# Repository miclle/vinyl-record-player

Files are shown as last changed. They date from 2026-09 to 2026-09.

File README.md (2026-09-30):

# 黑胶唱片机概念 CAD

一低音两全频的一体式黑胶唱片机概念 CAD，外形参考 [HYM LUMI Walnut 官方资料](https://www.hym-originals-en.com/products/lumi-turntable-walnut)。当前结构为 **v0.11 HYM 比例格栅与 10 mm 内部结构板布局**，保留 v0.9 可调定位合页；当前弯臂机芯与结构统一保存在一个主 CAD 文件中，机芯采用 **v0.6 部分实测居中参数**。扬声器、变压器和功放板已采用用户提供的外廓尺寸；机芯安装接口仍待确认。

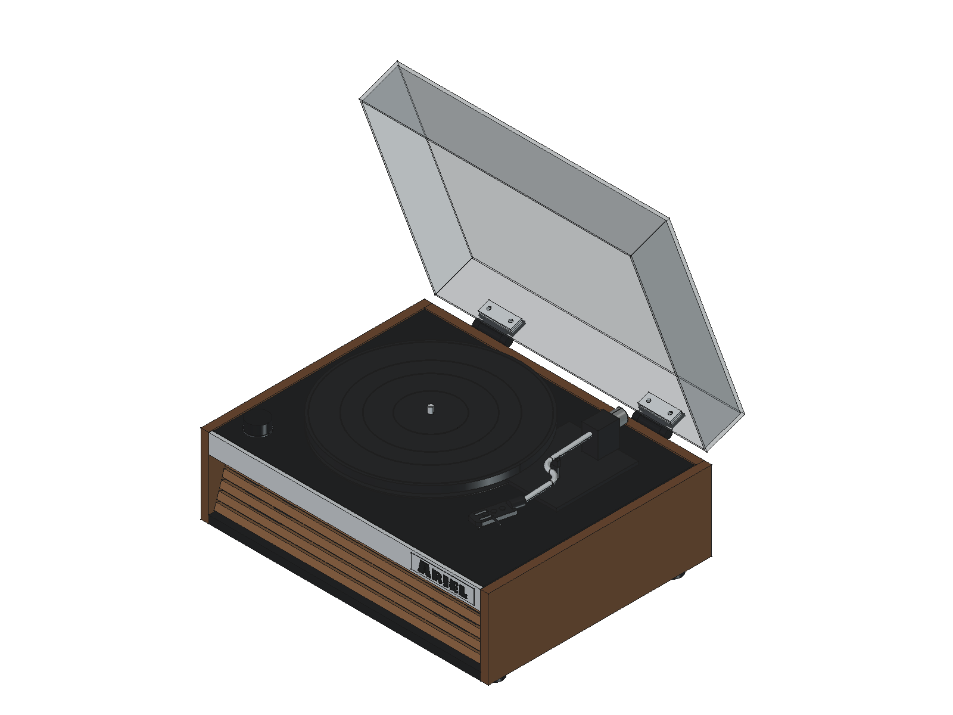
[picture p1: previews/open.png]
开盖 CAD 预览


## 模型选择

| 文件 | 用途 |
|---|---|
| [整机主模型](cad/record-player.FCStd) | 唯一 CAD 入口，默认开盖 70°；零件直接位于根层，便于逐件点击查看 |

主模型直接由两份参数 JSON 一次生成，不再依赖另一个 FCStd。对象树不创建零件分组；每个零件以只读 `AssemblySection` 属性保留原有分类，选中零件后可在属性编辑器的 `Organization` 分类中查看。旧基线 CAD／STEP 已移除，可从 Git 历史找回。原通用机芯的 16 个对象标记为 `Mechanism` 历史参考，`FitAnalysis` 标记诊断体也默认隐藏；两者均不进入当前装配、STEP 或零件清单。

日常查看无需重建：

1. 在 FreeCAD 中打开主模型，默认显示开盖 70° 的状态。
2. 保持主模型为当前活动文档，在“宏 → 宏…”中将用户宏位置设为本仓库的 `tools/`，选择 [toggle-cover.FCMacro](tools/toggle-cover.FCMacro) 并执行。
3. 每次执行在闭盖和开盖之间切换，盖壳、活动叶、补偿垫片和压板同步移动。

宏不自动保存，但切换姿态会使文档显示为已修改。仅查看时可关闭并放弃姿态更改，下次打开仍是原保存状态；如有其他手动编辑，先另存副本。`AssemblyState.CoverAngle` 是只读的角度记录，改变默认开角需修改 `cad/parameters.json` 的 `cover_angle_open` 并重建。

交付的 STEP、尺寸图与验证均使用闭盖基准；手动从当前开盖视图导出不属于此流程。70° 不代表实物已有限位或悬停能力。

## 分类平面图纸

先看[图册 01 中的两页 A2 整机结构导览](output/pdf/01-assembly-and-enclosure.pdf)：[开盖全景](previews/assembly-guide-1.png)和[内部展开](previews/assembly-guide-2.png)用编号标出部件、材料状态、数量及对应详图号，覆盖当前装配的全部 65 个物理对象；两页都在图中编号下直接显示部件名称，并共用相同的页边界、主视图、左右标注列和右侧目录宽度，减少视线往返与翻页跳动。两页导览以原 A2 尺寸插在 A-STOCK 木板清单之后，不再另行交付重复的 00 PDF。详见[导览说明](docs/assembly-guide.md)。

当前模型已整理为 **3 份横向矢量 PDF，共 44 页**；主体图纸为 A3，第一册另嵌入两张原尺寸 A2 导览：

- [整机与外壳（19 页）](output/pdf/01-assembly-and-enclosure.pdf)：木板整数备料汇总后紧接两页原尺寸 A2 整机导览，再继续闭盖六面图、障板局部剖视、外壳零件、合页与安装板，以及底板／后板／防尘盖后壁开孔定位。
- [音腔与内部结构（11 页）](output/pdf/02-acoustic-and-structure.pdf)：隔板、音腔顶板、倒相管、浮动台面与支承，附障板／顶板／浮动底板开孔定位。
- [机芯与电子部件（14 页）](output/pdf/03-mechanism-and-electronics.pdf)：扬声器、电源、功放、当前弯臂机芯及通用机芯对照。

图纸标明长 X、宽 Y、高 Z、厚度或厚度状态，并补充已有开孔、定位和同形件数量。六种板件的 33 个孔及后板沉台已分别标注孔径、局部孔位、必要的深度和加工面；障板孔位使用沿前表面量取的 S 尺寸。未确认的尺寸明确标为假设或待定；当前仍是概念与空间核对图。详见[读图说明与重新生成方法](docs/drawing-pack.md)。

## 机芯装配核对

已按“28高端弯臂机芯全套餐装好直接用 自动回臂”建立 [FreeCAD](cad/record-player.FCStd) / [STEP](cad/record-player.step) 示意装配，见 [选型说明与重建方法](docs/mechanism.md)。用户已确认到货款除弯臂外与原图一致，并确认唱头指托不会越过机芯基座右侧。采用 Ø280×11 唱盘、85 mm 总高及 R110、约1／4／8点的三个弹簧支点；整套机芯右移 12 mm 至唱盘中心 X=188 mm，355 mm 基座在浮动台面上的左右余量约为 34／33 mm。指托暂按 16 mm 外观长度建模并保持在基座范围内。弹簧自由高15.5、估计压缩0–5 mm，对应电机下探24.5–29.5 mm。底部局部轮廓仍为估算，与现有结构有重叠，安装未放行。

[弯臂预览](previews/mechanism-open.png) · [空间核对图](previews/mechanism-clearance.png) · [核对报告](cad/mechanism-fit-report.json)

## 整机交付内容

| 文件 | 用途 |
|---|---|
| [FreeCAD 装配](cad/record-player.FCStd) | 65 个当前装配对象，另含隐藏历史参考和诊断对象；零件位于根层，可直接点击、隐藏、移动和进一步建模 |
| [STEP 装配](cad/record-player.step) | 闭盖姿态，82 个实体；排除历史参考与诊断体 |
| [三视尺寸图 SVG](previews/dimensions.svg) / [PNG](previews/dimensions.png) | CAD 实体投影，含外廓和唱盘尺寸；不是加工图 |
| [闭盖](previews/closed.png) / [开盖](previews/open.png) / [内部布局](previews/internal.png) | 实际 FreeCAD 视口渲染 |
| [底部低音安装](previews/bottom.png) | 低音朝下，底板预留圆孔 |
| [俯视](previews/top.png) / [正视](previews/front.png) / [右视](previews/right.png) | 外形与布局核对 |
| [主要参数](cad/parameters.json) | 修改后通过脚本重建 |
| [机芯参数](cad/mechanism.json) | 当前弯臂机芯占位、唱盘尺寸和下探假设，与结构参数一起重建 |
| [零件清单](cad/parts.csv) | 材料说明、包络尺寸和估算标记 |
| [木板备料清单](cad/wood-cut-list.csv) | 20 块 / 条板件，整数矩形备料长宽、名义板厚、数量及后续修切说明；A-STOCK 与导览 W01–W11 共用编号、名称、数量和尺寸，W05 为退役空缺 |
| [设计依据](docs/design-basis.md) | 官方资料、估算边界与后续选型要求 |
| [验证报告](cad/validation.json) | 实体、关键尺寸、干涉及 STEP 回读结果 |

外观包含胡桃木色侧板、后倾横格栅、银色前沿、黑色台面、左前旋钮、唱盘与唱臂包络、烟灰透明翻盖和脚垫。内部使用 Shockwave SC-2103 拆机件：**左右全频朝前，低音移到后排朝下**。两道全深隔板分出贯通前后的中央低音腔，左右前部各为一个独立密闭试验腔，电路移至左右后部。低音倒相管从后板引出，内径 32 mm、初始长度 160 mm，可换长度试调。v0.5 将箱体平面外廓调整为 450 × 350 mm，木壳自身高度保持 124 mm。

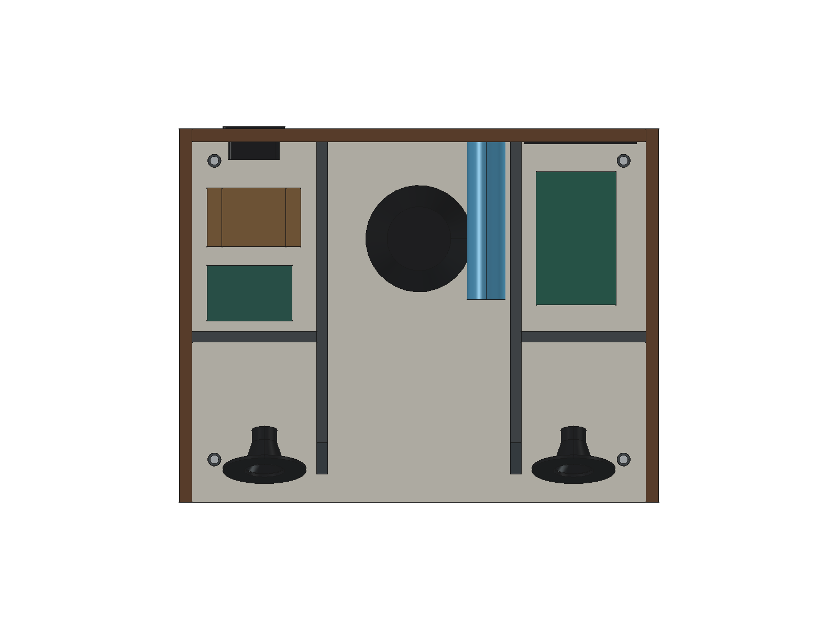
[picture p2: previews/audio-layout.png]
三音腔俯视布局（上方为后侧；已隐藏顶板）


低音腔几何毛容积约 **4.58 L**，扣除所有已建模占用（含实心安装包络和倒相管）后保守净容积约 **4.04 L**；左右全频腔各约 **1.11 L**。这些是 10 mm 内部结构板下的 CAD 空间估计，尚未扣吸音材料、支柱、密封件及线缆，不是实测声学容积。原箱和倒相管已遗失，没有 T/S 参数；管径、管长与左右密闭方案均为待测初值。详细坐标、拆装方式和验证边界见 [SC-2103 音腔设计](docs/audio-layout.md)。

[后置倒相口预览](previews/rear.png)

左右全频腔当前没有倒相管；可封堵、可换管接口仅为后续讨论方案，尚未建模，见[全频腔的后续方案](docs/audio-layout.md#左右全频腔的后续方案)。接手当前成果时先读[工作交接](docs/current-work-handoff.md)。

## AC 电源插座预留

已依据用户提供的 8-F5 图纸，在左后板横装预留 **48 × 28 mm、R3** 通孔，附上下 **2 × Ø4.5 mm、孔距 40 mm** 固定孔。中心 X=70、Z=88.5 mm，距后板自身左边 58、下边 54 mm。插座下移 16 mm，为对称合页留出 5.5 mm 间隙；变压器同步前移 10 mm 至 Y=267。端子后另留 20 mm 接线空间（暂估），与变压器及承托梁的几何间距分别为 6.72／22 mm。

[合并参考图](references/ac-inlet/8-f5-combined.png) · [原图、选型条件与孔位说明](references/ac-inlet/README.md) · [插座与电源线购买链接及 SKU](references/ac-inlet/README.md#购买链接) · [隐藏插座后的后板孔预览](previews/rear-cutouts.png)

该两芯 C8 仅为机械候选件，不提供保护接地；整机绝缘、变压器一次侧规格、保险丝、端子护套及实际板厚适配尚待确认，未放行市电接入和生产加工。合图中的细字可能重绘，尺寸以保存的两张原图及参数记录为准。

电源线目前仅登记购买链接，具体规格与适配性尚未核对，未加入 CAD。修改插座开孔参数后，备料表的文字说明仍可能保留默认尺寸，详见[已知问题与待修项](docs/current-work-handoff.md#已知问题与待修项)。

## 已购脚垫与固定座

已登记 VE 型 **Ø30 × 20 mm 橡胶脚垫、M8 × 23 mm 螺杆**，以及 **M8、Ø37 mm 底盘、总高 17 mm 固定座**的[购买链接、SKU 和原始尺寸图](references/feet/README.md)。尺寸来自用户提供的商家图，尚未实测。

已建模四套脚垫与固定座，采用用户确认的“底盘贴底板下表面、圆柱向上穿板”方式。未压缩离地高 **22.5 mm**；木壳仍高 124 mm，闭盖总高 **210.7 mm**。前脚中心改为 Y=40，后脚为 Y=320，左右 X=33 / 417 mm。底板 Ø12.4 mm 通孔、Ø3 mm 深 8 mm 盲预孔及固定孔分布圆 Ø28 mm 均为安装假设。22.5 mm 按理想贴合计算，不包含螺钉头凸出、垫片或锁紧件；实际避让、啮合、密封及承载待实测。

[脚座安装剖视](previews/feet-installation.png) · [底部预览](previews/bottom.png) · [尺寸及安装边界](references/feet/README.md#当前-cad-安装方式)

## 前沿 T 型铝饰条

采用用户选定的 **30 × 30 × 5 mm 铝合金 T 型材**，宽面朝前、筋板向后；安装长 425 mm，两端各暂留 0.5 mm。10 mm 顶板前缘退至 Y=5.2，并加工 25 mm 宽、5.7 mm 深的顶面台阶，余厚 4.3 mm；其中 0.2 mm 为胶层／试装余量假设。饰条上沿仍齐平木箱，闭盖间隙 1 mm。固定孔、胶种、根部圆角与实物公差待确认。

[原图、商品链接与安装尺寸](references/fascia/README.md)。音腔顶板孔位按新成形前缘起算；机芯右移后，轴承孔局部坐标为 X=176、Y=166.8 mm，整机坐标为 X=188、Y=172 mm。

### Ariel LOGO：打印雕刻支架

当前手工方案为一体打印的 [Ariel 镂空雕刻定位支架](output/3d-print/README.md)，采用 Sigmar One 字体，无需文字贴膜。[STL](output/3d-print/Ariel-stencil.stl) 外廓 **109.5 × 32 × 6.5 mm**，已摆好大平面贴热床、挡边朝上的姿态，无需支撑；按裸饰条上沿和右端定位。A、R 内孔通过 1.2 mm 连接桥保留，取下支架后可补磨桥位。

使用时在饰条安装前加工，或先拆下饰条；刀头可达性、模板耐磨与最终对比度需在边角料试刻。该工具单独交付，不计入整机装配、零件表或三册图纸。

主 CAD 仍保留另一方案的 **98 × 22 × 0.6 mm Ariel 激光标记铭牌**；[矢量稿与概念尺寸](references/nameplate/README.md)可供商家核对，材质、厚度、贴附及激光效果待确认。因此现有 STEP 和图纸仍含铭牌占位，并未改成直接在饰条上磨字后的装配。

## 可调定位合页

采用两只 **HFA5751-3434 黑色可调定位合页**。已保存两张用户原图、淘宝链接、SKU 及用户补充的最大 **3 N·m** 信息；单只／整对口径、扭矩范围与寿命保持能力尚未验证。

合页中心 X=100／350 mm，关于箱体中线对称、距各自箱体外侧均 100 mm，共用轴线 Y=356.95、Z=147 mm；上盖外侧加 2 mm 补偿垫片，内侧加 2 mm 压板。后板为 4 个 Ø3、深 8 mm 盲预孔，透明盖后壁为 4 个 Ø5.5 通孔，均属安装假设。两张原图的总厚分别为 13.2／12.8 mm，模型暂按较大的 13.2 mm 预留，合页后端位于 Y=363.2 mm；加上前侧 0.6 mm 铭牌后闭盖总深为 363.8 mm。

[原图、采购记录与安装边界](references/hinges/README.md) · [对称安装后视图](previews/rear.png) · [合页安装局部视图](previews/hinge-installation.png)。合页叶片沿用 A-P06，垫片／压板见 A-P08，后板孔见 A-H02，盖后壁孔见 A-H03。模型检查到 70°，尚未设计机械限位。

## 木板加工尺寸

箱体平面采用 450 × 350 mm；侧板 350 × 124 × 12、底板 426 × 350 × 12、后板 426 × 112 × 12、浮动台面 422 × 330 × 10 mm。台面前侧到银色 T 型铝饰条后表面的名义间隙由 `deck_front_fascia_clearance` 控制，当前为 1 mm；左右由 `deck_side_clearance` 控制，当前各 2 mm；后侧由 `deck_rear_clearance` 控制，当前为 2 mm。三处均为概念安装余量，实际浮动行程待验证。三个 Ø16 × 8 弹性支承分别嵌入音腔顶板顶面与台面底面 3 mm，保持台面上表面高度不变；沉台和支承参数仍是安装假设。底板前沿一体保留，已取消与底板完全重叠的独立下横梁。格栅为 7 条 426 × 10 × 6 mm 矩形条，整体后倾 18°，竖向节距 13 mm；透声布占位后移至障板前表面。

斜障板采用真实法向厚 10 mm，矩形备料 426 × 98 × 10 mm，之后修上下斜口至安装竖高 90 mm；两道低音隔板各备料 312 × 90 × 10 mm，按精确斜前缘修切。音腔顶板、左右全频腔后板、后部承托梁和浮动台面也统一使用 10 mm 备料。图册同时保留成形包络与整数备料，不能逐项四舍五入斜切坐标。脚座安装孔及配合间隙按上述假设预留；其余未定义的榫槽、紧固孔和通用间隙未建模。名义板厚、贴皮、拼接与装配余量仍须在材料和工艺确定后实测确认。

## v0.11 结构参数与精度

闭盖机壳外廓为 **450 × 350 × 210.7 mm**，含前侧铭牌和后凸合页的总深 **363.8 mm**（不含未建模紧固件、外接插头和线缆）。当前机芯的唱盘占位为 **Ø280 mm**，由 `cad/mechanism.json` 控制；弯臂轴距、有效臂长和循迹参数尚未确认。

`cad/parameters.json` 中保留的 Ø300 mm 唱盘、200 mm 轴距与 218 mm 有效臂长属于隐藏的历史通用机芯，仅用于图册附录，不能作为当前弯臂的安装尺寸。两类尺寸来源见[设计依据](docs/design-basis.md#公开参数)和[机芯尺寸依据](docs/mechanism.md#尺寸依据)。

原始 **214.2 mm** 曾暂解释为闭盖总高，官网图示未明确测量基准；v0.7 因已购脚垫名义离地高度降低 3.5 mm，当前总高为 **210.7 mm**。木壳高度分配、板厚、格栅间距、防尘盖与内部件尺寸均为估算；扬声器口端外径与总高采用用户于 2026-09-21 提供的尺寸，见下表；开孔和 3 mm 边沿厚度仍为估算。口端外径暂对应模型法兰外径，不代表振膜直径或名义英寸规格。

| 占位 | 数量 | 口端外径 | 总高（含边沿） | 暂定开孔直径 | 向箱内预留深度 |
|---|---:|---:|---:|---:|---:|
| 低音，底部朝下 | 1 | 132 mm | 65 mm | 100 mm | 62 mm |
| 全频，前部左右 | 2 | 78 mm | 40 mm | 40 mm | 37 mm |

总高按喇叭口朝下测量时的轴向高度理解；安装方向维持低音朝下、全频朝前。法兰向箱外伸出暂估的 3 mm，已计入总高。低音的最低点离桌面 19.5 mm，低于此前 20 mm 试验目标；几何验证仅核对间隙与当前装配一致，声学效果、橡胶压缩及防护网厚度仍待验证。安装孔只开概念圆孔，未确定螺孔位置。`parameters.json` 中的 `woofer`、`fullrange` 和 `acoustic_divider_x` 可分别调整单元尺寸、位置和隔板位置；`total_height` 是总高，箱内深度由总高减 `flange_thickness` 得到。

三个扬声器共用一个电源变压器，本体按用户提供的 **60 × 55 × 50 mm**，底部固定耳总长 **88 mm** 建模。放在左后部电源区，底面贴合底板上表面 Z=34.5 mm。本体与固定耳共用底面，总包络为 **88 × 55 × 50 mm**；固定耳暂按沿长边对称伸出、每侧 14 mm，宽 55 mm、厚 2 mm 作保守占位，尚未开固定孔。孔距、耳宽厚及高度基准需实物核对，散热、走线和磁场对唱头/唱放的影响未验证。尺寸与位置由 `power_transformer` 参数控制。

功放板采用用户提供的**含散热片整体尺寸 125 × 75 × 45 mm**，放在后部右侧，水平旋转 90°，沿 X/Y/Z 的包络为 75 / 125 / 45 mm。沿用离底板 10 mm 的暂估支承空间，包络底面 Z=44.5 mm、顶面 Z=89.5 mm；没有在 45 mm 之外再叠加散热片。`amplifier` 参数控制尺寸、位置及底部间隙；孔位、支柱、散热片细节和端子插拔空间待确认。

FCStd 保留独立的 `Part::Feature` 实体；主参数由 JSON 驱动脚本重建，**没有完整的草图约束和自动联动特征历史**。可以在 FreeCAD 中继续直接编辑零件，或修改 JSON 后重新生成。部分细部偏移量在建模脚本中。重建不会保留手动修改，应先另存自己的版本。

## 整机重建

使用 FreeCAD **1.1.1**。以下终端命令从仓库根目录执行；整机生成输出写回 `cad/` 和 `previews/`，PDF 另行生成到 `output/pdf/`。

1. 按需修改结构参数 `cad/parameters.json` 或机芯参数 `cad/mechanism.json`。脚垫高度须满足 `foot_height = feet.rubber_height + feet.flange_thickness`；改变离地高度时还需同步关联的绝对 Z 参数，见[脚垫参数与重建](references/feet/README.md#参数与重建)。
2. 将手动改动另存后，关闭主模型。生成器同时检查 `RecordPlayerAssembly` 文档名与解析符号链接后的输出路径，阻止覆盖已打开的目标。
3. 执行 `tools/build.FCMacro`，一次生成整机 FCStd、闭盖 STEP、清单、机芯核对报告、预览和尺寸图；最后以开盖 70° 保存主模型。脚座及合页局部视图只裁切临时文档。
4. 执行下方验证命令。验证读取临时副本并恢复闭盖基准，不改变已打开的用户文档或源文件。
5. 交付图纸时，按[图册说明](docs/drawing-pack.md#重新生成)提取主 CAD 的最新数据并排版三份主体图册，再按[导览说明](docs/assembly-guide.md#重新生成)生成两页临时 A2 导览并嵌入第一册 A-STOCK 之后；不另行保留重复的 00 PDF。整机宏不会自动更新这些 PDF。

宏每次读取本地模块的新源码，包括机芯和姿态模块。结构参数快照保存在 `GeometryDatums.BuildParametersJSON`，机芯参数快照保存在 `StudyBasis.ConfigurationJSON`。验证拒绝缺失或过期快照，并以失败报告覆盖旧成功报告。机芯报告的 `model_sha256` 绑定最终保存的主 CAD。修改 JSON 不会自动改变保存的静态实体。

本机也可以用终端启动宏：

```sh
open -a FreeCAD --args "$PWD/tools/build.FCMacro"
```

命令适用于 FreeCAD 尚未运行时；已经运行时直接在宏窗口执行。脚本使用宏本身所在位置寻找仓库，不依赖终端工作目录。

无图形界面时可生成主 FCStd、闭盖 STEP、机芯报告、零件清单与木板备料清单：

macOS 终端命令使用环境变量 `FREECAD_RESOURCES`，请将其设为本机 FreeCAD 1.1.1 应用包内的 `Contents/Resources` 目录，并在同一终端会话中执行命令。该目录应包含 `bin/python` 和 `lib`；它是外部运行环境，不是项目目录。下方命令及各专题文档均使用此变量，未设置时会提示并停止。

```sh
PYTHONPATH="${FREECAD_RESOURCES:?请先设置 FreeCAD 运行环境}/lib" \
  "$FREECAD_RESOURCES/bin/python" tools/build_model.py
```

该方式不生成 GUI 颜色与零件可见性设置、预览或尺寸图，也不刷新主验证报告；需要与交付文件一致的展示效果时执行 GUI 宏，再继续验证及图纸流程。

## 验证范围

2026-09-24 已将部分实测机芯与结构合并为单一主 CAD，并默认保存开盖展示姿态；随后将机芯整体右移 12 mm、缩短指托，并同步主轴孔、预览和图纸。本轮验证证据见[工作交接](docs/current-work-handoff.md#验证证据)。

当前保存模型通过主验证 **56 项**和机芯报告 **13 项**几何／导出检查。FreeCAD 全量回归共 55 项，其中 46 项通过，9 项 PDF 用例按运行时条件跳过；独立 PDF 环境的 9 项全部通过。三册最终页数为 19／11／14；第一册包含 17 张 A3 图纸和插在 A-STOCK 后的两张原尺寸 A2 导览，两张独立导览 PNG 和孔位图也已同步。导览合成会拒绝 CAD 哈希或 17 页图号序列不一致的第一册，并在 PDF、索引和预览全部生成成功后才发布。历史批次及其适用范围见[验证证据](docs/current-work-handoff.md#验证证据)。

CAD 回归覆盖参数快照、根层零件树与 `AssemblySection` 合法取值、保存实体尺寸、宏重载、关键部件干涉、音腔泄漏和净容积、倒相管试验长度、脚垫穿板安装及机芯核对版的覆盖保护。T 型铝条的 5 项用例检查真实截面、顶板承托层、邻件间隙和密封边界；错误填实截面、填回台阶、切穿承托层及抬高撞盖均会被检出。合页另有 5 项用例，覆盖保存孔位、盲孔余厚、活动安装件干涉及图纸孔坐标；非默认合页参数回归同时核对保存实体、孔表、材料说明与图纸文字。

图册与导览回归覆盖孔位基准、盲孔深度、真实剖面、对象与图号映射、A-STOCK 与 W01–W11 导览目录一致性、非默认 AC 开孔备料说明、格栅数量变化及标注遮挡；完整 PDF CLI 用例执行保存 CAD 提取和三册排版，核对页数、位置表及保留图号。测试不会改写原交付文件，但图册与导览用例需要读取当前主 CAD，因此应先完成重建：

```sh
PYTHONPATH="${FREECAD_RESOURCES:?请先设置 FreeCAD 运行环境}/lib" \
  "$FREECAD_RESOURCES/bin/python" -m unittest discover -s tests -v

# 普通 Python 环境需 reportlab、svglib、pypdf、pdfplumber，补跑：
FREECAD_RESOURCES="${FREECAD_RESOURCES:?请先设置 FreeCAD 运行环境}" \
  python3 -m unittest discover -s tests -p '*_pdf.py' -v
```

主装配的几何验证（自动恢复闭盖基准）：

```sh
PYTHONPATH="${FREECAD_RESOURCES:?请先设置 FreeCAD 运行环境}/lib" \
  "$FREECAD_RESOURCES/bin/python" tools/validate_model.py
```

主验证覆盖结构和机芯参数快照、当前装配实体有效性、STEP 回读、安装空间、音腔封闭与倒相管气路、脚座、AC 插座、T 型铝条及合页。历史参考和诊断体不参与物理装配检查；假设机芯下探的重叠单独记录在 `mechanism-fit-report.json`，不计入声腔实物占用。

盖壳每 5°、盖壳与活动安装件总成每 1° 检查至 70°，均为离散抽样，不是连续运动或实物悬停验证。模型合并和开盖展示没有解决机芯实际轮廓、孔位与运动范围未知的问题；声学、电气、隔振和安装仍未放行。

具体未完成安装工作见[后续适配](docs/mechanism.md#后续适配与重建)，加工前资料清单见[设计依据](docs/design-basis.md#进入加工前必须补齐)。SC-2103 具体版本、原功放分频和单元参数仍需核实。现有图纸已标出暂定声孔，进入加工前仍需实测确认声孔直径，补齐扬声器固定螺孔、扬声器与当前弯臂机芯的真实安装图，并确定材料、连接方式和公差。**本版不能直接作为原厂精确复刻或生产加工图。**

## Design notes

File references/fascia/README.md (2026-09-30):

# 前沿 T 型铝饰条

2026-09-22 用户确认采用 **30 × 30 × 5 mm 铝合金 T 型材**。宽面朝前作为 30 mm 高银色饰面，中间筋板向后安装在音腔顶板前缘。此为已选方案，不代表已采购或已实测。

- [商品链接](https://item.taobao.com/item.htm?id=775150952939&skuId=6005431361130)
- 商品 ID：`775150952939`；SKU ID：`6005431361130`。
- [用户提供的商家尺寸图](vendor-dimensions.png)。原图版权归原权利人，仅用于本项目选型研究。

商品页面未成功读取；尺寸依据为用户提供的图片和文字。图中竖向 30 mm 是否含底板厚度仍需实测。本版按总外廓 30 × 30 mm、面板与筋板均厚 5 mm、筋板居中的理想锐角 T 截面建模；筋板从前饰面背后伸出 25 mm。合金牌号、表面处理、直线度、公差、根部圆角和端面加工均未确认。

## 当前 CAD 安装

参数位于 [cad/parameters.json](../../cad/parameters.json) 的 `fascia`；[tools/fascia.py](../../tools/fascia.py) 计算型材和顶板切除体。模型中的 `Fascia`、`AcousticRoof` 都是静态实体，修改参数后按 [README 重建流程](../../README.md#整机重建)重建并验证整机、图册和导览。

`face_height` 为正面高度，`overall_depth` 为从前饰面到筋板后端的总进深，`thickness` 为两部分的共同厚度。`end_gap_assumption` 是每端间隙；`fit_clearance_assumption` 同时用于前饰面背部、筋板后端与筋板下方的名义间隙。台阶深度由顶板高度和居中筋板位置计算，不是独立参数。

| 项目 | 默认值 / 整机坐标 |
|---|---|
| 铝条安装长度 | 425 mm，X=12.5..437.5；木箱净宽 426，两端各留 0.5 mm（假设） |
| 前饰面 | Y=0..5，Z=116.5..146.5；上沿与木壳齐平 |
| 向后筋板 | Y=5..30，Z=129..134；与面板同为 5 mm 厚 |
| 顶板成形前缘 | Y=5.2，为前饰面让出厚度与 0.2 mm 试装间隙 |
| 顶面台阶 | 沿 X 贯通顶板全宽 426 mm；Y=5.2..30.2、前后宽 25 mm；底面 Z=128.8，深 5.7 mm |
| 台阶剩余木厚 | 4.3 mm；0.2 mm 胶层/试装余量为假设，胶本体未建模 |
| 顶板轴承孔基准 | 整机 X/Y=(188,172) 不变；新成形左前角起算的局部 X/Y=(176,166.8) |
| 顶板整数备料 | 426 × 333 × 10 mm；成形最大进深 332.8 mm，不含加工余量 |
| 防尘盖 | 关闭时名义间隙 1 mm，另检查每 5° 的开盖样本 |
| 唱机承载板 | 筋板上方竖向名义间距 2.5 mm；承载板前缘 Y=6，距前饰面后表面 Y=5 为 1 mm，此处也是整个铝条到承载板的最短间距 |

台阶后缘距斜障板顶端前缘约 15.043 mm，处于音腔密封接合面之前。生成器拒绝侵入该接合面或切穿顶板的参数；验证器另从保存实体检查三音腔独立封闭性。铝条不作为音腔密封边界，胶层空隙也不用于补偿木板泄漏。

台阶深度 = 10 mm 顶板上表面 134.5 − 筋板下表面 129 + 下方余量 0.2 = **5.7 mm**；剩余木厚 = 10 − 5.7 = **4.3 mm**。前缘退让与台阶按整块顶板宽度加工，0.5 mm 端隙只改变铝条长度。

图纸入口见[图册索引](../../docs/drawing-pack.md#障板装配与板件开孔定位)：铝条 A-P02、顶板 B-P01、装配剖面 A-03、顶板孔位及台阶 B-H02。导览编号 F01／W07 分别对应铝条／顶板。

主 CAD 的饰条右侧仍有独立 [Ariel 激光标记铭牌](../nameplate/README.md)，贴在正面，不切削 T 型材；铭牌的外廓、位置和标记效果均为概念假设。当前手工方案另交付 [镂空雕刻定位支架](../../output/3d-print/README.md)，按裸型材上沿和右端定位，需安装前加工或先拆下型材。2 mm 右挡边不能放入装机后的 0.5 mm 端隙；该工具未加入装配，也未把现有 CAD 改成磨字后的型材。

## 加工与安装待确认

- 端隙 0.5 mm、试装/胶层间隙 0.2 mm 是设计假设，不能代替成品木箱净宽、型材实测与工艺公差。
- 当前锐角模型未包含挤压型材根部圆角；0.2 mm 间隙不保证圆角避让，试装后决定木板倒角或局部让位。
- 槽下仅余 4.3 mm 木厚，未设计直接向这里锁入的木螺钉。胶种、机械限位、端部固定块或支架需另定；不虚构安装孔。
- 保持铝条宽面到浮动唱机承载板前缘的 1 mm 名义间隙，不让铝条或固定件顶住承载板；紧固件头高、松动异响和振动传递需实物检查。
- 下沿比旧 20 mm 饰条降低 10 mm；灯槽位置保留。几何不碰撞不等于出光效果相同，样机需检查灯带可见角度。
- 安装前先核对截面和净宽，再试装、去毛刺并处理边角；之后检查盖子全行程、固定件间隙和播放时异响。

`InstallationReleased=false`。几何和 STEP 验证不等于加工、粘接强度或实际装配放行。

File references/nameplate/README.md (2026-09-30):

# Ariel 定制铭牌与激光标记稿

当前手工加工方案已交付 [一体打印的镂空雕刻定位支架](../../output/3d-print/README.md)，在裸饰条上辅助磨字。本文记录保留在主 CAD 中的激光铭牌方案；它的 0.6 mm 板厚和 0.02 mm 可视化浅凹不用于打印支架或手工雕刻深度。

右侧 LOGO 的文字为 **Ariel**，字体为 [Google Fonts 的 Sigmar One](https://fonts.google.com/specimen/Sigmar+One)。项目保存了 [字体文件](../fonts/sigmar-one/SigmarOne-Regular.ttf)与 [OFL 许可证](../fonts/sigmar-one/OFL.txt)，因此重新生成 CAD 和矢量稿时不依赖本机字体安装。字体视觉上接近全大写，但源文字保留 `Ariel`。

[Ariel-laser.svg](Ariel-laser.svg) 是已转成矢量轮廓的黑色标记稿，画布为 **98 × 22 mm**，可交给铭牌商家核对激光标记范围。SVG 不依赖商家的字体文件；其中没有板材切边或安装孔。下单前应由商家确认打开比例为 1:1、文字朝向和工艺效果。

| 概念项目 | 当前 CAD 值 |
|---|---|
| 铭牌外廓 | 98 × 22 × 0.6 mm，独立于铝 T 型材 |
| 正面位置 | X=330..428，Y=-0.6..0，Z=120.5..142.5 mm |
| 与 T 饰条端部 | 铭牌右边距饰条右端 9.5 mm；上下各留 4 mm |
| 文字 | Sigmar One，名义字高 16 mm，置中 |
| 表面效果 | CAD 用 0.02 mm 浅凹和深色面表示激光标记，仅用于可视化，不是加工深度要求 |

饰条正面原样保留，铭牌背面与其 Y=0 正面贴合。板材、颜色、实际厚度、倒角、胶层或机械固定、表面处理以及激光显色均未定；0.6 mm 铭牌厚度只是外观占位。若商家采用其他厚度或加工公差，应先更新 `cad/parameters.json` 的 `fascia.nameplate` 并重建，不直接沿用当前整机外廓。固定不得伸入浮动台面 1 mm 名义前缝。铭牌不是型材的一体刻字，也不代表已经放行采购或粘接。

生成器要求铭牌外廓完全落在饰条正面内；铭牌高度不得超过饰条的 30 mm 正面高度。超高参数会在生成前拒绝，防止把上下悬空的铭牌视为已贴合安装。

模型入口为 [tools/nameplate.py](../../tools/nameplate.py)；主模型中的 `Nameplate` 是独立 `Part::Feature`，在闭盖 STEP、零件清单和 F01 导览中计为一件。A-P02 仍是饰条本体图号，并注明铭牌位置；铭牌的商家标记稿单独使用上述 SVG，现有 A-Pxx 图号保持不变。

手工加工的另一方案见 [Ariel 镂空雕刻定位支架](../../output/3d-print/README.md)：一件 3D 打印，直接在裸饰条上辅助磨字，沿用这里的字体和排字位置。该工具独立交付，现有激光铭牌 CAD 和矢量稿保留。

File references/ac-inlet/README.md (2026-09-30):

# 8-F5 八字 AC 插座参考

用户于 2026-09-22 提供两张商家图片及以下购买链接；厂家与认证证书尚未核实。

- `8-f5-combined.png`：两图并排合并的阅读图，由图像工具合成；细字可能被重绘，**不作为尺寸主数据**。
- `vendor-product.png`、`vendor-dimensions.png`：用户原始 PNG，未改动；建模尺寸逐项依据原图读取。

图片版权归原权利人，项目许可证不覆盖这些图片。

## 购买链接

| 配件 | 购买页面 | 商品 ID | SKU ID |
|---|---|---|---|
| 8 字孔 AC 电源插座（8-F5） | [天猫购买链接](https://detail.tmall.com/item.htm?id=628671056678&skuId=4564193625870) | 628671056678 | 4564193625870 |
| 电源线 | [淘宝购买链接](https://item.taobao.com/item.htm?id=587227633218&skuId=6291395010174) | 587227633218 | 6291395010174 |

链接及 SKU 由用户提供，按原样记录；尚未核对商品页面中的具体规格和电源线适配性。

当前 CAD 只包含插座安装孔和采购件包络，未建模电源线及外部插头。电源线长度、额定值、插头外形和弯曲空间尚无已核实记录；仅计插座法兰时后端 Y=351.88 mm，合页后端 Y=363.2 mm；连同前侧铭牌的整机总深为 363.8 mm，仍不包含这些空间。

## 选型结论

可作为当前机械布局候选件，尚未确认可安全接入市电。商家标称 2.5 A / 250 VAC，包含两芯八字入口、开关、保险座。图片中的 CCC/CE 字样不能替代可核验的型号证书；“接触电阻 ≤50Ω”等数据也需要向厂家确认，不能当作可靠电气规格。

C8 是两芯入口，不提供保护接地；同类正规产品用于 II 类设备，见 [SCHURTER C8 资料](https://www.schurter.com/en/datasheet/typ_2576.pdf)。该资料仅支持接口类别说明，**不是本商家型号的认证或尺寸证据**。木箱、隔离变压器或两芯插头本身均不能证明整机具备双重／加强绝缘。如果整机需保护接地，应改用带 PE 的三芯入口。

最终选型需核对变压器一次侧电压、额定输入电流及启动浪涌、保险丝类型和电流、开关极数及端子接法、实际认证、绝缘护套与整机绝缘设计。当前不指定保险丝电流，也不按图片猜测端子接线。

## 尺寸读取

| 项目 | 原图值（mm） | 模型处理 |
|---|---:|---|
| 竖装面板开孔 | 28 × 48，R3 | 横转 90° 后为 X48 × Z28，R3 |
| 固定孔 | 2 × Ø4.5，间距 40 | 横装后上下排列 |
| 法兰外廓 | 49 × 58 | 横装后 X58 × Z49；具体轮廓简化 |
| 法兰厚度 | 1.88 | 置于木后板外侧 |
| 嵌入体横截面 | 27.2 × 47.6 | 横装后 X47.6 × Z27.2；圆角 R3 暂估 |
| 含端子总深 | 30.62 / 30.66 | 两个视图有差异，保守取 30.66，自前表面计 |
| 接线余量 | 未提供 | 在端子包络后另留 20，属于布局假设 |

图中微小公差文字不够可靠，未转录为加工公差。供应商图的尺寸仅支持名义预留，实际开孔需用实物试装确认。适用面板厚度未给出；12 mm 木板采用贯穿螺钉和垫片／螺母的方案预留，紧固件、压紧面和工具空间尚未放行。包络不含电源线外部插头及弯曲空间。

## 项目安装位置

v0.9 为让两只合页关于箱体中线对称，插座在 v0.7 位置基础上下移 16 mm；变压器同步向前移动 10 mm。按整机坐标，X 从左到右、Y 从前到后、Z 从桌面向上：中心 **X=70，Z=88.5**，后板外表面 **Y=350**。从后方看，插座位于画面右侧，即机器自身左后侧。

- 后板尺寸 426 × 112 × 12；其左下基准为 X=12、Z=34.5。
- 开孔中心距后板自身左边 58、下边 54；槽范围 X=46–94、Z=74.5–102.5。
- 螺孔中心 X=70，Z=68.5 / 108.5；相对后板左下角为 (58,34) / (58,74)。孔轴沿 Y，贯穿 12 mm 后板。
- 法兰范围 X=41–99、Z=64–113；Y=350–351.88。机壳深度仍为 350，含该法兰几何总深 351.88。
- 含端子包络到 Y=321.22；接线预留延伸到 Y=301.22，Z=74.5–102.5；变压器中心 Y=267，后缘 Y=294.5，与接线预留相距 6.72 mm。预留对承托梁间隙为 22 mm。

插座法兰上沿 Z=113，合页固定叶下沿 Z=118.5，两者垂直间隙为 5.5 mm。只下移插座而不前移变压器会侵入当前接线预留，不能省略联动调整。

`cad/parameters.json` 驱动开孔及占位重建。`cad/validation.json` 记录保存实体的孔形、包络干涉和接线预留几何检查；通过不代表电气安全距离、温升、绝缘或生产加工验证。

以上孔位和尺寸对应当前默认参数。修改开孔参数后的备料文字同步问题尚未修复，状态与处理要求统一记录于[当前工作交接](../../docs/current-work-handoff.md#已知问题与待修项)。

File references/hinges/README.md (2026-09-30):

# HFA5751-3434 可调定位合页

2026-09-23 用户选定黑色 HFA5751-3434，用于防尘盖，共 2 只。用户补充“最大可到 3 N·m”；这条信息来自用户，不是项目实测的保持扭矩。暂按单只最大值理解，单只／整对口径、可调下限、容差和寿命后保持能力仍待实物或供应商确认。

## 购买链接与原图

- [淘宝：可调阻尼任意停定位合页](https://item.taobao.com/item.htm?id=750399927294&skuId=5175201965803)
- 商品 ID：`750399927294`；SKU ID：`5175201965803`。
- [商品及尺寸原图](vendor-product-dimensions.png)：HFA5751-3434 黑色，含 5 kg／99 g 宣传标注。
- [第二张尺寸原图](vendor-drawing.png)：相同型号，含 Ø12.5 标注。

两张用户附件按原文件复制保存，未裁切或改写。商品页面未能读取；登记 URL 和 SKU 不表示验证商品参数。原图版权属于原权利人，不包含在本仓库许可内。

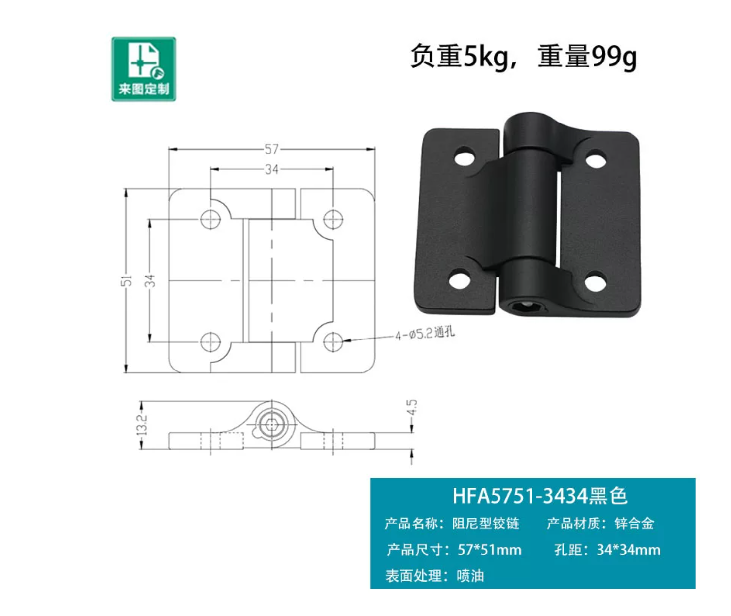
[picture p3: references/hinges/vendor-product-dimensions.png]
商品及尺寸图


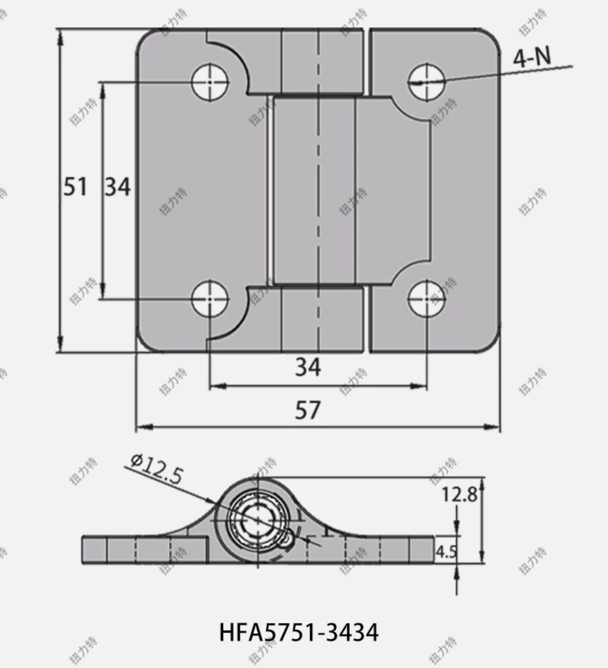
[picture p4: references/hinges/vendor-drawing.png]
第二张尺寸图


## 尺寸来源和冲突

| 参数 | 图示／用户信息 | 当前建模口径 |
|---|---|---|
| 展开外廓 | 57 × 51 mm，两图一致 | 旋转轴沿整机 X，沿轴长 51、跨上下叶高 57 |
| 孔距 | 34 × 34 mm，两图一致 | 上下各两孔，左右／上下孔距均 34 |
| 孔径 | 图一 4 × Ø5.2 通孔；图二写 4-N | 采购叶片 Ø5.2 |
| 叶厚 | 4.5 mm，两图一致 | 平叶厚 4.5 |
| 总厚 | 图一 13.2、图二 12.8 mm | 保守按背面起 13.2 mm 预留 |
| 筒径 | 图二 Ø12.5 | 暂作外筒直径；需确认其标注对象 |
| 轴心 | 未单独定位 | 由 13.2 与 Ø12.5 推算距安装面 6.95 mm，为假设 |
| 材质／重量 | 图一锌合金／99 g | 材料记录；不按简化实心 CAD 反推采购件质量 |
| 最大扭矩 | 用户补充 3 N·m | 记录信息来源；没有扭矩曲线／寿命证据 |
| 负重 | 图一 5 kg | 未给测试力臂与数量，不能据此验证悬停 |

轴筒分为两端固定、中间活动的简化结构，筒节轴向隙 0.2 mm。叶片根部曲面、外角圆角及调节螺钉、内摩擦机构、安装螺钉和螺母未建模；无圆角包络不代表真实外形完全重合。随意停功能不等同于缓降。

## v0.9 安装布局

`cad/parameters.json` 的 `hinges` 参数由 `tools/hinges.py` 生成几何。保留 `HingeBase0/1` 为固定叶，`HingePin0/1` 改为活动叶及中间轴筒；每一组两叶合计 **1 只采购合页**。另有 `HingeSpacer0/1` 和 `HingeBacking0/1` 各 2 件。

- 两只中心 X=100／350 mm，关于箱体中线 X=225 对称，距各自箱体外侧均 100 mm；整套固定叶、活动叶、补偿垫片、压板及孔位一同定位。AC 插座下移 16 mm 至 Z=88.5，其法兰上沿与固定叶下沿间隙 5.5 mm；变压器前移 10 mm 至 Y=267，为原有 20 mm 接线预留保留 6.72 mm 间隙。位置是本项目安装选择，并非厂家规定。
- 共用轴线 Y=356.95、Z=147 mm，位于木箱顶面 Z=146.5 与盖底 Z=147.5 的中间高度；轴平行 X。
- 木后板外表面 Y=350；透明盖后表面 Y=348。上叶与盖之间加 **2 mm 铝补偿垫片**；罩内侧加 **2 mm 铝压板**，垫片及压板均为 **51 × 18 mm**。
- 上盖、垫片及压板各为两组 2 × Ø5.5 通孔，拟配 M5 螺栓（安装假设）。压板范围 Y=343–345，垫片 Y=348–350，范围 Z=155–173 mm。
- 木后板侧为 **4 × Ø3、深 8 mm 后侧盲预孔**，保留 4 mm 内侧木厚。实际木螺钉、木材拔出强度和头部压紧方式尚未确认；不得把 Ø3 预孔当成 Ø5.2 采购叶孔。
- 闭盖木箱深仍为 350 mm；合页后凸 13.2 mm，合页后端 Y=363.2 mm；含前侧铭牌的闭盖总外廓 **450 × 363.8 × 210.7 mm**。外接插头／线缆和未建模紧固件不包含在该外廓中；开盖扫掠空间另计。

从后方看，1 号合页（对象后缀 `0`，中心 X=100）位于画面右侧，2 号（后缀 `1`，X=350）位于画面左侧；整机坐标不随视角翻转。下表的板件局部 X 均以整机 X=12 为零，木后板局部 Z 以整机 Z=34.5 为零，盖后壁局部 Z 以整机 Z=147.5 为零。

| 安装孔 | 整机 X | 整机 Z | 从板件左下角量取 |
|---|---|---|---|
| 木后板 4 个盲预孔 | 83／117／333／367 | 130 | X=71／105／321／355，Z=95.5 |
| 透明盖后壁 4 个通孔 | 83／117／333／367 | 164 | X=71／105／321／355，Z=16.5 |
| 每块垫片／压板的 2 孔 | 随对应上盖孔 | 164 | X=8.5／42.5，Z=9 |

木板孔见 A-H02；盖后壁孔见新增 A-H03；合页叶片沿用 A-P06，垫片／压板见新增 A-P08。保留脚垫 A-P07 及其他旧图号。孔边距、倒角去毛刺、亚克力装配间隙、隔离垫与紧固力均须试装确认。压板已建模，隔离垫和紧固件尚未建模。

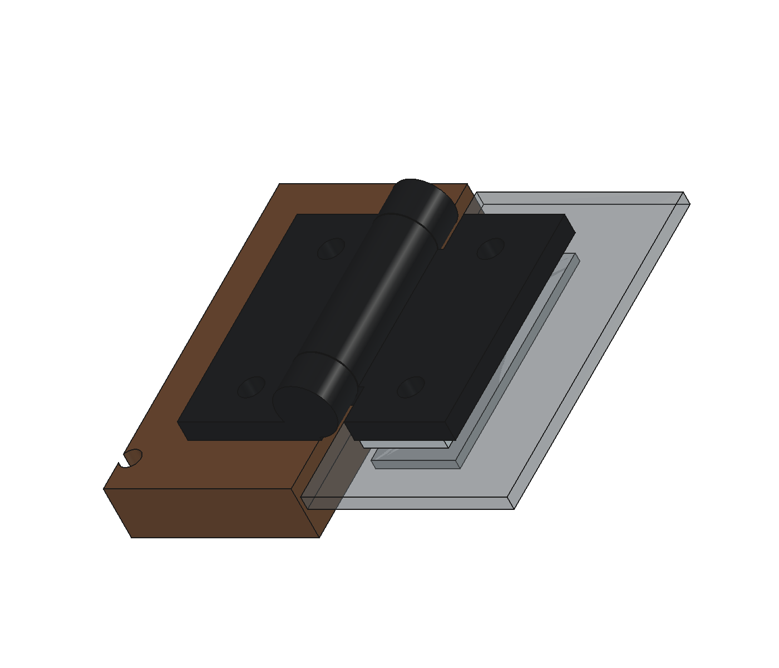
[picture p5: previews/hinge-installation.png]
安装局部视图


## 扭矩估算与验证边界

回读钻孔后的五面盖壳，按密度 1.18 g/cm³ 假设，裸盖约 0.848 kg。新轴线下，闭盖附近重力矩约 **1.514 N·m**，理想均分约 **0.757 N·m／只**。此估算不含活动叶、垫片、压板和螺栓质量；不能作为完成装配的负载实测。

两只各 1.0–1.2 N·m 可作为初始调试目标，随后按完整盖总成称重、重心和多角度悬停效果调整。不要仅按最大值拧紧：这会增加开盖力和亚克力安装受力。未把“3 N·m”转换为模型的承载通过结论。

主验证回读保存实体并还原闭盖基准，机芯报告检查生成中的实体并回读闭盖 STEP；两者均检查固定叶邻件，以及 **盖壳＋活动叶＋补偿垫片＋内压板**在 0–70° 每 1°共 71 个姿态的干涉。孔道、孔边材料和盲孔余厚另有检查；抽样无干涉不是连续扫掠求解，也不是实物扭矩、磨损、亚克力强度或安全限位验证。安装状态保持 `installation_released=false`。

下一步实物核对：确认 13.2／12.8 尺寸和轴线；先做木板／亚克力试装件；装齐紧固件后从小角度至70°检查悬停、手感与碰撞，并复测多次开闭后的保持能力。70°目前是检查角度，尚无机械限位件。

## 参数与重建

修改 [cad/parameters.json](../../cad/parameters.json) 中的 `hinges` 后，按 [README 重建流程](../../README.md#整机重建) 重建整机并运行验证，再生成图册及导览。模型是保存的静态实体，修改 JSON 不会直接更新 FCStd。

当前对称布局使用以下三个独立参数；修改其中一个不会自动移动另外两个部件。调整后应保留并重新检查接线预留，不能仅移动 GUI 中的活动叶。

| 参数 | 当前值（mm） | 控制范围 |
|---|---|---|
| `hinges.center_x` | `[100, 350]` | 两套合页、补偿垫片、压板及对应板孔 |
| `ac_inlet.center_z` | `88.5` | 插座、后板开孔和接线预留的高度 |
| `power_transformer.center_y` | `267` | 变压器前后位置；Y 减小为向前 |

插座详细孔位和内部空间见 [AC 安装记录](../ac-inlet/README.md#项目安装位置)。当前两合页中心之和等于箱宽 450 mm；这是参数选择，生成器不会自动强制对称。

`center_x` 决定合页横向位置；`hole_pitch`、`hole_diameter` 和 `leaf_thickness` 描述采购叶片。盖孔、木预孔、压板和筒节间隙均使用带 `_assumption` 的字段。轴线由 `depth`、`cabinet_top`、`cover_bottom`、假设总厚和筒径计算；当前盖后壁内缩 2 mm 及对应补偿厚度在建模逻辑中固定，改变这一安装方式须同步修改几何，不能只调整压板厚度。

安装孔、盲孔余木及垫片／压板外廓、厚度和局部孔心的图纸说明由参数生成；对应的非默认参数回归见 [tests/test_drawing_pack.py](../../tests/test_drawing_pack.py)。

`max_torque_user_reported_nm`、`torque_scope` 和 `initial_torque_target_per_hinge_nm` 是来源／调试记录，不控制摩擦仿真；CAD 不模拟静摩擦、缓降或实际悬停。专用回归为 [tests/test_hinges.py](../../tests/test_hinges.py)，覆盖保存孔位、填堵／打穿盲孔、活动压板碰撞及孔表坐标。待办统一保留在[当前工作交接](../../docs/current-work-handoff.md#已知问题与待修项)。

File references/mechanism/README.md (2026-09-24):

# 弯臂机芯资料

2026-09-21 用户提供：[淘宝商品 712086565319 / SKU 5162746531784](https://item.taobao.com/item.htm?id=712086565319&skuId=5162746531784)。选项原文为 **28高端弯臂机芯全套餐装好直接用 自动回臂**。

- `curved-arm-kit.png`：弯臂款外观，图片文字列出机芯、功放板、机芯线、RCA 后板、电源线。CAD 依照照片表现前移的大弧度双弯管、黑色连接套、斜置双槽唱头壳、三枚顶面圆垫和侧向指托；用户确认指托不会越过机芯基座右侧，暂按 16 mm 外观长度表示。图片没有这些局部结构的完整安装尺寸。
- `straight-arm-dimensions.png`：机芯背面照片和直臂款尺寸图，标有 355 mm、280 mm、10 mm。10 mm 的标注指向唱盘边缘，不等于机芯总高或台面以下深度。2026-09-24 用户确认到货弯臂款除唱臂形状外与该图一致；盘厚以实测 11 mm 替代图中的 10 mm。

淘宝链接本次未能读取详细商品规格，选型依据是用户指定选项及附件。图中“高端”“装好直接用”“自动回臂”是商品描述，不代表本项目已验证质量、音质或动作可靠性。图片版权归原权利人，仓库 LICENSE 不授予这些图片的版权许可。

## 2026-09-24 到货实测

[侧面标注照片](measured-side.png)由用户提供。机芯总高85、平台前后128／底部宽108／厚5、平台上下各40、唱盘Ø280×11、唱臂总长250 mm，有限位器和支架。下部40从机芯弹簧安装座量到电机最低点，不从弹簧接触木板的下端量起。

三个弹簧自由高15.5 mm，承重压缩观察为不到约5 mm；支点在唱盘圆心R110圆上，俯视约1／4／8点。钟点不是精确测角结果，弹簧直径与紧固接口未测。上述数据来源为本次用户描述；不得把照片比例估算写成实测尺寸。

建模将弹簧座与平台下表面暂视为共面，总高解释为40+5+40。平台的绝对平面位置、唱盘高度、马达直径及位置、传动区和回臂轮廓均保留显式估算，见[适配说明](../../docs/mechanism.md)。弹簧外廓套筒不代表实际线材或刚度，250 mm总长不代表有效臂长。弯管半径与位置、管径、连接套、唱头壳、槽孔、圆垫及指托尺寸都来自图片外观近似，不得作为实物尺寸或加工依据。

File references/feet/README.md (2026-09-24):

# 已购脚垫与固定座

用户于 2026-09-22 确认购买以下脚垫及固定座，并提供两张商家尺寸图。购买选择已确认；下表尺寸来自图片标注，尚未实测。商品页面本次无法读取，链接及 SKU 按用户提供的原样记录。

## 购买链接

| 配件 | 购买页面 | 商品 ID | SKU ID |
|---|---|---|---|
| VE 型橡胶脚垫，Ø30 × 20 mm，M8 × 23 mm 螺杆 | [天猫购买链接](https://detail.tmall.com/item.htm?id=935514441456&skuId=5993247083741) | 935514441456 | 5993247083741 |
| M8 × 37 固定座，镀黑锌、大号冷镦加厚款 | [天猫购买链接](https://detail.tmall.com/item.htm?id=754292834429&skuId=5202344405597) | 754292834429 | 5202344405597 |

固定座图片写有“数量：5 只”，这是图片中的包装标注；实际到货数量待核对。当前 CAD 有四个脚垫位置。

## 原始图片与尺寸

- [脚垫原图](vendor-foot-dimensions.png)：用户原始 PNG，未改动。
- [固定座原图](vendor-mount-dimensions.png)：用户原始 PNG，未改动；商家注明为单批次测量数据，以实物为准。

图片版权归原权利人，项目许可证不覆盖这些图片。

| 配件 | 项目 | 原图标注 |
|---|---|---|
| 脚垫 | 类型 | VE 型 |
| 脚垫 | 橡胶直径 × 高度 | Ø30 × 20 mm |
| 脚垫 | 螺杆规格 × 外露长度 | M8 × 23 mm，自橡胶顶部起计 |
| 固定座 | 内螺纹 | M8，螺距未标注 |
| 固定座 | 底盘直径 / 厚度 | Ø37 / 2.5 mm |
| 固定座 | 圆柱外径 / 高度 | Ø12 / 14.5 mm，圆柱高度不含底盘 |
| 固定座 | 总高度 | 17 mm，与 14.5 + 2.5 一致 |
| 固定座 | 固定孔孔径 | Ø5.5 mm；图片可见三个孔，未标孔距或分布圆直径 |

“M8 × 37”中的 37 指底盘直径，不是螺纹长度。两件名义螺纹均为 M8；实际螺距、有效啮合长度及是否能顺畅旋合仍需实物核对。

## 当前 CAD 安装方式

用户已确认采用**底盘贴底板下表面、圆柱向上穿板、橡胶顶面贴底盘下表面**的方案。`v0.7-purchased-feet` 已替换四个占位脚垫，并加入四个独立固定座和底板安装孔；脚垫总成保留 `Foot0`–`Foot3`，固定座为 `FootMount0`–`FootMount3`。M8 螺纹以 Ø8 名义圆柱／通孔表示，未画螺旋牙形；橡胶顶部金属片厚度未给出，不另加高度。

| 部位 | 当前模型坐标／尺寸（mm） |
|---|---|
| 四个中心 | X=33 / 417；前排 Y=40，后排 Y=320 |
| 橡胶 | Z=0–20，Ø30 |
| 螺杆 | Z=20–43，名义 Ø8 |
| 固定座底盘 | Z=20–22.5，Ø37 |
| 固定座圆柱 | Z=22.5–37，外径 Ø12 |
| 木底板 | Z=22.5–34.5，厚 12 |
| 圆柱高出底板 | 2.5 |
| 螺杆高出固定座 | 6；包络轴向重叠 17，非实测有效螺纹长度 |

前排中心从旧占位 Y=30 后移至 40，避免圆柱和螺杆与倾斜前障板重叠。名义未压缩离地高度是 **20 + 2.5 = 22.5 mm**；木壳仍高 124 mm，箱体及内部件整体下移 3.5 mm，闭盖总高由 214.2 mm 变为 **210.7 mm**。低音最低点离桌面 **19.5 mm**，低于此前 20 mm 试验目标；报告单列该目标未满足，声学出声空间仍待样机验证。

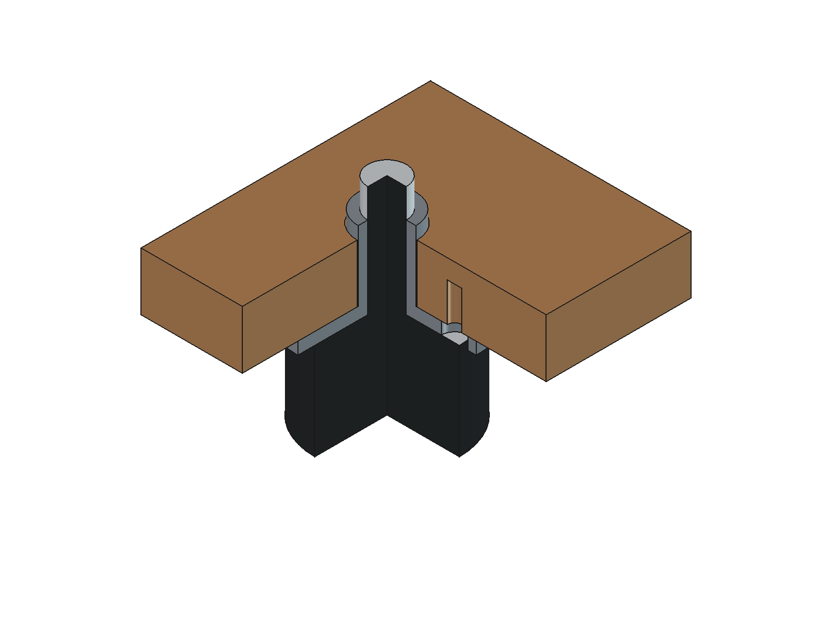
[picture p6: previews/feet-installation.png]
脚垫和固定座的局部四分之一剖视


剖视临时裁切底板、脚垫和固定座，仅为说明安装关系，不改变保存模型。未画螺钉；尺寸详图见第一册 A-P07，底板见 A-P01。

## 安装假设与待实测项

- 固定座三个 Ø5.5 孔按 **Ø28 分布圆**、从 +X 起 0°／120°／240°建模；孔距是暂估，不从透视图反推加工尺寸。
- 底板中心孔暂取 **Ø12.4 通孔**。固定座圆柱外径 Ø12 mm，名义径向间隙 0.2 mm；实际木板与金属件须试孔。
- 每座底板下表面暂开 **3 × Ø3 mm、深 8 mm 的盲预孔**，余木 4 mm；与固定座三孔同心。预孔为木螺钉方案假设，紧固件规格未选定。
- **22.5 mm 是理想贴合高度，不含未选螺钉头凸出、垫片或锁紧件。** Ø30 mm 橡胶会接近固定孔区域；需核对螺钉头与橡胶的避让，不能凭本模型认定已可直接装配。若需垫高或改紧固方式，应更新离地高度并重新验证。
- 保存几何检查四套实体与底板、障板及电子件的干涉，并检查通孔和盲预孔形状。音腔闭合依赖底盘、底板及橡胶的理想接触；实际螺纹及接缝不保证气密，密封措施待确认。

有效螺纹深度、实物螺杆端部余量、橡胶压缩量、承载和隔振仍待测；脚垫与固定座对象均标记 `InstallationReleased=false`。采购记录和名义几何不构成加工或安装放行。

## 参数与重建

修改 `cad/parameters.json` 的 `feet` 对象后，按[整机重建](../../README.md#整机重建)生成并验证整机，再生成图册和导览。保存实体不会自动响应 JSON 修改。

- `rubber_*`、`stud_*`、`flange_*`、`barrel_*` 和 `mount_hole_diameter` 记录名义零件尺寸；带 `_assumption` 后缀的孔距、板孔和预孔参数为安装假设。
- `side_inset`、`front_y`、`rear_inset` 控制脚位；右侧 X 与后排 Y 分别由箱宽、箱深减去边距得到。固定孔的三个角度当前由代码固定为 0°／120°／240°。
- 当前仅实现圆柱向上、橡胶贴底盘的安装方式，要求 `foot_height = feet.rubber_height + feet.flange_thickness`。改变橡胶高度或底盘厚度时，必须同时更新 `foot_height`，否则生成器拒绝构建。
- 若要保持箱体自身尺寸和内部相对位置，离地高度的差值还须同步到 `cabinet_top`、`closed_height`、`cover_bottom`、`fullrange.center_z`、`acoustic.roof_bottom_z`、`bass_port.center_z`、`phono_board.z` 和 `ac_inlet.center_z`；生成器不会自动调整这些绝对坐标。
- 当前代码还要求螺杆长度大于固定座总高，盲预孔深度小于底板厚度。加入垫片、锁紧件或改变固定座朝向需要修改安装几何，不能仅改 `foot_height`。

`tools/build.FCMacro` 同步输出 `previews/feet-installation.png`，该图由 `render_foot_detail()` 在临时文档中生成。基线验证的 `feet_*` 检查涵盖零件形状、底板孔、干涉与支承；`metrics.feet` 记录脚位、螺杆突出及盲孔余木。低音旧试验目标单独记录为 `metrics.woofer_previous_20mm_trial_target_met=false`，几何检查通过不表示该目标已满足。

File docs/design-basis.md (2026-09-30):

# 设计依据与复刻边界

来源检索日期：2026-09-21。

## 原始资料

- [官方产品页面](https://www.hym-originals-en.com/products/lumi-turntable-walnut)
- [官方主视照片](https://www.hym-originals-en.com/cdn/shop/files/shop_LUMI_Internal_Main_Images_01.jpg?v=1783084143&width=1600)
- [官方尺寸图](https://cdn.shopify.com/s/files/1/0621/9572/8638/files/3_24_329fb263-a3b5-4d16-9e60-e873b0c0db51.jpg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)

本地原始参考图位于 `references/hym-lumi/`，保留品牌版权，只作为本次研究依据。

## 公开参数

| 项目 | 公开值 | 当前使用方式 |
|---|---:|---|
| 宽 | 448.6 mm | 原始外形参考；v0.5 经用户授权调整为 450 mm |
| 深 | 345.5 mm | 原始外形参考；v0.5 调整为 350 mm，接口向后伸出另计 |
| 高 | 214.2 mm | 原始闭盖高度参考，测量基准未明确；v0.7 按已购脚垫调整为 210.7 mm |
| 唱盘直径 | 300 mm | 历史通用机芯的转盘直径；当前机芯暂用 Ø280 mm |
| 唱臂轴距 | 200 mm | 历史通用机芯的主轴到唱臂支点距离 |
| 有效臂长 | 218 mm | 历史通用机芯的支点到针尖距离 |
| 超距 | 18 mm | 历史通用机芯的有效臂长减轴距 |
| 唱头偏置角 | 24.7° | 历史通用机芯的头壳视觉方向，未用于当前弯臂 |
| 前部倾角 | 72° | 暂解释为格栅平面相对水平面 72°，即后倾 18° |
| 原机扬声器 | 2 × 2 英寸全频 + 1 × 4 英寸低音 | 本方案改用用户提供的 SC-2103 拆机件，尺寸与 HYM 不同 |
| 灯光 | 3000 K | 建立灯带与扩散片实体，CAD 色彩只作示意 |

上述原机唱盘与唱臂参数保留在 `cad/parameters.json`，驱动主 CAD 中 `AssemblySection=Mechanism` 的隐藏历史参考件及图册附录。当前 `AssemblySection=SelectedKit` 的对象使用 `cad/mechanism.json`：Ø280 mm 唱盘借用直臂配图作占位，弯臂按照片近似停放外观，没有已确认的轴距、有效臂长、超距或偏置角。详见[机芯尺寸依据](mechanism.md#尺寸依据)。

## 外观分析

从原始照片辨识：矩形胡桃木侧板围合、顶部黑色台面、前沿银色饰条、后倾横向木格栅与深色透声背衬、左前单旋钮、偏左唱盘、右后唱臂、烟灰透明翻盖及低矮脚垫。模型不附加 HYM 商标。木纹、织物和照明效果不改变实体尺寸。

## 自行设计与估算

当前前沿采用用户选定的 30 × 30 × 5 mm T 型铝材。30 mm 是本项目的选材尺寸，不是从 HYM 图片确认的原厂尺寸；原先 20 mm 仅为概念估算。宽面朝前、居中筋板向后，安装台阶与余量见[型材原图及安装说明](../references/fascia/README.md)。

前沿右侧的 **Ariel** 字样采用用户指定的 Sigmar One 字体。主 CAD 保留独立定制铭牌方案，[矢量稿、字体授权与占位尺寸](../references/nameplate/README.md)已保存；实际板材、厚度、贴附与激光显色仍待商家确认。加入 0.6 mm 铭牌后闭盖总深为 363.8 mm，T 型材和木箱本体尺寸不变。

2026-09-30 用户选择先尝试一体打印镂空支架，配合微型雕刻机直接在铝条上磨字。[打印件与使用说明](../output/3d-print/README.md)已交付；上沿／右端挡边定位、1.2 mm 薄面板及 A／R 连接桥属于试用设计，需在裸型材上操作并补磨桥位。几何连通与导出检查已完成，实际打印收缩、刀头可达性、塑料耐磨和铝面显色尚未验证。工具未替换整机中的 `Nameplate`，现有整机尺寸与图纸仍对应铭牌占位方案。

2026-09-22 已确认脚垫及固定座采购选择：[链接、SKU 与商家原图](../references/feet/README.md)。脚垫橡胶 Ø30 × 20 mm、螺杆 M8 × 23 mm；固定座底盘 Ø37 × 2.5 mm、总高 17 mm。已按用户确认的圆柱向上穿板方式建模，名义离地高 22.5 mm；实物尺寸、孔距、紧固和压缩量待核对。

木壳厚 12 mm，离地高 22.5 mm，木壳顶面高 146.5 mm，盖厚 3 mm，闭盖下缘 147.5 mm。v0.5 将八条木格栅规范为面宽 7 mm、真实法向厚 3 mm 的矩形条，竖向节距 11 mm，后倾 18°。用户提供低音总高 65 mm、口端外径 132 mm，小单元总高 40 mm、口端外径 78 mm，并确认来自 Shockwave SC-2103，原箱和倒相管均已遗失。

v0.11 按 HYM LUMI 官方图的七条格栅比例及用户选定规格，改为 7 条 426 × 10 × 6 mm 矩形条，竖向节距 13 mm，保持后倾 18°。透声布的 0.5 mm 显示占位后移并贴合障板前表面，避免与加厚格栅重叠；实物布厚、张紧、固定和透声影响仍待样机确认。

[SC-2103 古典版实机报道](https://sound.zol.com.cn/2005/0204/149832.shtml)记载 5.25 英寸低音及 3 英寸全频单元，低音箱和卫星箱均有倒相孔。具体版本仍未确认；本方案把两个小单元按全频处理，不再按纯高音压缩背腔。用户实测外廓优先于报道中的名义英寸规格。

底板为完整的 426 × 350 × 12 mm 板，前沿包含原下横梁所在区域；已取消完全重叠的独立下横梁，不加厚、不增设台阶。格栅条与底板仍有名义间隙，格栅固定方式另待设计。

当前低音中心为 X=225、Y=247 mm，安装面 Z=22.5 mm；全频中心 X=80 / 370 mm、Z=84.5 mm，安装于倾斜前障板。法兰厚度暂估 3 mm，计入总高；向箱内深度 62 / 37 mm，低音最低点 Z=19.5 mm。开孔暂估 Ø100 / Ø40 mm；磁体、盆架、锥盆与螺孔尚无准确安装图。

中央贯通低音腔、左右独立密闭试验腔、左右后侧电路区、后置可换倒相管和三点隔振属于本项目重新设计。[音腔专题](audio-layout.md)记录坐标、体积口径、管长及测试边界。缺少 T/S 参数，不能把几何容积或试验管长作为声学匹配已经完成的证据。电路板、马达和唱头仍为接口占位；盖子开角暂取 70°。

共用变压器本体为用户提供的 60 × 55 × 50 mm、固定耳总长 88 mm。固定耳沿长边每侧伸出 14 mm，耳宽 55 mm、耳厚 2 mm 为保守假设；本体与固定耳共用底面，不另加到 50 mm 高度。中心 X=70、Y=267 mm，底面 Z=34.5 mm，置于左后电源区；验证整个 88 × 55 × 50 mm 预留体。实际耳形、孔距、电气、散热及磁场影响未确认。

功放含散热片整体尺寸 125 × 75 × 45 mm，由用户提供。为避让低音腔，水平转 90°，范围 X=335–410、Y=185–310、Z=44.5–89.5 mm，离底板 10 mm 为暂估；孔位、支柱、端子和散热仍待确认。左侧备用电子占位 X=26–106、Y=170–222、Z=44.5–61.5 mm；后接口占位移到右侧，避开低音倒相口。

隔振结构必须保证唱臂与主轴在同一个浮动底板上；此版保留共同承载板及三个弹性支承的空间，弹簧刚度、运动间隙、接线软连接及共振频率均需后续选型。历史通用机芯的轴距和针尖距离检查不能用于确认当前弯臂；当前主验证核对唱盘占位直径，未验证真实循迹、调速、噪声或播放性能。

浮动台面现为 422 × 330 × 10 mm，X=14–436、前缘 Y=6、后缘 Y=336。银色 T 型铝饰条宽面后表面在 Y=5，台面前侧名义间隙为 1 mm；距左右侧板内表面各 2 mm，距后板内表面 Y=338 为 2 mm。三处分别由 `deck_front_fascia_clearance`、`deck_side_clearance` 和 `deck_rear_clearance` 控制；主轴孔整机坐标、支点中心和台面上表面高度不变。三个 Ø16 × 8 mm 弹性支承上下各嵌入 10 mm 音腔顶板和浮动台面 3 mm，两板在沉台处均保留 7 mm；这些沉台、支承尺寸、刚度、压缩与固定均为安装假设。1／2／2 mm 是外观与概念安装余量，尚未按实际浮动行程验证。最终间隙需结合支承水平位移、倾摆、装配偏差及板材尺寸变化核对；静态无实体重叠不能证明浮动时不擦碰，不应将台面与饰条、侧板或后板刚性连接。

## 进入加工前必须补齐

1. 机芯已补充总高85、唱盘Ø280×11及三弹簧近似位置；继续复核底部局部轮廓、安装接口、弹簧承重高度和运动范围。用户确认除弯臂外与原图一致，见[实测适配说明](mechanism.md)。
2. 核实 SC-2103 具体版本和三个单元标识，保留已提供的外径与总高，补齐开孔、螺孔、边沿厚度和实际背部轮廓；低音需 T/S 参数，并核实原功放分频、确定调谐与底部防护网。
3. 确认木板材料、加工方式、连接工艺、表面处理和板厚公差。
4. 实测或获取原机更多正交尺寸，以校准盖高、木壳高、格栅及旋钮；选定合页的轴位、厚度冲突及扭矩另须实物确认。
5. 确认功放、唱放、变压器电气规格和接口；补齐变压器固定耳、功放板孔位及端子图，再设计支承、散热、布线及安装孔。
6. 制作样机测试声反馈、隔振、唱臂循迹、盖子开闭稳定性与声学表现。

本版为外形和空间评审模型，不是原厂 CAD，也不是已经放行的加工文件。

## 版本沿革

v0.2 按当时的“一个低音、两个高音”称呼建立占位并采用用户尺寸。v0.4 根据用户补充的 SC-2103 来源与重新设计授权，改为前置左右全频、后排下向低音、后置倒相管，扩大中央音腔并迁移电子空间。对象 ID `TweeterLeft` / `TweeterRight` 为兼容已有引用保留，显示名称、`DriverRole` 和参数键已改为全频。历史计划不是当前调谐或安装验收依据。

v0.5 根据用户的木工加工优化要求，将平面外廓调整为 450 × 350 mm，保留木壳自身高 124 mm 和原闭盖总高 214.2 mm。板件另列整数矩形备料；斜障板改为真实法向厚 8 mm，斜前缘及接缝仍按几何精确修切。当前没有实测板厚，未定义的装配间隙、榫槽、贴皮和刀具补偿不作整数化推定。

v0.6 依据用户于 2026-09-22 提供的 8-F5 商家图，在左后板增加横装 AC 插座孔 48 × 28 mm、R3，固定孔 2 × Ø4.5 / 上下孔距 40，中心 X=70、Z=108。原木工尺寸与部件位置不变；法兰向后突出 1.88，含法兰总深 351.88 mm。插座和接线采用保守预留，整机电气及实物装配未放行；详见[原图及安装说明](../references/ac-inlet/README.md)。

v0.7 按已购脚垫与固定座更新四套实体。用户确认底盘贴底板下表面、圆柱向上穿板；名义离地高从 26 降至 22.5 mm，箱体及内部件整体下移 3.5 mm，闭盖高 210.7 mm，当时 AC 中心 Z=104.5 mm，v0.9 对称合页布局再下移至 Z=88.5 mm。前脚 Y 从30改为40避开障板；脚座固定孔分布圆 Ø28、底板 Ø12.4 通孔和 Ø3 深8盲预孔为安装假设。原始商品尺寸与这些假设见[脚垫专题](../references/feet/README.md)。

v0.8 采用用户选定的 30 × 30 × 5 mm 铝合金 T 型材，30 mm 宽面朝前、筋板向后；替代此前估算的 20 mm 高饰条。安装长 425 mm，两端各留 0.5 mm；顶板前缘退至 Y=5.2，顶面台阶宽 25、深 3.7、余厚 4.3 mm。0.2 mm 试装／胶层余量、总外廓解释、等厚居中截面与根部圆角均需实测确认，未设计固定孔。详见[原图、SKU 与安装说明](../references/fascia/README.md)。

v0.9 采用两只 HFA5751-3434 可调定位合页，用户提供最大 3 N·m。两张原图、URL、SKU 及尺寸冲突保存在[铰链安装说明](../references/hinges/README.md)。展开57×51、孔距34×34、4×Ø5.2、叶厚4.5；总厚按13.2保守预留，轴筒和轴位为假设。中心X=100/350，距各自箱体外侧均100 mm；AC插座下移16 mm至Z=88.5，变压器前移10 mm至Y=267，保留20 mm接线空间及6.72 mm变压器间隙。轴线Y=356.95、Z=147；上盖用2 mm垫片补偿后壁台阶，内侧2 mm压板分散夹紧力。后板4×Ø3深8盲预孔及罩后壁4×Ø5.5通孔均为安装假设。木箱仍深350，含合页总深363.2 mm；开盖检查至70°，尚无机械限位。保持扭矩、木螺钉抗拔及亚克力强度未放行。

v0.10 将扬声器障板、音腔顶板、两道全深隔板、左右全频腔后板、后部承托梁和浮动承载板统一改为 10 mm 备料。左右隔板起点为 X=129/311，使两侧后板继续保持 117 mm 对称净宽；中央低音腔相应缩窄。为保持台面上表面、外高与已选 T 型材位置不变，三个 Ø16 × 8 mm 弹性支承上下各嵌入顶板／台面 3 mm。顶板加厚后 T 型材前缘台阶深度由 3.7 增至 5.7 mm，槽下余厚仍为 4.3 mm。沉台、支承、板材实厚和连接工艺尚未实物确认。

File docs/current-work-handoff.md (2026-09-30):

# 当前工作交接

- **状态：** 截至 2026-09-30，唯一主装配为 `cad/record-player.FCStd`，FreeCAD 文档名为 `RecordPlayerAssembly`；当前保存版本已包含 Ariel 铭牌，提交为 `ab2cd96`。结构参数版本 `v0.11-10x6-grille-slats`，机芯参数版本 `v0.6-centered-mechanism`。三册最终为19／11／14页，共44页；第一册含17张A3图纸和2张原尺寸A2导览。安装与电气仍未放行。
- **LOGO 当前方向：** 用户选择先尝试一体打印的 [Ariel 镂空雕刻定位支架](../output/3d-print/README.md)，配合微型雕刻机在裸铝饰条上磨字；打印文件与几何验证已交付，实物打印和试刻尚未进行。该工具不计入装配。主 CAD 仍保留独立激光标记铭牌及 [Sigmar One 矢量稿与字体授权](../references/nameplate/README.md)，尚未改成直接磨字后的饰条。
- **规范入口：** 主模型与闭盖交换文件为 `cad/record-player.FCStd`／`cad/record-player.step`，机芯参数为 `cad/mechanism.json`，专题说明为 `docs/mechanism.md`，机芯预览统一使用 `previews/mechanism-*.png`。旧入口不再保留在工作树中。
- **最近模型调整：** 横向木格栅改为 7 条 426 × 10 × 6 mm 矩形条，整体后倾 18°，竖向节距 13 mm；薄实体透声布外观占位后移至贴障板前表面，不与加深后的格栅相交。主文件默认保存 70° 开盖展示；机芯唱盘Ø280×11、总高85、平台108×128×5、三支点R110约1／4／8点。整套机芯右移12 mm至唱盘中心X=188，355 mm基座在浮动甲板上近似居中；指托缩短为16 mm且不越过基座右侧。唱臂其余局部尺寸仍为外观估算。弹簧自由高15.5、估计压缩0–5；电机下探24.5–29.5。
- **当前板厚与台面：** 扬声器障板、音腔顶板、两道全深隔板、左右全频腔后板、后部承托梁和 422 × 330 浮动台面均改为 10 mm 备料；台面到银色 T 型铝饰条后表面 1 mm、左右各 2 mm、后侧 2 mm。主轴孔保持整机 X=188、Y=172 mm，支承中心及台面上表面高度不变。三个 Ø16 × 8 mm 支承上下各嵌入顶板／台面 3 mm，沉台和实际浮动行程尚未验证。
- **合页布局：** 两只合页中心对称设置为 X=100／350，1 号整套合页及对应安装孔向外移动 30 mm；AC 插座下移 16 mm，变压器前移 10 mm。保留两组 2 mm 补偿垫片与 2 mm 内压板、后板 4 个盲预孔与盖后壁 4 个通孔；共用轴线驱动盖与活动安装件。原图、采购链接、SKU、3 N·m 用户信息及厚度冲突见[铰链记录](../references/hinges/README.md)。
- **查看入口：** 主文件默认开盖 70°；STEP、清单、尺寸图及验证以闭盖为基准。历史通用机芯与诊断体分别隐藏，不参加当前装配。开合宏不自动保存，操作及另存说明见 [README](../README.md#模型选择)。
- **脚垫依据：** [已购脚垫与固定座的原图、SKU 及安装说明](../references/feet/README.md)。四套安装，圆柱向上穿板；名义离地高 22.5 mm，螺杆突出固定座 6 mm；孔距和板预孔为安装假设。
- **AC 插座依据：** [两张原图、合图及插座安装说明](../references/ac-inlet/README.md)。左后板中心 X=70、Z=88.5；48 × 28 R3，2 × Ø4.5，上下孔距 40。端子后 20 mm 接线空间暂估；对变压器与承托梁分别有 6.72／22 mm 几何间隙；变压器前移至 Y=267。
- **采购记录：** [插座与电源线链接及 SKU](../references/ac-inlet/README.md#购买链接)已登记。商品规格和电源线适配性尚未核对；电源线未建模，不计入当前外廓。

## 当前模型与尺寸

| 项目 | 当前结果 |
|---|---|
| 闭盖整机外廓 | 机壳 450 × 350 × 210.7 mm，含前侧铭牌与合页总深 363.8；木壳自身高度 124，底面 Z=22.5，顶面 Z=146.5；不是开盖状态的包络 |
| 可调合页 | HFA5751-3434 × 2；中心 X=100／350，轴线 Y=356.95、Z=147；补偿垫片与内压板各 2 mm，安装尺寸为假设 |
| 脚垫及固定座 | 橡胶 Ø30 × 20、螺杆 M8 × 23；固定座底盘 Ø37 × 2.5、圆柱 Ø12 × 14.5；中心 X=33 / 417、Y=40 / 320 mm |
| 矩形板件 | 侧板 350 × 124 × 12；底板 426 × 350 × 12；后板 426 × 112 × 12；浮动台面 422 × 330 × 10 mm |
| 浮动台面间隙 | 到银色 T 型铝饰条后表面 1 mm、左右各 2 mm、后侧 2 mm；X=14–436、前缘 Y=6、后缘 Y=336；浮动行程待验证 |
| 斜障板 | 真实法向厚 10；矩形备料 426 × 98 × 10；上下边修 18° 斜口至安装竖高 90 mm |
| T 型铝饰条 | 30 × 30 × 5；安装长 425，两端各留 0.5 mm；宽面朝前、筋板向后 |
| Ariel 铭牌 | 饰条右侧独立贴附；98 × 22 × 0.6 mm，Sigmar One 矢量字稿；尺寸、材质及固定为概念假设 |
| Ariel 雕刻支架 | 独立工具，打印外廓 109.5 × 32 × 6.5 mm；镂空面板和 A／R 连接桥均为 1.2 mm，上沿／右端挡边厚 2 mm；裸型材定位，未计入整机 |
| 顶板前缘台阶 | 深 5.7、宽 25、余厚 4.3；成形前缘 Y=5.2，轴承孔局部 X/Y=(176, 166.8) mm；另有 3×Ø16 深3 顶面支承沉台 |
| 木格栅 | 7 条 426 × 10 × 6 mm 矩形条，整体后倾 18°，竖向节距 13 mm；透声布外观占位贴障板前表面 |
| 左右对称布局 | 低音中心 X=225；全频中心 X=80 / 370；隔板 X=129 / 311，厚 10；左右全频腔净宽各 117 mm |
| 音腔 | 中央低音几何毛容积 4.584 L、保守净容积 4.041 L；左右全频各毛容积 1.146 L、保守净容积 1.112 L |
| 倒相管 | 低音内径 32、管壁 2、物理长 160 mm；外口 Y=350、内口 Y=190；120／160／200 mm 试验长度均有回归检查 |
| 机芯核对版 | v0.6部分实测；整体右移 12 mm，355 mm 基座在浮动台面上左右余量为 34／33 mm；电机下探24.5–29.5，局部下探估算覆盖不完整，安装未放行 |
| 唱盘与唱臂 | 唱盘 Ø280×11 mm 为实测，中心 X/Y=(188, 172) mm；弯臂总长 250 mm 不是有效臂长。双弯管、连接套、双槽唱头壳、圆垫及 16 mm 指托按参考图片近似；指托最右端 X=402.656，不超过基座右边界 X=403。Ø300 mm／200 mm／218 mm 仅属于隐藏的历史通用机芯 |

`cad/wood-cut-list.csv` 给出 20 块／条板件的整数矩形备料。图册 A-STOCK 与整机导览共用 W01-W11 的标准名称、编号、数量和备料尺寸；W05 是已取消的独立下横梁，编号保留不重排。成形轮廓并非全部整数：斜障板沿 Y 厚约 8.412 mm，隔板前缘必须按准确几何修切，不能逐项四舍五入。名义板厚、锯缝、贴皮、打磨、连接和装配间隙仍需材料与工艺确认。

## 交付入口

- [整机结构导览](assembly-guide.md)：第一册 A-STOCK 后的两页原尺寸 A2 导览与两张高清 PNG，35 个编号覆盖当前装配的 65 个物理对象，并关联三份尺寸图册；不再交付重复的独立 00 PDF。格栅标注随当前目录数量选择，支持少于 4 根格栅的配置。

- [整机主 FCStd](../cad/record-player.FCStd) / [闭盖 STEP](../cad/record-player.step)：唯一装配入口，不再依赖基线文件。旧基线 CAD／STEP 已移除，历史版本可从 Git 找回。
- [图册说明](drawing-pack.md)：3 份横向矢量 PDF，共 44 页；第一册在木板备料汇总后嵌入两张原尺寸 A2 导览，并包含障板局部剖视 A-03。A-H01 至 A-H03 和 B-H01 至 B-H03 给出六种板件的逐孔定位、孔径、盲孔深度及沉台加工面。零件页同时标注成形 XYZ 包络与备料 L × W × T。
- [木板备料表](../cad/wood-cut-list.csv) / [全部零件表](../cad/parts.csv)：前者用于材料准备，后者记录装配包络。
- [主验证报告](../cad/validation.json) / [机芯核对报告](../cad/mechanism-fit-report.json)：不同验证范围，不能互相代替。
- [Ariel 雕刻支架 STL](../output/3d-print/Ariel-stencil.stl) / [打印、使用与独立重建说明](../output/3d-print/README.md)：STL 已摆好无需支撑的打印姿态；A／R 桥位需取下支架后补磨。激光铭牌备选稿见 [Ariel-laser.svg](../references/nameplate/Ariel-laser.svg)。

## 验证证据

主 CAD 已整合部分实测机芯，按弯臂参考图片更新停放外观，机芯整体右移 12 mm、指托缩短为 16 mm；2026-09-30 增加独立激光铭牌后刷新整机交付。可随仓库读取的证据为 `cad/validation.json`、`cad/mechanism-fit-report.json`、`cad/assembly-guide-index.json` 及回归用例；验证和图纸提取会先恢复闭盖工程基准。主文件默认保存 70° 开盖展示，历史参考与诊断对象不进入 STEP 或零件清单。下方分别列当前交付证据与历史批次记录。

两端压缩状态（0／5 mm）下，盖内顶名义净空为 0.7／5.7 mm；盖总成按 0–70° 每 1°抽样检查。局部估算体会与现有结构重叠，未知底部轮廓和真实运动未覆盖，不作为安装放行。

2026-09-23 的浮动台面后缝调整曾验证默认 2 mm 和非默认 7 mm；2026-09-25 进一步将前侧到银色 T 型铝饰条、左右、后侧名义间隙调整为 1／2／2 mm，台面扩大为 422 × 330 mm，随后将备料厚度从 6 mm 增至 10 mm。主轴孔整机坐标、支承中心和台面上表面不变；新增上下各 3 mm 的支承沉台以吸收叠层厚度变化。下表保留当前尺寸核对结果；历史批次单独列在下方。

| 检查 | 当前结果 |
|---|---|
| 浮动台面 | 主 CAD 到饰条／左右／后侧间隙为 1／2／2 mm，备料 422 × 330 × 10 mm；主轴孔局部 X/Y=(174, 166) mm，3×Ø16 底面沉台深3，整机坐标与支承中心不动 |
| 合页安装 | X=100/350，轴线Y=356.95/Z=147；51×57展开，13.2后凸为保守假设 |
| 孔道／板材 | 后板4×Ø3深8后侧盲预孔，余木4；盖后壁4×Ø5.5，垫片与压板同轴 |
| 外廓 | 木箱450×350×210.7；含铭牌与合页450×363.8×210.7 mm，未计紧固件和外线 |
| 声腔 | 三腔封闭与倒相管气路检查通过；盲预孔未贯穿后板内壁 |
| 扭矩 | 裸盖估重0.848 kg，闭盖力矩约1.514 N·m；未计新增五金质量，不作为实测承载 |
| 图号／导览 | A-P06保留；追加A-P08、A-H03；35个导览编号覆盖65个物理对象 |

低音 19.5 mm 离地仍低于旧 20 mm 试验目标，报告单列该状态，不计入几何通过结论。

### 当前铭牌与打印工具交付核对（2026-09-30）

- 主 CAD 重开确认默认角度为 70°，根层有 86 个 `Part::Feature`；当前物理对象 65 个，闭盖 STEP 实体 82 个。独立雕刻支架未加入这些数量。
- 主 CAD 的 SHA-256 为 `08db7b527fcfc7747c2f7a8d27714b8630ba7e80b7e7a8a5b4e3a5e7ee5ed833`。读取核对机芯报告 `model_sha256`、导览索引 `sources` 与第一册 A-00 的 CAD 哈希均与保存文件一致。临时图册提取数据 `tmp/pdfs/drawing-data.json` 也绑定此哈希，但不作为随仓库交付的文件。
- 保存的主验证报告为 `passed: true`，58 项布尔检查均通过，包含铭牌位置／标记和饰条接触两项；这不是实物加工放行。本次文档刷新读取已有报告，没有重新运行整机验证或全量回归。
- 三册 PDF 回读页数为 19／11／14，共 44 页；第一册顺序为 A-00、A-STOCK、G-01、G-02，再继续原详图，现有图号保持不变。
- 雕刻支架专项 6 项测试通过，STL／STEP／FCStd 导出文件回读通过，正视与立体投影已目视检查。原无界面导出缺少 GUI 显示数据，已用独立 GUI 宏重新保存；重开确认默认可见，实际三维视口已核对。新增检查覆盖保存的 GUI 可见状态／相机和无界面导出拒绝；细项见 [工具验证状态](../output/3d-print/README.md#验证状态)。实物打印贴合、刀头可达性、模板耐磨及最终显色仍未验证。

### 单文件与开盖交付核对（2026-09-25，历史）

以下记录对应增加铭牌前的批次；旧 CAD 哈希与测试数量不代表当前交付版本。

- 唯一主 CAD 默认保存开盖 70°，当时 64 个物理对象导出为闭盖 STEP 的 81 个实体；16 个历史参考对象不进入装配导出。旧基线 FCStd／STEP 已移出 `cad/`，历史版本可从 Git 找回。
- 主 CAD 不再创建零件分组，85 个 `Part::Feature` 全部直接位于对象树根层，逐件点击无需展开文件夹；原分类保存在每个零件的只读 `AssemblySection` 属性中。16 个历史参考件与 5 个诊断体仍分别默认隐藏。
- 单文件整合保留了结构、音腔、电子件与合页几何；机芯参数现为 `v0.6-centered-mechanism`，10 个 `Kit*` 对象继续保留部分实测尺寸、三弹簧支点和两端压缩状态检查。机芯整体右移12 mm，弯臂与唱头壳的局部造型按参考图片更新，仍属于外观估算。
- 当时主验证 56 项通过，机芯报告 13 项几何／导出检查通过。该批次主 CAD 的 SHA-256 为 `0babcb831caca3fa34089d4067b9ffa54a0f77b043d93c50d023c4b8668d66e5`；旧报告与图册数据当时绑定此版本，现已由上方当前交付版本替代。
- FreeCAD 实际重开确认默认角度 70°；执行开合宏后为 0°，再次执行恢复 70°。往返测试核对活动总成与固定件几何，尺寸提取使用闭盖基准且不改写源文件。
- FreeCAD 全量回归发现 55 项用例，46 项通过，9 项 PDF 用例按运行时条件跳过；独立 PDF 环境的 9 项全部通过，包含临时 CAD 重建、数据提取、三册排版，以及非默认弹簧位置在保存实体、C-00 与 C-P05 文字中的一致性。新增断言核对 10 mm 目标板件的保存法向厚度、上下沉台与支承叠层，并验证扩大任一沉台时保存实体检查会失败；同时覆盖浮动台面前／侧／后参数化间隙、前饰面基准、非正值及排除主轴孔／弹性支承的越界值拒绝、备料尺寸与保存实体一致、A-STOCK 与导览的编号／名称／数量／尺寸完全相同、非默认 AC 开孔参数同步进入后板备料说明，并验证两页 A2 导览在第一册 A-STOCK 后幂等插入、基础图册 CAD 哈希与 17 页图号序列，以及预览失败时不发布部分产物。
- 本轮格栅专项断言覆盖 1／3／7／8 根配置的导览标注目标、默认 7 根的目录数量、426 × 10 × 6 mm 备料与保存几何，以及 13 mm 竖向节距。中间格栅与透声布占位的保存几何间隙为 1.133 mm，与障板为 1.608 mm，两处共同体体积均为 0。
- 三册最终页数为 19／11／14；第一册由 17 张 A3 图纸和 A-STOCK 后两张原尺寸 A2 导览组成，不再保留重复的独立导览 PDF。G-01 与 G-02（含后部接口小图）在编号下直接显示目录名称，材料、数量与详图号仍保留在右侧目录；两页共用相同的内容边界、主视图、左右标注列和右侧目录宽度。PDF 文字回读确认 G-01 的 15 个与 G-02 的 20 个目录标题均同时出现在图中标注和右侧目录，两页尺寸均为 594 × 420 mm。合成前核对第一册与导览来自同一保存 CAD；合并 PDF、索引和 PNG 全部生成成功后才替换正式文件。本轮已目视检查 A-STOCK、G-01、A-03 与 A-P04，核对格栅数量、备料尺寸、剖视关系和详图标注；主模型、报告、图册和导览均来自同一保存 CAD。

### 历史验证记录

此前合页对称调整的双向布尔差确认，两套均仅改变 Back、DustCover、ACInlet、PowerTransformer 及 1 号合页四件；整套合页横移 −30 mm、插座下移 16 mm、变压器前移 10 mm。证据在忽略的 `tmp/hinge-symmetry-study/saved-check.json`；`tmp/hinge-symmetry-before/gui/` 保存当时另存的 GUI 文档。

随后合页图纸说明改为读取盲孔深度、压板厚度等参数，并补充非默认参数回归；该修复未改变当时默认安装尺寸或保存几何。历史批次为 36 项 CAD、5 项 PDF 用例通过，日志在 `tmp/hinge-fix/cad-tests.log`、`pdf-tests.log`，图册专项在 `drawing-tests.log`。当前全量回归包含这些用例。

`tmp/hinge-qa/`、`tmp/t-fascia-review/`、`tmp/t-fascia-rebuild/`、`tmp/foot-preview-fix/` 及上述合页目录均为旧批次证据，不作为当前模型哈希或本次单文件合并的验收结果；历史结论不替代本节列出的最新验证范围。

## 已知问题与待修项

- [ ] **机芯接口与空间待适配。** 用实物模板复核R110约1／4／8点支承、马达平面位置及轮廓，测定承重高度和安装座基准。声腔避让需保留密封，上盖余量需覆盖实物公差、抬臂与隔振运动；当前板件未据估算切削。

- [ ] **浮动台面实际运动间隙待确认。** 到银色 T 型铝饰条后表面 1 mm、左右各 2 mm、后侧 2 mm 是名义安装余量。需结合实际支承的水平位移、倾摆、装配偏差及板材尺寸变化核对最小剩余间隙；静态无实体重叠不能证明浮动时不擦碰，台面不得与饰条、侧板或后板刚性连接。

- [ ] **合页实物与紧固待确认。** 13.2／12.8 mm厚度冲突、轴线、最大3 N·m口径与寿命、亚克力孔隙／压紧力、木螺钉抗拔及70°机械限位未验证。2 mm垫片与压板、Ø5.5盖孔、Ø3深8木预孔为安装假设，见[铰链说明](../references/hinges/README.md)。

- [ ] **T 型铝饰条固定与实物截面待确认。** 总外廓解释、等厚居中筋板、端隙 0.5 mm、槽隙 0.2 mm 为建模条件或假设。根部圆角未建模，胶层及机械固定待设计，槽下 4.3 mm 木厚不能直接按普通木螺钉安装。详见[型材安装说明](../references/fascia/README.md)。

- [ ] **Ariel 镂空支架待实物打印与试刻。** 按 [打印与使用说明](../output/3d-print/README.md)先核对薄面板、内孔连接桥和裸型材挡边贴合，在同材质边角料确认刀尖／刀杆可达性、模板耐磨、桥位补磨与铝面显色。加工前拆下饰条，2 mm 挡边不能放入装机后的 0.5 mm 端隙。主 CAD 仍为独立铭牌占位，直接磨字方案尚未同步到装配；若回到激光铭牌方案，再确认板材、厚度、贴附与商家效果，不能把 0.02 mm 可视化浅凹作为加工深度。

- [ ] **脚垫实物紧固与密封待确认。** 四套脚垫与固定座已建模；Ø28 mm 孔分布圆、Ø12.4 mm 板孔、Ø3 mm 深 8 mm 盲预孔为假设。名义离地 22.5 mm 不包含螺钉头凸出；需核对螺钉头与 Ø30 mm 橡胶避让、有效啮合、密封及承载，见[采购与安装说明](../references/feet/README.md)。

## 重建与 GUI 保护

使用 FreeCAD 1.1.1。整机一次生成和预览 → 主模型验证 → 图册提取与排版，完整入口见 [README](../README.md#整机重建) 和[图册说明](drawing-pack.md#重新生成)。导览在图册同步后按[导览说明](assembly-guide.md#重新生成)单独渲染和排版。

雕刻支架是独立工具，关闭旧工具文档并另存手动编辑后，在 FreeCAD GUI 执行 `tools/build-logo-stencil.FCMacro`；详细入口见 [工具重建命令](../output/3d-print/README.md#重新生成)。不要直接用无界面 Python 导出 FCStd。仅修改工具脚本中的面板、挡边或桥宽时，刷新独立文件、SVG／PNG 和专项测试即可；若改动主装配参数 JSON，仍遵循整机重建与图纸同步约定。

重建前先另存需要保留的手动编辑，并关闭目标文档。脚座安装剖视和合页局部视图由 `tools/build.FCMacro` 临时裁切副本生成；T 型铝条与顶板的剖面位于图册 A-03，由图册提取／排版流程生成。用户窗口若显示旧版或未保存编辑，应先另存再重新打开磁盘模型。

`tools/build_model.py` 同时检查主文档名和解析符号链接后的输出路径，保护已打开目标。导览索引和图册数据的 `sources` 只记录主 CAD 的 SHA-256，不包含脚本或 PDF 哈希。CAD 更新后必须重新提取、渲染与排版。机芯报告改用 `model_sha256` 绑定最终保存的主文件。

当前三份交付 PDF 使用显式指定的 STHeiti Light 字体生成。脚本旧默认字体路径在此次环境中不可用；重建时通过 `--font` 传入可嵌入的中文字体，见[图册命令](drawing-pack.md#重新生成)和[导览命令](assembly-guide.md#重新生成)。

## 剩余边界

- AC 入口为两芯 C8 机械候选，不能提供保护接地；实际认证、绝缘、保险、端子护套、接线与 12 mm 后板螺钉适配均待核实，不能凭几何通过通电。
- 板件名义尺寸优化不等于加工放行：材质、真实板厚、接缝、紧固孔、公差和表面处理尚待确认。
- 机芯已有部分实测及近似支点，但底部平面轮廓、紧固接口、承重高度和运动范围仍需复核。承托面与 10 mm 顶板上表面相差12 mm，电机估计下探24.5–29.5，条件性净深缺口12.5–17.5 mm；上盖未压缩状态名义竖向间隙仅0.7 mm。局部估算包络不能证明实物能否安装。
- 单元外径与总高来自用户，开孔 Ø100／Ø40、法兰厚 3 mm、背部轮廓等仍是假设。
- 几何容积与试验倒相管不代表声学调谐完成；电气、散热、声反馈、隔振和播放功能尚未实物验证。
- 左右全频仍是密闭试验腔；可封堵倒相接口只是既有讨论，未在本轮新增。

后续工作分别以[音腔专题](audio-layout.md)、[机芯安装专题](mechanism.md)、[加工前资料清单](design-basis.md#进入加工前必须补齐)和 [LOGO 工具说明](../output/3d-print/README.md)为准。待办真源为本文“已知问题与待修项”，保留机芯接口、浮动台面运动间隙、合页实物安装、T 型铝条固定、LOGO 打印试刻及脚垫实物确认；专题文档记录各自尺寸依据与验收条件。

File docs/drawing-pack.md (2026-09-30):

# 机体分类平面图册

阅读尺寸图前，可先查看[整机全景与组件导览](assembly-guide.md)：两页原尺寸 A2 导览插在第一册 A-STOCK 之后，并另有两张高清 PNG；35 个编号关联当前装配的部件、材料状态和下列图册中的详图号。不再交付内容重复的独立 00 PDF。

基于当前已保存的单一主 CAD（`v0.11-10x6-grille-slats` 结构与 `v0.6-centered-mechanism` 机芯参数），输出 **3 份横向矢量 PDF，共 44 页**。主体图纸为 A3；第一册另嵌入两张原尺寸 A2 导览页。轮廓直接由 FreeCAD TechDraw 投影，包络尺寸由实体的 `optimalBoundingBox(False)` 读取；孔径、孔位和深度来自对应建模参数及板件局部基准，并通过回归检查核对保存实体。出图脚本仅读取已重建的 CAD，不修改源文件。

机芯总览 C-00 与基座详图 C-P05 的支点半径、钟点位置由 `cad/mechanism.json` 生成。非默认位置回归同时核对保存的弹簧实体、提取说明及两页 PDF 文字。

| 图册 | 页数 | 内容 |
|---|---:|---|
| [01 整机与外壳](../output/pdf/01-assembly-and-enclosure.pdf) | 19 | 读图约定、木板备料汇总、紧随其后的两页原尺寸 A2 整机导览、闭盖六面图、侧板、底板、后板、格栅与饰条、灯带、防尘盖、铰链、脚垫与固定座及同形件位置表；障板局部剖视、底板／后板／防尘盖后壁开孔定位，含合页垫片与压板 |
| [02 音腔与内部结构](../output/pdf/02-acoustic-and-structure.pdf) | 11 | 内部布置、斜面障板、音腔顶板、左右后板、隔板、轴承避让杯、倒相管、浮动台面、承托梁及弹性支承；障板、音腔顶板和浮动底板开孔定位 |
| [03 机芯与电子部件](../output/pdf/03-mechanism-and-electronics.pdf) | 14 | AC 插座、扬声器、功放、电子预留、变压器、接口板、旋钮、当前弯臂机芯各零件；附基线通用机芯三视总图与尺寸记录 |

## 障板装配与板件开孔定位

底板前沿一体保留，取消原独立下横梁。A-P03 左侧改为底板引用说明，透声布仍在右侧；其余旧零件图号保留。v0.9 新增 A-P08 和 A-H03 后，第一册从 15 页增为 17 页。

前沿饰条现为 425 mm 长、30 × 30 × 5 mm T 型铝材，A-P02 保留原图号。顶板 B-H02 的 O 点随新成形前缘移至整机 Y=5.2；v0.6 机芯右移后，轴承孔整机坐标为 X/Y=(188, 172) mm。台阶剖面见 A-03。槽隙及端隙为假设，详见[饰条安装说明](../references/fascia/README.md)。

A-P02 同时注明右侧独立 Ariel 铭牌的位置；铭牌轮廓供商家使用[1:1 SVG 矢量稿](../references/nameplate/Ariel-laser.svg)，不占用退役的 A-P03 左侧图位，也不改变现有零件图号。

浮动台面 B-P04 与孔表 B-H03 已同步为 422 × 330 × 10 mm；台面到银色 T 型铝饰条后表面为 1 mm、左右各 2 mm、后侧 2 mm。B-H02／B-H03 分别增加 3×Ø16、深3 mm 的顶面／底面弹性支承沉台。v0.6 机芯中心保持不变，B-H03 主轴孔心局部坐标为 (174, 166) mm，导览编号 W11 保留。沉台、名义间隙和实际隔振行程均为待验证安装条件，详见[设计依据](design-basis.md)。

当前六种板件共标注 39 个通孔／盲预孔／支承沉台及 1 处后板同心沉台：底板 17、后板 8、盖后壁 4、障板 2、音腔顶板 4、浮动底板 4。合页叶片及垫片／压板的孔另在零件页说明，不计入上述 39 项。保留原 `A-Pxx`、`B-Pxx` 零件图号，新增下列详图；导览中的原图号仍有效。PDF 阅读器页码会因插页变化，请优先按图号查找。

| 图册与页码 | 图号 | 内容 |
|---|---|---|
| 01，第 7 页 | A-03 | 箱体中线 X=225 的前部局部剖视；显示 T 型铝条与顶板台阶、格栅、透声布、障板及底板；标注台阶深 5.7／余厚 4.3、障板后倾 18°／法向厚 10／安装竖高 90 mm |
| 01，第 16 页 | A-H01 | 底板底面视图：低音通孔、4 个脚座通孔及 12 个底面盲预孔，逐孔编号、孔径、局部坐标和孔深 |
| 01，第 17 页 | A-H02 | 后板倒相通孔及后侧同心沉台、AC 圆角矩形孔、上下固定孔及4个铰链盲预孔；标注圆角、孔距、沉台深度和加工面 |
| 01，第 18 页 | A-H03 | 防尘盖后壁4×Ø5.5通孔，局部X=71/105/321/355，Z=16.5；安装假设 |
| 02，第 8 页 | B-H01 | 障板前表面法向视图：2 × Ø40 声孔，局部 X=68/358、斜面 S=52.573 mm，孔轴垂直板面 |
| 02，第 9 页 | B-H02 | 音腔顶板 Ø28 轴承孔，局部 X/Y=(176, 166.8) mm；前缘台阶宽 25、深 5.7、余厚 4.3 mm；3×Ø16 顶面沉台深3 mm |
| 02，第 10 页 | B-H03 | 浮动底板 Ø20.4 暂定主轴孔，局部 X/Y=(174, 166) mm；3×Ø16 底面沉台深3 mm |

当前 A-H02 的 AC 开孔中心为局部 (58, 54) mm，上下固定孔为 (58, 34)／(58, 74) mm；合页盲预孔局部 X=71／105／321／355、Z=95.5 mm。A-H03 使用相同局部 X、Z=16.5 mm。两种板件上的合页孔整机 X 均为 83／117／333／367 mm，基准换算见[合页安装布局](../references/hinges/README.md#v09-安装布局)。

合页盲预孔直径、深度、余木及垫片／压板尺寸说明随 `hinges` 参数生成。回归使用非默认盲孔 Ø3.2、深 7 mm、压板厚 3 mm、高 20 mm 及盖孔 Ø5.8，核对保存实体、零件说明与孔表的一致性；这些测试值不改变当前默认安装尺寸。

孔表均以图中 **O 点所在的成形边**为定位基准，不以矩形备料毛边定位。底板从下方向上看，+Y 在图中向下；后板从箱内向后看，后侧沉台用虚线叠画，不翻转孔位。障板的 **S 沿前表面量取**：孔心投影竖高 50 mm 对应斜面距离 52.573 mm，不能用 50 mm 沿斜面划线。图中标出的通孔、沉台和盲孔来自当前模型及参数；未确认的声孔、脚座及合页安装尺寸仍保留假设说明。

无已建模开孔的木板另注明连接孔待工艺确认。扬声器固定螺孔、功放／变压器固定孔、板件连接孔、接口板孔位，以及当前机芯固定孔和轮廓开口尚未定义，不虚构孔径或位置。本版图纸随可调合页、后板与盖后壁安装孔更新，加工仍未放行。

## 尺寸与覆盖范围

- 长 X：左右方向；宽 Y：前后方向；高 Z：上下方向。表中数值是装配姿态下的外包络，不按最大边自动排序。原点为机体左前方桌面基准，坐标表记录实体包络最小角。
- 各主要零件给出俯、正、右三个独立命名视图；不同视图可使用不同的标注比例。不是统一第一角或第三角投影排列。第一册 G-01／G-02 使用 A2 原尺寸，其余图纸使用 **A3、100% 实际大小**；混合打印时按 PDF 页面原尺寸输出，尺寸以标注数值为准。
- 厚度与长宽高分别列出。平板给板厚，防尘盖给壁厚；采购总成的未知壁厚或 PCB 厚度，以及实心件不适用的壁厚，明确写在说明中。
- 斜障板现在为真实法向厚 10 mm，矩形备料 426 × 98 × 10 mm，修上下 18° 斜口至安装竖高 90 mm。音腔顶板、两道全深隔板、左右全频腔后板、后部承托梁和浮动台面也使用 10 mm 备料；格栅为 7 条 426 × 10 × 6 mm 矩形条，整体后倾 18°、竖向节距 13 mm，透声布显示占位贴障板前表面。
- 木板零件页另列整数备料 L × W × T；第一册 A-STOCK 按导览编号 W01-W11 汇总 20 块 / 条，W05 作为已取消的独立下横梁保留编号空缺，并同步输出[木板备料 CSV](../cad/wood-cut-list.csv)。A-STOCK 与整机导览共用标准名称、编号、数量和备料尺寸；备料尺寸不含锯缝、表面处理及装配余量，精确斜切边界和接口孔仍允许小数。
- 同形件采用代表件视图、数量与各安装位置；`AcousticRear` 和 `RearSupport` 各包含两个独立实体，按两块分别出图。
- 覆盖主模型 **65 个当前装配对象**，另有 **16 个历史参考对象**全部有附录尺寸记录。基线通用机芯在附录中按总成三视图及逐对象尺寸表表示；不与当前弯臂机芯同时安装。
- 诊断矩形包络及红色干涉体不是实物零件，不作为零件下料图；假设下探深度及剩余净空在机芯总图中记录。

第一册 A-P06 分别绘制固定叶和活动叶，各 2 件，两叶合计 1 只采购合页，共 2 只；没有独立采购铰链轴。新增 A-P08 为补偿垫片／内压板，第 18 页 A-H03 为透明盖后壁孔表。A-H02 增加 4 个后侧铰链盲预孔。安装孔均是假设，见[铰链说明](../references/hinges/README.md)。

第一册 A-P07 并列脚垫及固定座；底板标注四处 Ø12.4 通孔和底面盲预孔。固定座孔分布圆 Ø28、板上间隙及预孔为安装假设，未放行加工。

后板已标注横装 AC 开孔 48 × 28 mm、R3 和上下两孔 Ø4.5 / 孔距 40；插座法兰向后突出 1.88 mm；当前整机图中合页后端 Y=363.2 mm，连同前侧 0.6 mm 铭牌的总深为 363.8 mm。插座外形与端子为保守包络，适用板厚、紧固与电气安全待实物确认。

后板零件页、A-H02 孔标注、木板备料 CSV 和第一册 A-STOCK 的 AC 开孔加工说明均读取 `ac_inlet` 参数；非默认开孔宽高与螺孔直径由回归用例核对。`ACInlet.DimensionBasis` 继续记录供应商资料与建模假设，不能用备料说明替代原图依据。电源线目前仅有[购买记录](../references/ac-inlet/README.md#购买链接)，未作为 CAD 零件或图册对象出图。

图册包含当前已有的开孔直径、定位坐标、后板沉台、倒相管壁厚及法兰信息。小数显示到 0.001 mm 是数值记录精度，**不是公差承诺**。防尘盖为成形外廓，未设计热弯展开、拼接工艺；未建模的螺孔、连接、公差和机芯安装接口仍未定义，不能直接作为生产加工图。

## 重新生成

先确认主 CAD 与两份 JSON 参数一致。本工具读取主文件的临时副本，校验结构及机芯参数快照，再恢复闭盖基准提取投影；不会重建或改写源 CAD。零件直接位于文档根层，提取器按只读 `AssemblySection` 属性选择分类，不依赖 FreeCAD 树分组。源 SHA-256 写入第一册首页，当前装配与历史参考分开统计，所有既有零件图号保持不变。

`drawing_data.py` 调用 `drawing_details.py` 提取六种板件（含透明盖后壁）的孔表、障板前表面法向投影及箱体中线临时剖面；`drawing_pack.py` 调用 `drawing_detail_pages.py` 排版。剖面只表示实际截面轮廓，不把包围盒边当作实体边。

下面的命令在仓库根目录执行；先按 [README](../README.md#整机重建) 设置 `FREECAD_RESOURCES`。默认输入输出相对脚本所在仓库解析。字体示例 `tmp/fonts/chinese-font.ttf` 是项目相对路径占位，需自行准备可嵌入的中文字体或替换为已有字体的相对路径：

```sh
# 在仓库根目录：提取 CAD 实体、精确尺寸与矢量投影。
PYTHONPATH="${FREECAD_RESOURCES:?请先设置 FreeCAD 运行环境}/lib" \
  "$FREECAD_RESOURCES/bin/python" tools/drawing_data.py

# 普通 Python 环境需要 reportlab、svglib、pypdf 和 Poppler；使用可嵌入的中文字体。
python3 tools/drawing_pack.py --font tmp/fonts/chinese-font.ttf

# 在 FreeCAD 中执行 tools/assembly-guide.FCMacro 刷新导览视图后，
# 将两张 A2 导览插入第一册，并同步导览 PNG 与索引。
python3 tools/assembly_guide_pdf.py --font tmp/fonts/chinese-font.ttf
```

提取逻辑或数据结构变化后，须先重跑 `drawing_data.py`，不要直接用旧 JSON 排版。中间数据保存在忽略的 `tmp/pdfs/drawing-data.json`；最终目录为 `output/pdf/`。`--data`、`--output` 可覆盖默认路径。`drawing_pack.py` 先生成 17／11／14 页基础图册；`assembly_guide_pdf.py` 再把第一册合成为 19 页最终交付物。图册排版入口只读取指定 JSON，不重新校验其源 CAD 哈希；CAD 更新后必须重新提取，并按上述顺序重跑导览宏和合成脚本。

请显式传入存在且可嵌入的中文字体。脚本保留的旧默认字体路径不保证可用，也不会自动搜索替代字体。当前 v0.11 交付使用 STHeiti Light；TrueType 集合 `.ttc` 需确认默认子字体可由 ReportLab 读取并覆盖所需字符。图中文字嵌入 PDF，阅读者不需要安装同一字体。

生成最终 PDF 需要 `reportlab`、`svglib`、`pypdf` 和可嵌入的中文字体；PDF 回归测试另需 `pdfplumber`，页面渲染需要 Poppler 的 `pdftoppm`。这些依赖运行于普通 Python，不要求装入 FreeCAD 自带环境。

验证：

```sh
PYTHONPATH="${FREECAD_RESOURCES:?请先设置 FreeCAD 运行环境}/lib" \
  "$FREECAD_RESOURCES/bin/python" -m unittest discover -s tests -v

# 在具有上述 PDF 依赖的普通 Python 中执行图册与导览回归。
FREECAD_RESOURCES="${FREECAD_RESOURCES:?请先设置 FreeCAD 运行环境}" \
  python3 -m unittest discover -s tests -p '*_pdf.py' -v

# 每次生成后渲染检查，避免轮廓、尺寸线和文字错位。
mkdir -p tmp/pdfs
pdftoppm -scale-to 1500 -png output/pdf/01-assembly-and-enclosure.pdf tmp/pdfs/01
pdftoppm -scale-to 1500 -png output/pdf/02-acoustic-and-structure.pdf tmp/pdfs/02
```

FreeCAD 环境没有 `reportlab` 或 `svglib` 时会明确跳过 PDF 图册用例，须在依赖齐备的普通 Python 环境补跑；同时检查导览时使用 `-p '*_pdf.py'`。出图检查覆盖板孔坐标与实体空腔、底面盲孔深度、障板法向投影及斜面孔位、非默认参数、实体对象遗漏、复合对象拆分、斜板厚度、投影方向、源文件不变，以及 SVG 像素单位转换造成的 PDF 缩放偏差。完整基础图册回归需要将 `FREECAD_RESOURCES` 传入测试进程：它从当前保存 CAD 提取数据，在临时目录调用三册 PDF 命令行入口，核对未嵌入导览时的 17／11／14 页、A/B/C-POS 安装位置表与保留零件图号，并确认源 CAD 未改写。导览专项用合成 PDF 核对 A-STOCK 后插入顺序、A2 原尺寸、书签、基础图册 CAD 哈希／17 页图号序列、重复生成不叠加，以及预览失败时不发布部分产物；最终 19／11／14 页成品仍须实际生成后回读页数并目视检查。该回归使用 ReportLab 自带字体验证执行流程；中文字体与实际页面布局仍需对交付 PDF 单独目视检查。未传入运行环境时该项会明确跳过。

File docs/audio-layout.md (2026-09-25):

# SC-2103 三音腔布局

文档更新：2026-09-25；模型版本：v0.11-10x6-grille-slats。用户确认扬声器来自 Shockwave SC-2103，原低音箱、卫星箱和倒相管均已遗失，授权按唱机外廓重新设计。该版交付空间方案及可换管试验结构，尚未完成声学调谐或加工放行。

## 布置与尺寸

外廓调整为 450 × 350 × 210.7 mm。坐标原点为左前方桌面，X 向右、Y 向后、Z 向上，单位均为 mm。

三音腔俯视：上方是后侧，隐藏顶板与前障板以显示内部

| 项目 | 当前布置 |
|---|---|
| 左右全频单元 | 口端 Ø78、总高 40；中心 X=80 / 370、Z=84.5，朝前安装于后倾 18° 的障板 |
| 后排低音 | 口端 Ø132、总高 65；中心 X=225、Y=247，安装面 Z=22.5，朝下；最低点距桌面 19.5 |
| 中央低音腔 | 净宽 172，X=139–311；从斜面障板内侧延伸至后板内面 Y=338；底面 Z=34.5、顶面 Z=124.5 |
| 左右全频腔 | 各净宽 117；斜面障板至 Y=150，Z=34.5–124.5；相互及与低音腔不通气，先采用密闭试装 |
| 分隔结构 | 两道 10 mm 全深隔板位于 X=129–139 / 311–321；左右后隔板 Y=150–160；10 mm 声腔顶板 Z=124.5–134.5 |
| 左后变压器 | 固定耳保守包络 X=26–114、Y=239.5–294.5、Z=34.5–84.5 |
| 左侧备用电子区 | X=26–106、Y=170–222、Z=44.5–61.5；在机芯核对版中不代表另需唱放 |
| 右后功放 | 含散热片 125 × 75 × 45，平放旋转 90°；X=335–410、Y=185–310、Z=44.5–89.5 |
| 后接口占位 | 移至右侧 X=324–429，与中央低音倒相管分开；实际接口开孔和插拔空间未设计 |

斜障板法向厚度为 10 mm，沿 Y 的厚度约 10.515 mm；对应隔板下前角 Y≈26.515、上前角 Y≈55.758。前缘按该精确轮廓闭合，不能把接缝坐标取整。整数备料与修切说明见[图册](drawing-pack.md)。

前沿 T 型铝条的安装台阶位于斜障板前方，不进入三音腔密封边界；上表中的 10 mm 顶板厚度适用于音腔封闭部分。前伸部分 Y=5.2..30.2 加工 5.7 mm 深台阶后余厚 4.3 mm，三腔几何容积不受前缘台阶影响，详见[饰条安装说明](../references/fascia/README.md)。顶板另有三个 Ø16 × 3 mm 顶面沉台，与浮动台面底面的同尺寸沉台共同定位 Ø16 × 8 mm 弹性支承；沉台不贯穿音腔，尺寸与隔振效果仍为安装假设。

后部承托梁分成左右两段，中央利用音腔顶板承托原有后支点。低音腔顶板为通用机芯轴承增加封闭避让杯，外半径 14、内半径 12、底面 Z=106.5、内底面 Z=108.5。它只适用于基线的通用轴承占位，不能作为当前弯臂机芯的适配证据。

## 体积与计算口径

以下由 [保存模型验证报告](../cad/validation.json)计算，并非根据外廓长宽高直接估计。

| 音腔 | 几何毛容积（已扣封闭避让杯） | 扣除安装包络和倒相管后的保守净容积 |
|---|---:|---:|
| 中央低音 | 4.584 L | 4.041 L |
| 左全频 | 1.146 L | 1.112 L |
| 右全频 | 1.146 L | 1.112 L |

验证时只临时封住设计的单元开孔和倒相口，从保存的板件中求出三个互不连通的封闭空间。净容积扣除所有已建模部件在腔内的占用；扬声器使用实心圆柱安装包络，变压器使用包含固定耳上方空间的完整包络，倒相管扣除整个外廓（包括管内空气）。重叠占用通过布尔差集只扣一次，避免漏扣移入音腔的电子件，也避免把空心盆架当作几乎不占容积的部件。未计尚未建模的吸音材料、支柱、密封件和线缆；实物轮廓及这些附加占用仍会改变有效容积。脚座穿板孔由保存的脚垫／固定座实体理想贴合封闭；回归检查移除固定座后能检出泄漏。封闭几何不代表实物拼缝或螺纹已经气密。

此前中央低音腔几何毛容积约 1.53 L；10 mm 结构板版本当前约 4.58 L。这个增长说明空间利用改善，不代表低频性能提高了相同比例。

## 后置可换倒相管

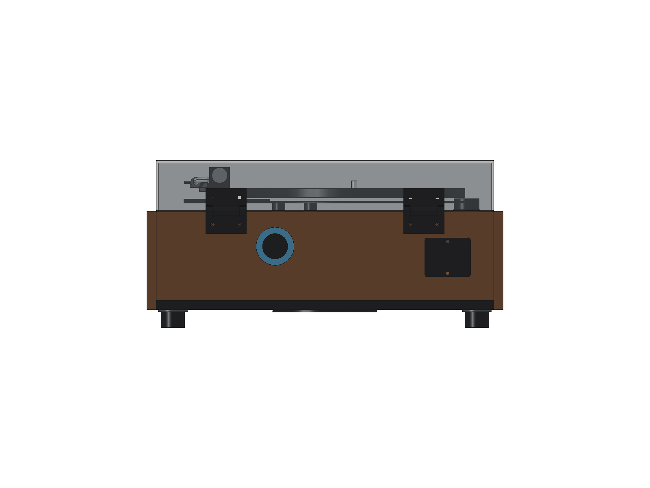
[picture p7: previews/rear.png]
后视：倒相管法兰与后板齐平


- 初始内径 32、壁厚 2、外径 36；总物理长度 160，包含后板内的部分，不另加板厚。
- 轴线 X=288、Z=102.5，沿 Y 方向。外口在后板外面 Y=350，内口 Y=190；从后板内面向腔内伸入 148。
- 法兰外径 48、厚 3，沉入后板保持外廓。整体从后方抽出、更换不同长度的管件；不用胶将管永久粘死。图中配合是名义贴合，密封圈、紧固件、加工间隙与两端圆角尚未细化。
- 已检查 120、160、200 三种物理长度；三者在当前基线均可容纳，管内及内端前方一个管内径长度的圆柱区域不被安装包络和结构阻挡。改变长度后须重建和复验，净容积随管道占用变化。
- 左右全频腔先密闭试装，后隔板保留为独立件，便于样机阶段调整。不能直接向后方电子区打孔充当卫星箱倒相口，否则会改变腔体边界和有效容积。

32 × 160 是受空间约束的试验初值，未取得 SC-2103 单元的 Fs、Qts、Vas、振幅限制或原功放分频曲线，没有据此承诺调谐频率、低频截止、声压或允许功率。小管径在较大音量时可能产生气流声，需要在样机上测量后决定是否改管径或改用密闭方案。

参考 [Eminence 箱体设计说明](https://eminence.com/blogs/blog/cabinet-recommendations)：后置倒相口可行，但摆放与背后墙面会影响表现，管口必须保持畅通；增大容积、降低调谐也会改变单元机械负担。本项目没有把其他品牌单元的推荐容积或调谐数值套用到 SC-2103。

## 左右全频腔的后续方案

当前 CAD 中左右各为约 1.11 L 的密闭试验腔，没有卫星箱倒相管或可封堵接口。这是缺少单元参数时的试装起点，不代表已经证明密闭更合适，也不代表有独立低音单元就可以省略全频腔调谐。原机古典版报道记载卫星箱也有倒相孔，见[设计依据](design-basis.md#自行设计与估算)。

会话中提出的后续建议是左右各预留一个可封堵、可换管接口，用于比较密闭与倒相两种方案；目前只保留建议，尚未确定管径、管长、出口或紧固结构。若后续实施，先检查前格栅后方或侧面出管的空间，每根管只连通所属音腔和箱外，不连通低音腔或电子区，也不套用低音管的尺寸。

实施时需同步 `cad/parameters.json`、`tools/build_model.py`、`tools/validate_model.py` 和回归测试：当前封闭性检查只临时封住三个扬声器开孔及低音倒相口，新增卫星倒相口后须明确其气路、归属、封堵方式和管道排量，再重建主模型与相关预览。声学取舍仍需样机测量；几何检查不能代替这一步。

已购脚垫按未压缩高度计算，低音离地 19.5 mm，低于此前 20 mm 试验目标；验证报告单列该目标未满足，几何检查不宣称出声空间已足够。

## 验证与后续试装

基线检查涵盖三个独立音腔、管道尺寸与气路、扬声器实心安装空间、电子包络和 STEP 回读。回归测试故意在隔板开孔及堵住倒相管，确认检查确实能发现问题，并覆盖三种试验管长。音腔探测点随当前前后边界、隔板和高度变化；回归测试覆盖后隔板前移至 Y=100 mm，以及功放、变压器分别移入低音腔后的净容积扣除。GUI 渲染后的唱盘直径使用精确几何边界读取，避免显示三角网格造成尺寸误报。

装机先确认单元悬边与音圈状态、真实开孔及原功放输出接线，再用低音量进行频响、漏气和异响检查。用可拆管和可封堵口对比不同方案；保持相同音量与摆位，依据测量选择，不以“低音更响”代替整体响应判断。唱针落盘播放时还要独立检查声反馈及隔振。

当前弯臂机芯已采用部分实测尺寸，电机相对弹簧承托面下探约24.5–29.5 mm；底部局部位置与轮廓仍为估算，与现有声腔结构有重叠；[核对报告](../cad/mechanism-fit-report.json)继续标记 `installation_released=false`。取得实物底部轮廓后再决定局部避让、顶板高度和管道走向，不能按当前报告直接加工整机。

## 重建入口

修改 `cad/parameters.json` 的 `fullrange`、`woofer`、`acoustic`、`acoustic_divider_x`、`bass_port` 及电子部件参数，按 [README](../README.md#整机重建)重建并验证整机。`TweeterLeft` / `TweeterRight` 仅保留为稳定对象 ID，其角色与显示名称已改为全频。更换管长不会自动更新保存的静态实体。

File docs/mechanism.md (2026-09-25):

# 弯臂机芯与装配核对

选型为淘宝商品 `712086565319`、SKU `5162746531784` 的 **“28高端弯臂机芯全套餐装好直接用 自动回臂”**。套装图片包含机芯、功放板、机芯线、RCA 后板和电源线。商品详情未能读取，以下以用户提供的图片为依据；电气参数尚未确认。

## 尺寸依据

2026-09-24 用户收到实物，确认除弯形唱臂外，其余结构与原直臂配图一致，并确认唱头指托不会越过机芯基座右侧。原图的 355 mm 总宽据此沿用；唱盘厚度改用实测 11 mm。机芯整体向右移动 12 mm；浮动台面扩展后，355 mm 基座在台面上的左右余量约为 34／33 mm，唱盘中心仍为 X=188 mm。机芯参数现为 `v0.6-centered-mechanism`，资料见[原图与实测记录](../references/mechanism/README.md)。

| 项目 | 当前依据与处理 |
|---|---|
| 唱盘 | 用户实测 Ø280 × 11 mm |
| 机芯总高 | 用户实测 85 mm；暂按下部 40 + 平台厚 5 + 上部 40 解释 |
| 唱臂平台 | 用户提供前后 128、底部宽 108、厚 5 mm；平面位置及矩形轮廓近似 |
| 唱臂支架高度 | 平台上方 40 mm；支座截面暂估 |
| 电机最低点 | 低于机芯上的弹簧安装座底部 40 mm；安装座暂与平台下表面共面 |
| 三个弹簧 | 自由高 15.5 mm，承重缩短估计不到 5 mm；用 0–5 mm 区间检查，非测定行程 |
| 三个支点 | 唱盘圆心 R110 mm，俯视约 1／4／8 点；12 点朝后、3 点朝右，位置近似，不作为钻孔数据 |
| 唱臂 | 总长 250 mm，有限位器和支架；暂作含配重及唱头的停放纵向外廓，非有效臂长 |
| 仍未知 | 马达直径及平面位置、完整底部轮廓、唱盘相对平台的高度、固定孔、真实限位角及运动范围 |

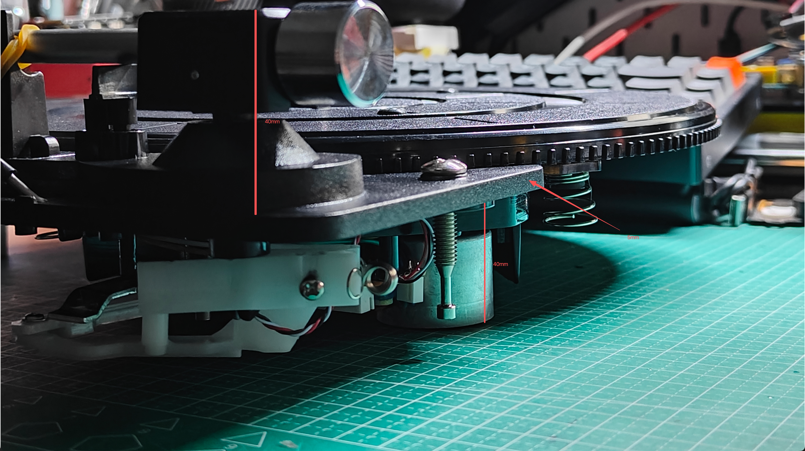
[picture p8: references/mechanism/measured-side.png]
用户标注的侧面尺寸


以当前台面上表面 Z=146.5 mm 为弹簧承托面，默认显示压缩 5 mm 的边界状态：弹簧高 10.5、安装座 Z=157、平台顶 Z=162、电机最低点 Z=117、机芯最高点 Z=202 mm。未压缩状态整体上移 5 mm。此处还没有设计独立承托座、凹槽或垫片。

`KitBase` 包含近似基座和三个中空套筒式弹簧外廓；套筒不是实际弹簧线材。机芯的三个弹簧与基线台面的三个 `Isolator` 是两组不同支承；本轮保留台面原结构，两级隔振的刚度及运动尚未验证。马达、传动与回臂机构的局部估算体标记为 `AssemblySection=FitAnalysis`，不作为实物零件导出 STEP。估算参数集中在 `appearance_assumptions`：电机 Ø45、相对主轴偏移 (+105,+25)，传动区 Ø160／深20，回臂区 80×90／深30、偏移 (+120,+60) mm；均非用户实测，不能据此加工。

唱臂外观按 `curved-arm-kit.png` 重画：银色管先沿前方伸出，再通过两段相切圆弧向机身右侧偏移 30 mm；前端使用黑色连接套，唱头壳向左偏转 14°，带双槽、三枚圆形顶面垫和侧向指托。指托暂按 16 mm 外观长度建模，右端不超过机芯基座。模型保持解析直线／圆弧扫掠，便于稳定导出 STEP。管径、15 mm 弯曲半径、弯折位置、连接套和唱头壳局部尺寸都只是照片比例估算，不代表实测尺寸、有效臂长或加工数据。

原 v0.2 的 300 mm 唱盘、200 mm 唱臂轴距和 218 mm 有效长度不适用于这款机芯。

## CAD 与核对结果

[整机主模型](../cad/record-player.FCStd) 与[闭盖 STEP](../cad/record-player.step)由结构参数和机芯参数一次生成。主文件默认开盖 70°，所有零件直接位于对象树根层，并用只读 `AssemblySection` 属性区分结构、当前机芯、历史参考及安装诊断；后两类默认隐藏。历史通用机芯不进入当前装配或 STEP。无需保留另一份基线 CAD。

| 继承部件 | 用户提供的外廓 | 仍待确认 |
|---|---|---|
| 低音 × 1 | 口端 Ø132 mm，总高 65 mm | 开孔、边沿厚度、孔位及背部轮廓；朝下安装 |
| 全频 × 2 | 口端 Ø78 mm，总高 40 mm | 开孔、边沿厚度、孔位及背部轮廓；朝前安装 |
| 共用变压器 × 1 | 本体 60 × 55 × 50 mm，固定耳总长 88 mm | 固定耳宽厚、孔距及高度基准 |
| 功放板 × 1 | 125 × 75 × 45 mm，已含散热片 | 安装孔、支柱、端子及散热条件 |

扬声器总高包含暂估的 3 mm 边沿，开孔仍暂估。RCA 后板继承 v0.5 的右后侧空间占位，备用电路板区域不代表需要另购唱放。布局及估算依据见[设计依据](design-basis.md)。

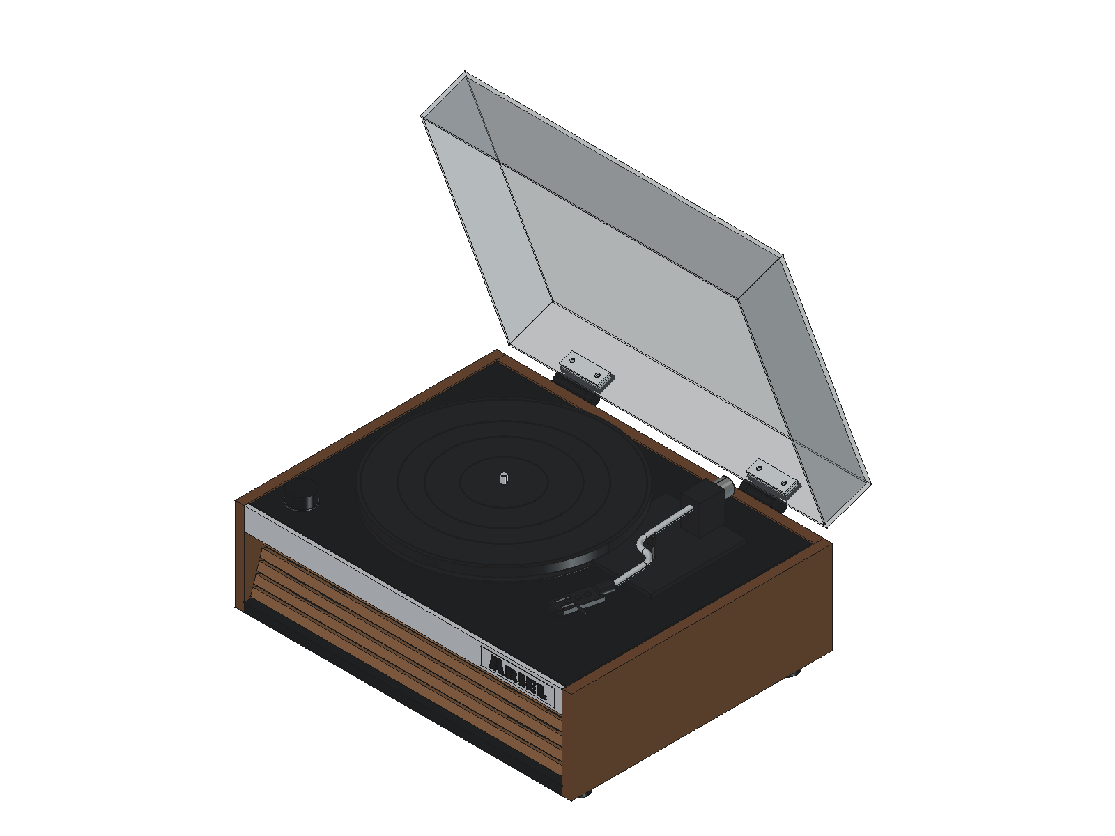
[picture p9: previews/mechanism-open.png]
弯臂机芯开盖示意


现有弹簧承托面与 10 mm 声腔顶板上表面相差 **12 mm**。弹簧压缩 0／5 mm 时，电机相对承托面的下探为 **24.5／29.5 mm**，在其下方存在顶板的条件下分别缺 **12.5／17.5 mm**，尚未包含动态与装配余量。局部估算体在两个状态均与承载板及声腔顶板重叠；压缩5 mm时还与倒相管重叠。共用板件保留原形，未据此切削或降低整块顶板。

该局部估算体替代旧的 355×280×45 mm 矩形占位，但**不覆盖全部真实底部结构**。有重叠不能证明实物必然碰撞，没有重叠也不能证明可安装。三个弹簧仅给出位置及轴向高度区间，未设计紧固孔和最终开口。

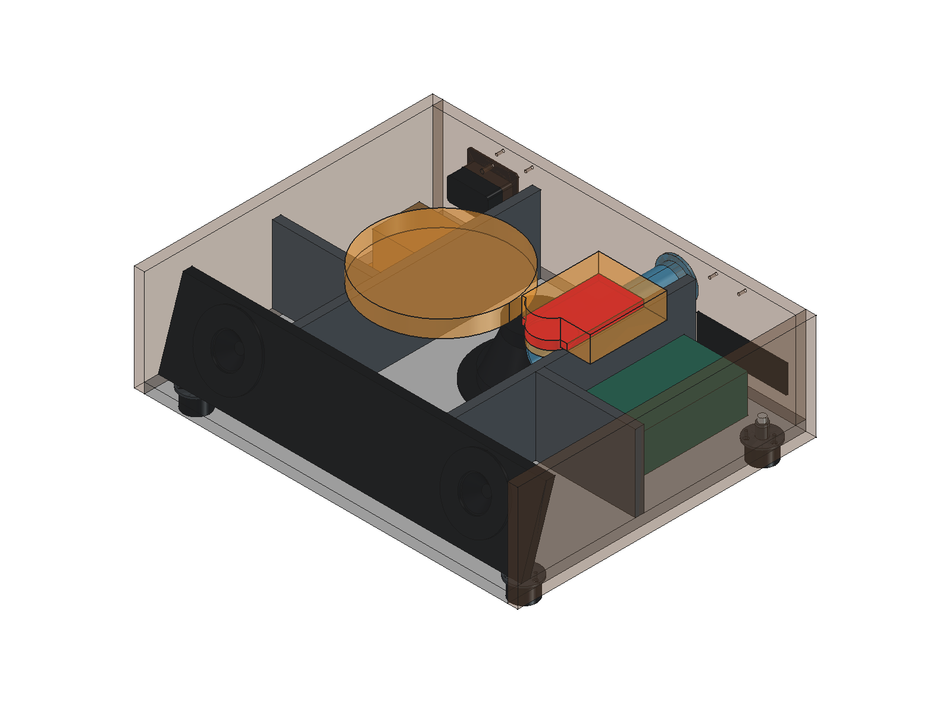
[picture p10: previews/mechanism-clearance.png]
局部下探空间与声腔顶板


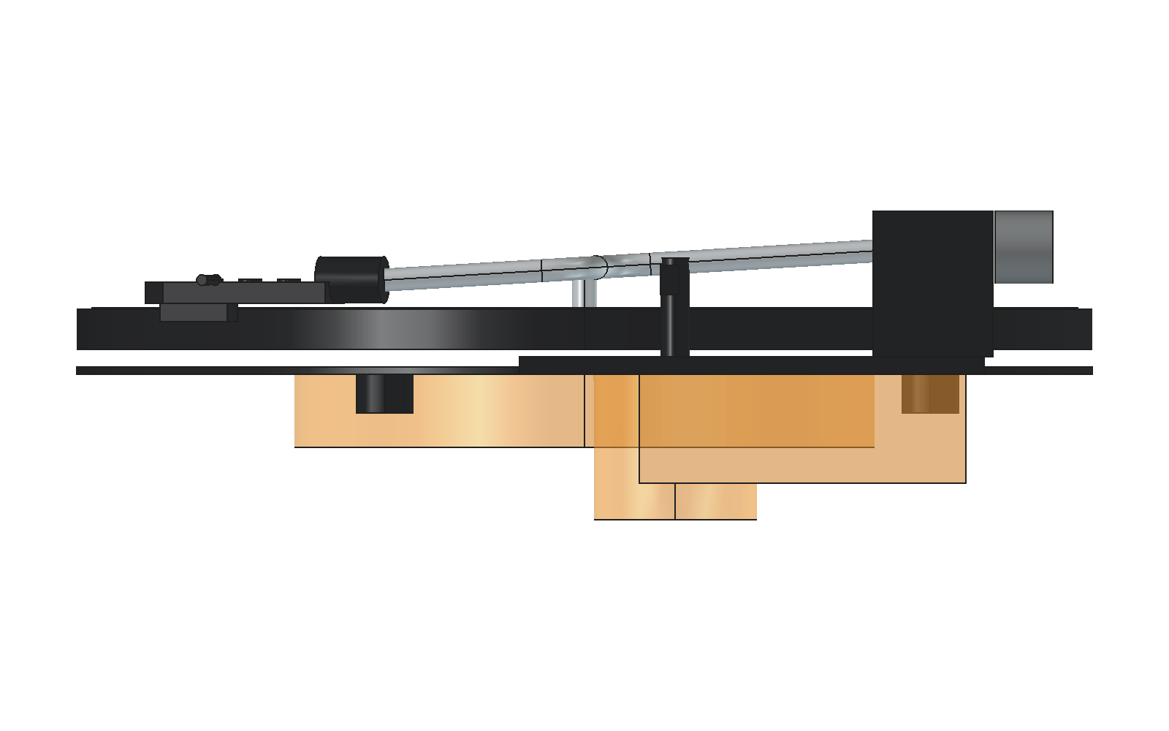
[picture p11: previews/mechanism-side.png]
机芯右视与局部下探估算


压缩 0／5 mm 时，最高点到上盖内顶面的名义竖向差为 **0.7／5.7 mm**；未压缩状态余量很小。核对报告的13项几何／导出检查通过；两个状态闭盖实体最小距离分别为0.7／5.7 mm，均无重叠，0–70°每1°共71个姿态的盖总成抽样也未检出示意机芯干涉。示意实体无干涉不代表真实唱臂抬升、回臂、弹簧倾摆和盖壳公差已验证。报告保持 `installation_released=false`、`dimensions_confirmed=false` 和 `underbody_coverage_complete=false`。

报告的 `display_closed_cover_clear`／`display_cover_clearance_mm` 仅描述当前显示状态；`illustrative_closed_cover_clear`／`illustrative_cover_clearance_mm` 汇总显示状态与两个弹簧端点，净空取最小值（当前为0.7 mm）。`spring_endpoints_closed_cover_clear` 与 `spring_endpoints_cover_sweep_clear` 纳入 `geometry_checks`；任一端点闭盖或开盖抽样发生碰撞，命令行／宏检查即失败，并保留报告供定位。两端抽样仍不等于连续弹簧行程或真实运动验证。

## 后续适配与重建

下一步用实物纸模板复核三个弹簧位置、接触直径及马达位置／外廓，测定承重高度并确认安装座与平台的高度关系。随后确定台面开口、局部密封避让和隔振支承；当前支点角度及底部轮廓不能直接用于钻孔。功放板还需补齐安装孔位、端子位置并核对供电、输出通道、负载和分频接法；套装不意味着能直接驱动当前三个扬声器。

当前核对版继承合页中心 X=100／350 mm、AC 插座中心 Z=88.5 mm 和变压器中心 Y=267 mm；这些位置由结构参数控制，不在机芯参数中重复定义。详见[合页参数与联动重建](../references/hinges/README.md#参数与重建)。

浮动台面现为 422 × 330 × 10 mm；到银色 T 型铝饰条后表面为 1 mm、左右各 2 mm、后侧 2 mm，分别由 `deck_front_fascia_clearance`、`deck_side_clearance` 和 `deck_rear_clearance` 控制。v0.6 机芯中心仍为整机 X/Y=(188, 172) mm，主轴孔局部坐标随台面外廓改为 X/Y=(174, 166) mm；支承中心和台面上表面高度未变。三个 Ø16 × 8 mm 支承上下各嵌入顶板／台面 3 mm，沉台及隔振性能仍为安装假设。名义间隙尚未按实物隔振运动验证，见[设计依据](design-basis.md)。

参数入口按部件区分：[结构参数](../cad/parameters.json) 控制外壳、扬声器、变压器、功放及合页安装；[机芯参数](../cad/mechanism.json) 控制弯臂机芯占位及下探假设。

1. 先把手动改动另存并关闭主模型。修改结构或机芯参数后均执行 `tools/build.FCMacro`，一次重建全部实体、STEP、报告与预览；无需先生成另一份 CAD。
2. 运行 `tools/validate_model.py`，再按图册与导览文档重新出图。几何检查通过不表示安装放行，当前 `installation_released=false`，仍有假设下探包络重叠。
3. 报告中的 `model_sha256` 绑定最终保存的主文件。手动另存或覆盖后如需使用报告，应重新生成并核对哈希。

无 GUI 时按 [README](../README.md#整机重建) 设置 `FREECAD_RESOURCES` 后执行：

```sh
PYTHONPATH="${FREECAD_RESOURCES:?请先设置 FreeCAD 运行环境}/lib" \
  "$FREECAD_RESOURCES/bin/python" tools/build_model.py
```

终端入口不刷新 GUI 颜色和预览。查看开合使用 `tools/toggle-cover.FCMacro`；它只切换当前文档，不自动保存。出图、导览与验证在临时副本中恢复闭盖基准，不受保存的展示角度影响。

音响布局详见 [SC-2103 三音腔设计](audio-layout.md)。低音腔向后延伸后，顶板与倒相管仍需按弯臂机芯真实底部重新核对。`BearingPocket` 是基线通用轴承的密封避让杯，在核对版中作为现有结构保留，不代表适配了当前机芯。

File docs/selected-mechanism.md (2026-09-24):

# 已选弯臂机芯与装配核对

选型为淘宝商品 `712086565319`、SKU `5162746531784` 的 **“28高端弯臂机芯全套餐装好直接用 自动回臂”**。套装图片包含机芯、功放板、机芯线、RCA 后板和电源线。商品详情未能读取，以下以用户提供的图片为依据；电气参数尚未确认。

## 尺寸依据

2026-09-24 用户收到实物，确认除弯形唱臂外，其余结构与原直臂配图一致，并确认唱头指托不会越过机芯基座右侧。原图的 355 mm 总宽据此沿用；唱盘厚度改用实测 11 mm。机芯整体向右移动 12 mm，使 355 mm 基座在浮动甲板上的左右余量约为 32／31 mm；唱盘中心 X=188 mm。机芯参数现为 `v0.6-centered-mechanism`，资料见[原图与实测记录](../references/selected-mechanism/README.md)。

| 项目 | 当前依据与处理 |
|---|---|
| 唱盘 | 用户实测 Ø280 × 11 mm |
| 机芯总高 | 用户实测 85 mm；暂按下部 40 + 平台厚 5 + 上部 40 解释 |
| 唱臂平台 | 用户提供前后 128、底部宽 108、厚 5 mm；平面位置及矩形轮廓近似 |
| 唱臂支架高度 | 平台上方 40 mm；支座截面暂估 |
| 电机最低点 | 低于机芯上的弹簧安装座底部 40 mm；安装座暂与平台下表面共面 |
| 三个弹簧 | 自由高 15.5 mm，承重缩短估计不到 5 mm；用 0–5 mm 区间检查，非测定行程 |
| 三个支点 | 唱盘圆心 R110 mm，俯视约 1／4／8 点；12 点朝后、3 点朝右，位置近似，不作为钻孔数据 |
| 唱臂 | 总长 250 mm，有限位器和支架；暂作含配重及唱头的停放纵向外廓，非有效臂长 |
| 仍未知 | 马达直径及平面位置、完整底部轮廓、唱盘相对平台的高度、固定孔、真实限位角及运动范围 |

用户标注的侧面尺寸

以当前台面上表面 Z=146.5 mm 为弹簧承托面，默认显示压缩 5 mm 的边界状态：弹簧高 10.5、安装座 Z=157、平台顶 Z=162、电机最低点 Z=117、机芯最高点 Z=202 mm。未压缩状态整体上移 5 mm。此处还没有设计独立承托座、凹槽或垫片。

`KitBase` 包含近似基座和三个中空套筒式弹簧外廓；套筒不是实际弹簧线材。机芯的三个弹簧与基线台面的三个 `Isolator` 是两组不同支承；本轮保留台面原结构，两级隔振的刚度及运动尚未验证。马达、传动与回臂机构的局部估算体只留在 `FitAnalysis`，不作为实物零件导出 STEP。估算参数集中在 `appearance_assumptions`：电机 Ø45、相对主轴偏移 (+105,+25)，传动区 Ø160／深20，回臂区 80×90／深30、偏移 (+120,+60) mm；均非用户实测，不能据此加工。

唱臂外观按 `selected-curved-arm-kit.png` 重画：银色管先沿前方伸出，再通过两段相切圆弧向机身右侧偏移 30 mm；前端使用黑色连接套，唱头壳向左偏转 14°，带双槽、三枚圆形顶面垫和侧向指托。指托暂按 16 mm 外观长度建模，右端不超过机芯基座。模型保持解析直线／圆弧扫掠，便于稳定导出 STEP。管径、15 mm 弯曲半径、弯折位置、连接套和唱头壳局部尺寸都只是照片比例估算，不代表实测尺寸、有效臂长或加工数据。

原 v0.2 的 300 mm 唱盘、200 mm 唱臂轴距和 218 mm 有效长度不适用于这款机芯。

## CAD 与核对结果

[整机主模型](../cad/lumi-selected-mechanism-fit.FCStd) 与[闭盖 STEP](../cad/lumi-selected-mechanism-fit.step)由结构参数和机芯参数一次生成。主文件默认开盖 70°，结构、所选机芯、历史参考及安装诊断分别分组；后两组默认隐藏。历史通用机芯不进入当前装配或 STEP。无需保留另一份基线 CAD。

| 继承部件 | 用户提供的外廓 | 仍待确认 |
|---|---|---|
| 低音 × 1 | 口端 Ø132 mm，总高 65 mm | 开孔、边沿厚度、孔位及背部轮廓；朝下安装 |
| 全频 × 2 | 口端 Ø78 mm，总高 40 mm | 开孔、边沿厚度、孔位及背部轮廓；朝前安装 |
| 共用变压器 × 1 | 本体 60 × 55 × 50 mm，固定耳总长 88 mm | 固定耳宽厚、孔距及高度基准 |
| 功放板 × 1 | 125 × 75 × 45 mm，已含散热片 | 安装孔、支柱、端子及散热条件 |

扬声器总高包含暂估的 3 mm 边沿，开孔仍暂估。RCA 后板继承 v0.5 的右后侧空间占位，备用电路板区域不代表需要另购唱放。布局及估算依据见[设计依据](design-basis.md)。

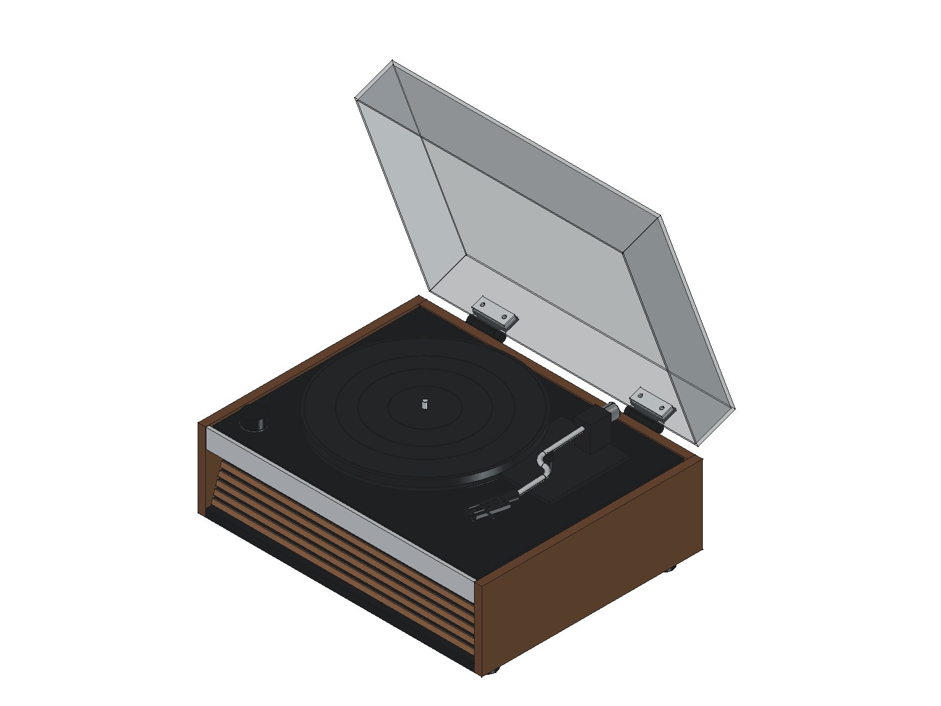
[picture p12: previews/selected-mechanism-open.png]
弯臂机芯开盖示意


现有弹簧承托面与声腔顶板上表面相差 **14 mm**。弹簧压缩 0／5 mm 时，电机相对承托面的下探为 **24.5／29.5 mm**，在其下方存在顶板的条件下分别缺 **10.5／15.5 mm**，尚未包含动态与装配余量。局部估算体在两个状态均与承载板及声腔顶板重叠；压缩5 mm时还与倒相管重叠。共用板件保留原形，未据此切削或降低整块顶板。

该局部估算体替代旧的 355×280×45 mm 矩形占位，但**不覆盖全部真实底部结构**。有重叠不能证明实物必然碰撞，没有重叠也不能证明可安装。三个弹簧仅给出位置及轴向高度区间，未设计紧固孔和最终开口。

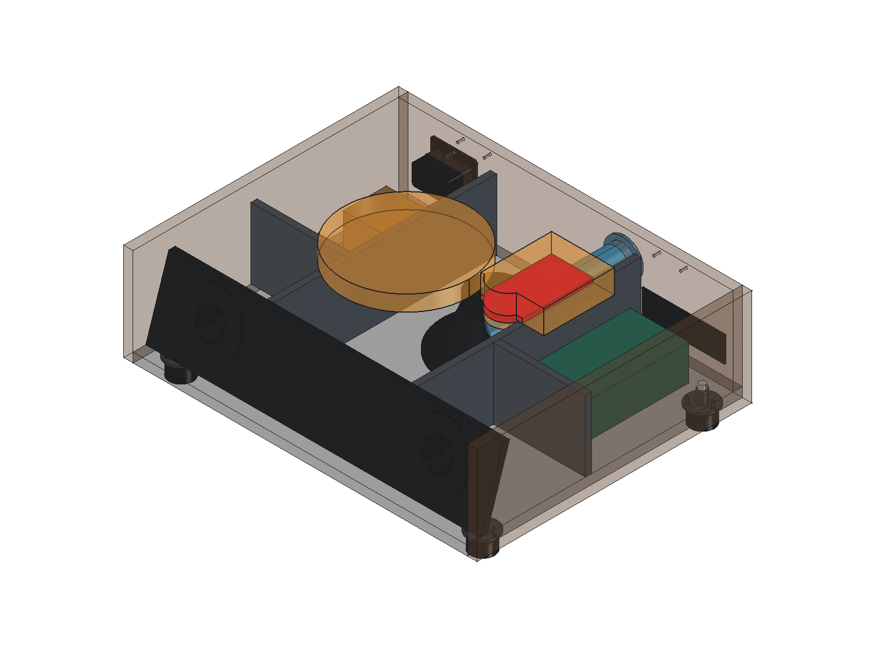
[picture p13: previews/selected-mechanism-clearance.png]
局部下探空间与声腔顶板


机芯右视与局部下探估算

压缩 0／5 mm 时，最高点到上盖内顶面的名义竖向差为 **0.7／5.7 mm**；未压缩状态余量很小。核对报告的13项几何／导出检查通过；两个状态闭盖实体最小距离分别为0.7／5.7 mm，均无重叠，0–70°每1°共71个姿态的盖总成抽样也未检出示意机芯干涉。示意实体无干涉不代表真实唱臂抬升、回臂、弹簧倾摆和盖壳公差已验证。报告保持 `installation_released=false`、`dimensions_confirmed=false` 和 `underbody_coverage_complete=false`。

报告的 `display_closed_cover_clear`／`display_cover_clearance_mm` 仅描述当前显示状态；`illustrative_closed_cover_clear`／`illustrative_cover_clearance_mm` 汇总显示状态与两个弹簧端点，净空取最小值（当前为0.7 mm）。`spring_endpoints_closed_cover_clear` 与 `spring_endpoints_cover_sweep_clear` 纳入 `geometry_checks`；任一端点闭盖或开盖抽样发生碰撞，命令行／宏检查即失败，并保留报告供定位。两端抽样仍不等于连续弹簧行程或真实运动验证。

## 后续适配与重建

下一步用实物纸模板复核三个弹簧位置、接触直径及马达位置／外廓，测定承重高度并确认安装座与平台的高度关系。随后确定台面开口、局部密封避让和隔振支承；当前支点角度及底部轮廓不能直接用于钻孔。功放板还需补齐安装孔位、端子位置并核对供电、输出通道、负载和分频接法；套装不意味着能直接驱动当前三个扬声器。

当前核对版继承合页中心 X=100／350 mm、AC 插座中心 Z=88.5 mm 和变压器中心 Y=267 mm；这些位置由结构参数控制，不在机芯参数中重复定义。详见[合页参数与联动重建](../references/hinges/README.md#参数与重建)。

浮动台面也继承基线的 418 × 328 × 6 mm 尺寸和 2 mm 名义后缝，由 `deck_rear_clearance` 控制。主轴孔、支承位置及台面高度未变；后缝尚未按实物隔振运动验证，见[设计依据](design-basis.md)。

参数入口按部件区分：[结构参数](../cad/parameters.json) 控制外壳、扬声器、变压器、功放及合页安装；[机芯参数](../cad/selected-mechanism.json) 控制弯臂机芯占位及下探假设。

1. 先把手动改动另存并关闭主模型。修改结构或机芯参数后均执行 `tools/build.FCMacro`，一次重建全部实体、STEP、报告与预览；无需先生成另一份 CAD。
2. 运行 `tools/validate_model.py`，再按图册与导览文档重新出图。几何检查通过不表示安装放行，当前 `installation_released=false`，仍有假设下探包络重叠。
3. 报告中的 `model_sha256` 绑定最终保存的主文件。手动另存或覆盖后如需使用报告，应重新生成并核对哈希。

无 GUI 时按 [README](../README.md#整机重建) 设置 `FREECAD_RESOURCES` 后执行：

```sh
PYTHONPATH="${FREECAD_RESOURCES:?请先设置 FreeCAD 运行环境}/lib" \
  "$FREECAD_RESOURCES/bin/python" tools/build_model.py
```

终端入口不刷新 GUI 颜色和预览。查看开合使用 `tools/toggle-cover.FCMacro`；它只切换当前文档，不自动保存。出图、导览与验证在临时副本中恢复闭盖基准，不受保存的展示角度影响。

音响布局详见 [SC-2103 三音腔设计](audio-layout.md)。低音腔向后延伸后，顶板与倒相管仍需按弯臂机芯真实底部重新核对。`BearingPocket` 是基线通用轴承的密封避让杯，在核对版中作为现有结构保留，不代表适配了选定机芯。

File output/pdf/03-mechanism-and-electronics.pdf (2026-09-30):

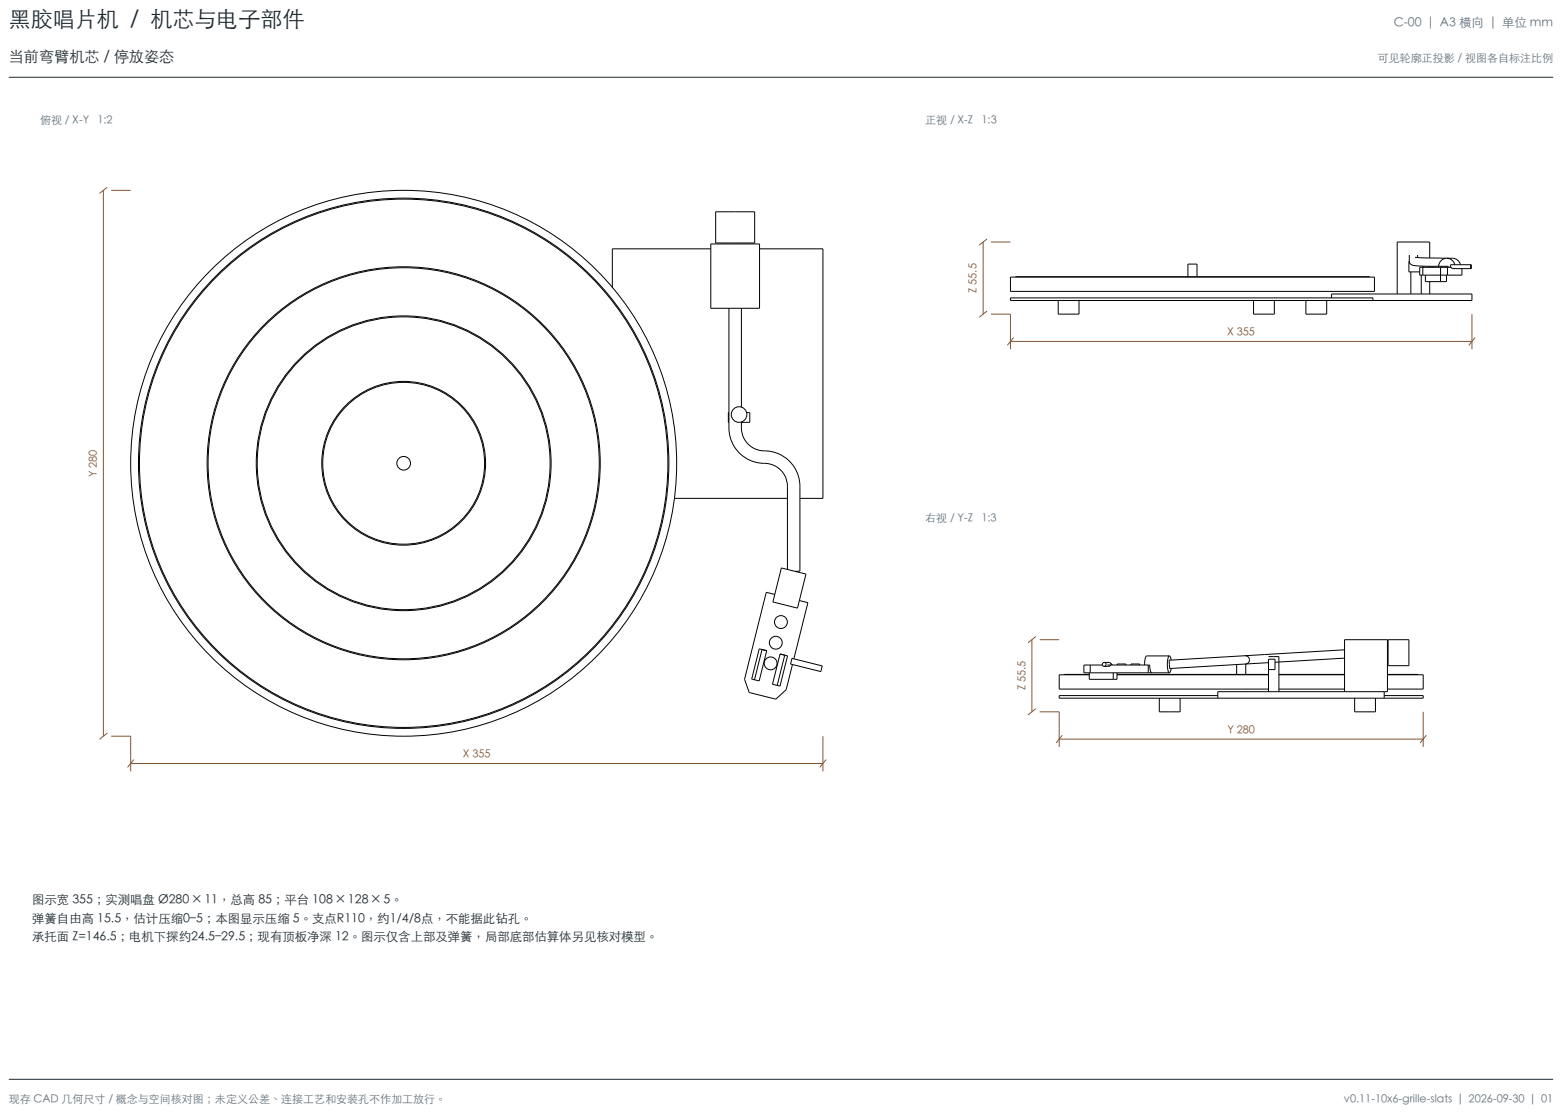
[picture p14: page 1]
黑胶唱片机 / 机芯与电子部件; 当前弯臂机芯 / 停放姿态; 可见轮廓正投影 / 视图各自标注比例; 现存 CAD 几何尺寸 / 概念与空间核对图；未定义公差、连接工艺和安装孔不作加工放行。; v0.11-10x6-grille-slats | 2026-09-30 | 01

图示宽 355；实测唱盘 Ø280 × 11，总高 85；平台 108 × 128 × 5。
弹簧自由高 15.5，估计压缩0–5；本图显示压缩 5。支点R110，约1/4/8点，不能据此钻孔。
承托面 Z=146.5；电机下探约24.5–29.5；现有顶板净深 12。图示仅含上部及弹簧，局部底部估算体另见核对模型。

## 8 字 AC 插座

## 后排低音

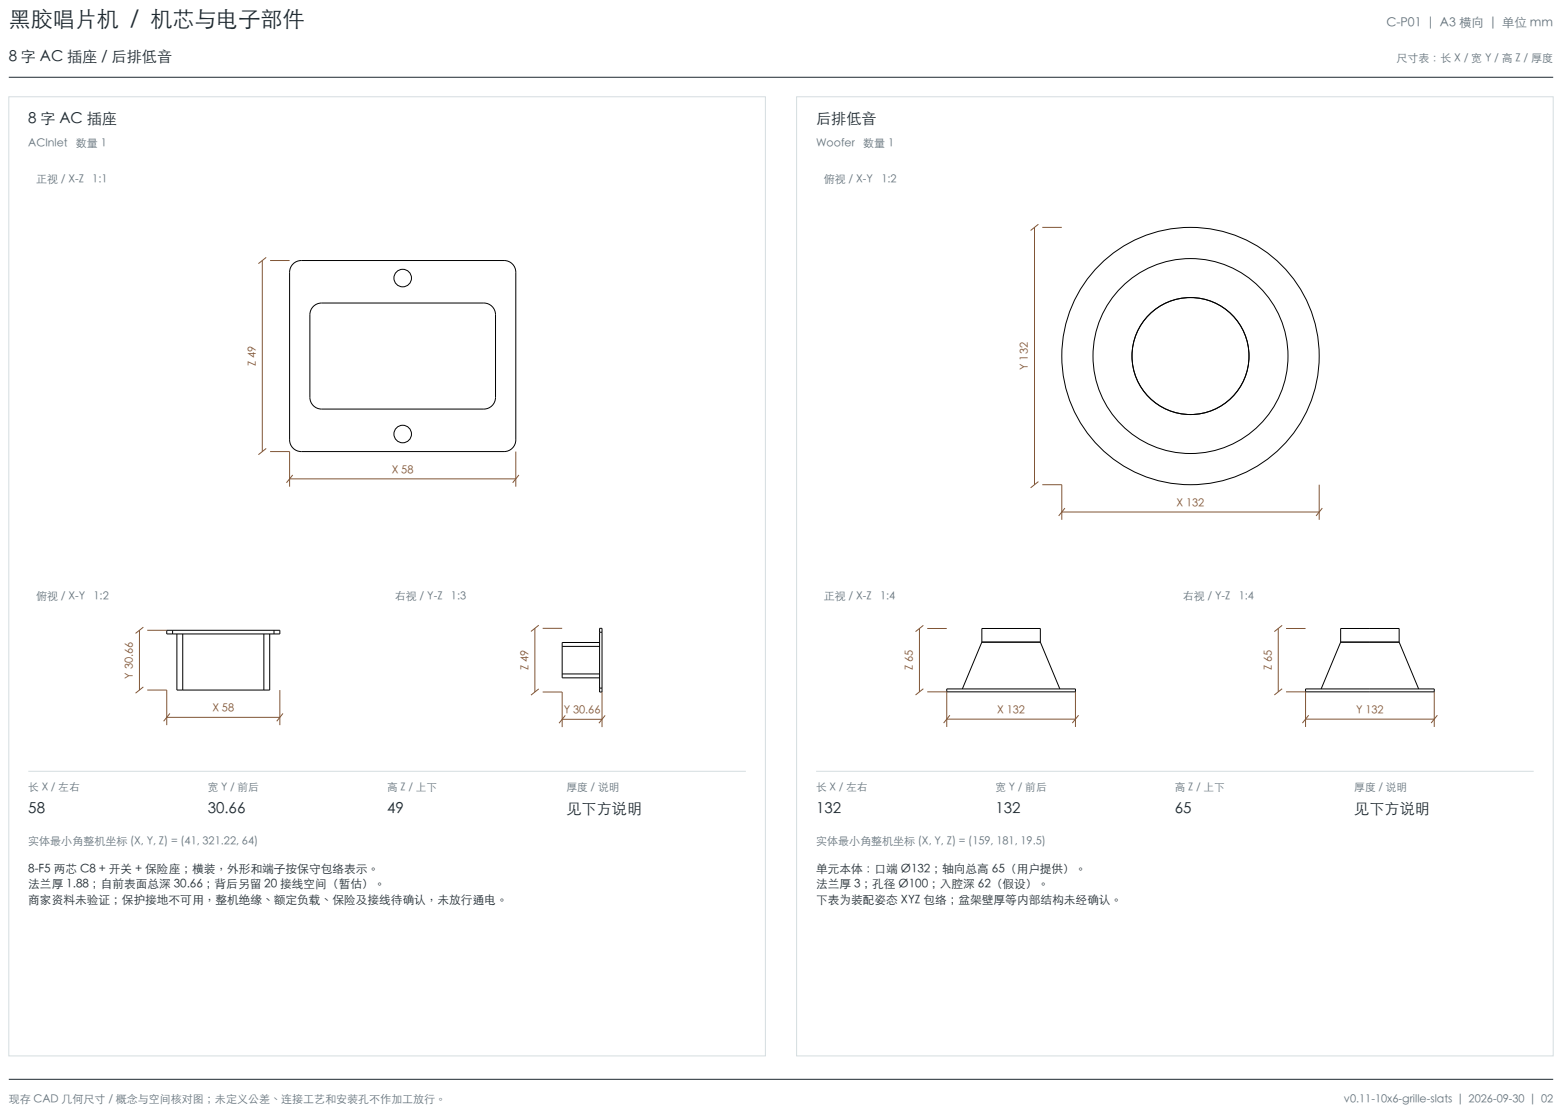
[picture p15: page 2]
黑胶唱片机 / 机芯与电子部件; 8 字 AC 插座 / 后排低音; 尺寸表：长 X / 宽 Y / 高 Z / 厚度; 现存 CAD 几何尺寸 / 概念与空间核对图；未定义公差、连接工艺和安装孔不作加工放行。; v0.11-10x6-grille-slats | 2026-09-30 | 02; ACInlet 数量 1; 厚度 / 说明 见下方说明; 实体最小角整机坐标 (X, Y, Z) = (41, 321.22, 64); Woofer 数量 1; 实体最小角整机坐标 (X, Y, Z) = (159, 181, 19.5)

8-F5 两芯 C8 + 开关 + 保险座；横装，外形和端子按保守包络表示。
法兰厚 1.88；自前表面总深 30.66；背后另留 20 接线空间（暂估）。
商家资料未验证；保护接地不可用，整机绝缘、额定负载、保险及接线待确认，未放行通电。

单元本体：口端 Ø132；轴向总高 65（用户提供）。
法兰厚 3；孔径 Ø100；入腔深 62（假设）。
下表为装配姿态 XYZ 包络；盆架壁厚等内部结构未经确认。

黑胶唱片机 / 机芯与电子部件 | C-P02 | A3 横向 | 单位 mm
左全频 / 功放板 | 尺寸表：长 X / 宽 Y / 高 Z / 厚度

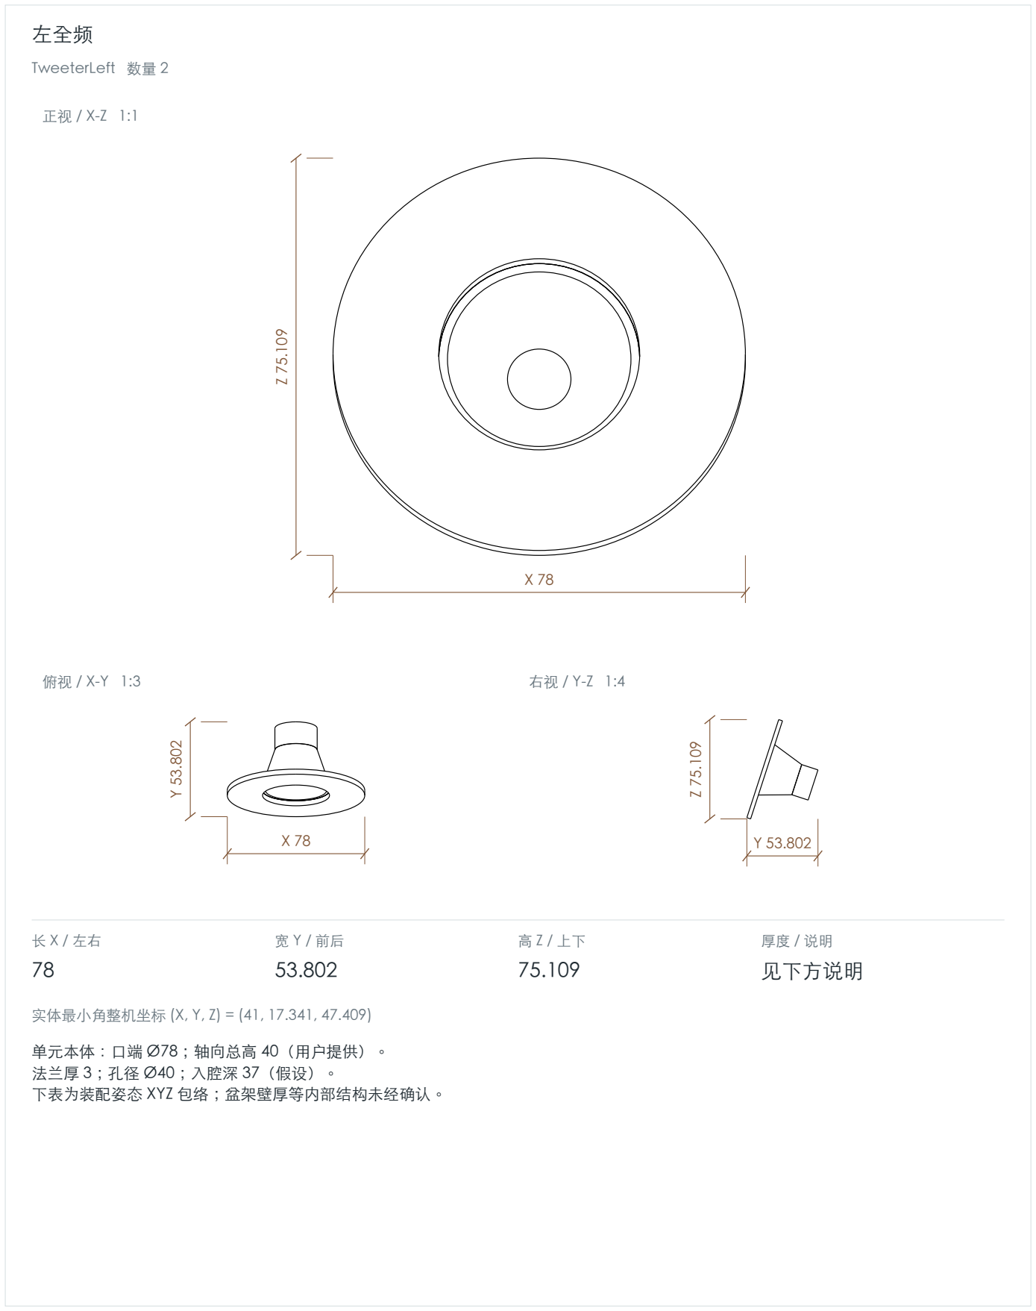
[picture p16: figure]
左全频; TweeterLeft 数量 2; 厚度 / 说明 见下方说明; 单元本体：口端 Ø78；轴向总高 40（用户提供）。 法兰厚 3；孔径 Ø40；入腔深 37（假设）。 下表为装配姿态 XYZ 包络；盆架壁厚等内部结构未经确认。
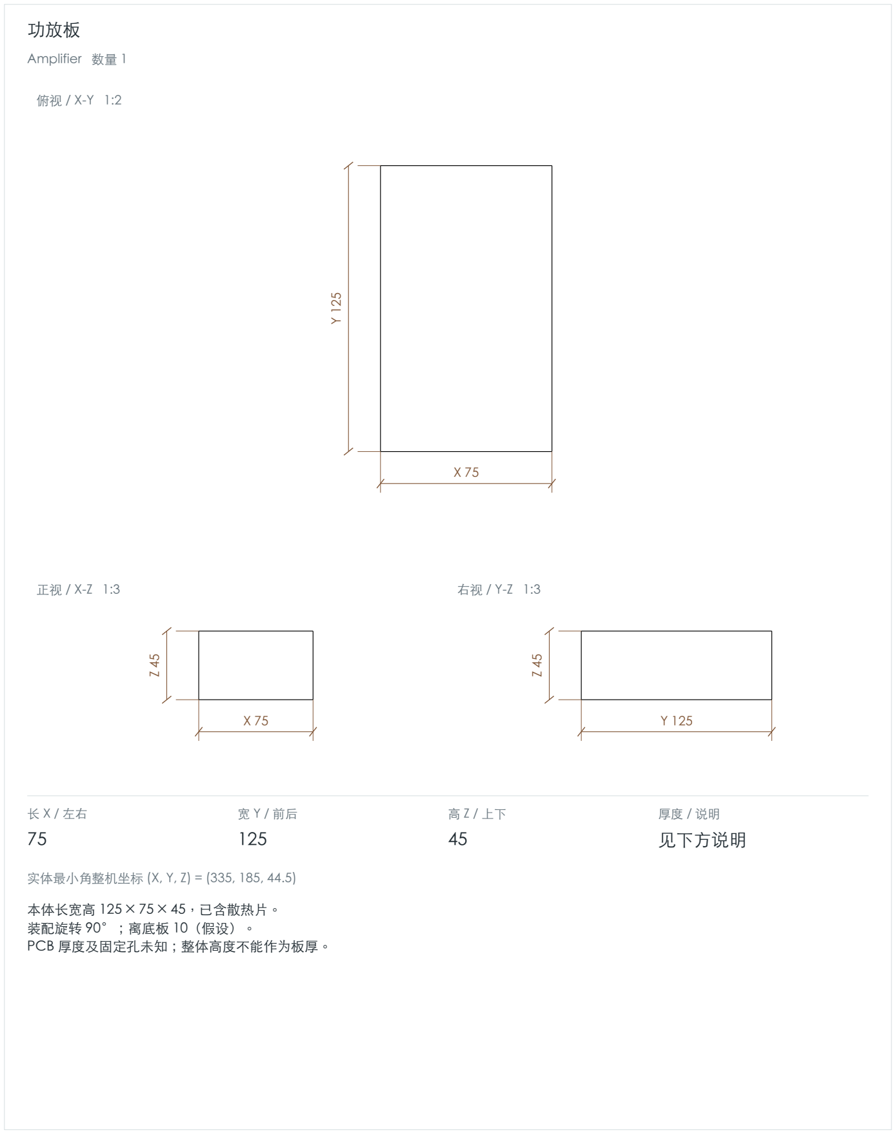
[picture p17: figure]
功放板; Amplifier 数量 1; 厚度 / 说明 见下方说明; 实体最小角整机坐标 (X, Y, Z) = (335, 185, 44.5); 本体长宽高 125 × 75 × 45，已含散热片。 装配旋转 90°；离底板 10（假设）。 PCB 厚度及固定孔未知；整体高度不能作为板厚。

现存 CAD 几何尺寸 / 概念与空间核对图；未定义公差、连接工艺和安装孔不作加工放行。 | v0.11-10x6-grille-slats | 2026-09-30 | 03

实体最小角整机坐标 (X, Y, Z) = (41, 17.341, 47.409)

黑胶唱片机 / 机芯与电子部件 | C-P03 | A3 横向 | 单位 mm
备用电子预留区（不代表另需唱放） / 扬声器电源变压器 | 尺寸表：长 X / 宽 Y / 高 Z / 厚度

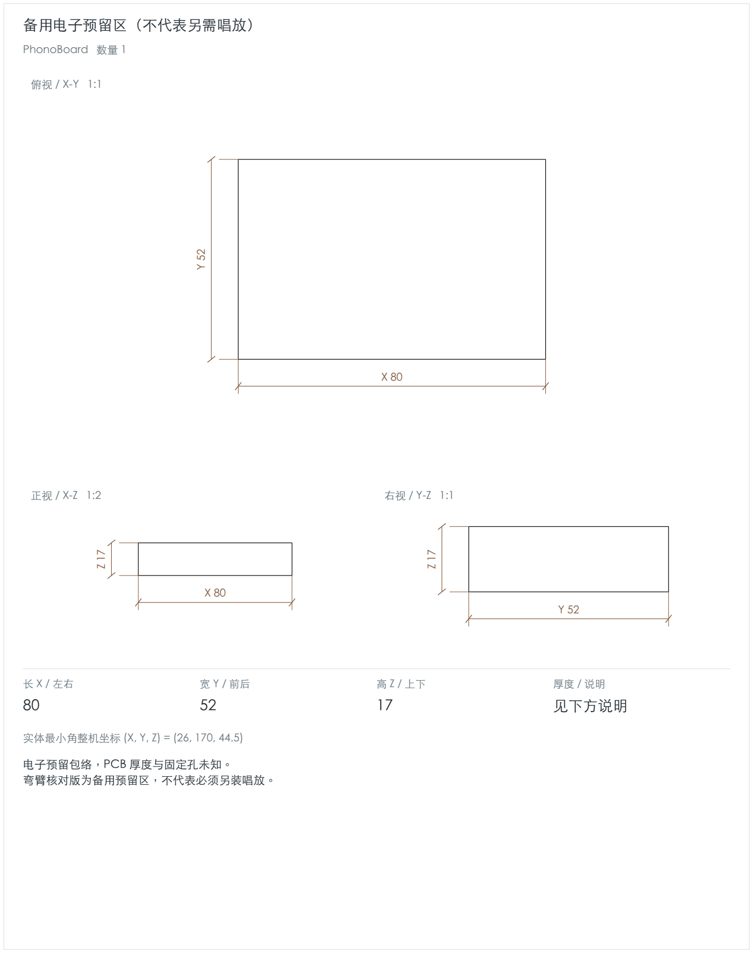
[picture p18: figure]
备用电子预留区（不代表另需唱放）; PhonoBoard 数量 1; 厚度 / 说明 见下方说明; 实体最小角整机坐标 (X, Y, Z) = (26, 170, 44.5); 电子预留包络，PCB 厚度与固定孔未知。 弯臂核对版为备用预留区，不代表必须另装唱放。
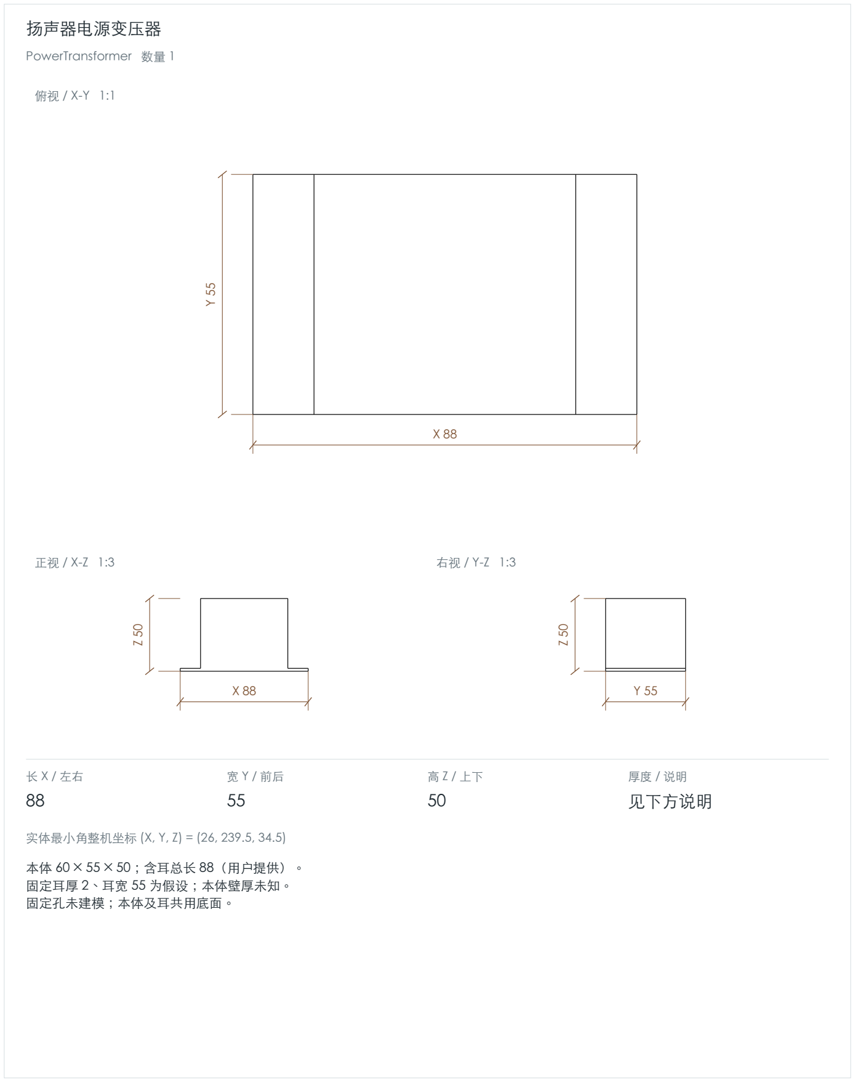
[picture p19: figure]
扬声器电源变压器; PowerTransformer 数量 1; 厚度 / 说明 见下方说明; 实体最小角整机坐标 (X, Y, Z) = (26, 239.5, 34.5); 本体 60 × 55 × 50；含耳总长 88（用户提供）。 固定耳厚 2、耳宽 55 为假设；本体壁厚未知。 固定孔未建模；本体及耳共用底面。

现存 CAD 几何尺寸 / 概念与空间核对图；未定义公差、连接工艺和安装孔不作加工放行。 | v0.11-10x6-grille-slats | 2026-09-30 | 04

黑胶唱片机 / 机芯与电子部件 | C-P04 | A3 横向 | 单位 mm
套装 RCA 后板预留区（孔位待确认） / 左前旋钮底座 | 尺寸表：长 X / 宽 Y / 高 Z / 厚度

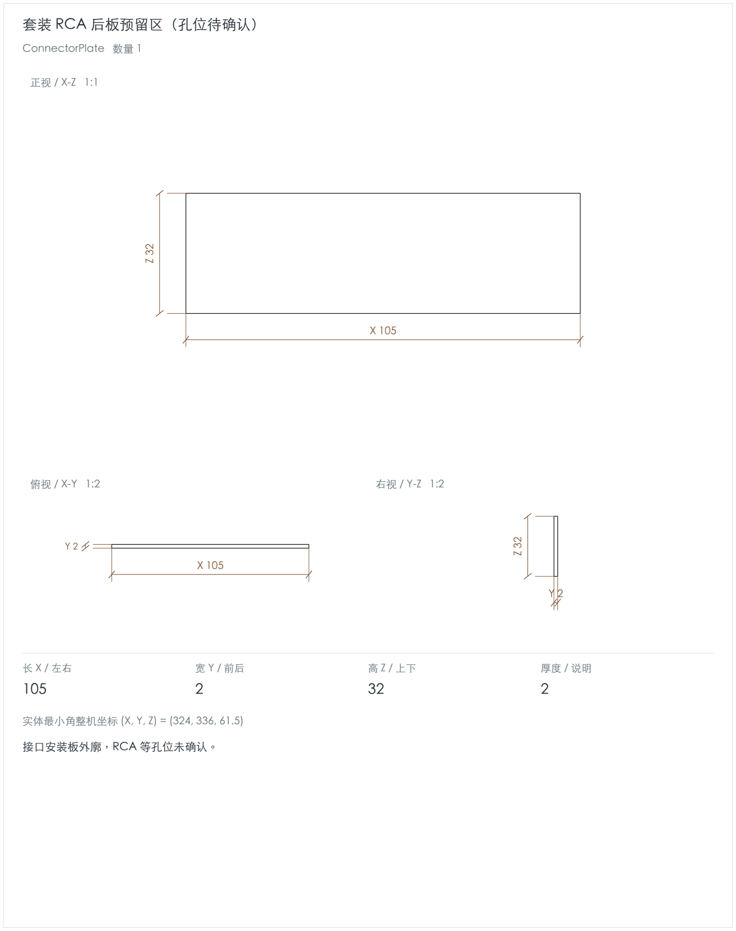
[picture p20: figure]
套装 RCA 后板预留区（孔位待确认）; ConnectorPlate 数量 1; 实体最小角整机坐标 (X, Y, Z) = (324, 336, 61.5); 接口安装板外廓，RCA 等孔位未确认。
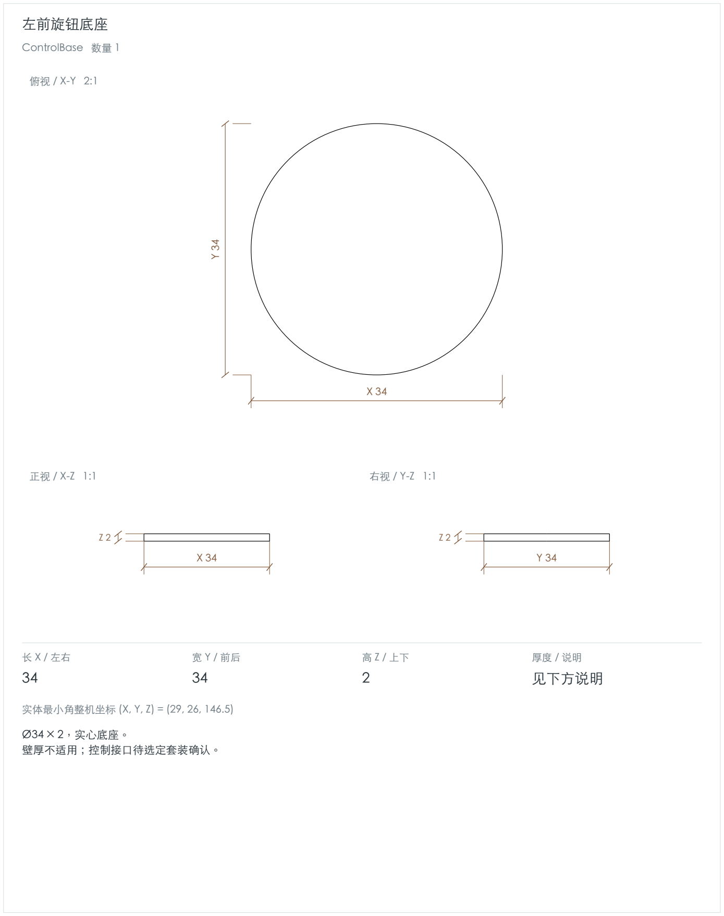
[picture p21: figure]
左前旋钮底座; ControlBase 数量 1; 厚度 / 说明 见下方说明; 实体最小角整机坐标 (X, Y, Z) = (29, 26, 146.5); Ø34 × 2，实心底座。 壁厚不适用；控制接口待选定套装确认。

现存 CAD 几何尺寸 / 概念与空间核对图；未定义公差、连接工艺和安装孔不作加工放行。 | v0.11-10x6-grille-slats | 2026-09-30 | 05

黑胶唱片机 / 机芯与电子部件 | C-P05 | A3 横向 | 单位 mm
多功能旋钮 / 机芯基座与三弹簧 | 尺寸表：长 X / 宽 Y / 高 Z / 厚度

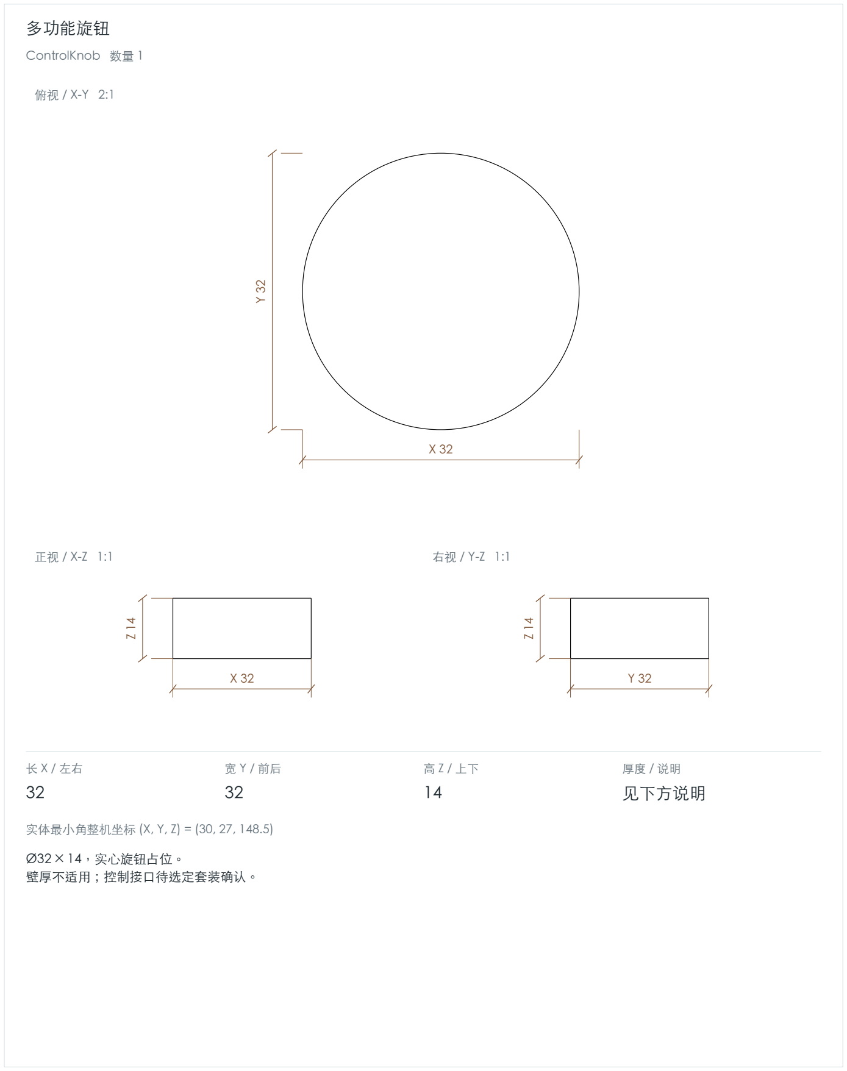
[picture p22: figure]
多功能旋钮; ControlKnob 数量 1; 厚度 / 说明 见下方说明; 实体最小角整机坐标 (X, Y, Z) = (30, 27, 148.5); Ø32 × 14，实心旋钮占位。 壁厚不适用；控制接口待选定套装确认。
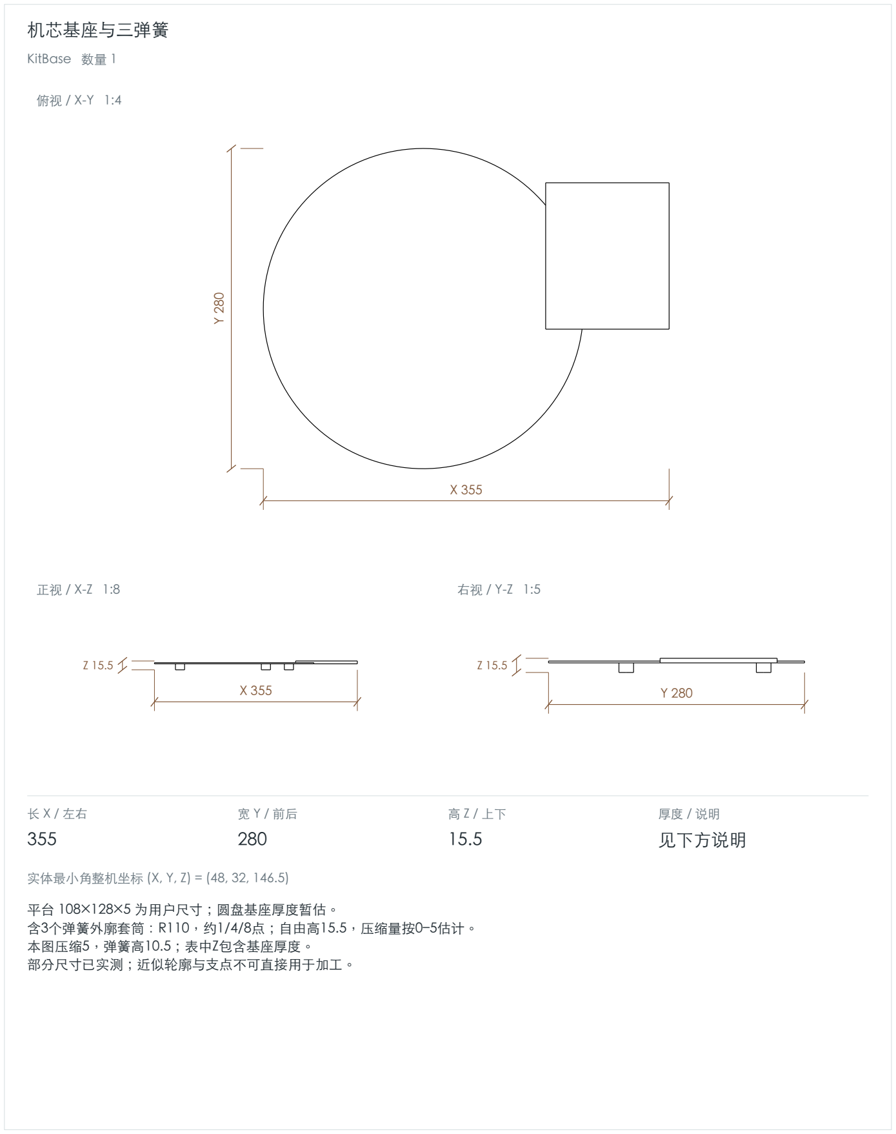
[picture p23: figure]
机芯基座与三弹簧; KitBase 数量 1; 厚度 / 说明 见下方说明; 实体最小角整机坐标 (X, Y, Z) = (48, 32, 146.5); 平台 108×128×5 为用户尺寸；圆盘基座厚度暂估。; 本图压缩5，弹簧高10.5；表中Z包含基座厚度。 部分尺寸已实测；近似轮廓与支点不可直接用于加工。

现存 CAD 几何尺寸 / 概念与空间核对图；未定义公差、连接工艺和安装孔不作加工放行。 | v0.11-10x6-grille-slats | 2026-09-30 | 06

含3个弹簧外廓套筒：R110，约1/4/8点；自由高15.5，压缩量按0–5估计。

黑胶唱片机 / 机芯与电子部件 | C-P06 | A3 横向 | 单位 mm
实测唱盘 Ø280 × 11 mm / 唱盘表面环纹示意 | 尺寸表：长 X / 宽 Y / 高 Z / 厚度

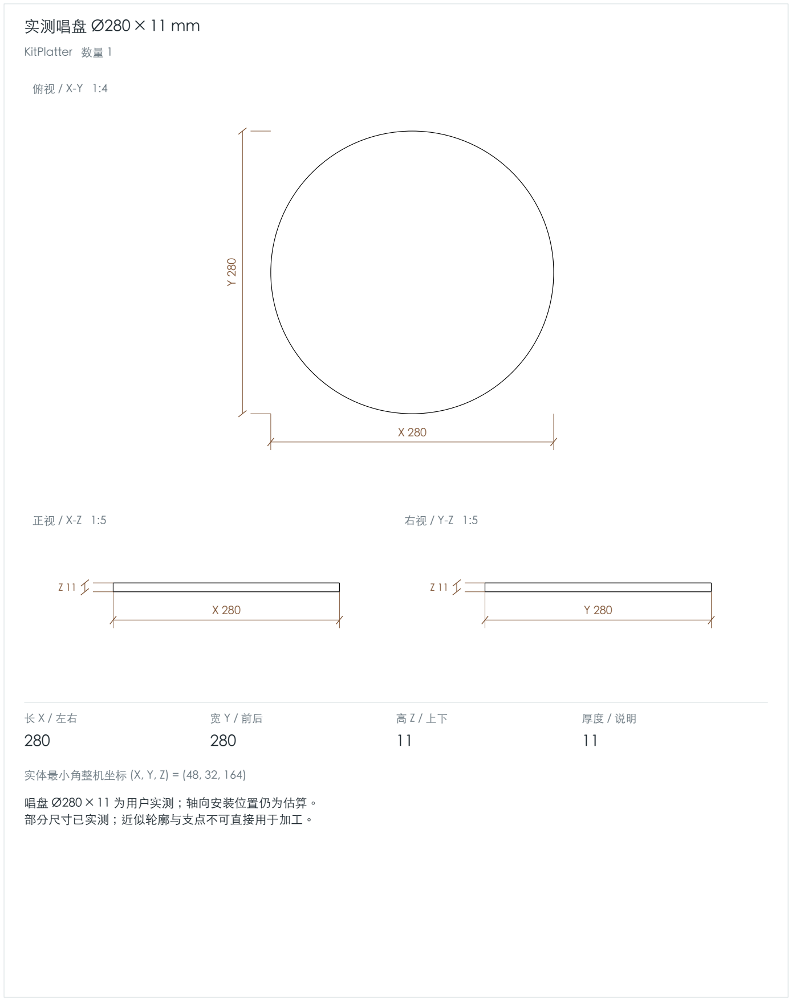
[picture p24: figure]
实测唱盘 Ø280 × 11 mm; KitPlatter 数量 1; 实体最小角整机坐标 (X, Y, Z) = (48, 32, 164); 唱盘 Ø280 × 11 为用户实测；轴向安装位置仍为估算。 部分尺寸已实测；近似轮廓与支点不可直接用于加工。
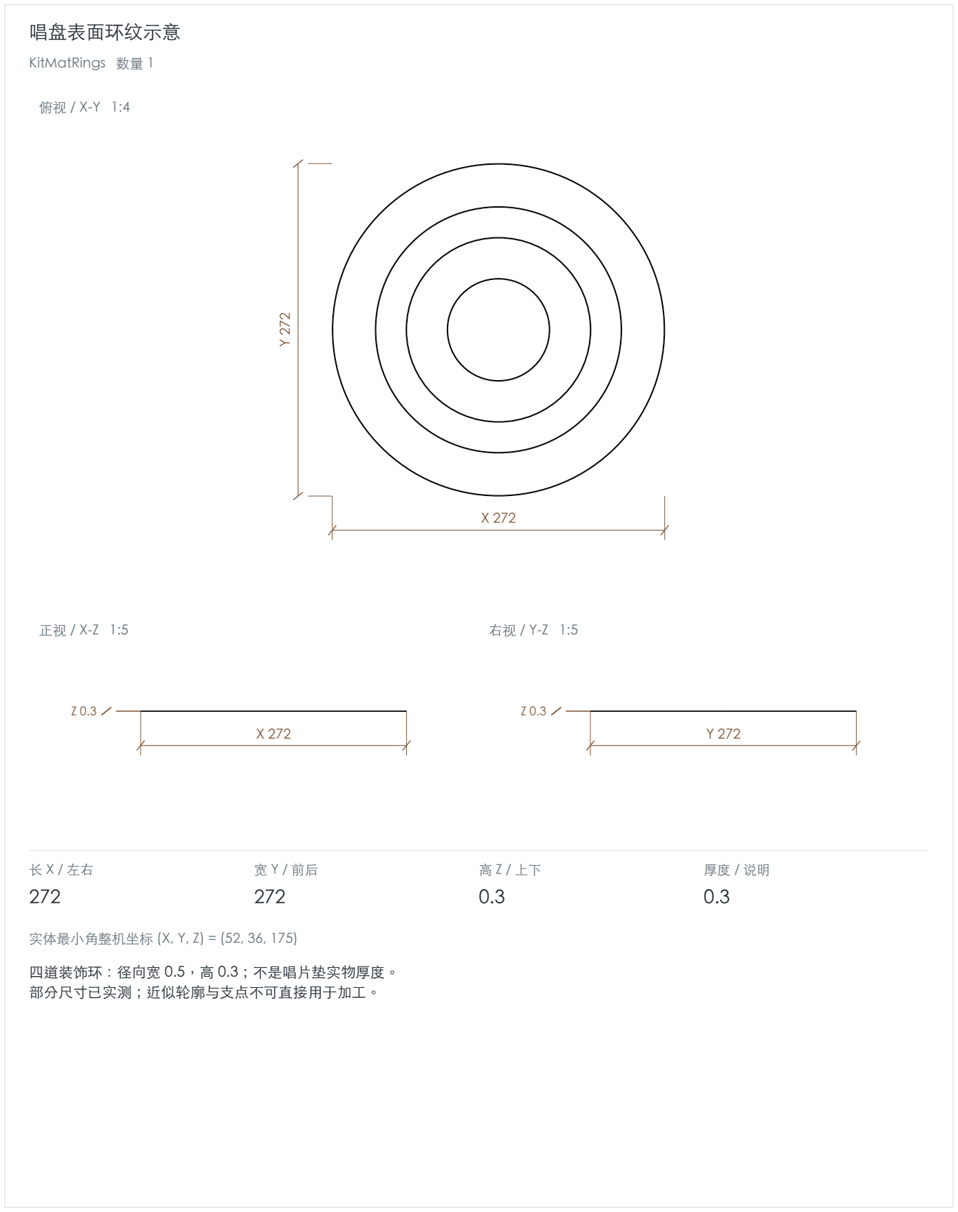
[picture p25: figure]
唱盘表面环纹示意; KitMatRings 数量 1; 实体最小角整机坐标 (X, Y, Z) = (52, 36, 175); 四道装饰环：径向宽 0.5，高 0.3；不是唱片垫实物厚度。 部分尺寸已实测；近似轮廓与支点不可直接用于加工。

现存 CAD 几何尺寸 / 概念与空间核对图；未定义公差、连接工艺和安装孔不作加工放行。 | v0.11-10x6-grille-slats | 2026-09-30 | 07

黑胶唱片机 / 机芯与电子部件 | C-P07 | A3 横向 | 单位 mm
机芯主轴示意 / 唱臂支座 | 尺寸表：长 X / 宽 Y / 高 Z / 厚度

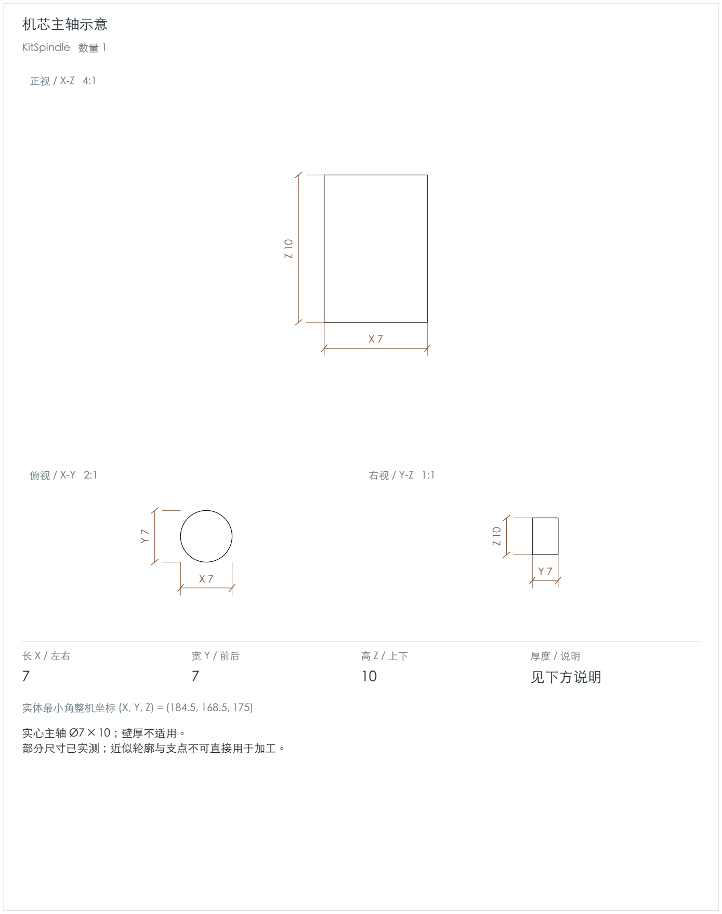
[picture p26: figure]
机芯主轴示意; KitSpindle 数量 1; 厚度 / 说明 见下方说明; 实心主轴 Ø7 × 10；壁厚不适用。 部分尺寸已实测；近似轮廓与支点不可直接用于加工。
唱臂支座; KitArmSupport 数量 1; 厚度 / 说明 见下方说明; 支座高 40 为用户尺寸；外形、壁厚和连接未知。 部分尺寸已实测；近似轮廓与支点不可直接用于加工。

现存 CAD 几何尺寸 / 概念与空间核对图；未定义公差、连接工艺和安装孔不作加工放行。 | v0.11-10x6-grille-slats | 2026-09-30 | 08

实体最小角整机坐标 (X, Y, Z) = (184.5, 168.5, 175)

实体最小角整机坐标 (X, Y, Z) = (345.5, 251.5, 162)

弯臂停放示意 / 后部配重外观示意 | 尺寸表：长 X / 宽 Y / 高 Z / 厚度

## 弯臂停放示意

黑胶唱片机 / 机芯与电子部件; 现存 CAD 几何尺寸 / 概念与空间核对图；未定义公差、连接工艺和安装孔不作加工放行。; v0.11-10x6-grille-slats | 2026-09-30 | 09; KitCurvedArm 数量 1; 厚度 / 说明 见下方说明; 实体最小角整机坐标 (X, Y, Z) = (354.8, 116.553, 179.821); 后部配重外观示意; KitCounterweight 数量 1; 实体最小角整机坐标 (X, Y, Z) = (348, 285, 182); 实心配重包络 Ø20 × 16；壁厚不适用。 部分尺寸已实测；近似轮廓与支点不可直接用于加工。

外径 Ø6.4；模型为实心扫掠占位，真实管壁厚未知。
用户总长250暂作含配重/唱头纵向外廓，非有效臂长或管材下料长度。
双弯位置与半径按参考图外观近似，不是折弯加工数据。
部分尺寸已实测；近似轮廓与支点不可直接用于加工。

参考图弯臂连接套、开槽唱头壳与指托 / 随套装唱头占位（型号待核实） | 尺寸表：长 X / 宽 Y / 高 Z / 厚度

## 参考图弯臂连接套、开槽唱头壳与指托

黑胶唱片机 / 机芯与电子部件; 现存 CAD 几何尺寸 / 概念与空间核对图；未定义公差、连接工艺和安装孔不作加工放行。; v0.11-10x6-grille-slats | 2026-09-30 | 10; KitHeadshell 数量 1; 实体最小角整机坐标 (X, Y, Z) = (362.811, 51, 176.516); 随套装唱头占位（型号待核实）; KitCartridge 数量 1; 厚度 / 说明 见下方说明; 实体最小角整机坐标 (X, Y, Z) = (367.179, 55.133, 171.516); 唱头包络 12 × 19 × 5；实物规格与壁厚未知。 部分尺寸已实测；近似轮廓与支点不可直接用于加工。

含连接套、双槽唱头壳、三枚顶面圆垫与侧向指托；尺寸按参考图外观近似。
槽孔仅用于识别外观，不是安装孔位。
部分尺寸已实测；近似轮廓与支点不可直接用于加工。

黑胶唱片机 / 机芯与电子部件 | C-P10 | A3 横向 | 单位 mm
停臂架与限位片示意 | 尺寸表：长 X / 宽 Y / 高 Z / 厚度

停臂架与限位片示意; KitArmRest 数量 1; 厚度 / 说明 见下方说明; 实体最小角整机坐标 (X, Y, Z) = (354.5, 193, 162); 实心支架包络 Ø8 × 27；壁厚不适用。 部分尺寸已实测；近似轮廓与支点不可直接用于加工。

现存 CAD 几何尺寸 / 概念与空间核对图；未定义公差、连接工艺和安装孔不作加工放行。 | v0.11-10x6-grille-slats | 2026-09-30 | 11

黑胶唱片机 / 机芯与电子部件 | C-POS | A3 横向 | 单位 mm
同形零件安装位置表 | 同形代表件的各安装位置 / 单位 mm
现存 CAD 几何尺寸 / 概念与空间核对图；未定义公差、连接工艺和安装孔不作加工放行。 | v0.11-10x6-grille-slats | 2026-09-30 | 12

### 坐标为每个对象精确外包络的最小角；圆柱的坐标是包络角，不是轴心。

对象 ID | 零件 | X 最小 | Y 最小 | Z 最小 | 数量 / 备注
TweeterLeft | 左全频 | 41 | 17.341 | 47.409 | 同形件 / 详见代表件图
TweeterRight | 左全频 | 331 | 17.341 | 47.409 | 同形件 / 详见代表件图

黑胶唱片机 / 机芯与电子部件; 附录 / 基线通用机芯正投影; 可见轮廓正投影 / 视图各自标注比例; 现存 CAD 几何尺寸 / 概念与空间核对图；未定义公差、连接工艺和安装孔不作加工放行。; v0.11-10x6-grille-slats | 2026-09-30 | 13

此页为原三单元基线的通用机芯占位。当前弯臂装配已替换这些机芯部件，两组不是同时安装。
基线唱盘 Ø300，唱臂轴距 200，有效臂长 218；不用于约束候选弯臂机芯。
下页按对象列出全部基线机芯 XYZ 包络；这些外观占位未定义真实壁厚和制造接口。

黑胶唱片机 / 机芯与电子部件 | C-G02 | A3 横向 | 单位 mm
附录 / 基线通用机芯尺寸记录 | 装配姿态包络 / 厚度未知或实心占位
现存 CAD 几何尺寸 / 概念与空间核对图；未定义公差、连接工艺和安装孔不作加工放行。 | v0.11-10x6-grille-slats | 2026-09-30 | 14
ID | 零件 | 长 X | 宽 Y | 高 Z | 厚度状态
MotorEnvelope | 马达空间占位 | 36 | 36 | 34 | 未定义 / 实心外观占位
BearingEnvelope | 主轴轴承空间占位 | 20 | 20 | 36 | 未定义 / 实心外观占位
PlatterHub | 唱盘支承轮毂 | 64 | 64 | 3 | 未定义 / 实心外观占位
Platter | Ø300 唱盘 | 300 | 300 | 12 | 未定义 / 实心外观占位
PlatterMat | 唱片垫 | 298 | 298 | 2 | 未定义 / 实心外观占位
MatRing | 唱片垫细环 | 286 | 286 | 0.12 | 未定义 / 实心外观占位
Spindle | 主轴 | 7 | 7 | 11 | 未定义 / 实心外观占位
ArmBase | 唱臂底座 | 46 | 46 | 7 | 未定义 / 实心外观占位
ArmColumn | 唱臂支柱 | 20 | 20 | 31 | 未定义 / 实心外观占位
TonearmTube | 唱臂管外观包络 | 80.281 | 187.691 | 15.194 | 未定义 / 实心外观占位
CounterweightRod | 平衡锤轴 | 18.43 | 36.303 | 7 | 未定义 / 实心外观占位
Counterweight | 平衡锤包络 | 28.907 | 25.826 | 24 | 未定义 / 实心外观占位
Headshell | 唱头壳外观包络 | 16.636 | 29.22 | 3 | 未定义 / 实心外观占位
Cartridge | 唱头占位（非安装图） | 13.488 | 17.083 | 7 | 未定义 / 实心外观占位
Stylus | 针尖几何基准 | 0.9 | 0.9 | 2.7 | 未定义 / 实心外观占位
ArmRest | 唱臂支架占位 | 8 | 8 | 26 | 未定义 / 实心外观占位

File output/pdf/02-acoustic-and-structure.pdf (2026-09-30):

三音腔与后部电子区 / 去盖内部布置 | 可见轮廓正投影 / 视图各自标注比例

黑胶唱片机 / 音腔与内部结构; 现存 CAD 几何尺寸 / 概念与空间核对图；未定义公差、连接工艺和安装孔不作加工放行。; v0.11-10x6-grille-slats | 2026-09-30 | 01

为读图隐藏两侧木板、后板、音腔顶板、前障板及两块全频腔后板；零件结构详见后页。
三音腔：左右前部密闭试验腔，中央贯通低音腔。隔板 X=129 / 311，厚 10；全频腔后板 Y=150，厚 10。
顶板 Z=124.5..134.5；底板上表面 Z=34.5；后部电源和功放区与前部全频腔分隔。

黑胶唱片机 / 音腔与内部结构 | B-P01 | A3 横向 | 单位 mm
左右全频斜面障板 / 三音腔共用顶板 | 尺寸表：长 X / 宽 Y / 高 Z / 厚度

左右全频斜面障板; Baffle 数量 1; 开孔定位 B-H01 / A-03; 实体最小角整机坐标 (X, Y, Z) = (12, 16, 34.5); 矩形备料 L × W × T：426 × 98 × 10 mm; 后倾 18°；法向板厚 10；Y 向厚度 10.515。 上下两边修 18° 斜口至安装竖高 90；前表面斜长 94.632。 2 × Ø40 法向孔；中心 X=80 / 370，Z=84.5（整机坐标）。 正视孔为椭圆；固定螺孔未知。
三音腔共用顶板; AcousticRoof 数量 1; 开孔定位 B-H02; 实体最小角整机坐标 (X, Y, Z) = (12, 5.2, 124.5); 矩形备料 L × W × T：426 × 333 × 10 mm; 成形前缘 Y=5.2；前横板至 Y=160；中央后伸宽 192。 后伸部左缘 X=129；后缘 Y=338。 轴承孔 Ø28；中心 X=188, Y=172（整机坐标）。 顶面前缘台阶：宽 25、深 5.7；余厚 4.3。 轴承孔局部 Y=166.8，从新成形前缘量取；见 B-H02 / A-03。 3×Ø16 顶面沉台深 3（安装假设）。

现存 CAD 几何尺寸 / 概念与空间核对图；未定义公差、连接工艺和安装孔不作加工放行。 | v0.11-10x6-grille-slats | 2026-09-30 | 02

黑胶唱片机 / 音腔与内部结构 | B-P02 | A3 横向 | 单位 mm
左右全频腔后板 / 左右全频腔后板 | 尺寸表：长 X / 宽 Y / 高 Z / 厚度

左右全频腔后板; AcousticRear:1 数量 1; 实体最小角整机坐标 (X, Y, Z) = (12, 150, 34.5); 矩形备料 L × W × T：117 × 90 × 10 mm; 此对象包含左右两块独立后板，分别绘制。 两块均由原实体直接读取，不以跨空区总包络下料。 当前实体无开孔；连接孔须待装配工艺确认。
左右全频腔后板; AcousticRear:2 数量 1; 实体最小角整机坐标 (X, Y, Z) = (321, 150, 34.5); 矩形备料 L × W × T：117 × 90 × 10 mm; 此对象包含左右两块独立后板，分别绘制。 两块均由原实体直接读取，不以跨空区总包络下料。 当前实体无开孔；连接孔须待装配工艺确认。

现存 CAD 几何尺寸 / 概念与空间核对图；未定义公差、连接工艺和安装孔不作加工放行。 | v0.11-10x6-grille-slats | 2026-09-30 | 03

黑胶唱片机 / 音腔与内部结构 | B-P03 | A3 横向 | 单位 mm
低音腔左全深隔板 / 通用轴承密封避让杯（当前机芯待重做） | 尺寸表：长 X / 宽 Y / 高 Z / 厚度

低音腔左全深隔板; AcousticDividerLeft 数量 2; 矩形备料 L × W × T：312 × 90 × 10 mm; 前缘倾斜 18°；后缘 Y=338。 下前角 Y=26.515；上前角 Y=55.757。 两块同形；板厚方向 X。整数备料后按斜前缘精确修切。 当前实体无开孔；连接孔须待装配工艺确认。
通用轴承密封避让杯（当前机芯待重做）; BearingPocket 数量 1; 实体最小角整机坐标 (X, Y, Z) = (174, 158, 106.5); 外径 Ø28；内径 Ø24；底厚 2；杯顶开口。 仅适配基线通用轴承；当前机芯安装时须重新核对。

现存 CAD 几何尺寸 / 概念与空间核对图；未定义公差、连接工艺和安装孔不作加工放行。 | v0.11-10x6-grille-slats | 2026-09-30 | 04

实体最小角整机坐标 (X, Y, Z) = (129, 26.515, 34.5)

黑胶唱片机 / 音腔与内部结构 | B-P04 | A3 横向 | 单位 mm
后置倒相管 / 现有承载板（机芯开口与孔位待调整） | 尺寸表：长 X / 宽 Y / 高 Z / 厚度

后置倒相管; BassPort 数量 1; 实体最小角整机坐标 (X, Y, Z) = (264, 190, 78.5); 通径 Ø32；管壁 2；总长 160（含法兰）。 法兰 Ø48 × 3；主体长 157。 长度是当前试验初值，非已验证声学调谐。
现有承载板（机芯开口与孔位待调整）; FloatingDeck 数量 1; 开孔定位 B-H03; 实体最小角整机坐标 (X, Y, Z) = (14, 6, 136.5); 矩形备料 L × W × T：422 × 330 × 10 mm; 主轴通孔 Ø20.4（暂定）；机芯固定孔与外轮廓开口未设计。 饰条后 1、左右各 2、后板前 2 名义间隙；浮动行程待验证。 3×Ø16 底面沉台深 3，与顶板沉台共同定位弹性支承（安装假设）。 孔中心局部坐标 (174, 166)；基准为该板左前下角。

现存 CAD 几何尺寸 / 概念与空间核对图；未定义公差、连接工艺和安装孔不作加工放行。 | v0.11-10x6-grille-slats | 2026-09-30 | 05

黑胶唱片机 / 音腔与内部结构 | B-P05 | A3 横向 | 单位 mm
后部两侧隔振承托梁 / 独立板件 1 / 后部两侧隔振承托梁 / 独立板件 2 | 尺寸表：长 X / 宽 Y / 高 Z / 厚度

后部两侧隔振承托梁 / 独立板件 1; RearSupport:1 数量 1; 实体最小角整机坐标 (X, Y, Z) = (20, 280, 124.5); 矩形备料 L × W × T：109 × 30 × 10 mm; 对象由左右两块承托梁组成，逐块标注。 当前实体无开孔；连接孔须待装配工艺确认。
后部两侧隔振承托梁 / 独立板件 2; RearSupport:2 数量 1; 实体最小角整机坐标 (X, Y, Z) = (321, 280, 124.5); 矩形备料 L × W × T：109 × 30 × 10 mm; 对象由左右两块承托梁组成，逐块标注。 当前实体无开孔；连接孔须待装配工艺确认。

现存 CAD 几何尺寸 / 概念与空间核对图；未定义公差、连接工艺和安装孔不作加工放行。 | v0.11-10x6-grille-slats | 2026-09-30 | 06

黑胶唱片机 / 音腔与内部结构 | B-P06 | A3 横向 | 单位 mm
弹性支承 1（刚度待定） | 尺寸表：长 X / 宽 Y / 高 Z / 厚度

弹性支承 1（刚度待定）; Isolator0 数量 3; 厚度 / 说明 见下方说明; 实体最小角整机坐标 (X, Y, Z) = (36, 92, 131.5)

现存 CAD 几何尺寸 / 概念与空间核对图；未定义公差、连接工艺和安装孔不作加工放行。 | v0.11-10x6-grille-slats | 2026-09-30 | 07

实心弹性支承 Ø16 × 8；上下分别嵌入顶板／台面 3/3；刚度未定，壁厚不适用。

黑胶唱片机 / 音腔与内部结构 | B-H01 | A3 横向 | 单位 mm
倾斜扬声器障板 / 前表面法向开孔 | 成形边为定位基准 / 孔轴心坐标 / 单位 mm


现存 CAD 几何尺寸 / 概念与空间核对图；未定义公差、连接工艺和安装孔不作加工放行。 | v0.11-10x6-grille-slats | 2026-09-30 | 08

### 前表面法向视图 1:2 / 板厚 10

## 孔表 / 从 O 量至孔轴心

编号 | X | S | 孔形 / 尺寸
H1 | 68 | 52.573 | Ø40 通
H2 | 358 | 52.573 | Ø40 通

通 = 贯通；深 = 从指定加工面量取。

主图垂直于障板前表面；O 为成形后前表面左下角，S 沿斜面向上量取，图中孔为真实圆。

孔中心投影竖高为 50，沿斜面 S=52.573；请按 S 划线。孔轴垂直板面，法向厚 10。

安装后倾 18°；上下斜口成形后前表面长 94.632。局部装配剖视见第 01 册 A-03；三视及备料见 B-P01。

扬声器固定螺孔、板件连接孔未知；本页只标已有声孔，不作为完整安装放行。

黑胶唱片机 / 音腔与内部结构 | B-H02 | A3 横向 | 单位 mm
音腔顶板 / 轴承孔与前缘台阶 | 成形边为定位基准 / 孔轴心坐标 / 单位 mm

通 = 贯通；深 = 从指定加工面量取。; 俯视；O 为新成形左前角（整机 Y=5.2），+Y 向后；轴承孔局部 Y=166.8。

现存 CAD 几何尺寸 / 概念与空间核对图；未定义公差、连接工艺和安装孔不作加工放行。 | v0.11-10x6-grille-slats | 2026-09-30 | 09

### 俯视 1:2 / 板厚 10

## 孔表 / 从 O 量至孔轴心

顶面前缘通长台阶：从 O 向后宽 25、深 5.7、余厚 4.3；截面见 A-03。

此孔与通用轴承密封避让杯配合，保留在当前模型中；当前弯臂机芯安装时须重新核对。 S1-S3 为顶面 Ø16、深 3 mm 弹性支承沉台，均为安装假设。

板件连接螺孔未定义；未标孔位不得按示意位置直接开孔。

黑胶唱片机 / 音腔与内部结构 | B-H03 | A3 横向 | 单位 mm
浮动底板 / 主轴孔 | 成形边为定位基准 / 孔轴心坐标 / 单位 mm

通 = 贯通；深 = 从指定加工面量取。; 俯视；O 为板件左前角，+X 向右，+Y 向后（图上方）；所有孔位均相对该板成形边。; H1 沿 Z 贯通；S1-S3 为非贯通沉台；孔表坐标均以孔轴心为准。

现存 CAD 几何尺寸 / 概念与空间核对图；未定义公差、连接工艺和安装孔不作加工放行。 | v0.11-10x6-grille-slats | 2026-09-30 | 10

### 俯视 1:2 / 板厚 10

## 孔表 / 从 O 量至孔轴心

主轴孔为通用机芯暂定值；当前机芯固定孔、轮廓开口及弹性支承固定方式尚未设计。 S1-S3 为底面 Ø16、深 3 mm 弹性支承沉台，均为安装假设。

板件连接螺孔未定义；未标孔位不得按示意位置直接开孔。

黑胶唱片机 / 音腔与内部结构 | B-POS | A3 横向 | 单位 mm
同形零件安装位置表 | 同形代表件的各安装位置 / 单位 mm
现存 CAD 几何尺寸 / 概念与空间核对图；未定义公差、连接工艺和安装孔不作加工放行。 | v0.11-10x6-grille-slats | 2026-09-30 | 11

### 坐标为每个对象精确外包络的最小角；圆柱的坐标是包络角，不是轴心。

对象 ID | 零件 | X 最小 | Y 最小 | Z 最小 | 数量 / 备注
AcousticDividerLeft | 低音腔左全深隔板 | 129 | 26.515 | 34.5 | 同形件 / 详见代表件图
AcousticDividerRight | 低音腔左全深隔板 | 311 | 26.515 | 34.5 | 同形件 / 详见代表件图
Isolator0 | 弹性支承 1（刚度待定） | 36 | 92 | 131.5 | 同形件 / 详见代表件图
Isolator1 | 弹性支承 1（刚度待定） | 398 | 92 | 131.5 | 同形件 / 详见代表件图
Isolator2 | 弹性支承 1（刚度待定） | 217 | 287 | 131.5 | 同形件 / 详见代表件图

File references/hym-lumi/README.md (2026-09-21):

# 原始参考图

以下文件来自 HYM 官方产品页面，仅用于外形、比例和尺寸研究。图片版权归原权利人，仓库 LICENSE 不授予这些参考图片的版权许可。

| 本地文件 | 内容 | 来源 |
|---|---|---|
| `front.jpg` | 开盖前侧主视照片 | [官方主图 01](https://www.hym-originals-en.com/cdn/shop/files/shop_LUMI_Internal_Main_Images_01.jpg?v=1783084143&width=1600) |
| `closed.jpg` | 俯视、盖子部分打开；文件名不代表闭盖状态 | [官方主图 03](https://www.hym-originals-en.com/cdn/shop/files/shop_LUMI_Internal_Main_Images_03.jpg?v=1783084143&width=1600) |
| `angle.jpg` | 前格栅 18° 后倾及灯光说明 | [官方角度说明图](https://www.hym-originals-en.com/cdn/shop/files/LUMI_Description_Images_04_17037a27-c1b6-4215-bd1f-18d20d04dd13.jpg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) |
| `specifications.jpg` | 448.6 × 345.5 × 214.2 mm 官方标注图 | [官方尺寸图](https://cdn.shopify.com/s/files/1/0621/9572/8638/files/3_24_329fb263-a3b5-4d16-9e60-e873b0c0db51.jpg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) |

下载与查阅日期：2026-09-21。CAD 预览位于 `previews/`，由实际模型渲染生成，与这些官方参考图片分开存放。

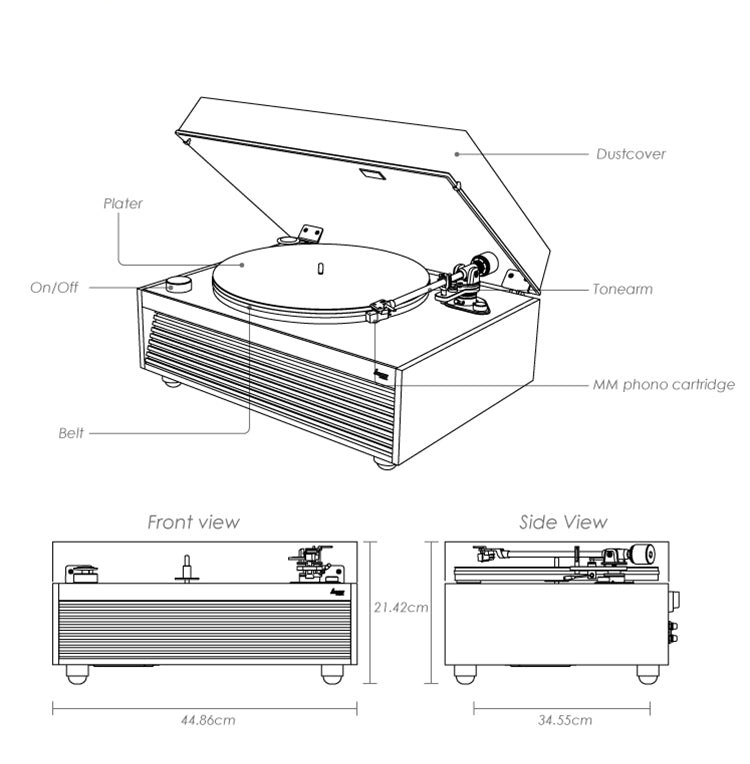
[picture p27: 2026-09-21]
references/hym-lumi/specifications.jpg

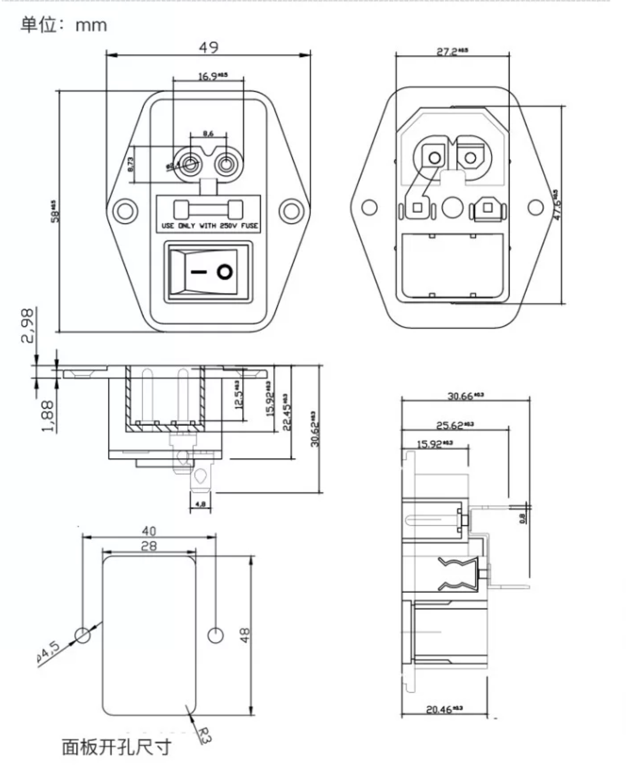
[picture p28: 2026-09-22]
references/ac-inlet/vendor-dimensions.png

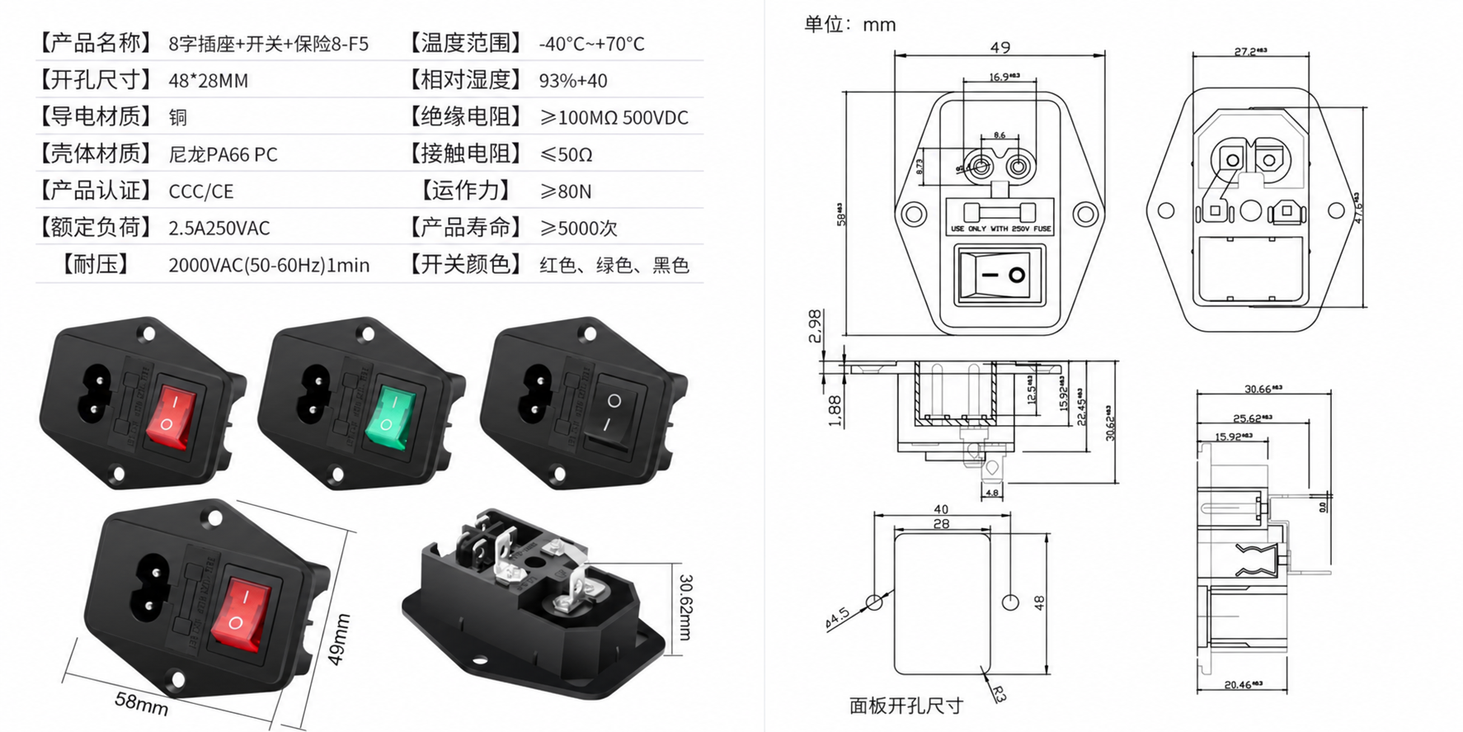
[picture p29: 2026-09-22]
references/ac-inlet/8-f5-combined.png

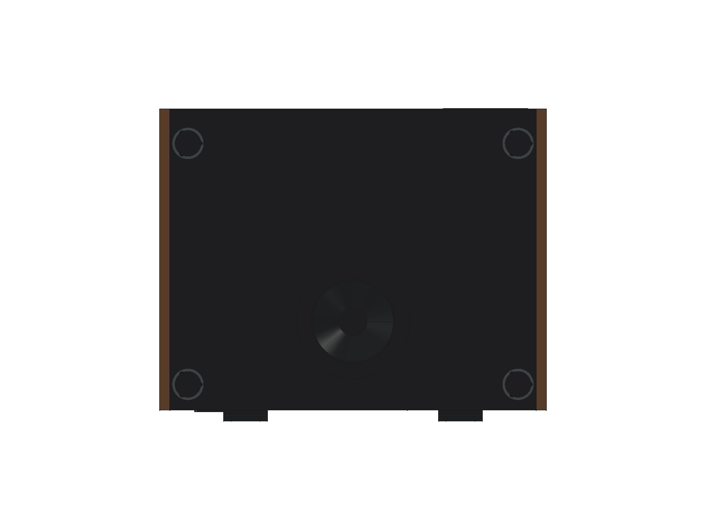
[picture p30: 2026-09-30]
previews/bottom.png

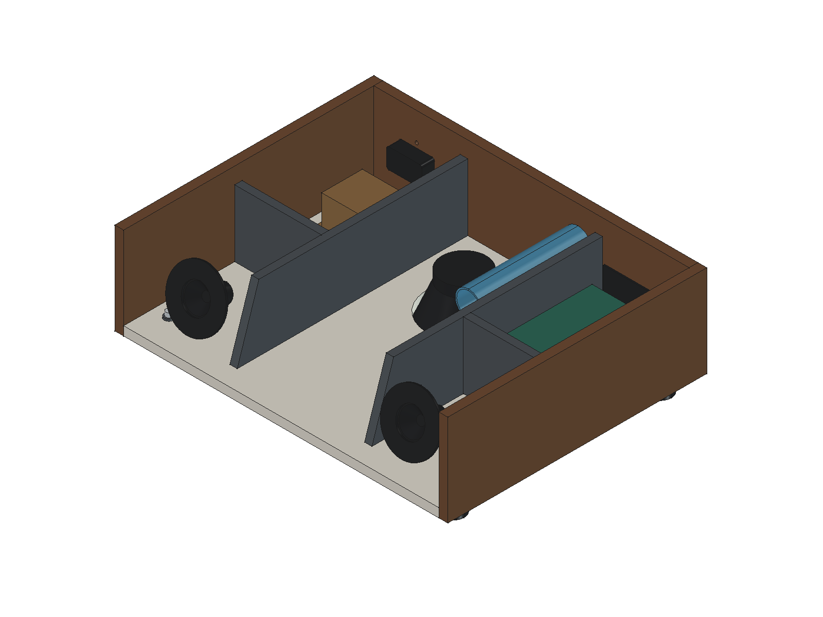
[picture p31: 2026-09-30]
previews/internal.png

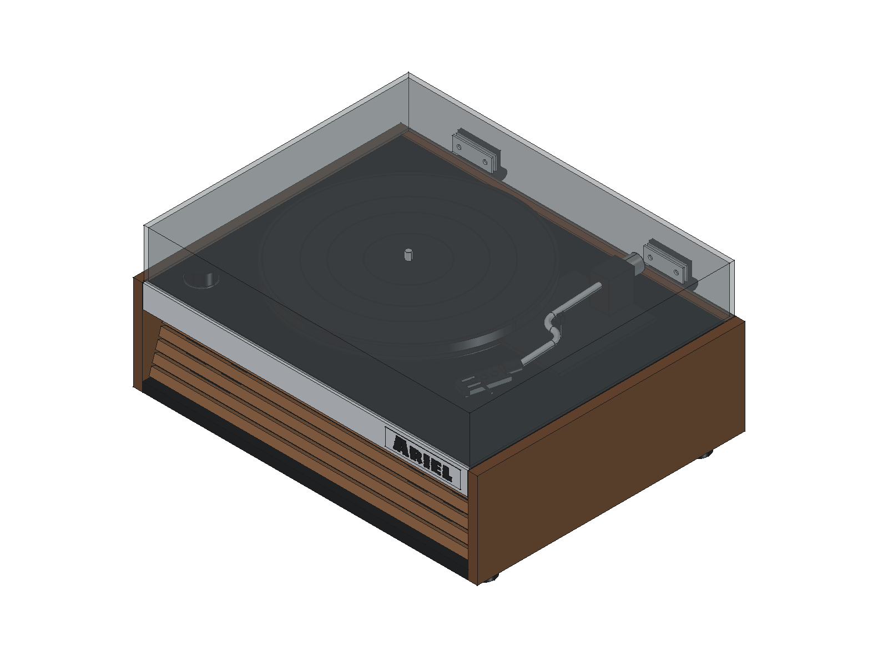
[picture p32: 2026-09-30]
previews/closed.png

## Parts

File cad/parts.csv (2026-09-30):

ID | 零件 | 分组 | 材料说明 | 尺寸依据 | 包络X_mm | 包络Y_mm | 包络Z_mm
SideLeft | 左侧木板 | Cabinet | 12 mm 木板 / 胡桃木表面 | 估算 / 待选型 | 12.0 | 350.0 | 124.0
SideRight | 右侧木板 | Cabinet | 12 mm 木板 / 胡桃木表面 | 估算 / 待选型 | 12.0 | 350.0 | 124.0
Bottom | 底板 · 低音向下开孔 | Cabinet | 12 mm 木板；低音开孔待选型 | 估算 / 待选型 | 426.0 | 350.0 | 12.0
Back | 后板 · 倒相管、AC 与铰链盲预孔 | Cabinet | 概念件 | 估算 / 待选型 | 426.0 | 12.0 | 112.0
ACInlet | 8 字 AC 插座 · 开关保险一体式安装包络 | Electronics | 采购件占位；接线、绝缘、螺钉及适用板厚待实物确认，未放行通电 | 用户提供 8-F5 商家图；横装开孔 48×28 R3、2×Ø4.5 孔距 40；外形及端子为保守包络 | 58.0 | 30.66 | 49.0
BassPort | 后置倒相管 · Ø32 × 160 可换试验件 | Audio | 概念件 | 按可用空间设计的试验初值；非 SC-2103 原厂调谐，密封固定及端口圆角待细化 | 48.0 | 160.0 | 48.0
Fascia | 前沿银色 T 型铝饰条 | Front | 铝合金 T 型材 30×30×5；安装长 425 mm | 用户选定 30×30×5 商家图；按总外廓、等厚居中 T 截面解释，圆角及公差待实测 | 425.0 | 30.0 | 30.0
Nameplate | Ariel 激光标记铭牌 | Front | 独立定制铭牌；激光标记与固定方式待商家确认 | Sigmar One 字体；98×22×0.6 mm 铭牌外廓、位置和标记效果均为概念假设 | 98.0 | 0.6 | 22.0
GrilleCloth | 透声布外观占位（非实心材料） | Front | 透声织物（薄实体贴障板前表面显示；张紧与固定待确认） | 估算 / 待选型 | 426.0 | 29.743 | 90.0
Slat01 | 横向木格栅 01 | Front | 矩形木饰条 / 面宽 10 / 法向厚 6 mm | 估算 / 待选型 | 426.0 | 8.797 | 11.365
Slat02 | 横向木格栅 02 | Front | 矩形木饰条 / 面宽 10 / 法向厚 6 mm | 估算 / 待选型 | 426.0 | 8.797 | 11.365
Slat03 | 横向木格栅 03 | Front | 矩形木饰条 / 面宽 10 / 法向厚 6 mm | 估算 / 待选型 | 426.0 | 8.797 | 11.365
Slat04 | 横向木格栅 04 | Front | 矩形木饰条 / 面宽 10 / 法向厚 6 mm | 估算 / 待选型 | 426.0 | 8.797 | 11.365
Slat05 | 横向木格栅 05 | Front | 矩形木饰条 / 面宽 10 / 法向厚 6 mm | 估算 / 待选型 | 426.0 | 8.797 | 11.365
Slat06 | 横向木格栅 06 | Front | 矩形木饰条 / 面宽 10 / 法向厚 6 mm | 估算 / 待选型 | 426.0 | 8.797 | 11.365
Slat07 | 横向木格栅 07 | Front | 矩形木饰条 / 面宽 10 / 法向厚 6 mm | 估算 / 待选型 | 426.0 | 8.797 | 11.365
LightChannel | 灯带铝槽占位 | Front | 概念件 | 估算 / 待选型 | 414.0 | 14.0 | 2.0
LightDiffuser | 3000 K 暖光扩散片 | Front | 扩散片 / 光色示意 | 估算 / 待选型 | 410.0 | 12.0 | 1.0
Baffle | 左右全频斜面障板 | Audio | 法向厚 10 mm 障板；上下斜口修切，开孔待实测 | 估算 / 待选型 | 426.0 | 39.757 | 90.0
AcousticRoof | 三音腔共用顶板 · 中部延伸至后板 | Audio | 概念件 | 估算 / 待选型 | 426.0 | 332.8 | 10.0
BearingPocket | 通用轴承密封避让杯（当前机芯待重做） | Audio | 概念件 | 估算 / 待选型 | 28.0 | 28.0 | 28.0
AcousticRear | 左右全频腔后板 · 密封试装 | Audio | 概念件 | 估算 / 待选型 | 426.0 | 10.0 | 90.0
AcousticDividerLeft | 低音腔左全深隔板 | Audio | 概念件 | 估算 / 待选型 | 10.0 | 311.485 | 90.0
AcousticDividerRight | 低音腔右全深隔板 | Audio | 概念件 | 估算 / 待选型 | 10.0 | 311.485 | 90.0
TweeterLeft | 左全频 · SC-2103 安装占位 | Audio | 概念件 | 用户提供口端外径与总高；开孔、边沿厚度及内部轮廓暂估 | 78.0 | 53.802 | 75.109
TweeterRight | 右全频 · SC-2103 安装占位 | Audio | 概念件 | 用户提供口端外径与总高；开孔、边沿厚度及内部轮廓暂估 | 78.0 | 53.802 | 75.109
Woofer | 后排低音 · SC-2103 朝下安装占位 | Audio | 概念件 | 用户提供口端外径与总高；开孔、边沿厚度及内部轮廓暂估 | 132.0 | 132.0 | 65.0
RearSupport | 后部两侧隔振承托梁 | Deck | 10 mm 木质承托梁；固定方式待定 | 估算 / 待选型 | 410.0 | 30.0 | 10.0
Isolator0 | 弹性支承 1（刚度待定） | Deck | 弹性支承与双面浅沉台均为安装假设 | 估算 / 待选型 | 16.0 | 16.0 | 8.0
Isolator1 | 弹性支承 2（刚度待定） | Deck | 弹性支承与双面浅沉台均为安装假设 | 估算 / 待选型 | 16.0 | 16.0 | 8.0
Isolator2 | 弹性支承 3（刚度待定） | Deck | 弹性支承与双面浅沉台均为安装假设 | 估算 / 待选型 | 16.0 | 16.0 | 8.0
FloatingDeck | 现有承载板（机芯开口与孔位待调整） | Deck | 10 mm 结构底板；3×Ø16 底面沉台深 3 mm；主轴孔 Ø20.4 待选型 | 估算 / 待选型 | 422.0 | 330.0 | 10.0
Amplifier | 功放板 · 含散热片整体包络（用户提供尺寸） | Electronics | 功放板及散热片整体占位；未细化散热片、端子和支柱 | 用户提供含散热片外廓长宽高；离底板间距暂估，安装孔位未知 | 75.0 | 125.0 | 45.0
PhonoBoard | 备用电子预留区（不代表另需唱放） | Electronics | 概念件 | 估算 / 待选型 | 80.0 | 52.0 | 17.0
PowerTransformer | 扬声器电源变压器 · 含固定耳包络 | Electronics | 变压器空间占位；电气、散热与磁场影响未验证 | 本体长宽高与固定耳总长由用户提供；耳宽按本体宽保守预留，耳厚为参数中的暂估值，孔位未知 | 88.0 | 55.0 | 50.0
ConnectorPlate | 套装 RCA 后板预留区（孔位待确认） | Electronics | 概念件 | 估算 / 待选型 | 105.0 | 2.0 | 32.0
ControlBase | 左前旋钮底座 | Controls | 概念件 | 估算 / 待选型 | 34.0 | 34.0 | 2.0
ControlKnob | 多功能旋钮 | Controls | 概念件 | 估算 / 待选型 | 32.0 | 32.0 | 14.0
DustCover | 烟灰透明防尘盖 | Cover | 3 mm 亚克力概念壳；4×Ø5.5 铰链孔为安装假设 | 估算 / 待选型 | 426.0 | 346.0 | 63.2
HingeBase0 | 定位合页固定叶 1 | Cover | 锌合金；HFA5751-3434 简化外形 | 用户选定 HFA5751-3434；57×51、孔距34×34、4×Ø5.2；轴线、外廓细节与安装见 references/hinges | 51.0 | 13.2 | 34.75
HingePin0 | 定位合页活动叶及轴筒 1 | Cover | 锌合金；与固定叶合计 1 只采购合页 | 用户选定 HFA5751-3434；57×51、孔距34×34、4×Ø5.2；轴线、外廓细节与安装见 references/hinges | 51.0 | 13.2 | 34.75
HingeSpacer0 | 合页上盖补偿垫片 1 | Cover | 2 mm 铝垫片；安装假设 | 用户选定 HFA5751-3434；57×51、孔距34×34、4×Ø5.2；轴线、外廓细节与安装见 references/hinges | 51.0 | 2.0 | 18.0
HingeBacking0 | 亚克力内侧压板 1 | Cover | 2 mm 铝板；安装假设 | 用户选定 HFA5751-3434；57×51、孔距34×34、4×Ø5.2；轴线、外廓细节与安装见 references/hinges | 51.0 | 2.0 | 18.0
HingeBase1 | 定位合页固定叶 2 | Cover | 锌合金；HFA5751-3434 简化外形 | 用户选定 HFA5751-3434；57×51、孔距34×34、4×Ø5.2；轴线、外廓细节与安装见 references/hinges | 51.0 | 13.2 | 34.75
HingePin1 | 定位合页活动叶及轴筒 2 | Cover | 锌合金；与固定叶合计 1 只采购合页 | 用户选定 HFA5751-3434；57×51、孔距34×34、4×Ø5.2；轴线、外廓细节与安装见 references/hinges | 51.0 | 13.2 | 34.75
HingeSpacer1 | 合页上盖补偿垫片 2 | Cover | 2 mm 铝垫片；安装假设 | 用户选定 HFA5751-3434；57×51、孔距34×34、4×Ø5.2；轴线、外廓细节与安装见 references/hinges | 51.0 | 2.0 | 18.0
HingeBacking1 | 亚克力内侧压板 2 | Cover | 2 mm 铝板；安装假设 | 用户选定 HFA5751-3434；57×51、孔距34×34、4×Ø5.2；轴线、外廓细节与安装见 references/hinges | 51.0 | 2.0 | 18.0
Foot0 | VE 橡胶脚垫与 M8 螺杆 1 | Feet | 已购橡胶脚垫总成；硬度、压缩量及承载未验证 | 用户商家图：橡胶 Ø30×20、M8 外露23；螺纹以光杆表示，金属顶片厚度未定义 | 30.0 | 30.0 | 43.0
FootMount0 | M8 脚垫固定座 1 | Feet | 已购镀黑锌固定座；有效螺纹及紧固方案待实物确认 | 用户商家图：底盘 Ø37×2.5、圆柱 Ø12×14.5、3×Ø5.5；孔分布圆及板预孔为参数中的假设 | 37.0 | 37.0 | 17.0
Foot1 | VE 橡胶脚垫与 M8 螺杆 2 | Feet | 已购橡胶脚垫总成；硬度、压缩量及承载未验证 | 用户商家图：橡胶 Ø30×20、M8 外露23；螺纹以光杆表示，金属顶片厚度未定义 | 30.0 | 30.0 | 43.0
FootMount1 | M8 脚垫固定座 2 | Feet | 已购镀黑锌固定座；有效螺纹及紧固方案待实物确认 | 用户商家图：底盘 Ø37×2.5、圆柱 Ø12×14.5、3×Ø5.5；孔分布圆及板预孔为参数中的假设 | 37.0 | 37.0 | 17.0
Foot2 | VE 橡胶脚垫与 M8 螺杆 3 | Feet | 已购橡胶脚垫总成；硬度、压缩量及承载未验证 | 用户商家图：橡胶 Ø30×20、M8 外露23；螺纹以光杆表示，金属顶片厚度未定义 | 30.0 | 30.0 | 43.0
FootMount2 | M8 脚垫固定座 3 | Feet | 已购镀黑锌固定座；有效螺纹及紧固方案待实物确认 | 用户商家图：底盘 Ø37×2.5、圆柱 Ø12×14.5、3×Ø5.5；孔分布圆及板预孔为参数中的假设 | 37.0 | 37.0 | 17.0
Foot3 | VE 橡胶脚垫与 M8 螺杆 4 | Feet | 已购橡胶脚垫总成；硬度、压缩量及承载未验证 | 用户商家图：橡胶 Ø30×20、M8 外露23；螺纹以光杆表示，金属顶片厚度未定义 | 30.0 | 30.0 | 43.0
FootMount3 | M8 脚垫固定座 4 | Feet | 已购镀黑锌固定座；有效螺纹及紧固方案待实物确认 | 用户商家图：底盘 Ø37×2.5、圆柱 Ø12×14.5、3×Ø5.5；孔分布圆及板预孔为参数中的假设 | 37.0 | 37.0 | 17.0
KitBase | 机芯基座与三弹簧 · 平台实测／弹簧外径暂估 | SelectedKit | 机芯概念占位 | 2026-09-24 用户确认除弯臂外与直臂图一致，且唱头指托不超过机芯基座右侧；355 平面总宽按图，唱盘 Ø280×11、总高85、平台128×108×5、上下40及弹簧数据来自用户。250为唱臂总长，暂作含配重/唱头的纵向外廓，不作为有效臂长。机芯整体右移12 mm以在浮动甲板上近似居中；弯管、连接套、开槽唱头壳与指托按 curved-arm-kit.png 近似。平台与弹簧座共面、唱盘高度、马达位置/直径、传动及回臂外形、弹簧直径和唱臂局部外形均为估算；底部覆盖不完整，不可据此开孔。 | 355.0 | 280.0 | 15.5
KitPlatter | 实测唱盘 Ø280 × 11 mm | SelectedKit | 机芯概念占位 | 2026-09-24 用户确认除弯臂外与直臂图一致，且唱头指托不超过机芯基座右侧；355 平面总宽按图，唱盘 Ø280×11、总高85、平台128×108×5、上下40及弹簧数据来自用户。250为唱臂总长，暂作含配重/唱头的纵向外廓，不作为有效臂长。机芯整体右移12 mm以在浮动甲板上近似居中；弯管、连接套、开槽唱头壳与指托按 curved-arm-kit.png 近似。平台与弹簧座共面、唱盘高度、马达位置/直径、传动及回臂外形、弹簧直径和唱臂局部外形均为估算；底部覆盖不完整，不可据此开孔。 | 280.0 | 280.0 | 11.0
KitMatRings | 唱盘表面环纹示意 | SelectedKit | 机芯概念占位 | 2026-09-24 用户确认除弯臂外与直臂图一致，且唱头指托不超过机芯基座右侧；355 平面总宽按图，唱盘 Ø280×11、总高85、平台128×108×5、上下40及弹簧数据来自用户。250为唱臂总长，暂作含配重/唱头的纵向外廓，不作为有效臂长。机芯整体右移12 mm以在浮动甲板上近似居中；弯管、连接套、开槽唱头壳与指托按 curved-arm-kit.png 近似。平台与弹簧座共面、唱盘高度、马达位置/直径、传动及回臂外形、弹簧直径和唱臂局部外形均为估算；底部覆盖不完整，不可据此开孔。 | 272.0 | 272.0 | 0.3
KitSpindle | 机芯主轴示意 | SelectedKit | 机芯概念占位 | 2026-09-24 用户确认除弯臂外与直臂图一致，且唱头指托不超过机芯基座右侧；355 平面总宽按图，唱盘 Ø280×11、总高85、平台128×108×5、上下40及弹簧数据来自用户。250为唱臂总长，暂作含配重/唱头的纵向外廓，不作为有效臂长。机芯整体右移12 mm以在浮动甲板上近似居中；弯管、连接套、开槽唱头壳与指托按 curved-arm-kit.png 近似。平台与弹簧座共面、唱盘高度、马达位置/直径、传动及回臂外形、弹簧直径和唱臂局部外形均为估算；底部覆盖不完整，不可据此开孔。 | 7.0 | 7.0 | 10.0
KitArmSupport | 唱臂支座 · 高40实测／外形暂估 | SelectedKit | 机芯概念占位 | 2026-09-24 用户确认除弯臂外与直臂图一致，且唱头指托不超过机芯基座右侧；355 平面总宽按图，唱盘 Ø280×11、总高85、平台128×108×5、上下40及弹簧数据来自用户。250为唱臂总长，暂作含配重/唱头的纵向外廓，不作为有效臂长。机芯整体右移12 mm以在浮动甲板上近似居中；弯管、连接套、开槽唱头壳与指托按 curved-arm-kit.png 近似。平台与弹簧座共面、唱盘高度、马达位置/直径、传动及回臂外形、弹簧直径和唱臂局部外形均为估算；底部覆盖不完整，不可据此开孔。 | 25.0 | 33.0 | 40.0
KitCurvedArm | 弯臂停放示意 · 总长250非有效臂长 | SelectedKit | 机芯概念占位 | 2026-09-24 用户确认除弯臂外与直臂图一致，且唱头指托不超过机芯基座右侧；355 平面总宽按图，唱盘 Ø280×11、总高85、平台128×108×5、上下40及弹簧数据来自用户。250为唱臂总长，暂作含配重/唱头的纵向外廓，不作为有效臂长。机芯整体右移12 mm以在浮动甲板上近似居中；弯管、连接套、开槽唱头壳与指托按 curved-arm-kit.png 近似。平台与弹簧座共面、唱盘高度、马达位置/直径、传动及回臂外形、弹簧直径和唱臂局部外形均为估算；底部覆盖不完整，不可据此开孔。 | 36.4 | 151.637 | 15.373
KitCounterweight | 后部配重外观示意 | SelectedKit | 机芯概念占位 | 2026-09-24 用户确认除弯臂外与直臂图一致，且唱头指托不超过机芯基座右侧；355 平面总宽按图，唱盘 Ø280×11、总高85、平台128×108×5、上下40及弹簧数据来自用户。250为唱臂总长，暂作含配重/唱头的纵向外廓，不作为有效臂长。机芯整体右移12 mm以在浮动甲板上近似居中；弯管、连接套、开槽唱头壳与指托按 curved-arm-kit.png 近似。平台与弹簧座共面、唱盘高度、马达位置/直径、传动及回臂外形、弹簧直径和唱臂局部外形均为估算；底部覆盖不完整，不可据此开孔。 | 20.0 | 16.0 | 20.0
KitHeadshell | 参考图弯臂连接套、开槽唱头壳与指托 · 外观估算 | SelectedKit | 机芯概念占位 | 2026-09-24 用户确认除弯臂外与直臂图一致，且唱头指托不超过机芯基座右侧；355 平面总宽按图，唱盘 Ø280×11、总高85、平台128×108×5、上下40及弹簧数据来自用户。250为唱臂总长，暂作含配重/唱头的纵向外廓，不作为有效臂长。机芯整体右移12 mm以在浮动甲板上近似居中；弯管、连接套、开槽唱头壳与指托按 curved-arm-kit.png 近似。平台与弹簧座共面、唱盘高度、马达位置/直径、传动及回臂外形、弹簧直径和唱臂局部外形均为估算；底部覆盖不完整，不可据此开孔。 | 39.844 | 67.315 | 13.0
KitCartridge | 随套装唱头占位（型号待核实） | SelectedKit | 机芯概念占位 | 2026-09-24 用户确认除弯臂外与直臂图一致，且唱头指托不超过机芯基座右侧；355 平面总宽按图，唱盘 Ø280×11、总高85、平台128×108×5、上下40及弹簧数据来自用户。250为唱臂总长，暂作含配重/唱头的纵向外廓，不作为有效臂长。机芯整体右移12 mm以在浮动甲板上近似居中；弯管、连接套、开槽唱头壳与指托按 curved-arm-kit.png 近似。平台与弹簧座共面、唱盘高度、马达位置/直径、传动及回臂外形、弹簧直径和唱臂局部外形均为估算；底部覆盖不完整，不可据此开孔。 | 16.24 | 21.339 | 5.0
KitArmRest | 停臂架与限位片示意 | SelectedKit | 机芯概念占位 | 2026-09-24 用户确认除弯臂外与直臂图一致，且唱头指托不超过机芯基座右侧；355 平面总宽按图，唱盘 Ø280×11、总高85、平台128×108×5、上下40及弹簧数据来自用户。250为唱臂总长，暂作含配重/唱头的纵向外廓，不作为有效臂长。机芯整体右移12 mm以在浮动甲板上近似居中；弯管、连接套、开槽唱头壳与指托按 curved-arm-kit.png 近似。平台与弹簧座共面、唱盘高度、马达位置/直径、传动及回臂外形、弹簧直径和唱臂局部外形均为估算；底部覆盖不完整，不可据此开孔。 | 11.0 | 8.0 | 27.0

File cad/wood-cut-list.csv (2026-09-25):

ID | 板件 | 数量 | 备料长_mm | 备料宽_mm | 名义板厚_mm | 后续加工说明
SideLeft | 左侧木板 | 1 | 350 | 124 | 12.0 | 矩形板
SideRight | 右侧木板 | 1 | 350 | 124 | 12.0 | 矩形板
Bottom | 底板 · 低音向下开孔 | 1 | 426 | 350 | 12.0 | 矩形板；低音通孔；4×Ø12.4 脚座通孔、12×Ø3 深8 底面盲预孔（安装假设）
Back | 后板 · 倒相管、AC 与铰链盲预孔 | 1 | 426 | 112 | 12.0 | 矩形板；倒相孔及沉台；AC 横孔 48×28 R3、上下 2×Ø4.5 孔距 40；4×Ø3 深8 后侧铰链盲预孔（假设）
Baffle | 左右全频斜面障板 | 1 | 426 | 98 | 10.0 | 整数矩形备料；上下两边修 18° 斜口至安装竖高 90；另开法向孔
AcousticRoof | 三音腔共用顶板 · 中部延伸至后板 | 1 | 426 | 333 | 10.0 | T 形板；成形前缘 Y=5.2；顶面前缘台阶宽 25、深 5.7、余厚 4.3；Ø28 轴承孔；3×Ø16 顶面沉台深 3（安装假设）
AcousticRear | 左右全频腔后板 · 密封试装 | 2 | 117 | 90 | 10.0 | 两块独立矩形板
AcousticDividerLeft | 低音腔左全深隔板 | 1 | 312 | 90 | 10.0 | 整数矩形备料；前缘按精确斜线修切
AcousticDividerRight | 低音腔右全深隔板 | 1 | 312 | 90 | 10.0 | 整数矩形备料；前缘按精确斜线修切
RearSupport | 后部两侧隔振承托梁 | 2 | 109 | 30 | 10.0 | 两块独立矩形梁
FloatingDeck | 唱盘与唱臂共用浮动底板 | 1 | 422 | 330 | 10.0 | 矩形板；饰条后 1、左右各 2、后板前 2 mm 名义间隙；3×Ø16 底面沉台深 3（安装假设）；另开主轴孔，机芯安装接口待定
Slat01 | 横向木格栅 01 | 1 | 426 | 10 | 6.0 | 矩形截面成品条；整体倾斜安装，无需把截面切成斜四边形
Slat02 | 横向木格栅 02 | 1 | 426 | 10 | 6.0 | 矩形截面成品条；整体倾斜安装，无需把截面切成斜四边形
Slat03 | 横向木格栅 03 | 1 | 426 | 10 | 6.0 | 矩形截面成品条；整体倾斜安装，无需把截面切成斜四边形
Slat04 | 横向木格栅 04 | 1 | 426 | 10 | 6.0 | 矩形截面成品条；整体倾斜安装，无需把截面切成斜四边形
Slat05 | 横向木格栅 05 | 1 | 426 | 10 | 6.0 | 矩形截面成品条；整体倾斜安装，无需把截面切成斜四边形
Slat06 | 横向木格栅 06 | 1 | 426 | 10 | 6.0 | 矩形截面成品条；整体倾斜安装，无需把截面切成斜四边形
Slat07 | 横向木格栅 07 | 1 | 426 | 10 | 6.0 | 矩形截面成品条；整体倾斜安装，无需把截面切成斜四边形

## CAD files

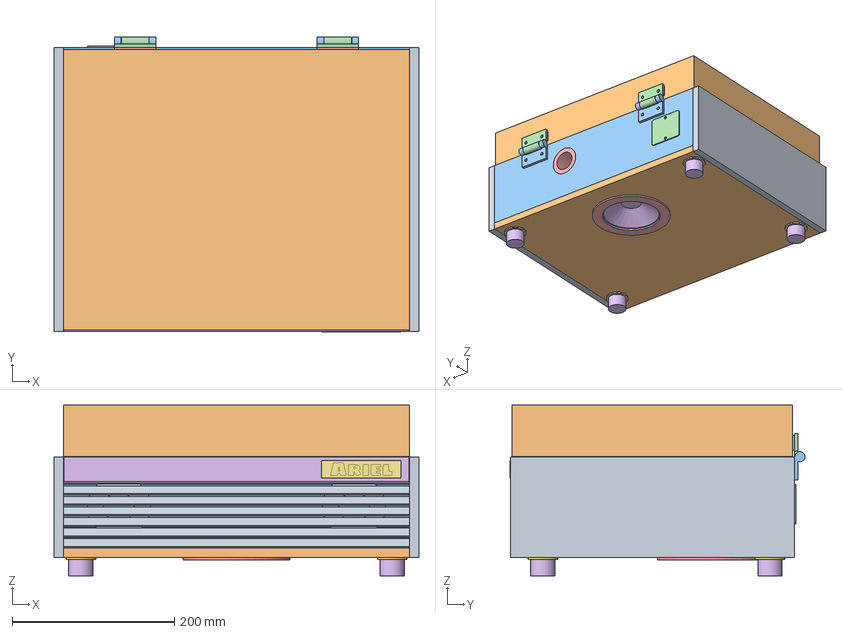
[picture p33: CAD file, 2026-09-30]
cad/record-player.step
450.0 x 363.8 x 210.7 mm
左侧木板
右侧木板
底板 · 低音向下开孔
后板 · 倒相管、AC 与铰链盲预孔
8 字 AC 插座 · 开关保险一体式安装包络
后置倒相管 · Ø32 × 160 可换试验件
前沿银色 T 型铝饰条
Ariel 激光标记铭牌
透声布外观占位（非实心材料）
横向木格栅 01
横向木格栅 02
横向木格栅 03
横向木格栅 04
横向木格栅 05
横向木格栅 06
横向木格栅 07
灯带铝槽占位
3000 K 暖光扩散片
左右全频斜面障板
三音腔共用顶板 · 中部延伸至后板
通用轴承密封避让杯（当前机芯待重做）
左右全频腔后板 · 密封试装
低音腔左全深隔板
低音腔右全深隔板
左全频 · SC-2103 安装占位
右全频 · SC-2103 安装占位
后排低音 · SC-2103 朝下安装占位
后部两侧隔振承托梁
弹性支承 1（刚度待定）
弹性支承 2（刚度待定）
弹性支承 3（刚度待定）
现有承载板（机芯开口与孔位待调整）
功放板 · 含散热片整体包络（用户提供尺寸）
备用电子预留区（不代表另需唱放）
扬声器电源变压器 · 含固定耳包络
套装 RCA 后板预留区（孔位待确认）
左前旋钮底座
多功能旋钮
烟灰透明防尘盖
定位合页固定叶 1
定位合页活动叶及轴筒 1
合页上盖补偿垫片 1
亚克力内侧压板 1
定位合页固定叶 2
定位合页活动叶及轴筒 2
合页上盖补偿垫片 2
亚克力内侧压板 2
VE 橡胶脚垫与 M8 螺杆 1
M8 脚垫固定座 1
VE 橡胶脚垫与 M8 螺杆 2
M8 脚垫固定座 2
VE 橡胶脚垫与 M8 螺杆 3
M8 脚垫固定座 3
VE 橡胶脚垫与 M8 螺杆 4
M8 脚垫固定座 4
机芯基座与三弹簧 · 平台实测／弹簧外径暂估
实测唱盘 Ø280 × 11 mm
唱盘表面环纹示意
机芯主轴示意
唱臂支座 · 高40实测／外形暂估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

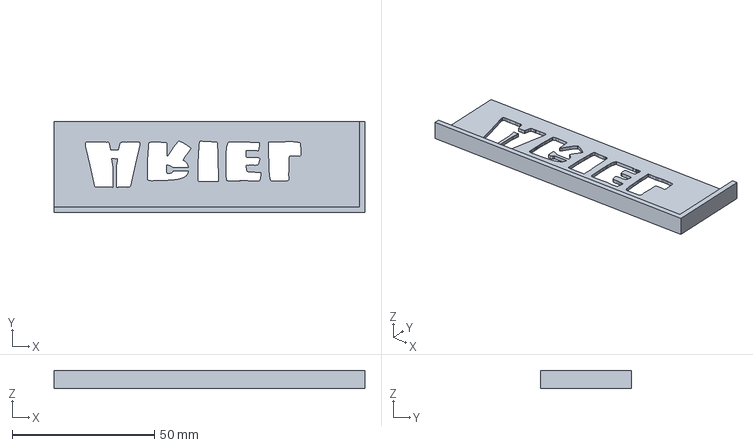
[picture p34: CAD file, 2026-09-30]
output/3d-print/Ariel-stencil.step
109.5 x 32.0 x 6.50 mm

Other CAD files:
cad/record-player.FCStd
output/3d-print/Ariel-stencil.FCStd
output/3d-print/Ariel-stencil.stl

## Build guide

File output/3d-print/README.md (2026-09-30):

# Ariel 镂空雕刻定位支架

一件打印，无需镂空贴膜。适配本项目 **30 × 30 × 5 mm、长 425 mm** 的裸 T 型铝饰条：上挡边靠住饰条上沿，右挡边靠住切断端面；正面镂空为现有 **Ariel / Sigmar One** 字形，保持原 LOGO 的居中高度和右侧位置。

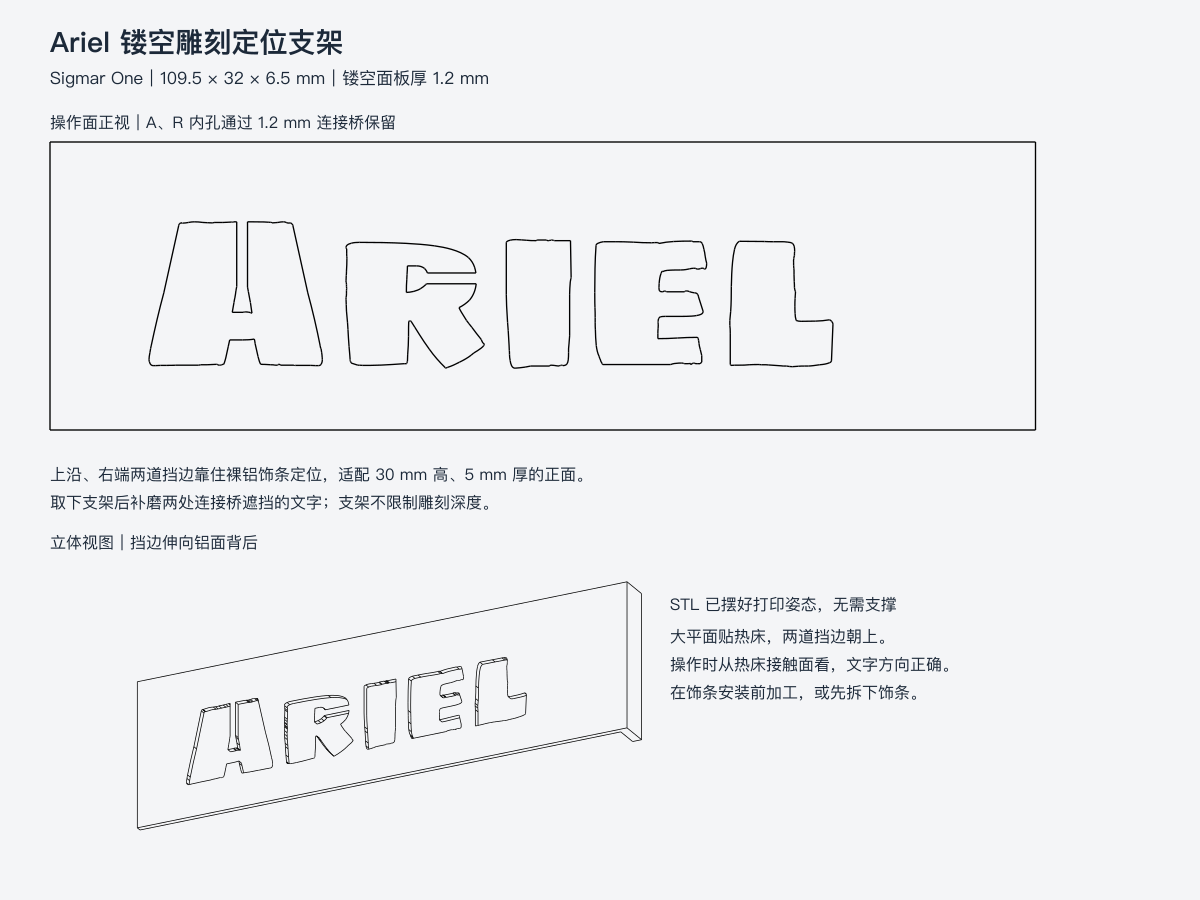
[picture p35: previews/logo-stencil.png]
实际支架几何预览


## 文件与尺寸

- [Ariel-stencil.stl](Ariel-stencil.stl)：直接导入切片软件，单位 mm；已摆好打印姿态。
- [Ariel-stencil.FCStd](Ariel-stencil.FCStd) / [STEP](Ariel-stencil.step)：同一打印姿态的独立工具模型。FCStd 保存了零件可见状态及等轴测视角，打开即可查看。
- [尺寸与几何检查](Ariel-stencil.json)：字形位置、连接桥和打印外廓。

| 项目 | 尺寸 |
|---|---|
| 打印外廓 | 109.5 × 32 × 6.5 mm |
| 接触铝面的镂空面板 | 1.2 mm 厚 |
| 上沿／右端挡边 | 2 mm 厚，向铝面背后伸出 5.3 mm |
| A、R 内孔连接桥 | 1.2 mm 宽；A 向上连接，R 向右连接 |
| 字形实际包络 | 约 75.992 × 16.261 mm，名义字高 16 mm |
| 字形右边缘距饰条右端 | 约 20.504 mm，沿用原 98 mm 铭牌画布内居中排字 |

这是两道定位挡边，没有弹性卡扣，也不限制刀具深度。连接桥、面板厚度和 5.3 mm 挡边深度是试用设计值；实物型材圆角、毛刺、打印收缩和刀头可达性需要试装核对。

## 打印

1. STL 按原尺寸 **100%** 导入，保持文件姿态：大平面在热床上，两道挡边向上，**不加支撑**。切片软件从上方看到的是背面字形；实际操作从热床接触面看，`Ariel` 方向正确，不要镜像模型。
2. 首版可用 PLA，0.4 mm 喷嘴、0.2 mm 层高、3 道墙；检查薄面板和两条连接桥被完整切片。若加 brim，避免孔内 brim，以免堵住字形。
3. 清除孔内拉丝、热床首层扩边和挡边毛刺；先空放到裸型材核对贴合与位置。不要用刀头修整模板孔边。

## 使用

1. **安装前加工，或先拆下饰条；不要带着整机磨。** 右挡边需要包住型材端部，装机后的 0.5 mm 木侧板间隙容不下 2 mm 挡边。上挡边也需要饰条上方空出来。
2. 在同材质边角料先试刻。固定铝条，再将支架的薄面贴紧正面，上挡边和右挡边都靠实，用普通胶带压住空白边缘或用夹具固定，防止跳动；普通固定胶带不充当文字遮罩。
3. 从字形内部开始浅磨、分次接近轮廓。使用适合铝材的细刀头，先确认刀尖能伸到铝面、刀杆能避开孔壁；**切削刃不要贴塑料边高速摩擦，也不要以挡边承受侧推力**。模板辅助定位，不能保证刀头不越界或刻深一致。
4. A 和 R 的连接桥会挡住两小段文字。取下支架后补磨这两段；若喜欢带桥的模板字效果，也可以保留。
5. 固定工件、佩戴护目镜；工件和模板发热或模板边缘受损时停机检查。银色铝面浅磨的对比度取决于原表面处理，先用试刻结果决定效果。

## 重新生成

使用 FreeCAD 1.1.1，在 **GUI 中**执行 [build-logo-stencil.FCMacro](../../tools/build-logo-stencil.FCMacro)。先关闭旧的 `Ariel-stencil.FCStd`；需要保留的手动编辑先另存副本。生成器会拒绝覆盖当前已打开的目标文件，包括指向同一文件的符号链接路径。

在 FreeCAD 的“宏 → 宏…”中，将用户宏位置设为仓库的 `tools/`，选择 `build-logo-stencil.FCMacro` 并执行。FreeCAD 尚未启动时，也可以从仓库根目录运行：

```sh
open -a FreeCAD --args "$PWD/tools/build-logo-stencil.FCMacro"
```

宏生成全部工具文件，保存零件可见性与视角，再重开导出的 FCStd 检查默认显示；它不保存其他已打开文档。直接用无界面 Python 执行生成器会被拒绝，以免再次导出缺少 GUI 显示信息的 FCStd。

宏完成后，从仓库根目录转换 PNG 并运行检查。PNG 转换另需 `rsvg-convert`；测试使用 `FREECAD_RESOURCES`，环境设置见 [整机重建的运行环境说明](../../README.md#整机重建)。

```sh
rsvg-convert previews/logo-stencil.svg -o previews/logo-stencil.png
PYTHONPATH="${FREECAD_RESOURCES:?请先设置 FreeCAD 运行环境}/lib" \
  "$FREECAD_RESOURCES/bin/python" -m unittest discover -s tests -p 'test_logo_stencil.py' -v
```

生成器读取现有 `cad/parameters.json` 的饰条与排字尺寸，复用仓库字体；面板、挡边和连接桥尺寸在 `tools/build_logo_stencil.py` 中定义。执行后覆盖本目录四种导出文件及 `previews/logo-stencil.svg`，PNG 单独转换。生成器新建并关闭独立工具文档，宏随后重开它用于查看，不打开或修改整机主 CAD。FreeCAD 自动备份沿用仓库忽略规则，不作为交付文件。

## 验证状态

2026-09-30 的实现验证已完成：

- `test_logo_stencil.py` 的 6 项检查通过：内孔连接与闭合网格、裸饰条挡边贴合无穿透、平面朝下的打印姿态与字形旋转、文字边距与临时对象清理、无界面导出拒绝写文件、保存的 GUI 可见状态与相机信息。
- STL 回读为闭合网格、1 个连通分量；STEP 回读为 1 个有效实体；FCStd 回读为 1 个有效工具对象。
- GUI 重开确认 `ArielStencil.ViewObject.Visibility=True`，实际三维视口确认零件显示。原无界面导出缺少 `GuiDocument.xml`，已通过 GUI 宏重新保存修复。
- 已目视检查实际实体投影的正视／立体预览，A 向上、R 向右的连接桥位置与操作面的文字朝向正确。

工具单独交付，不加入整机装配、整机 STEP 或零件清单；现有激光铭牌模型仍保留为另一方案。以上是几何与文件验证，**尚未进行实物打印或雕刻试用**；后续待办统一记录在 [当前工作交接](../../docs/current-work-handoff.md#已知问题与待修项)。

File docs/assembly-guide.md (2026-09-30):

# 整机全景与组件导览

[图册 01 中的两页 A2 导览](../output/pdf/01-assembly-and-enclosure.pdf)是三份尺寸图册的阅读入口，基于单一主 CAD 中的 `v0.11-10x6-grille-slats` 结构和 `v0.6-centered-mechanism` 机芯制作。两页原尺寸 A2 导览插在 A-STOCK 木板清单之后；不再另行交付内容重复的 00 PDF。

- **第 1 页：整机全景。** 开盖三维视图标出外壳、格栅、透明盖、铰链、脚垫、机芯和旋钮；彩色编号下直接显示部件名称。
- **第 2 页：内部展开。** 移开台面、音腔顶板、障板等结构，显示扬声器、隔板、支承与电子模块；主图及后部接口小图在彩色编号下直接显示部件名称，右侧目录继续列出材料、数量和详图号；后部小图用半透明后板显示 AC 插座和接口板预留。

[全景高清 PNG](../previews/assembly-guide-1.png) · [内部展开高清 PNG](../previews/assembly-guide-2.png)

## 如何与尺寸图对应

图上编号对应右侧目录中的中文名称、材料状态、数量与详图号。G-01 和 G-02 的编号下方名称与右侧目录读取同一条 `title` 数据，不另设容易失配的缩写映射；图中只重复名称，材料、数量和详图号仍集中在目录中。两页共用相同的 16–578 mm 内容边界、285 mm 主视图宽度、X=25／363 mm 左右标注列和 185 mm 右侧目录宽度；这些数值由 `tools/assembly_guide_pdf.py` 顶部的共享布局常量统一管理。后部接口图作为 G-02 左侧内容区内的辅助小图。`A-Pxx` 对应图册 01，`B-Pxx` 对应图册 02，`C-Pxx` 对应图册 03；图号是页面右上角的编号，不是 PDF 阅读器页码。新增的 `A-03` 障板局部剖视、`A-H01` 至 `A-H03` 和 `B-H01` 至 `B-H03` 板件开孔图见[开孔定位索引](drawing-pack.md#障板装配与板件开孔定位)。原零件页已补开孔图引用；原 `A-Pxx`／`B-Pxx` 图号保持不变，因此导览目录仍有效，插页后不要沿用旧 PDF 页码。

当前默认配置的 35 个标注项覆盖整机装配的全部 65 个物理 CAD 对象。主模型的零件直接位于对象树根层，导览按 `IsReference`、`IsDiagnostic` 与 `AssemblySection` 元数据识别范围，不依赖树分组。重复零件和总成可合并标注，例如脚垫及固定座各 4 件合并为 C03 四套、格栅 7 条、合页 2 只加 2 块补偿垫片和 2 块内压板、唱头壳与唱头各 1 件。`AcousticRear` 与 `RearSupport` 各是一个含两块独立板件的对象，数量按实物板件说明，不把对象数当作采购件数。格栅数量与标注目标从当前模型的零件目录读取；调整 `slat_count` 并重建模型后，导览选择现有格栅的中间一根作标注。编号与 CAD 对象、原图号、源文件 SHA-256 的映射保存在 [导览索引](../cad/assembly-guide-index.json)。

底板前沿与底板一体保留，已取消原独立下横梁及其 W05 标注；其余导览编号不重排。

F01 现对应 30 × 30 × 5 mm T 型铝饰条与独立 Ariel 铭牌，零件详图仍为 A-P02；铭牌激光标记使用[单独矢量稿](../references/nameplate/Ariel-laser.svg)。W07 对应加工了前缘台阶的音腔顶板，零件详图仍为 B-P01。安装截面见 A-03，顶板台阶尺寸及新成形边孔位基准见 B-H02。型材已选定，胶层、固定件与根部圆角仍待确认，详见[型材安装说明](../references/fascia/README.md)。

木板标注整数矩形备料尺寸；W01-W11 的标准名称、数量与备料尺寸和图册 01 的 A-STOCK 共用同一目录，合计 20 块／条。W05 是已取消的独立下横梁，编号保留不重排。斜切成形尺寸及完整加工说明仍需查看原零件图和 A-STOCK。胡桃木饰面与板材基材分别表述，未确定的材料、壁厚和采购型号明确标注待确认。蓝、绿、木色等是识别色，不代表最终材料或采购状态。

E03 引出线指向变压器可见顶面；变压器向前调整后，标注避开展开的隔板。

C02 对应两只 HFA5751-3434 及安装板，标注端点位于右侧可见内压板。合页固定叶与活动叶见 A-P06，补偿垫片与内压板见 A-P08；后板孔表见 A-H02，盖后壁孔表见 A-H03。采购依据及未确认项见[铰链安装说明](../references/hinges/README.md)。

## 视图与范围

所有视图由保存的 FreeCAD 实体渲染，引出线端点从同一正交相机投影计算并落到对应实体表面。开盖时，盖壳、活动叶、补偿垫片与内压板绕同一轴线转动，固定叶保持贴装后板。展开仅移动临时副本中的零件，不缩放实体，不修改源 CAD，也不改变原装配位置。展开距离不是装配间隙，展示顺序不是已验证的拆装工序。

K01 现包含机芯基座及三个弹簧外廓套筒（1 座 + 3 弹簧），不是四件同形零件；套筒仅表示外径预留。

导览采用部分实测的当前弯臂机芯，未混入基线历史通用机芯；整机中仍保留的通用轴承避让杯明确注明待适配。机芯安装未放行，备用电子区与接口板预留不代表已经选购的模块。诊断包络及干涉体不作为材料或组件列出。

电源线、内部线束、LED 灯带本体、用于连接的独立螺钉／紧固垫圈／锁紧件、密封件、胶粘剂和吸音材料尚未建模（合页的两块补偿垫片与两块内压板已建模，已购脚垫自带的 M8 螺杆也已包含在 `Foot0`–`Foot3` 中），作为范围说明列出，不虚构位置、数量或规格。这份导览用于认识现有模型，不替代加工图或电气接线图。

## 重新生成

先确保保存的主 CAD、两份 JSON 参数及 17／11／14 页基础图册同步，随后在 FreeCAD 1.1.1 的宏对话框执行 `tools/assembly-guide.FCMacro`。宏读取临时副本，校验两份参数快照，恢复闭盖基准后，将三张原始视图与标注投影写入忽略的 `tmp/assembly-guide/`，不保存修改后的模型。

在仓库根目录使用含 ReportLab、pypdf 和 Poppler 的普通 Python 排版。脚本在 `tmp/assembly-guide/` 生成临时两页 PDF，核对图册 01 的 CAD 哈希与 17 页基础图号序列，再把两页导览插入 A-STOCK 后。合并 PDF、两张 180 dpi PNG 和编号索引全部在临时目录生成成功后才替换正式文件，随后删除临时 PDF 及旧的正式 00 文件；预览生成失败不会发布部分产物。重复运行会先移除上次嵌入的导览页再重新插入，不会累积重复页面；若图册 01 不存在或与当前 CAD 不一致则明确停止。字体示例 `tmp/fonts/chinese-font.ttf` 是项目相对路径占位，需自行准备字体或替换为已有字体的相对路径：

```sh
python3 tools/assembly_guide_pdf.py --font tmp/fonts/chinese-font.ttf
```

请显式传入存在且可嵌入的中文字体。脚本保留的旧默认字体路径不保证可用，也不会自动搜索替代字体。当前 v0.11 交付使用 STHeiti Light；TrueType 集合 `.ttc` 需确认默认子字体可由 ReportLab 读取并覆盖所需字符。PDF 中嵌入字体，阅读者无需安装；A2 原幅为 594 × 420 mm，PNG 约 4210 × 2977 像素。

几何参数改变后须先重建 CAD，依次重建三册图纸、重跑导览宏并执行导览排版；导览排版以刚生成的 17 页第一册为底稿，输出最终 19 页第一册。若 CAD 在渲染后发生变化，排版脚本会拒绝使用过期视图。目录、图号映射或渲染脚本改变后也应重跑宏，即使 CAD 未变：索引只记录主 CAD 的 SHA-256，不校验脚本和 PDF 的版本。

验证包括对象覆盖、重复映射拒绝、当前图号关联、1／3／8 根格栅的标注目标有效性、复合板件数量及源 CAD 未改写的回归用例。渲染时沿相机方向检查引出线端点是否被其他不透明零件挡住；排版拒绝缺失或被遮挡的实际使用标注。生成后还需目视检查两页的引出线、可见部件与文字排版。终端执行前按 [README](../README.md#整机重建) 设置 `FREECAD_RESOURCES`。

```sh
PYTHONPATH="${FREECAD_RESOURCES:?请先设置 FreeCAD 运行环境}/lib" \
  "$FREECAD_RESOURCES/bin/python" -m unittest discover -s tests -v
FREECAD_RESOURCES="${FREECAD_RESOURCES:?请先设置 FreeCAD 运行环境}" \
  python3 -m unittest discover -s tests -p '*_pdf.py' -v
```

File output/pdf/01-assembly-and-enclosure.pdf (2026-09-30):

黑胶唱片机 / 整机与外壳 | A-00 | A3 横向 | 单位 mm
图册索引与读图约定 | 3 份 PDF / 当前保存模型 / 非展开下料图
现存 CAD 几何尺寸 / 概念与空间核对图；未定义公差、连接工艺和安装孔不作加工放行。 | v0.11-10x6-grille-slats | 2026-09-30 | 01

# 图册 01 整机与外壳

### 闭盖六面图、障板局部剖视、外壳零件；底板与后板开孔定位图。

# 图册 02 音腔与内部结构

### 内部布置、斜障板与音腔结构；障板、音腔顶板和浮动底板开孔定位图。

# 图册 03 机芯与电子部件

### 扬声器、功放、变压器、电子预留、当前弯臂机芯；附基线通用机芯对照。

### 方向与尺寸：X 为左右方向，Y 为前后方向，Z 为高度；原点是机体左前方桌面基准。尺寸表中的长、宽、高均为装配姿态下的 XYZ 外包络，不自动按最大边排序。

尺寸精度：所有轮廓直接投影自保存的 FreeCAD 实体；外包络使用 optimalBoundingBox(False) 精确读取，显示到 0.001 mm 仅为数值记录，不表示制造公差。

### 备料与厚度：木板另列整数矩形备料 L × W × T；斜板需按成形轮廓修切。板厚按法向计，空心罩标壁厚；未知厚度明确注明。名义板厚须实测，锯缝、贴皮和装配余量另核。

### 投影约定：这是独立命名的正投影视图集，布局不采用统一第一角或第三角排列；各视图比例单独注明。小件可放大，薄件侧视尺寸文字记录真实厚度。打印采用 A3、100% 实际大小。

### 同形件：侧板、格栅、隔板、脚垫等用代表件图形加数量，安装位置见附表。左右后板及承托梁按独立实体分别出图，避免把跨空区包络当成单块尺寸。

### 当前配置：整机六面图与全部零件取自同一主 CAD；历史机芯仅作隐藏参考。当前机芯采用部分实测尺寸；局部下探轮廓仍为估算，安装未放行。

覆盖核对：当前装配 65 个对象；隐藏历史参考 16 个对象；诊断干涉体不列作零件。

record-player.FCStd SHA-256

08db7b527fcfc7747c2f7a8d27714b8630ba7e80b7e7a8a5b4e3a5e7ee5ed833

黑胶唱片机 / 整机与外壳 | A-STOCK | A3 横向 | 单位 mm
木板矩形备料汇总 | 整数名义尺寸 / 成形与接口尺寸详见零件页
现存 CAD 几何尺寸 / 概念与空间核对图；未定义公差、连接工艺和安装孔不作加工放行。 | v0.11-10x6-grille-slats | 2026-09-30 | 02
导览 | 板件 | 数量 | 备料长 L | 备料宽 W | 板厚 T | 后续加工
W01 | 左右侧板 | 2 | 350 | 124 | 12 | 矩形板
W02 | 横向木格栅 | 7 | 426 | 10 | 6 | 矩形截面成品条；整体倾斜安装，无需把截面切成斜四边形
W03 | 底板 | 1 | 426 | 350 | 12 | 矩形板；低音通孔；4×Ø12.4 脚座通孔、12×Ø3 深8 底面盲预孔（安装假设）
W04 | 后板 | 1 | 426 | 112 | 12 | 矩形板；倒相孔及沉台；AC 横孔 48×28 R3、上下 2×Ø4.5 孔距 40；4×Ø3 深8 后侧铰链盲预孔（假设）
W06 | 倾斜扬声器障板 | 1 | 426 | 98 | 10 | 整数矩形备料；上下两边修 18° 斜口至安装竖高 90；另开法向孔
W07 | 三音腔共用顶板 | 1 | 426 | 333 | 10 | T 形板；成形前缘 Y=5.2；顶面前缘台阶宽 25、深 5.7、余厚 4.3；Ø28 轴承孔；3×Ø16 顶面沉台深 3（安装假设）
W08 | 左右全频腔后板 | 2 | 117 | 90 | 10 | 两块独立矩形板
W09 | 低音腔全深隔板 | 2 | 312 | 90 | 10 | 整数矩形备料；前缘按精确斜线修切
W10 | 后部承托梁 | 2 | 109 | 30 | 10 | 两块独立矩形梁
W11 | 浮动承载台面 | 1 | 422 | 330 | 10 | 矩形板；饰条后 1、左右各 2、后板前 2 mm 名义间隙；3×Ø16 底面沉台深 3（安装假设）；另开主轴孔，机芯安装接口待定

共 20 块 / 条；与整机导览 W01-W11 一一对应。L、W 为板件自身平面的矩形备料尺寸，T 为法向板厚。

W05 已退役：原独立下横梁与底板完全重叠，已取消；编号保留不重排。

斜障板备料后修斜口，隔板备料后修斜前缘，顶板切 T 形轮廓；几何小数保留在成形图中，不能把接缝坐标逐项取整。

名义板厚须实测；本表不含锯缝、打磨、贴皮、封边及拼接余量。材料、连接方式与公差确认后才能作最终下料放行。

# 黑胶唱片机 / 整机结构导览

# 01 从整机外观认识部件

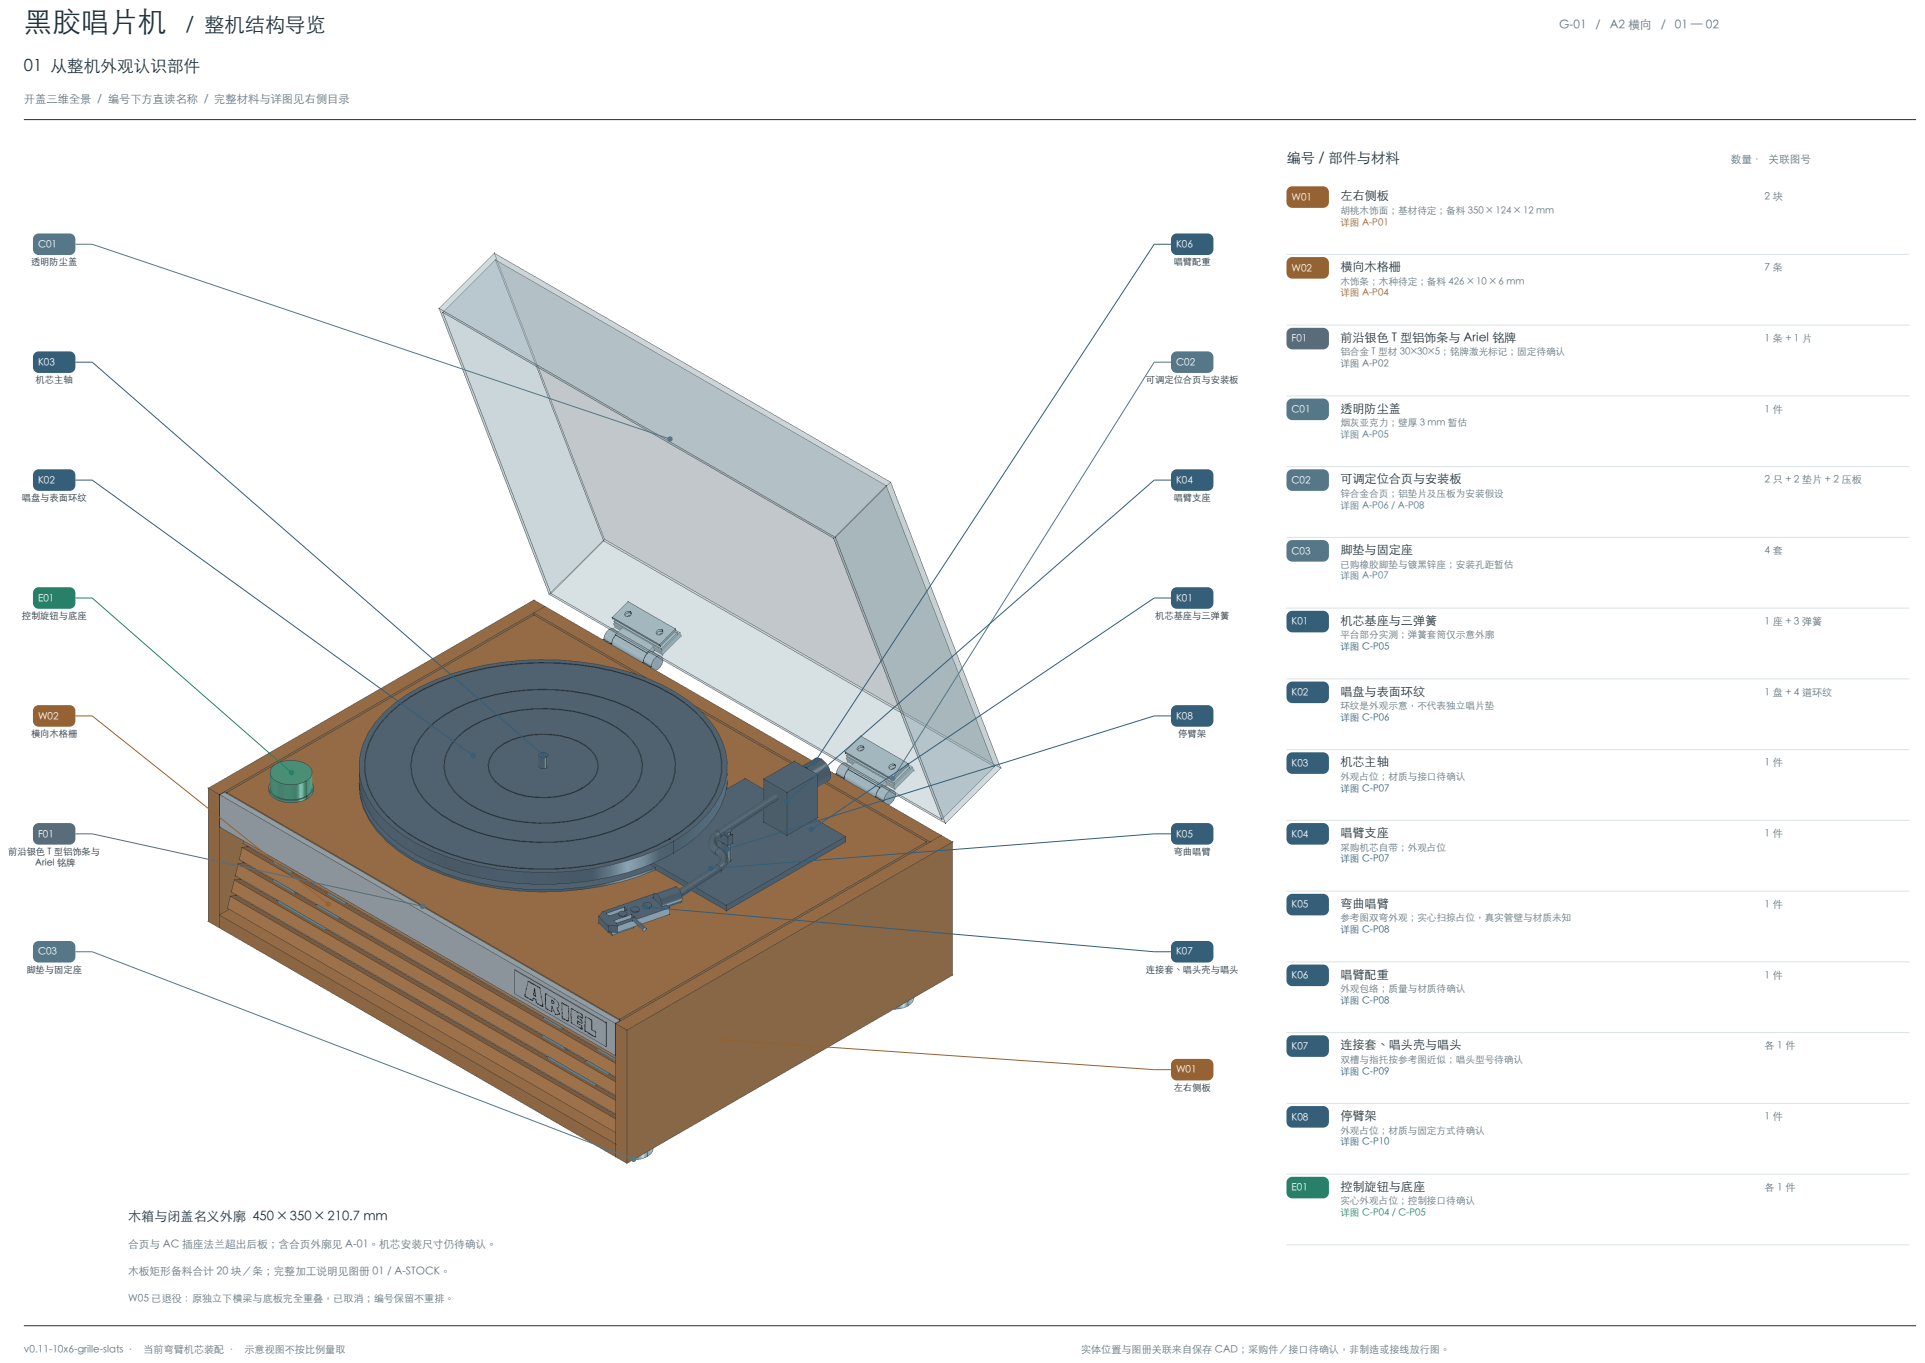
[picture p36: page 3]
v0.11-10x6-grille-slats · 当前弯臂机芯装配 · 示意视图不按比例量取; 实体位置与图册关联来自保存 CAD；采购件／接口待确认，非制造或接线放行图。; 透明防尘盖; 机芯主轴; 唱盘与表面环纹; 控制旋钮与底座; 横向木格栅; 前沿银色 T 型铝饰条与 Ariel 铭牌; 脚垫与固定座; 唱臂配重; 可调定位合页与安装板; 唱臂支座; 机芯基座与三弹簧; 停臂架; 弯曲唱臂; 连接套、唱头壳与唱头; 左右侧板; 编号 / 部件与材料; 数量 · 关联图号; 锌合金合页；铝垫片及压板为安装假设 详图 A-P06 / A-P08; 已购橡胶脚垫与镀黑锌座；安装孔距暂估 详图 A-P07; 平台部分实测；弹簧套筒仅示意外廓 详图 C-P05; 1 盘 + 4 道环纹; 环纹是外观示意，不代表独立唱片垫 详图 C-P06; 外观占位；材质与接口待确认 详图 C-P07; 采购机芯自带；外观占位 详图 C-P07; 外观包络；质量与材质待确认 详图 C-P08; 双槽与指托按参考图近似；唱头型号待确认 详图 C-P09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

开盖三维全景 / 编号下方直读名称 / 完整材料与详图见右侧目录

胡桃木饰面；基材待定；备料 350 × 124 × 12 mm

木饰条；木种待定；备料 426 × 10 × 6 mm

铝合金 T 型材 30×30×5；铭牌激光标记；固定待确认

烟灰亚克力；壁厚 3 mm 暂估

参考图双弯外观；实心扫掠占位，真实管壁与材质未知

合页与 AC 插座法兰超出后板；含合页外廓见 A-01。机芯安装尺寸仍待确认。

木板矩形备料合计 20 块／条；完整加工说明见图册 01 / A-STOCK。

W05 已退役：原独立下横梁与底板完全重叠，已取消；编号保留不重排。

# 黑胶唱片机 / 整机结构导览

# 02 分层展开，认识内部结构

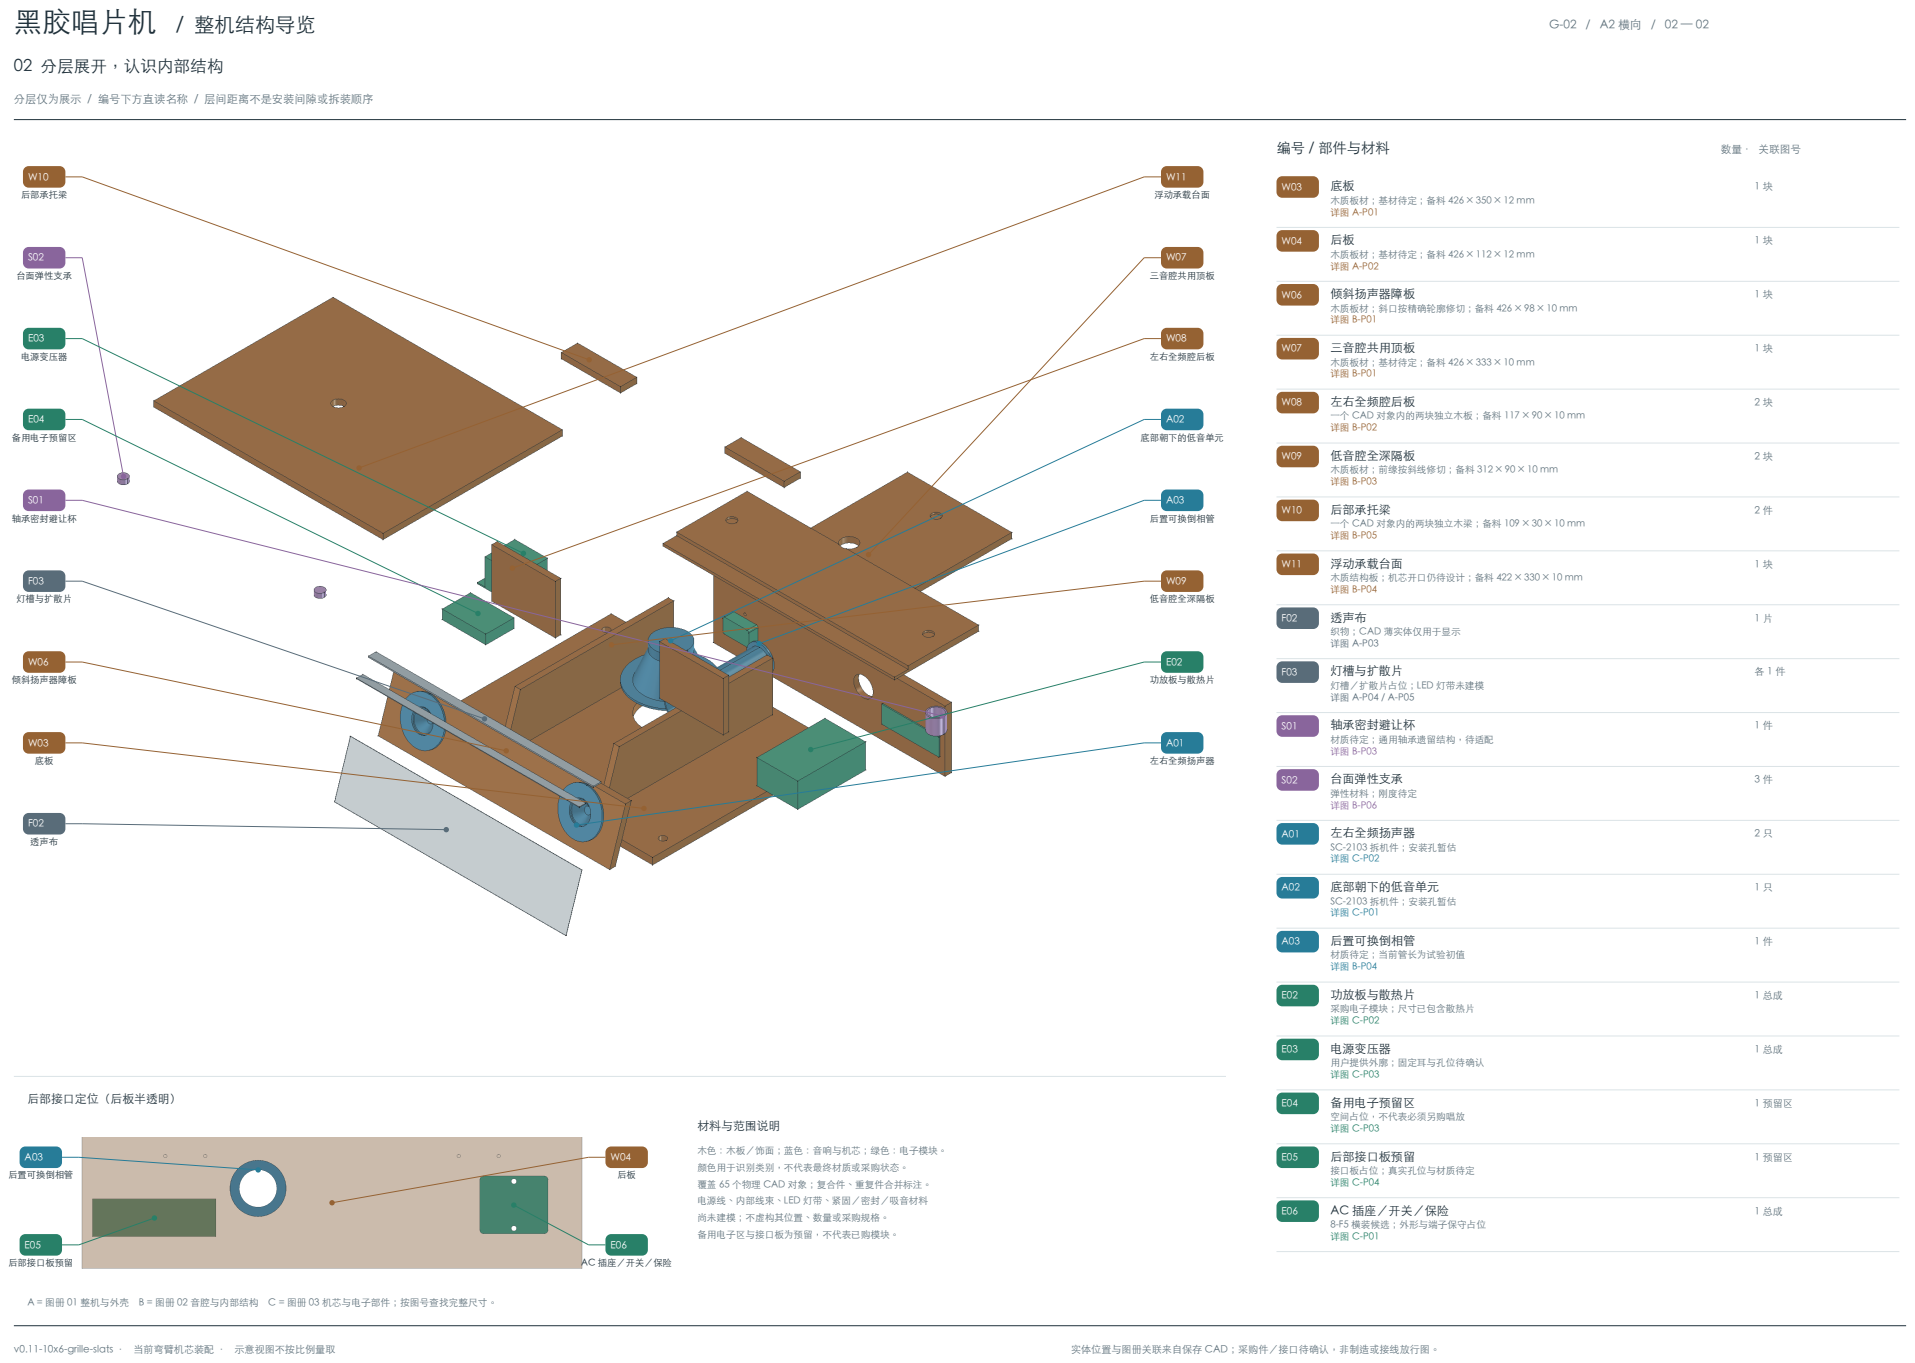
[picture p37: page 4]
v0.11-10x6-grille-slats · 当前弯臂机芯装配 · 示意视图不按比例量取; 实体位置与图册关联来自保存 CAD；采购件／接口待确认，非制造或接线放行图。; 后部承托梁; 台面弹性支承; 电源变压器; 备用电子预留区; 轴承密封避让杯; 灯槽与扩散片; 倾斜扬声器障板; 透声布; 浮动承载台面; 三音腔共用顶板; 左右全频腔后板; 底部朝下的低音单元; 后置可换倒相管; 低音腔全深隔板; 功放板与散热片; 左右全频扬声器; 编号 / 部件与材料; 数量 · 关联图号; 弹性材料；刚度待定 详图 B-P06; 材质待定；当前管长为试验初值 详图 B-P04; 采购电子模块；尺寸已包含散热片 详图 C-P02; 用户提供外廓；固定耳与孔位待确认 详图 C-P03; 1 预留区; 空间占位，不代表必须另购唱放 详图 C-P03; 后部接口板预留; 接口板占位；真实孔位与材质待定 详图 C-P04; 8-F5 横装候选；外形与端子保守占位 详图 C-P01; 后部接口定位（后板半透明）; 材料与范围说明

分层仅为展示 / 编号下方直读名称 / 层间距离不是安装间隙或拆装顺序

木质板材；基材待定；备料 426 × 350 × 12 mm

木质板材；基材待定；备料 426 × 112 × 12 mm

木质板材；斜口按精确轮廓修切；备料 426 × 98 × 10 mm

木质板材；基材待定；备料 426 × 333 × 10 mm

一个 CAD 对象内的两块独立木板；备料 117 × 90 × 10 mm

木质板材；前缘按斜线修切；备料 312 × 90 × 10 mm

一个 CAD 对象内的两块独立木梁；备料 109 × 30 × 10 mm

木质结构板；机芯开口仍待设计；备料 422 × 330 × 10 mm

织物；CAD 薄实体仅用于显示

灯槽／扩散片占位；LED 灯带未建模

材质待定；通用轴承遗留结构，待适配

SC-2103 拆机件；安装孔暂估

木色：木板／饰面；蓝色：音响与机芯；绿色：电子模块。
颜色用于识别类别，不代表最终材质或采购状态。
覆盖 65 个物理 CAD 对象；复合件、重复件合并标注。
电源线、内部线束、LED 灯带、紧固／密封／吸音材料
尚未建模；不虚构其位置、数量或采购规格。
备用电子区与接口板为预留，不代表已购模块。

A = 图册 01 整机与外壳 B = 图册 02 音腔与内部结构 C = 图册 03 机芯与电子部件；按图号查找完整尺寸。

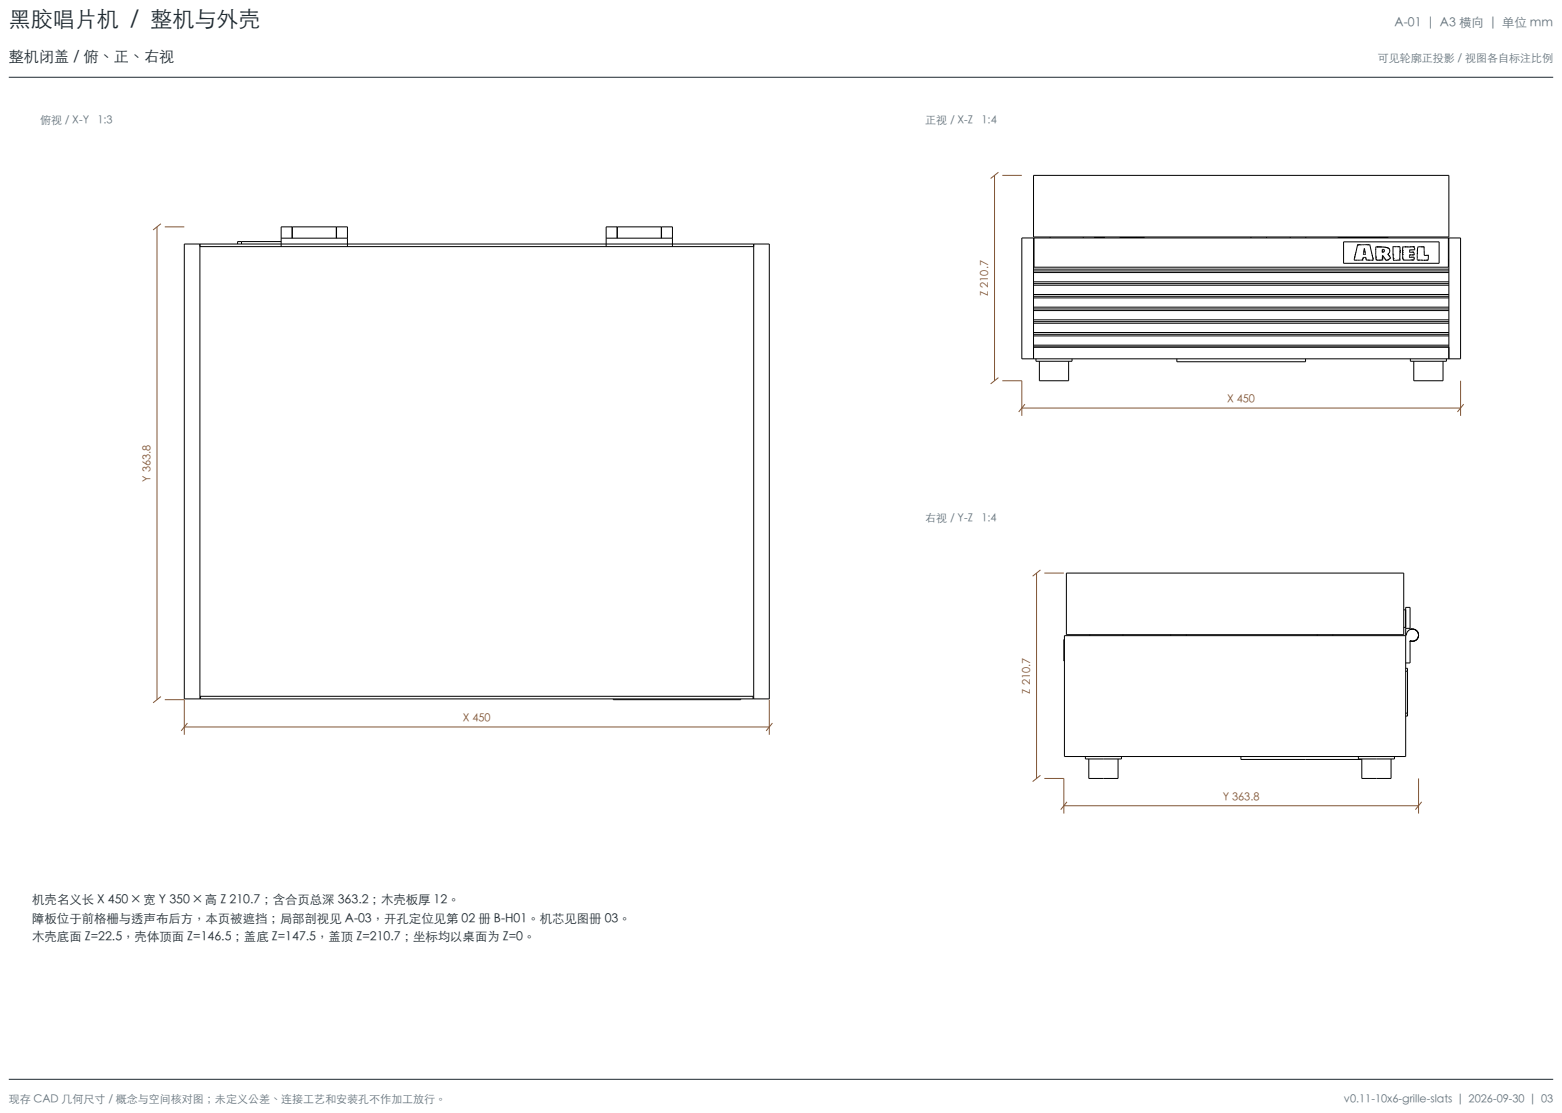
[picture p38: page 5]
黑胶唱片机 / 整机与外壳; 整机闭盖 / 俯、正、右视; 可见轮廓正投影 / 视图各自标注比例; 现存 CAD 几何尺寸 / 概念与空间核对图；未定义公差、连接工艺和安装孔不作加工放行。; v0.11-10x6-grille-slats | 2026-09-30 | 03

机壳名义长 X 450 × 宽 Y 350 × 高 Z 210.7；含合页总深 363.2；木壳板厚 12。
障板位于前格栅与透声布后方，本页被遮挡；局部剖视见 A-03，开孔定位见第 02 册 B-H01。机芯见图册 03。
木壳底面 Z=22.5，壳体顶面 Z=146.5；盖底 Z=147.5，盖顶 Z=210.7；坐标均以桌面为 Z=0。

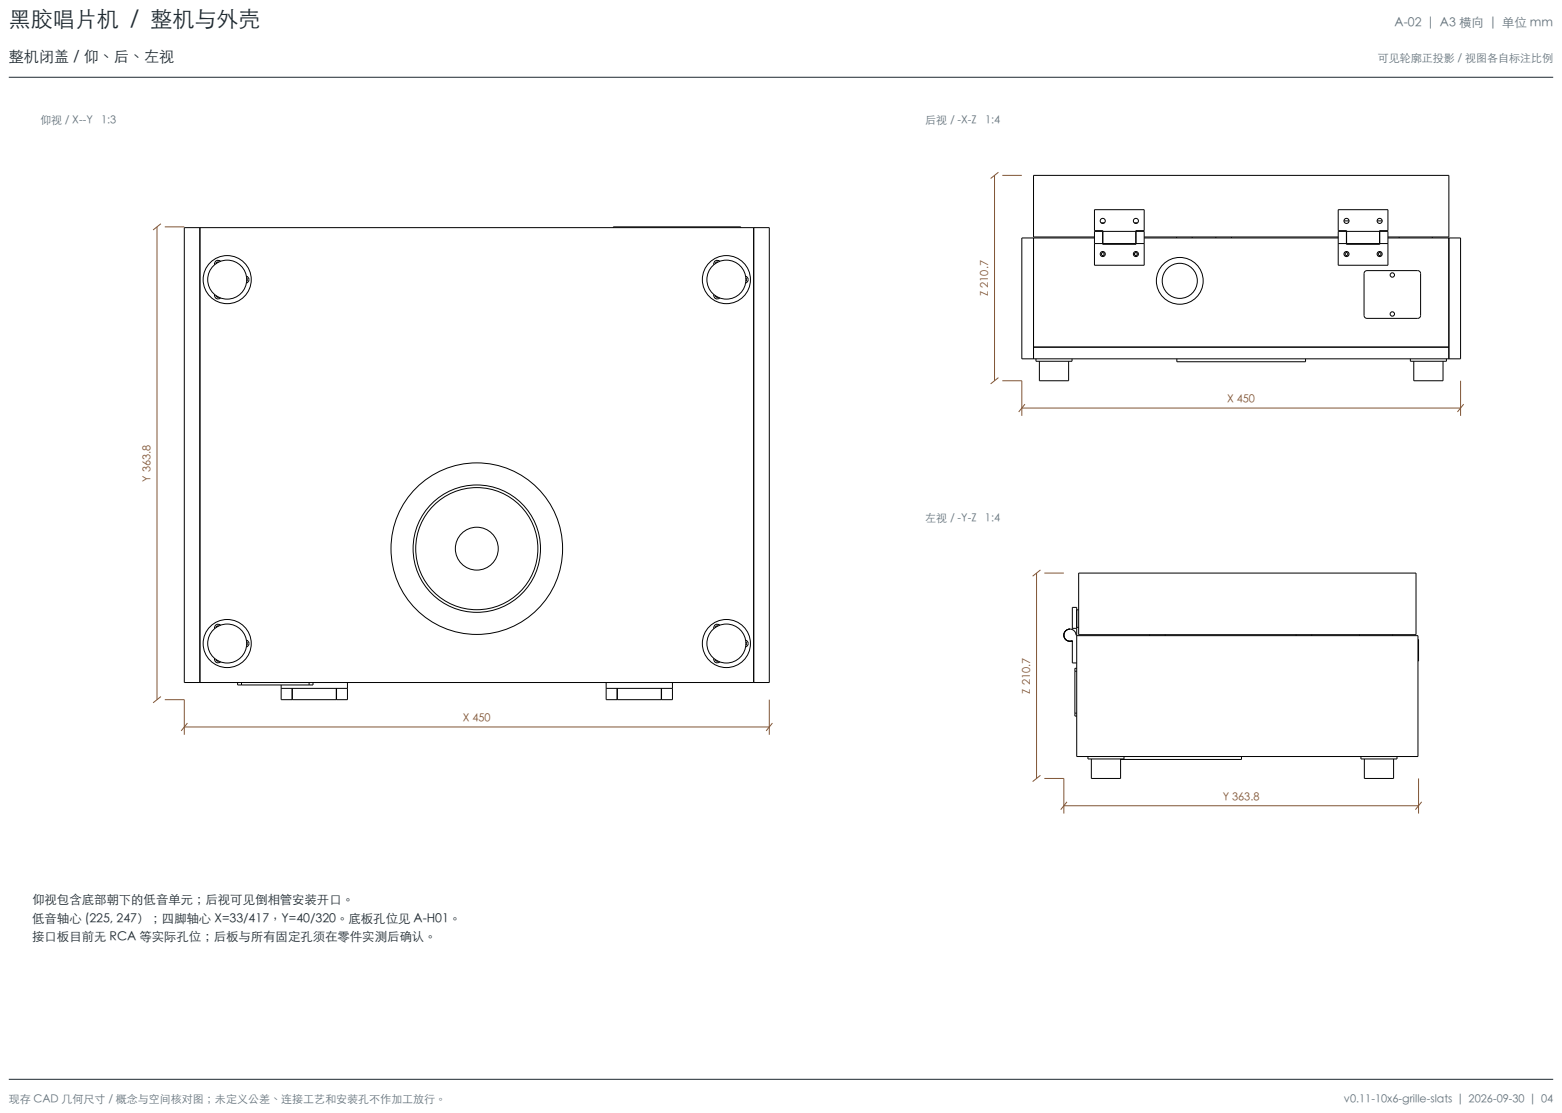
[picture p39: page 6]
黑胶唱片机 / 整机与外壳; 整机闭盖 / 仰、后、左视; 可见轮廓正投影 / 视图各自标注比例; 现存 CAD 几何尺寸 / 概念与空间核对图；未定义公差、连接工艺和安装孔不作加工放行。; v0.11-10x6-grille-slats | 2026-09-30 | 04

仰视包含底部朝下的低音单元；后视可见倒相管安装开口。
低音轴心 (225, 247）；四脚轴心 X=33/417，Y=40/320。底板孔位见 A-H01。
接口板目前无 RCA 等实际孔位；后板与所有固定孔须在零件实测后确认。

黑胶唱片机 / 整机与外壳 | A-03 | A3 横向 | 单位 mm
倾斜扬声器障板 / 前部局部装配剖视 | 保存实体临时剖切 / 源 CAD 不变

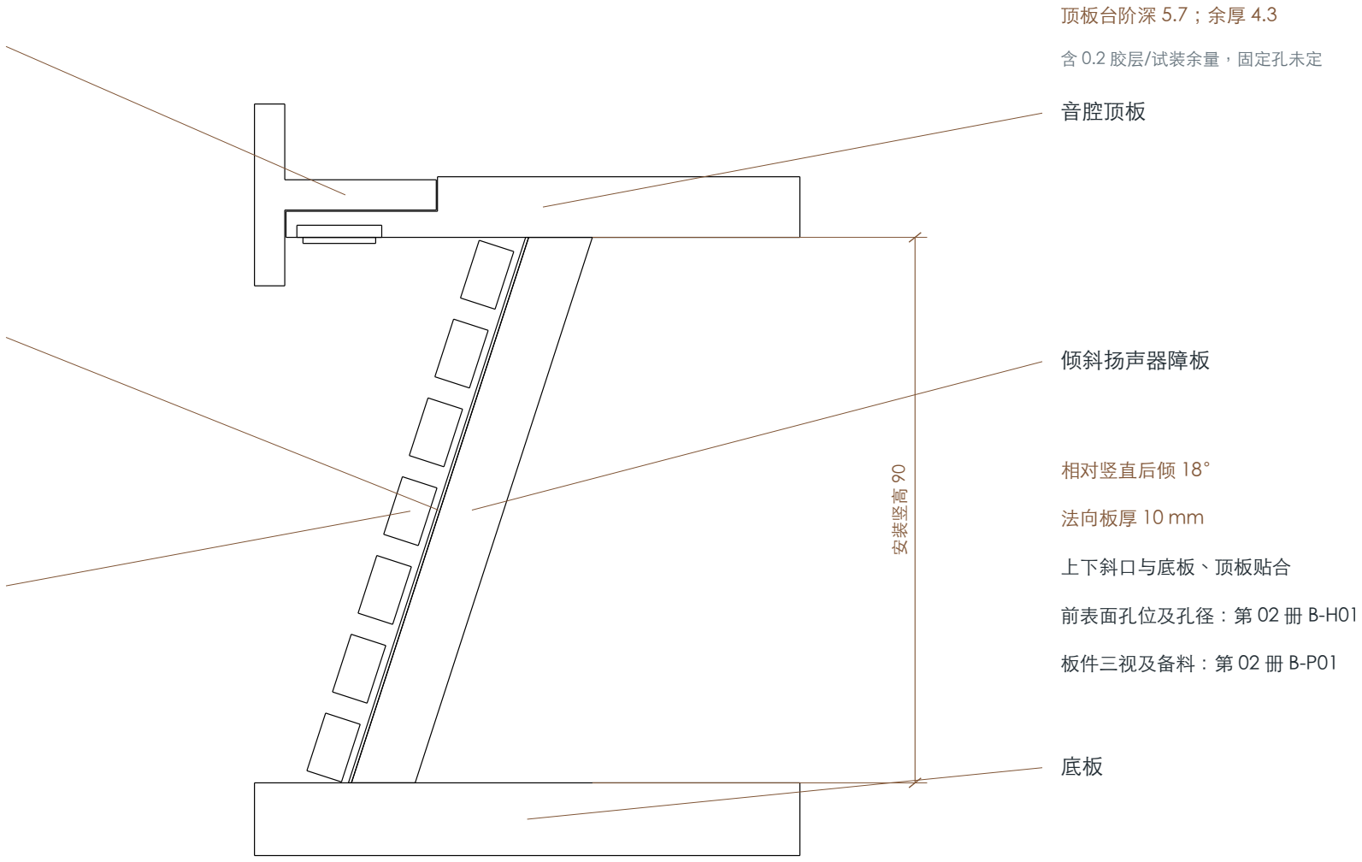
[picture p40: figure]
音腔顶板; 倾斜扬声器障板; 相对竖直后倾 18°; 法向板厚 10 mm; 上下斜口与底板、顶板贴合; 前表面孔位及孔径：第 02 册 B-H01; 板件三视及备料：第 02 册 B-P01; 顶板台阶深 5.7；余厚 4.3; 含 0.2 胶层/试装余量，固定孔未定

现存 CAD 几何尺寸 / 概念与空间核对图；未定义公差、连接工艺和安装孔不作加工放行。 | v0.11-10x6-grille-slats | 2026-09-30 | 05

### 沿 X=225 剖切，从右侧看；+Y 向右（箱内），+Z 向上。比例 1:1。

显示前部 Y=0..90；右端为截断边，不是板件接缝。

### 透声布

### 木格栅

### T 型铝饰条

倾角示意

18°

T 型材 30 × 30 × 5，宽面朝前

本剖面取箱体中线，避开两侧扬声器孔；用于看清格栅、透声布、障板、底板和顶板的相对位置。

木格栅和透声布位于障板前方；闭盖整机图中障板受遮挡，不能从侧板外轮廓判断其倾角。

T 型铝条槽隙为安装假设；本页不放行加工，根部圆角避让、胶层、连接螺孔及紧固工艺待实测。

黑胶唱片机 / 整机与外壳 | A-P01 | A3 横向 | 单位 mm
左侧木板 / 底板 | 尺寸表：长 X / 宽 Y / 高 Z / 厚度

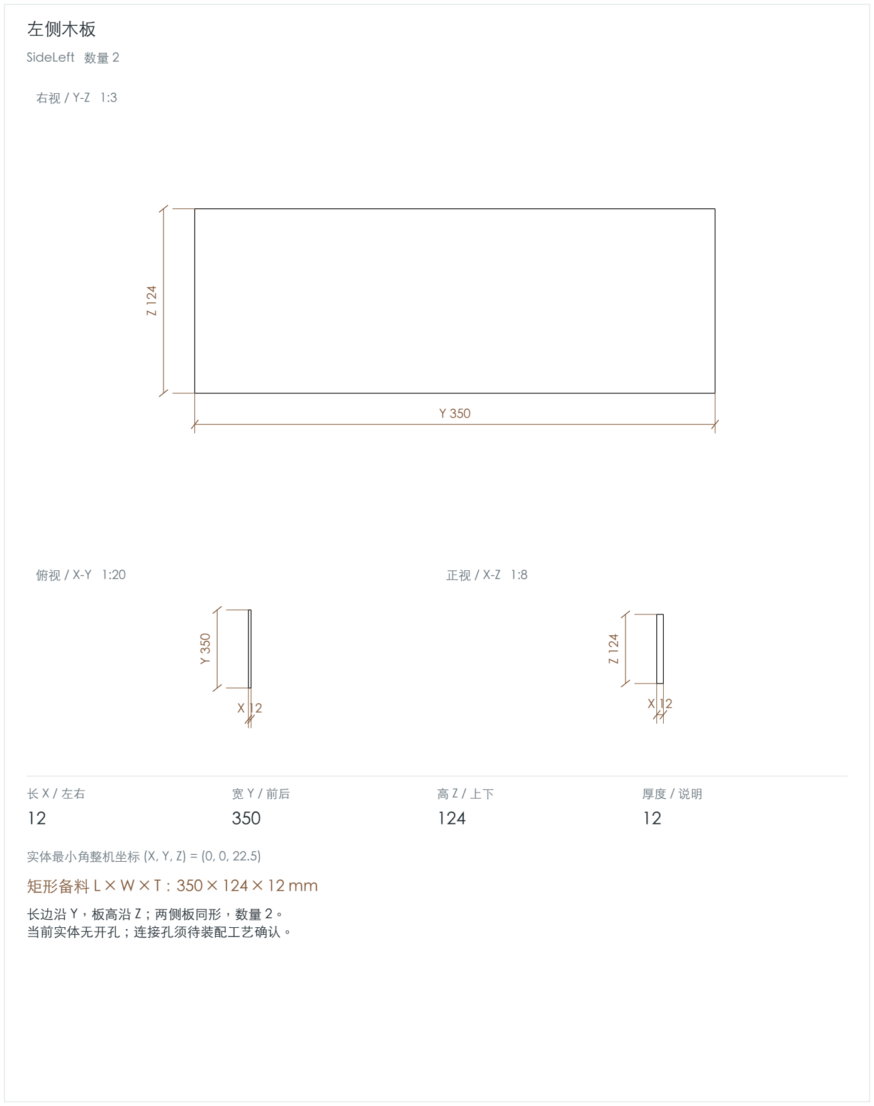
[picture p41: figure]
左侧木板; SideLeft 数量 2; 实体最小角整机坐标 (X, Y, Z) = (0, 0, 22.5); 矩形备料 L × W × T：350 × 124 × 12 mm; 长边沿 Y，板高沿 Z；两侧板同形，数量 2。 当前实体无开孔；连接孔须待装配工艺确认。
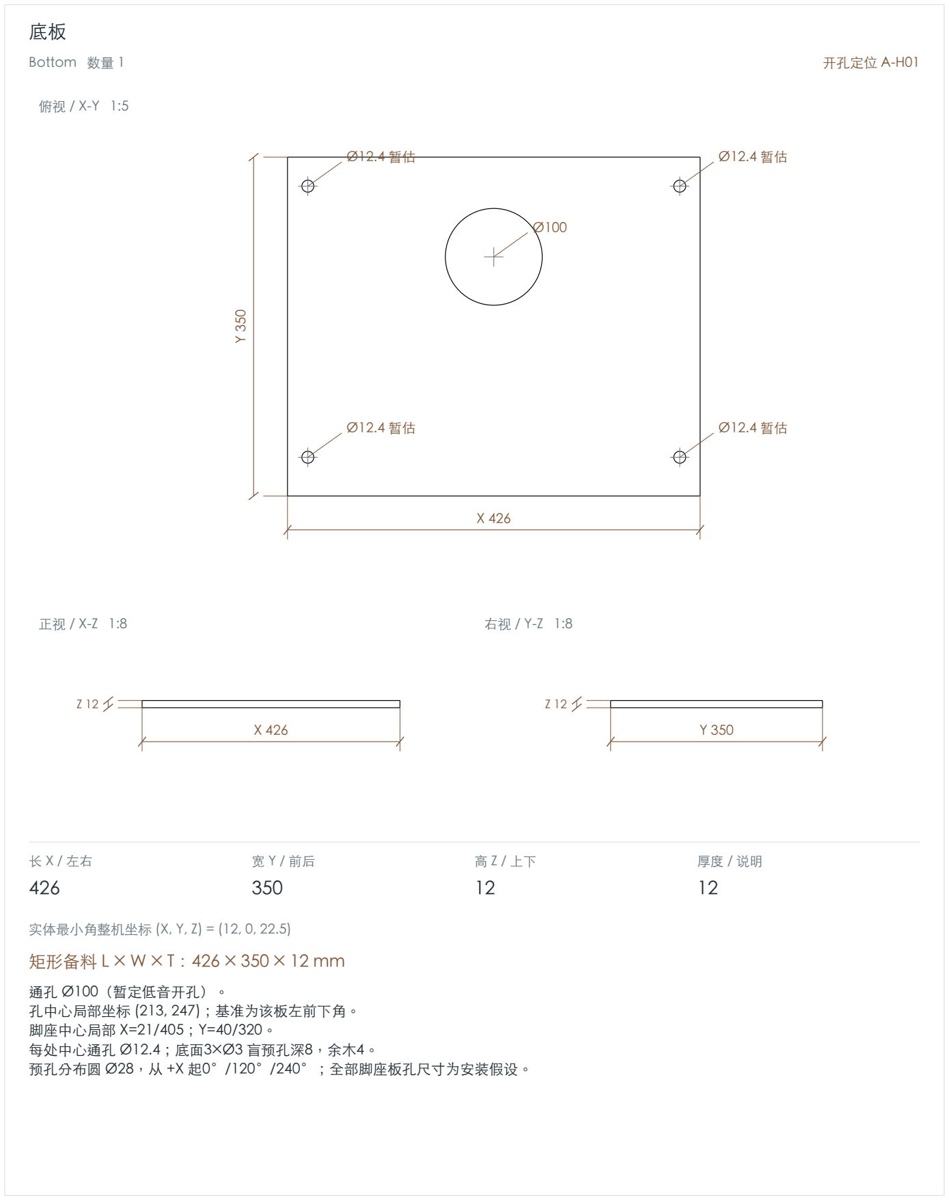
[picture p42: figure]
Bottom 数量 1; 开孔定位 A-H01; 实体最小角整机坐标 (X, Y, Z) = (12, 0, 22.5); 矩形备料 L × W × T：426 × 350 × 12 mm; 通孔 Ø100（暂定低音开孔）。 孔中心局部坐标 (213, 247)；基准为该板左前下角。 脚座中心局部 X=21/405；Y=40/320。 每处中心通孔 Ø12.4；底面3×Ø3 盲预孔深8，余木4。 预孔分布圆 Ø28，从 +X 起0°/120°/240°；全部脚座板孔尺寸为安装假设。

现存 CAD 几何尺寸 / 概念与空间核对图；未定义公差、连接工艺和安装孔不作加工放行。 | v0.11-10x6-grille-slats | 2026-09-30 | 06

黑胶唱片机 / 整机与外壳 | A-P02 | A3 横向 | 单位 mm
后板 / 前沿银色 T 型铝饰条 | 尺寸表：长 X / 宽 Y / 高 Z / 厚度

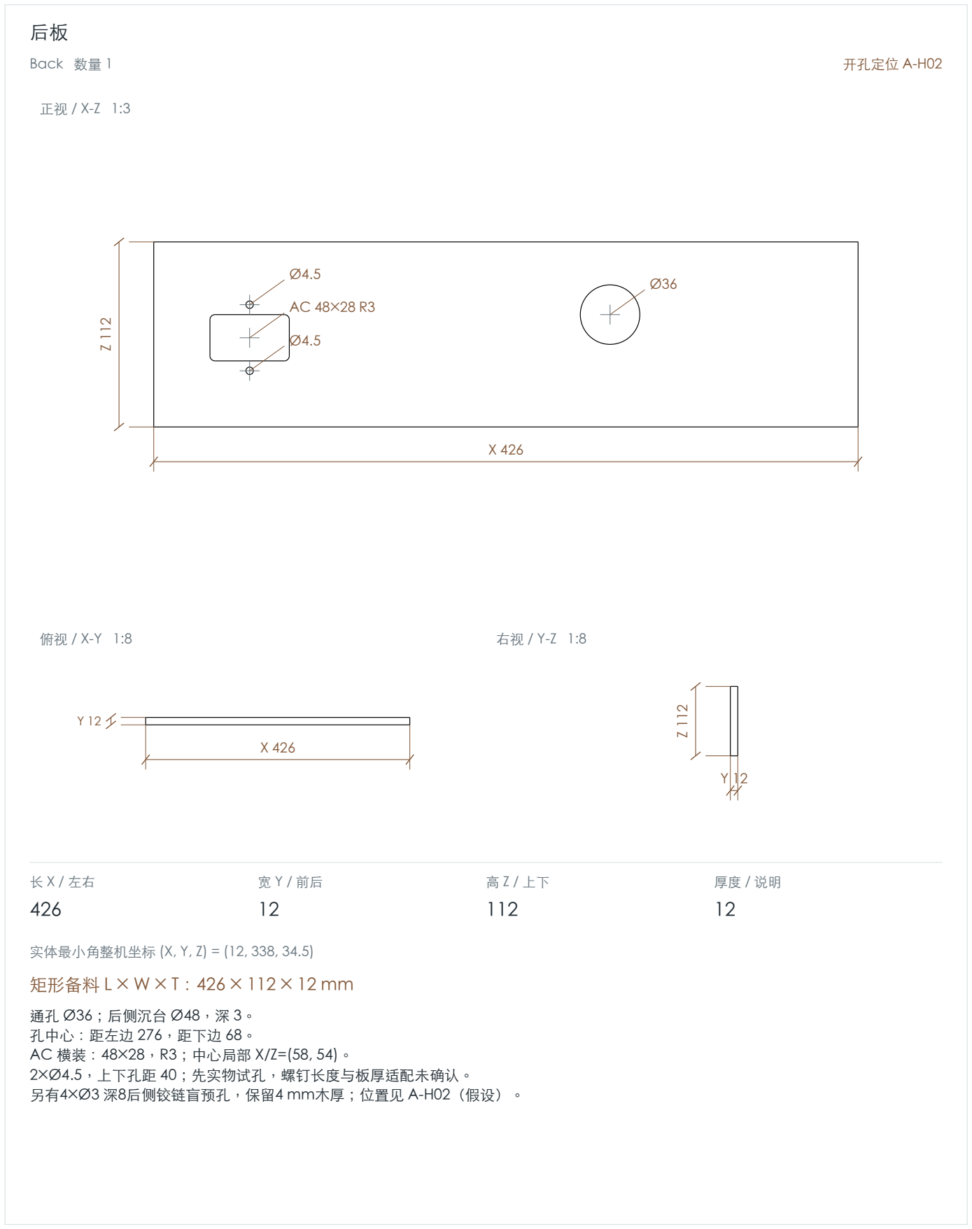
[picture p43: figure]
Back 数量 1; 开孔定位 A-H02; 实体最小角整机坐标 (X, Y, Z) = (12, 338, 34.5); 矩形备料 L × W × T：426 × 112 × 12 mm; 通孔 Ø36；后侧沉台 Ø48，深 3。 孔中心：距左边 276，距下边 68。 AC 横装：48×28，R3；中心局部 X/Z=(58, 54)。 2×Ø4.5，上下孔距 40；先实物试孔，螺钉长度与板厚适配未确认。 另有4×Ø3 深8后侧铰链盲预孔，保留4 mm木厚；位置见 A-H02（假设）。
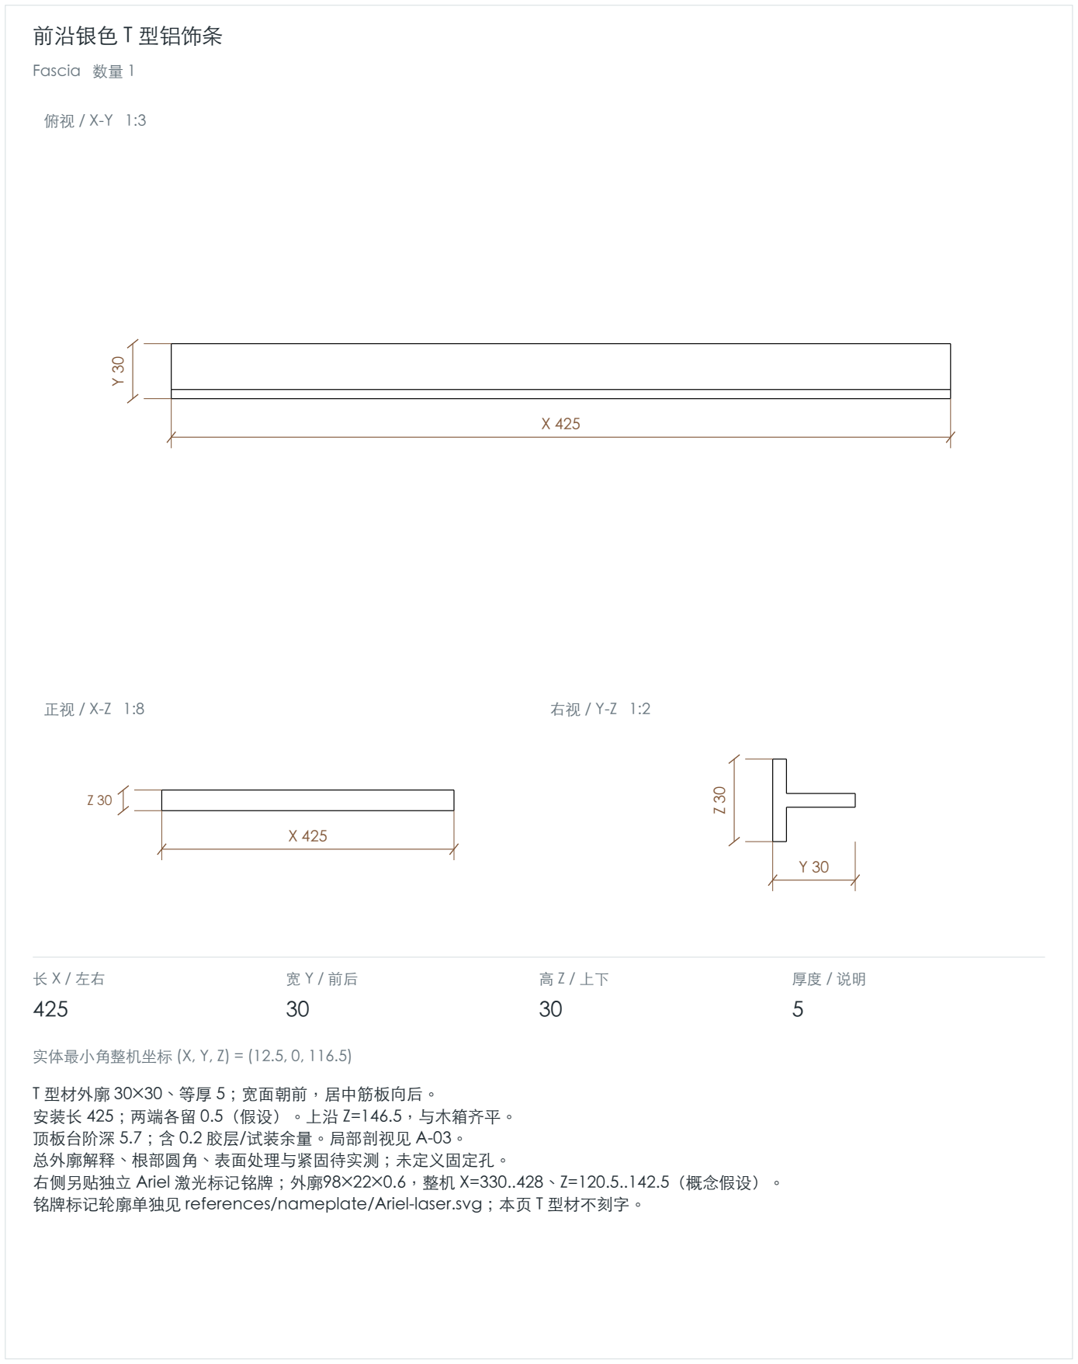
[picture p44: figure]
前沿银色 T 型铝饰条; Fascia 数量 1; 实体最小角整机坐标 (X, Y, Z) = (12.5, 0, 116.5); T 型材外廓 30×30、等厚 5；宽面朝前，居中筋板向后。 安装长 425；两端各留 0.5（假设）。上沿 Z=146.5，与木箱齐平。 顶板台阶深 5.7；含 0.2 胶层/试装余量。局部剖视见 A-03。 总外廓解释、根部圆角、表面处理与紧固待实测；未定义固定孔。

现存 CAD 几何尺寸 / 概念与空间核对图；未定义公差、连接工艺和安装孔不作加工放行。 | v0.11-10x6-grille-slats | 2026-09-30 | 07

右侧另贴独立 Ariel 激光标记铭牌；外廓98×22×0.6，整机 X=330..428、Z=120.5..142.5（概念假设）。 铭牌标记轮廓单独见 references/nameplate/Ariel-laser.svg；本页 T 型材不刻字。

黑胶唱片机 / 整机与外壳 | A-P03 | A3 横向 | 单位 mm
透声布外观占位（非实心材料） | 尺寸表：长 X / 宽 Y / 高 Z / 厚度

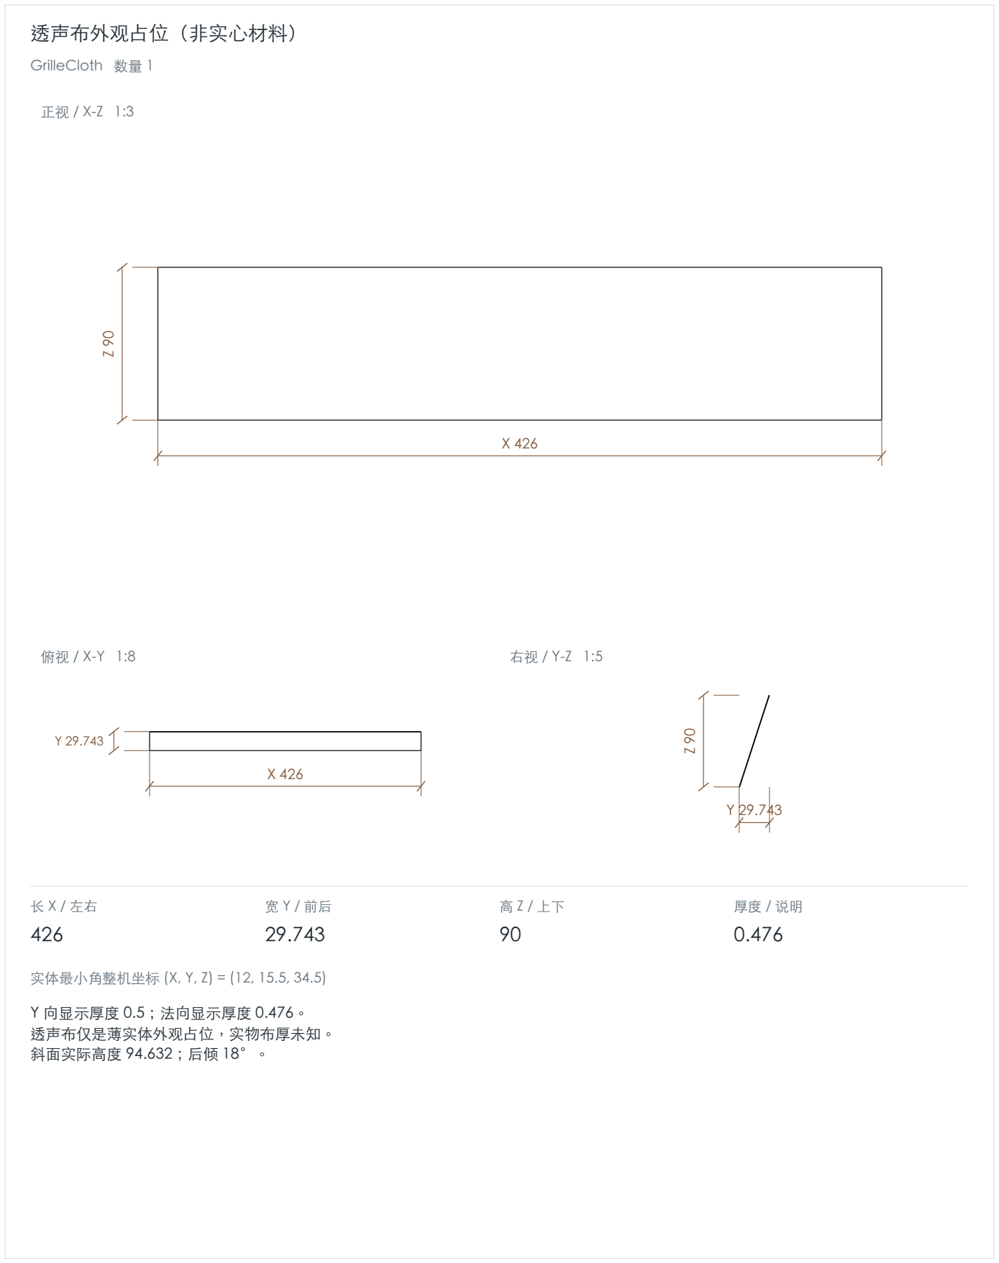
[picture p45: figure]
透声布外观占位（非实心材料）; GrilleCloth 数量 1; 实体最小角整机坐标 (X, Y, Z) = (12, 15.5, 34.5); Y 向显示厚度 0.5；法向显示厚度 0.476。 透声布仅是薄实体外观占位，实物布厚未知。 斜面实际高度 94.632；后倾 18°。

现存 CAD 几何尺寸 / 概念与空间核对图；未定义公差、连接工艺和安装孔不作加工放行。 | v0.11-10x6-grille-slats | 2026-09-30 | 08

# 底板前沿一体保留

### 前沿属于完整底板，不另列备料或装配件。底板尺寸见 A-P01，开孔定位见 A-H01。

黑胶唱片机 / 整机与外壳 | A-P04 | A3 横向 | 单位 mm
横向木格栅 01 / 灯带铝槽占位 | 尺寸表：长 X / 宽 Y / 高 Z / 厚度

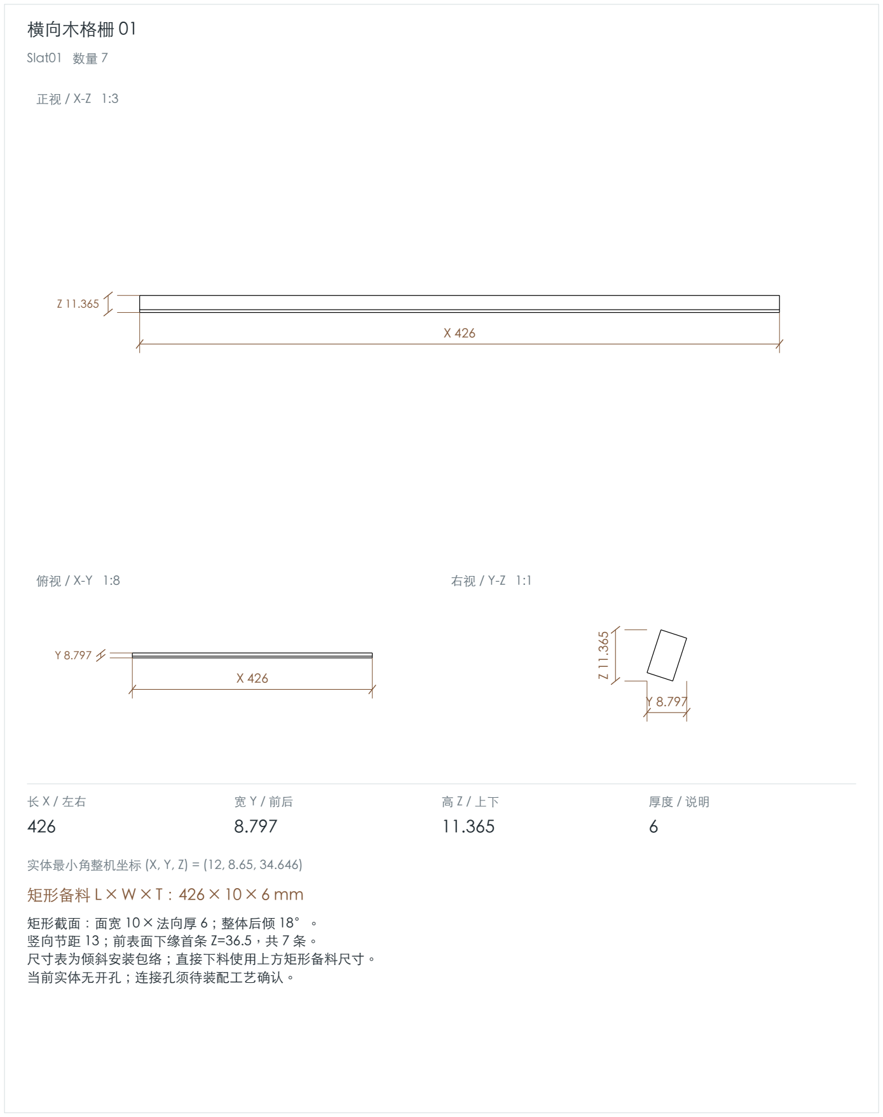
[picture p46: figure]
横向木格栅 01; Slat01 数量 7; 矩形备料 L × W × T：426 × 10 × 6 mm; 矩形截面：面宽 10 × 法向厚 6；整体后倾 18°。 竖向节距 13；前表面下缘首条 Z=36.5，共 7 条。 尺寸表为倾斜安装包络；直接下料使用上方矩形备料尺寸。 当前实体无开孔；连接孔须待装配工艺确认。
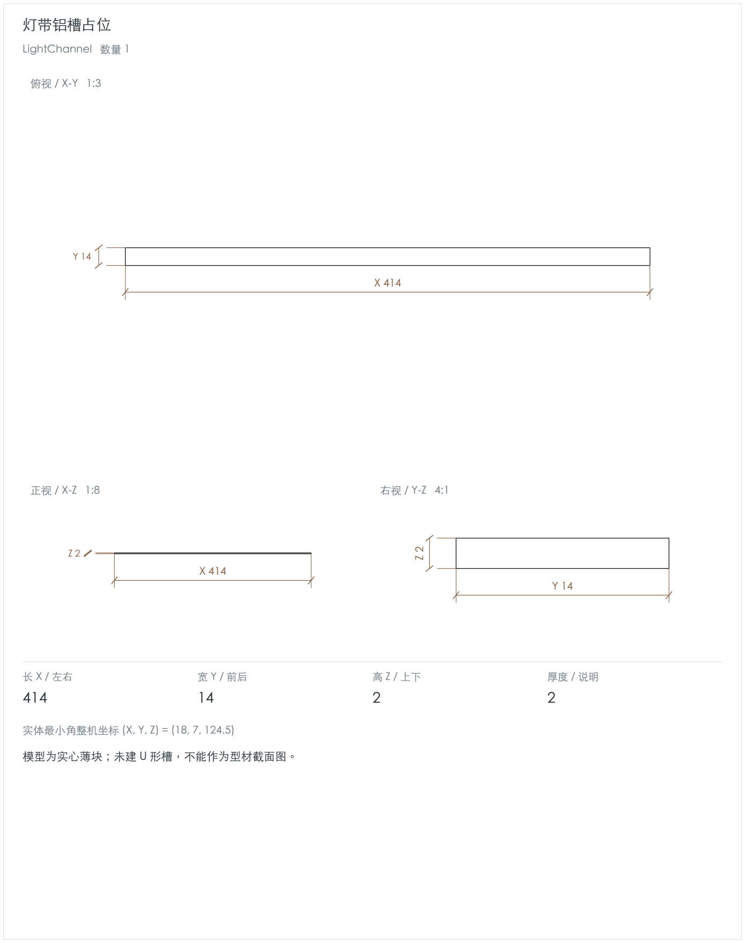
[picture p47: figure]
灯带铝槽占位; LightChannel 数量 1; 实体最小角整机坐标 (X, Y, Z) = (18, 7, 124.5); 模型为实心薄块；未建 U 形槽，不能作为型材截面图。

现存 CAD 几何尺寸 / 概念与空间核对图；未定义公差、连接工艺和安装孔不作加工放行。 | v0.11-10x6-grille-slats | 2026-09-30 | 09

实体最小角整机坐标 (X, Y, Z) = (12, 8.65, 34.646)

黑胶唱片机 / 整机与外壳 | A-P05 | A3 横向 | 单位 mm
3000 K 暖光扩散片 / 烟灰透明防尘盖 | 尺寸表：长 X / 宽 Y / 高 Z / 厚度

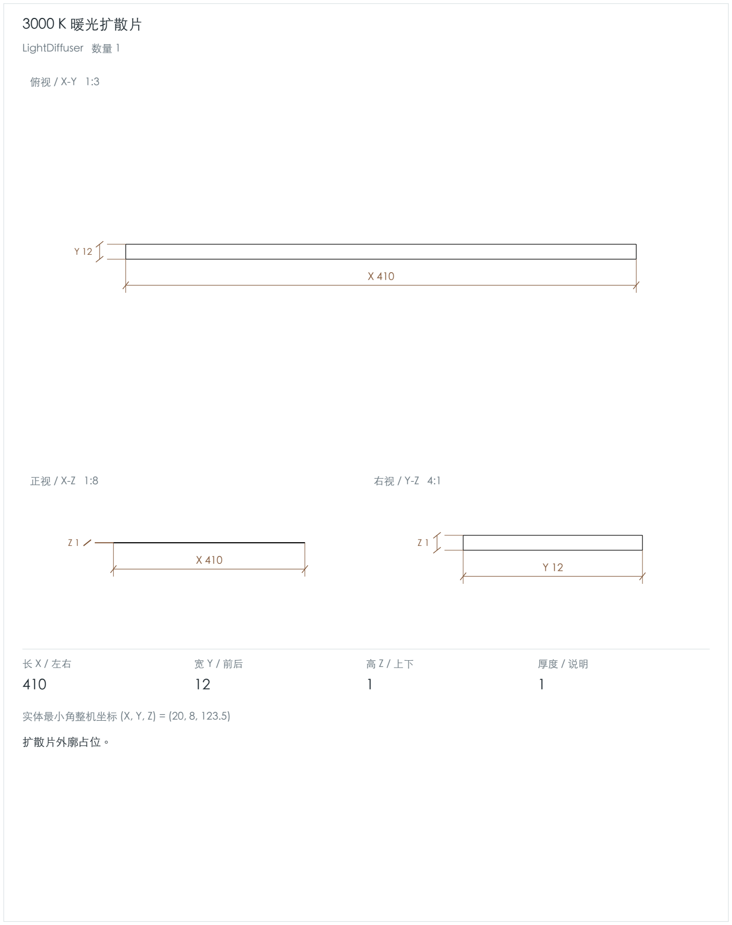
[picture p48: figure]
3000 K 暖光扩散片; LightDiffuser 数量 1; 实体最小角整机坐标 (X, Y, Z) = (20, 8, 123.5); 扩散片外廓占位。
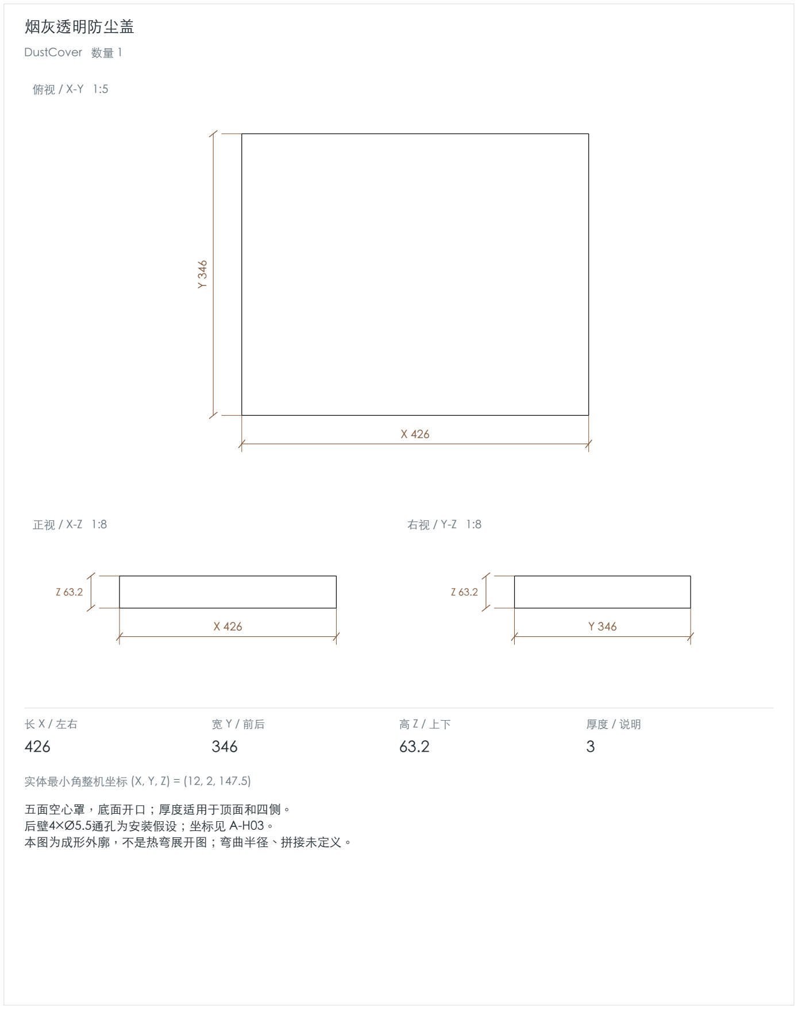
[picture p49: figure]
烟灰透明防尘盖; DustCover 数量 1; 实体最小角整机坐标 (X, Y, Z) = (12, 2, 147.5); 五面空心罩，底面开口；厚度适用于顶面和四侧。 后壁4×Ø5.5通孔为安装假设；坐标见 A-H03。 本图为成形外廓，不是热弯展开图；弯曲半径、拼接未定义。

现存 CAD 几何尺寸 / 概念与空间核对图；未定义公差、连接工艺和安装孔不作加工放行。 | v0.11-10x6-grille-slats | 2026-09-30 | 10

黑胶唱片机 / 整机与外壳 | A-P06 | A3 横向 | 单位 mm
定位合页固定叶 1 / 定位合页活动叶及轴筒 1 | 尺寸表：长 X / 宽 Y / 高 Z / 厚度

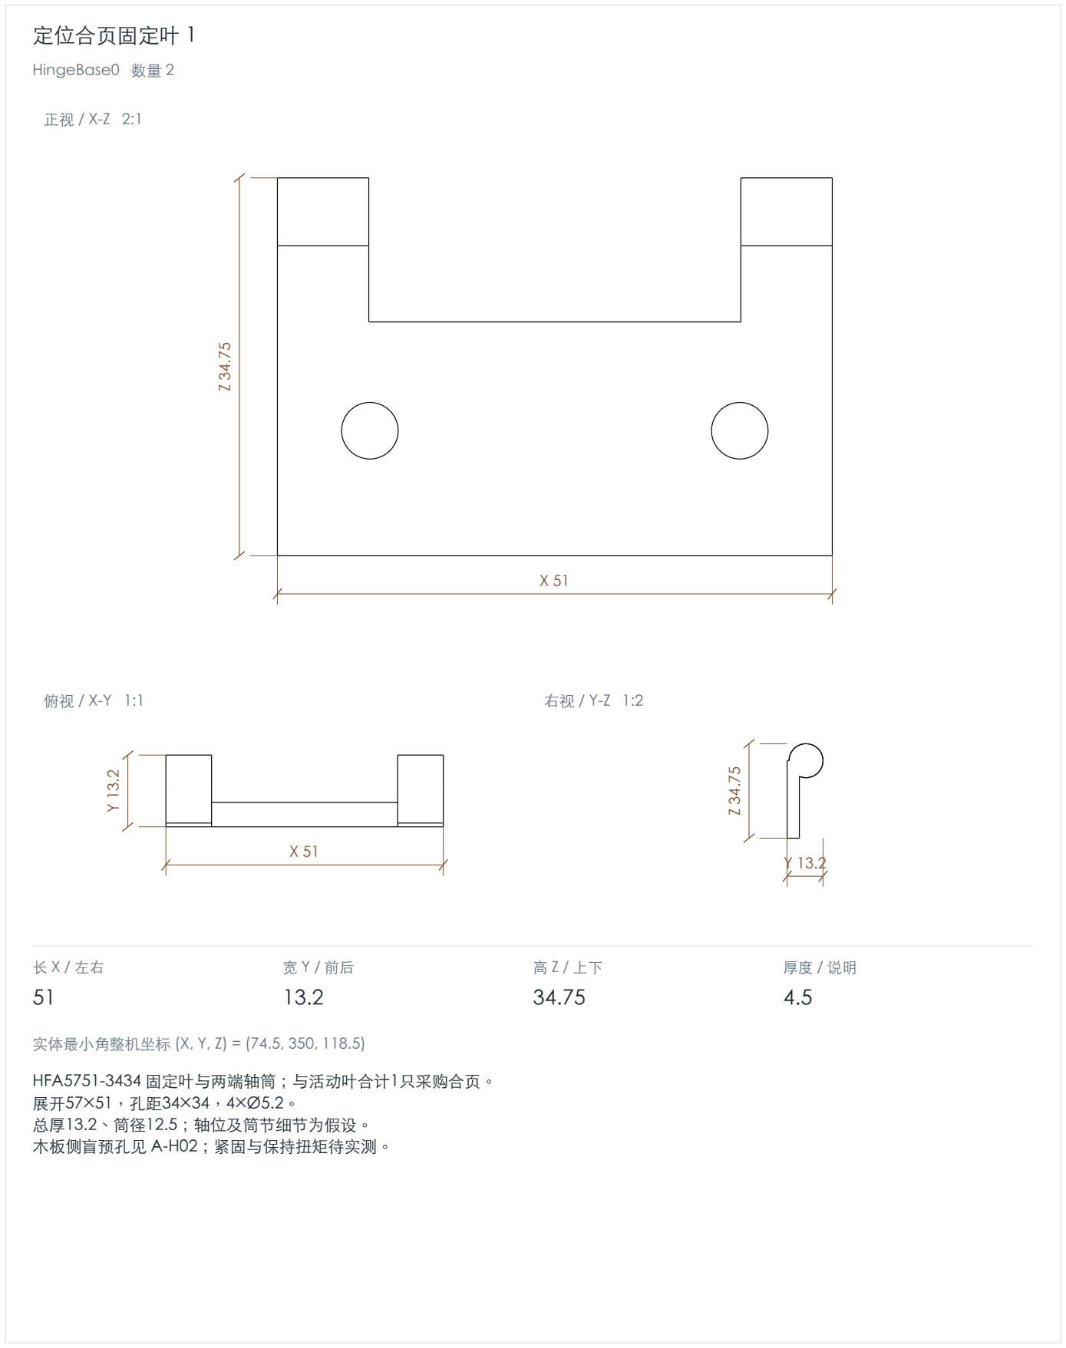
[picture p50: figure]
定位合页固定叶 1; HingeBase0 数量 2; HFA5751-3434 固定叶与两端轴筒；与活动叶合计1只采购合页。 展开57×51，孔距34×34，4×Ø5.2。 总厚13.2、筒径12.5；轴位及筒节细节为假设。 木板侧盲预孔见 A-H02；紧固与保持扭矩待实测。
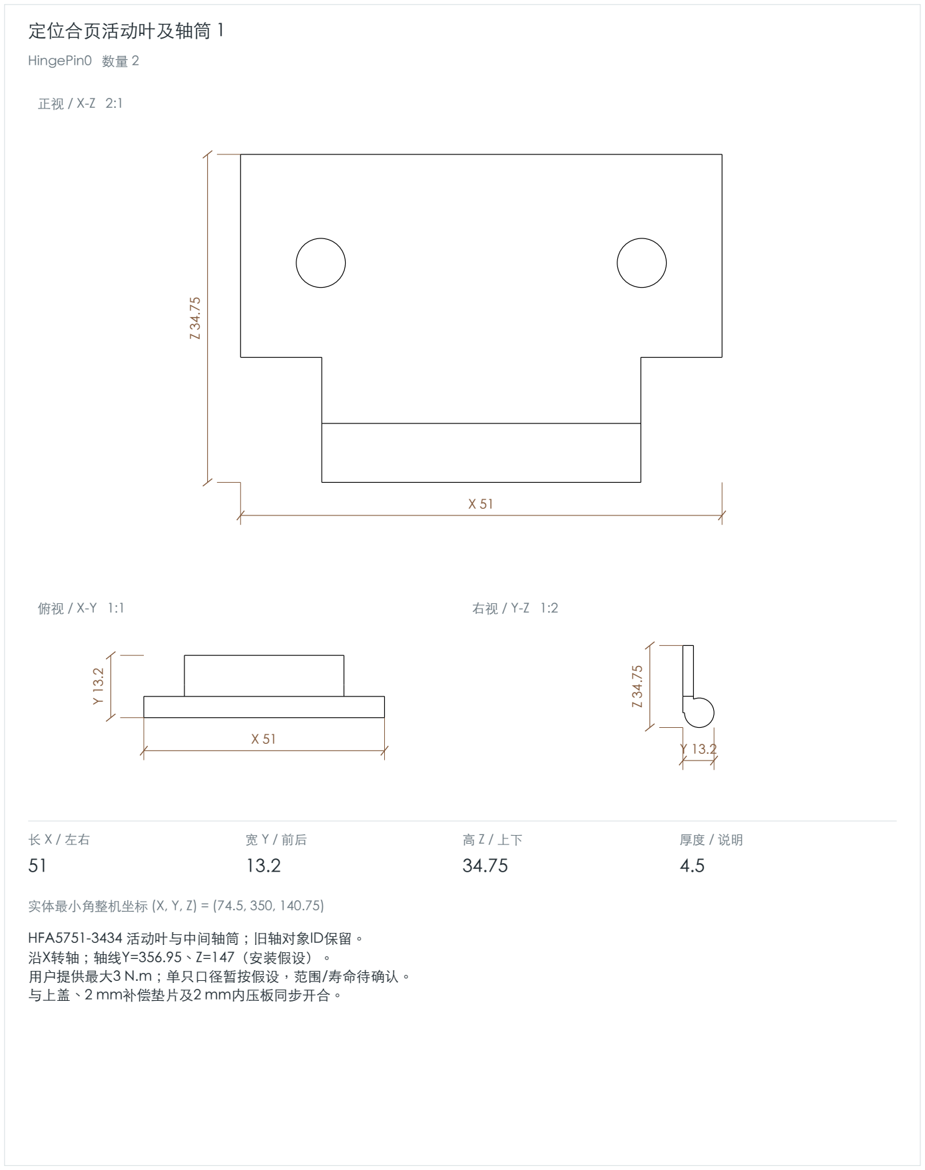
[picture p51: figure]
定位合页活动叶及轴筒 1; HingePin0 数量 2; HFA5751-3434 活动叶与中间轴筒；旧轴对象ID保留。 沿X转轴；轴线Y=356.95、Z=147（安装假设）。 用户提供最大3 N.m；单只口径暂按假设，范围/寿命待确认。 与上盖、2 mm补偿垫片及2 mm内压板同步开合。

现存 CAD 几何尺寸 / 概念与空间核对图；未定义公差、连接工艺和安装孔不作加工放行。 | v0.11-10x6-grille-slats | 2026-09-30 | 11

实体最小角整机坐标 (X, Y, Z) = (74.5, 350, 118.5)

实体最小角整机坐标 (X, Y, Z) = (74.5, 350, 140.75)

黑胶唱片机 / 整机与外壳 | A-P07 | A3 横向 | 单位 mm
VE 橡胶脚垫与 M8 螺杆 1 / M8 脚垫固定座 1 | 尺寸表：长 X / 宽 Y / 高 Z / 厚度

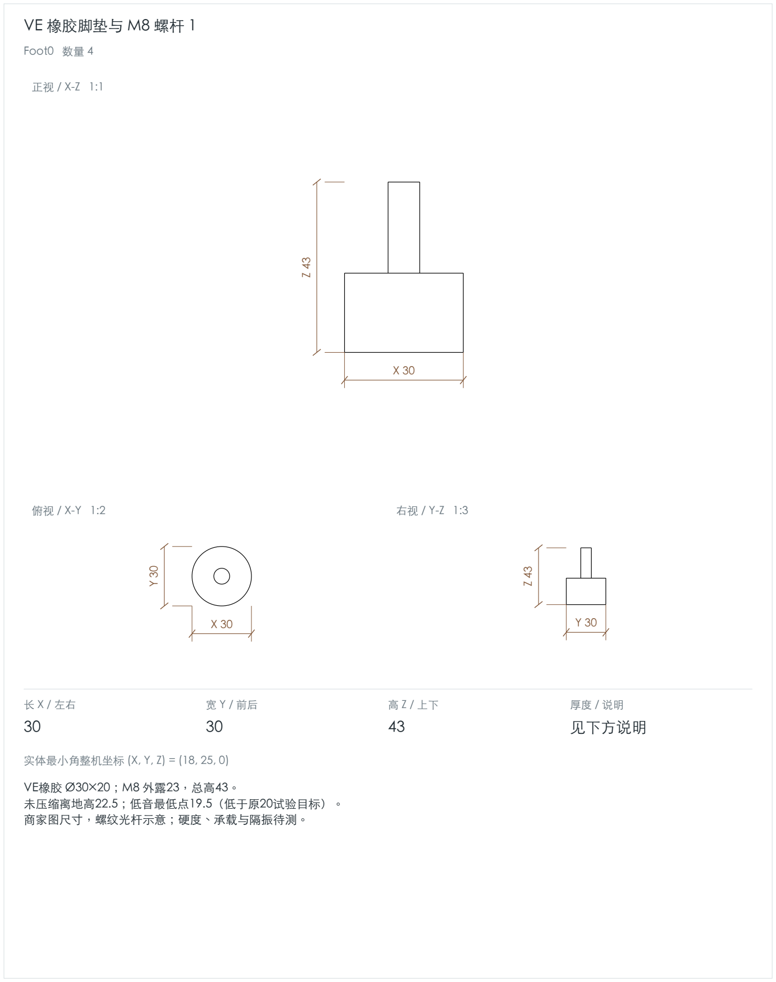
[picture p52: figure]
VE 橡胶脚垫与 M8 螺杆 1; Foot0 数量 4; 厚度 / 说明 见下方说明; 实体最小角整机坐标 (X, Y, Z) = (18, 25, 0); VE橡胶 Ø30×20；M8 外露23，总高43。 未压缩离地高22.5；低音最低点19.5（低于原20试验目标）。 商家图尺寸，螺纹光杆示意；硬度、承载与隔振待测。
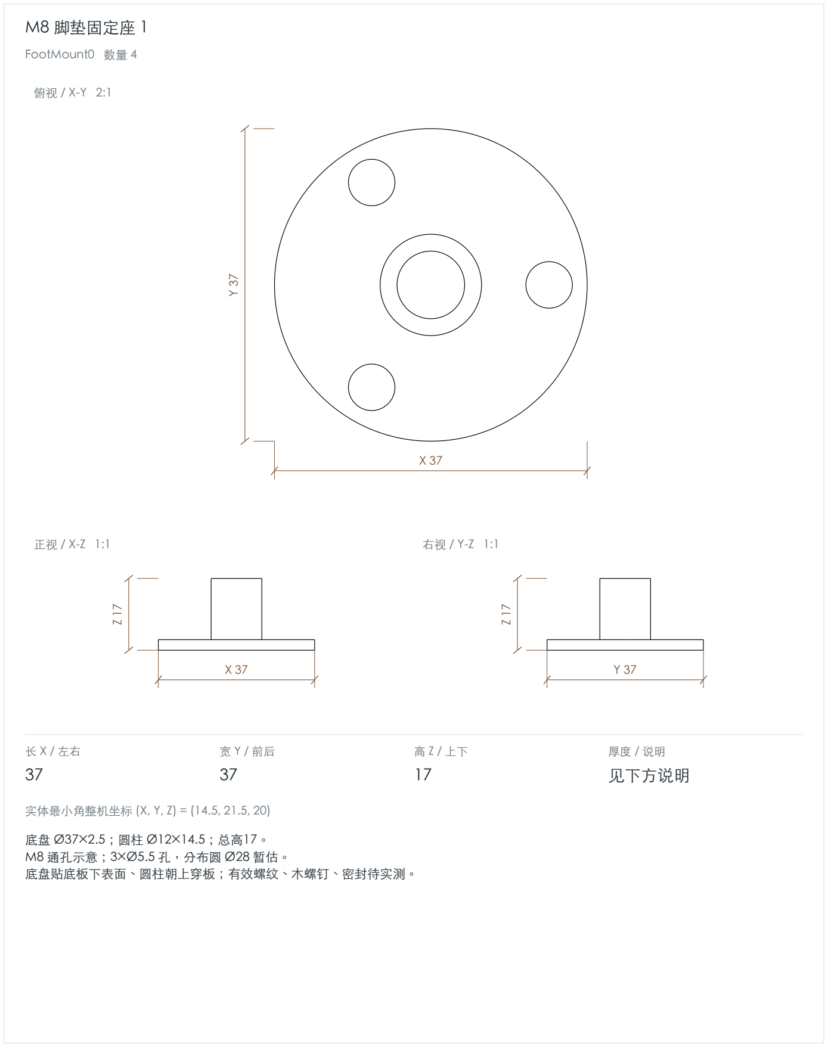
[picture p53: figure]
M8 脚垫固定座 1; FootMount0 数量 4; 厚度 / 说明 见下方说明; 实体最小角整机坐标 (X, Y, Z) = (14.5, 21.5, 20); 底盘 Ø37×2.5；圆柱 Ø12×14.5；总高17。 M8 通孔示意；3×Ø5.5 孔，分布圆 Ø28 暂估。 底盘贴底板下表面、圆柱朝上穿板；有效螺纹、木螺钉、密封待实测。

现存 CAD 几何尺寸 / 概念与空间核对图；未定义公差、连接工艺和安装孔不作加工放行。 | v0.11-10x6-grille-slats | 2026-09-30 | 12

黑胶唱片机 / 整机与外壳 | A-P08 | A3 横向 | 单位 mm
合页上盖补偿垫片 1 / 亚克力内侧压板 1 | 尺寸表：长 X / 宽 Y / 高 Z / 厚度

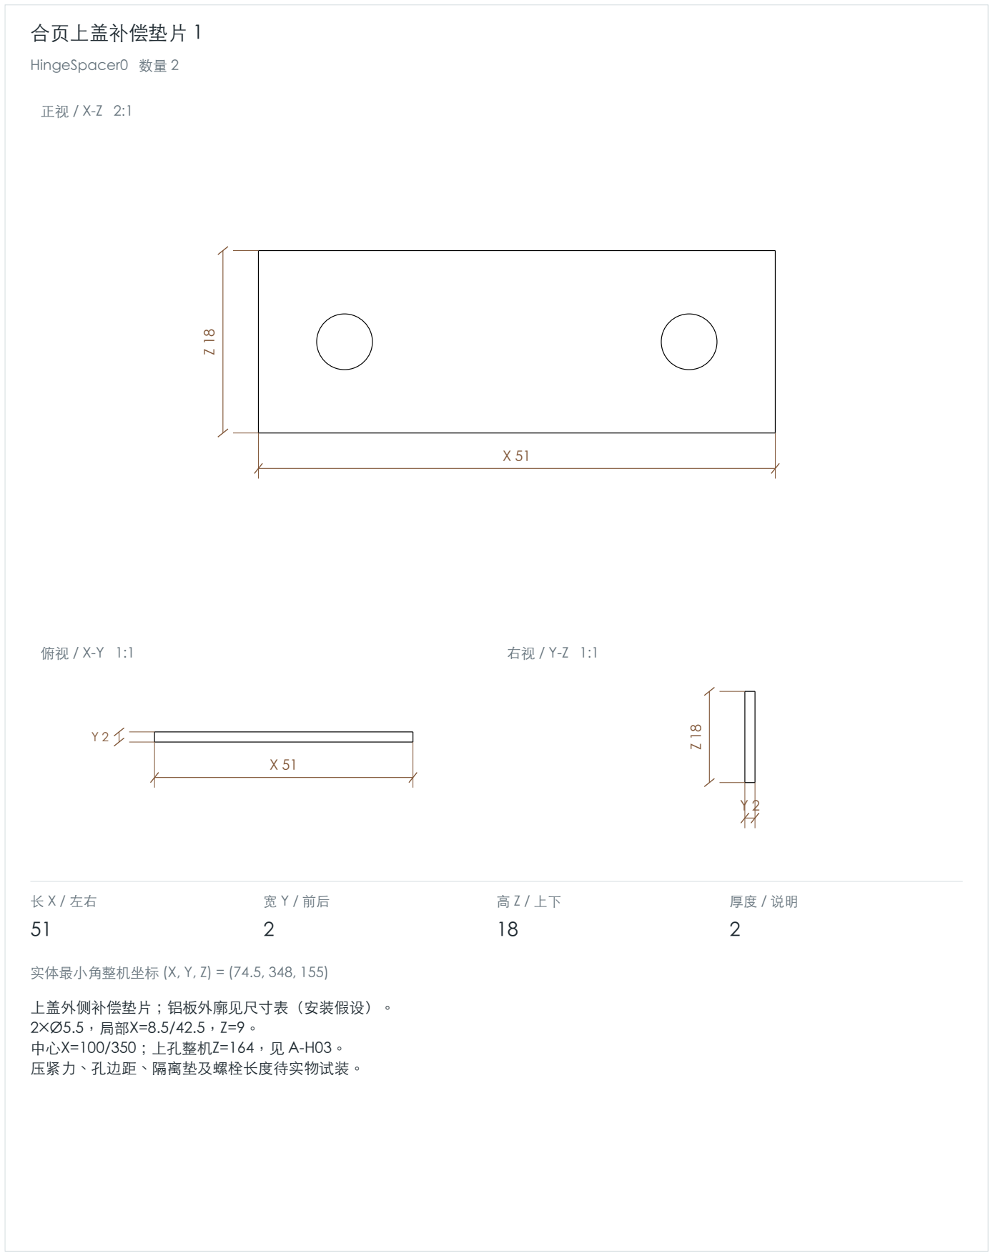
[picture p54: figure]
合页上盖补偿垫片 1; HingeSpacer0 数量 2; 实体最小角整机坐标 (X, Y, Z) = (74.5, 348, 155); 上盖外侧补偿垫片；铝板外廓见尺寸表（安装假设）。 2×Ø5.5，局部X=8.5/42.5，Z=9。 中心X=100/350；上孔整机Z=164，见 A-H03。 压紧力、孔边距、隔离垫及螺栓长度待实物试装。
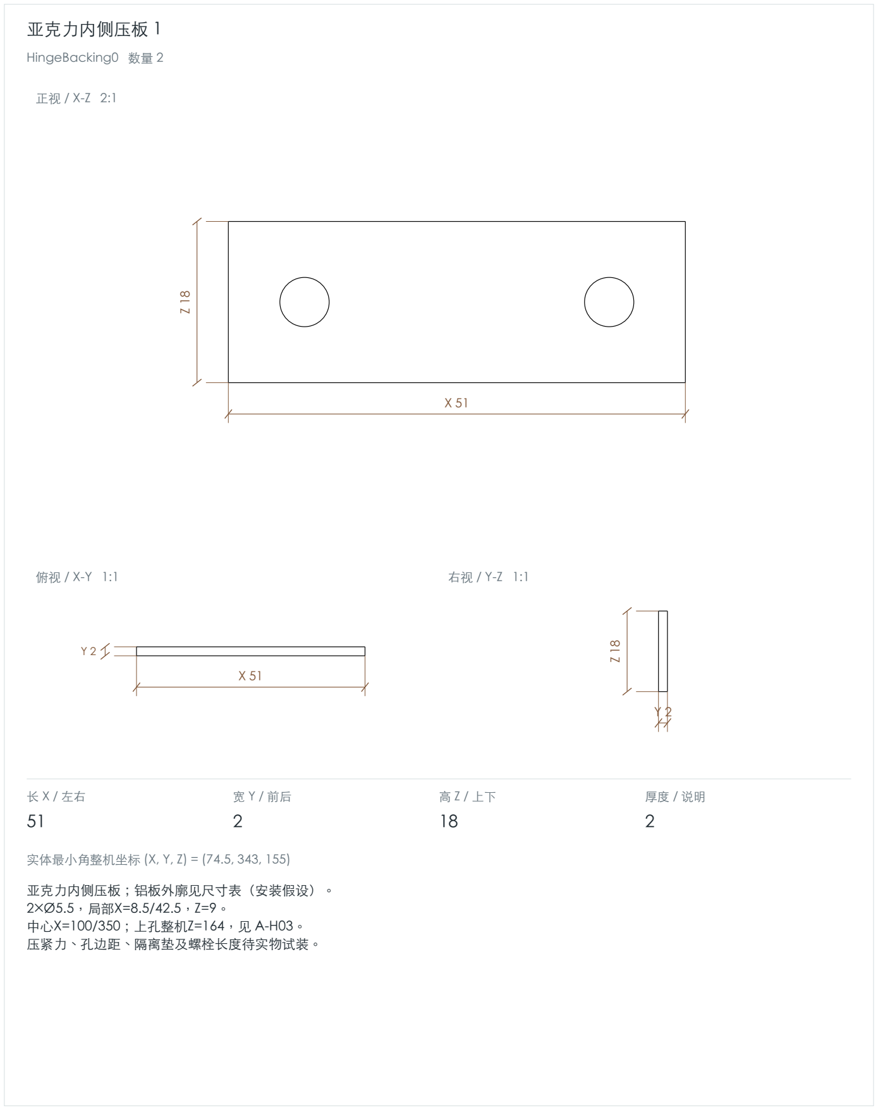
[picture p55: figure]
亚克力内侧压板 1; HingeBacking0 数量 2; 实体最小角整机坐标 (X, Y, Z) = (74.5, 343, 155); 亚克力内侧压板；铝板外廓见尺寸表（安装假设）。 2×Ø5.5，局部X=8.5/42.5，Z=9。 中心X=100/350；上孔整机Z=164，见 A-H03。 压紧力、孔边距、隔离垫及螺栓长度待实物试装。

现存 CAD 几何尺寸 / 概念与空间核对图；未定义公差、连接工艺和安装孔不作加工放行。 | v0.11-10x6-grille-slats | 2026-09-30 | 13

黑胶唱片机 / 整机与外壳 | A-H01 | A3 横向 | 单位 mm
底板 / 通孔与底面盲预孔 | 成形边为定位基准 / 孔轴心坐标 / 单位 mm

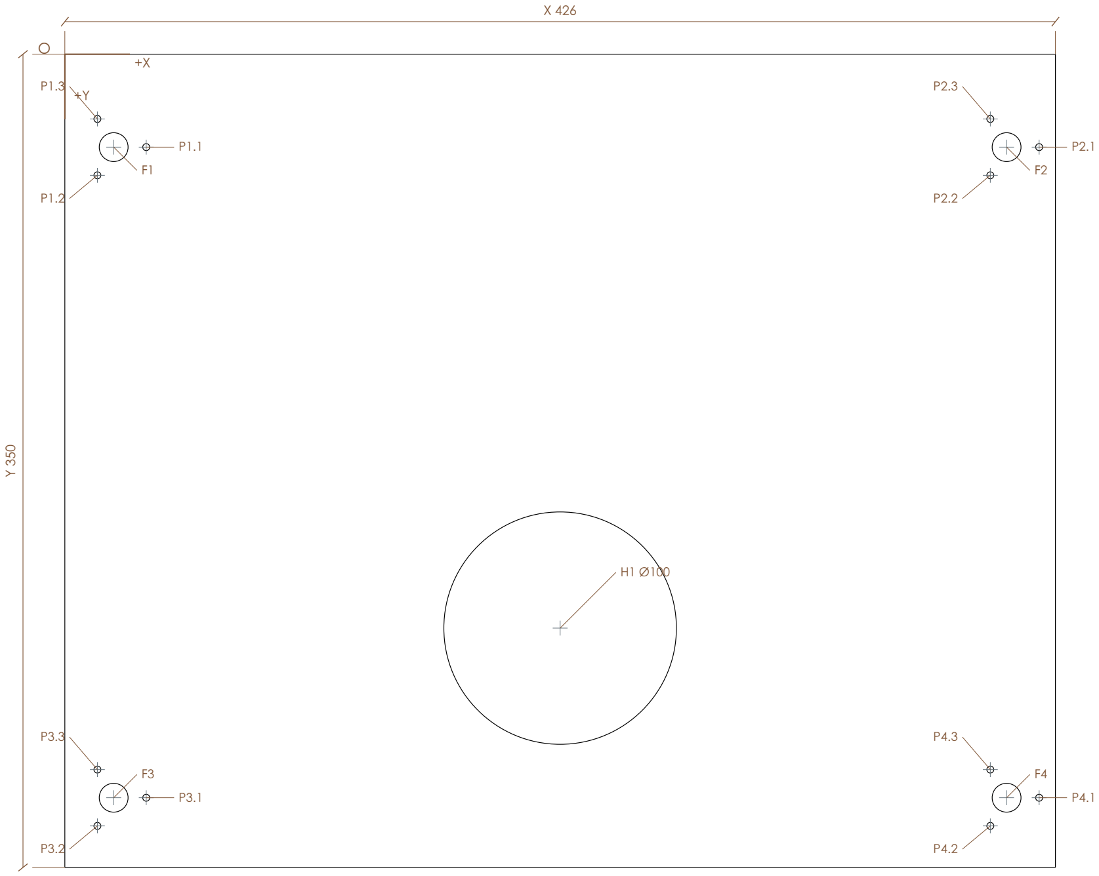
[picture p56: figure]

现存 CAD 几何尺寸 / 概念与空间核对图；未定义公差、连接工艺和安装孔不作加工放行。 | v0.11-10x6-grille-slats | 2026-09-30 | 14

### 底面仰视 1:2 / 板厚 12

## 孔表 / 从 O 量至孔轴心

编号 | X | Y | 孔形 / 尺寸
H1 | 213 | 247 | Ø100 通
F1 | 21 | 40 | Ø12.4 通
F2 | 405 | 40 | Ø12.4 通
F3 | 21 | 320 | Ø12.4 通
F4 | 405 | 320 | Ø12.4 通
P1.1 | 35 | 40 | Ø3 深8
P1.2 | 14 | 52.124 | Ø3 深8
P1.3 | 14 | 27.876 | Ø3 深8
P2.1 | 419 | 40 | Ø3 深8
P2.2 | 398 | 52.124 | Ø3 深8
P2.3 | 398 | 27.876 | Ø3 深8
P3.1 | 35 | 320 | Ø3 深8
P3.2 | 14 | 332.124 | Ø3 深8
P3.3 | 14 | 307.876 | Ø3 深8
P4.1 | 419 | 320 | Ø3 深8
P4.2 | 398 | 332.124 | Ø3 深8
P4.3 | 398 | 307.876 | Ø3 深8

通 = 贯通；深 = 从指定加工面量取。

从桌面向上看底面；图左上角 O 对应板件左前角。+X 向右，+Y 向下；孔表 Y 从前边量取。

H1：低音通孔（暂定）。F1-F4：脚座通孔；P 为底面盲预孔，深 8，剩余木厚 4。

每组 P 绕同号 F 分布于 Ø28 圆上，角度从 +X 朝 +Y 为 0°/120°/240°；脚座孔均为安装假设。

功放、变压器及其他固定螺孔尚未建模，须实物确认后另行定位；不能按本图推定这些孔位。

黑胶唱片机 / 整机与外壳 | A-H02 | A3 横向 | 单位 mm
后板 / 倒相、AC 与铰链盲预孔 | 成形边为定位基准 / 孔轴心坐标 / 单位 mm

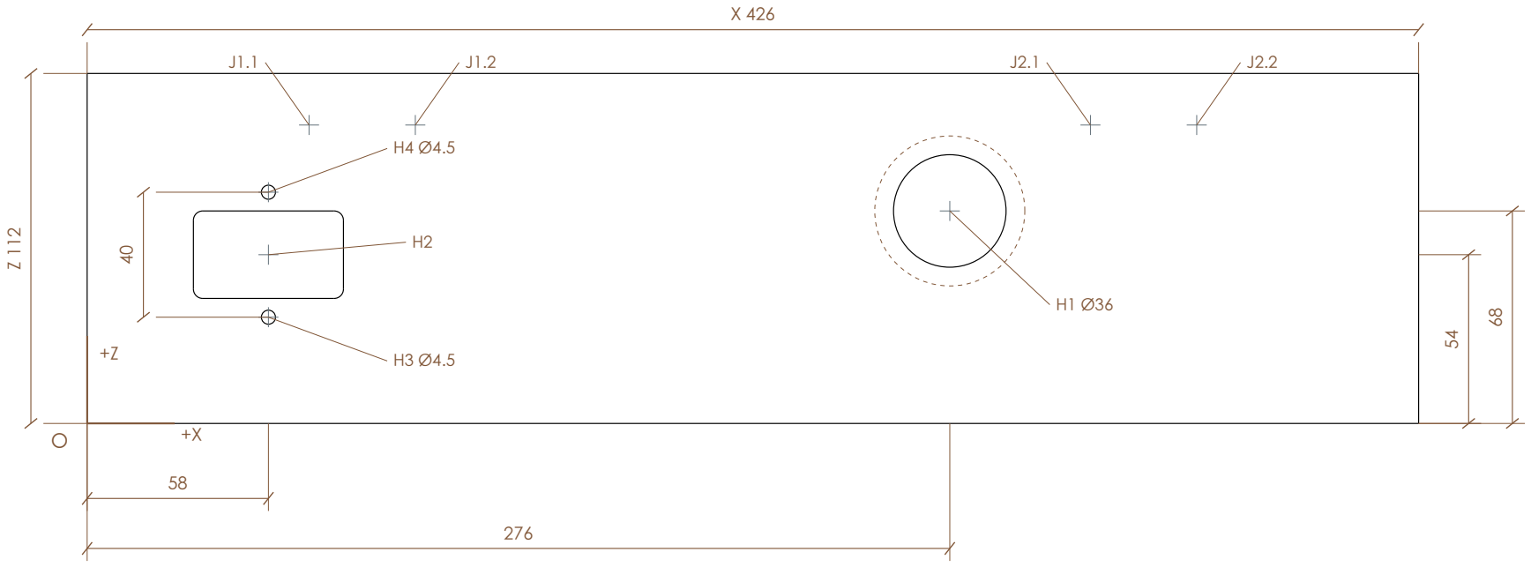
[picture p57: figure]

现存 CAD 几何尺寸 / 概念与空间核对图；未定义公差、连接工艺和安装孔不作加工放行。 | v0.11-10x6-grille-slats | 2026-09-30 | 15

### 箱内向后看 1:2 / 板厚 12

## 孔表 / 从 O 量至孔轴心

编号 | X | Z | 孔形 / 尺寸
H1 | 276 | 68 | Ø36 通
H2 | 58 | 54 | 48×28 R3 通
H3 | 58 | 34 | Ø4.5 通
H4 | 58 | 74 | Ø4.5 通
J1.1 | 71 | 95.5 | Ø3 深8
J1.2 | 105 | 95.5 | Ø3 深8
J2.1 | 321 | 95.5 | Ø3 深8
J2.2 | 355 | 95.5 | Ø3 深8

H1 后侧同心沉台：Ø48，深 3。

通 = 贯通；深 = 从指定加工面量取。

主图从箱内向后看（+X 向右）；O 为后板左下角。后侧沉台以虚线叠画，保持与正面相同坐标，勿镜像孔位。

H1 同心沉台：从箱外后侧加工 Ø48，深 3；通孔与沉台轴心相同。

H2 横向圆角通孔；H3/H4 上下孔距 40。H2 左下角 = (34, 40)。

J为箱外后侧铰链盲预孔，深8，余木4；孔径、深度为安装假设。AC与铰链须实物试装。

黑胶唱片机 / 整机与外壳 | A-H03 | A3 横向 | 单位 mm
防尘盖后壁 / 合页安装孔 | 成形边为定位基准 / 孔轴心坐标 / 单位 mm

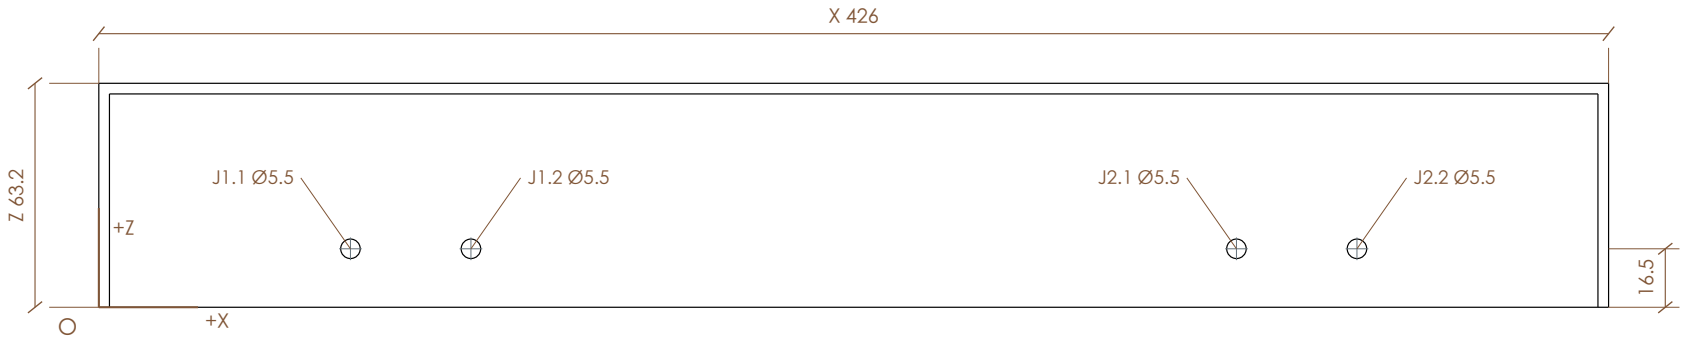
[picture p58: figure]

现存 CAD 几何尺寸 / 概念与空间核对图；未定义公差、连接工艺和安装孔不作加工放行。 | v0.11-10x6-grille-slats | 2026-09-30 | 16

### 罩内向后看 1:2 / 板厚 3

## 孔表 / 从 O 量至孔轴心

编号 | X | Z | 孔形 / 尺寸
J1.1 | 71 | 16.5 | Ø5.5 通
J1.2 | 105 | 16.5 | Ø5.5 通
J2.1 | 321 | 16.5 | Ø5.5 通
J2.2 | 355 | 16.5 | Ø5.5 通

通 = 贯通；深 = 从指定加工面量取。

从罩内向后看；O 为后壁左下角；孔仅贯穿后壁，不能贯穿前壁。尺寸为安装假设。

每只合页两孔横距34；孔心距后壁下边16.5。同轴配合外侧2 mm垫片与内侧2 mm压板。

垫片／压板外廓51×18，厚度分别为2/2；局部孔心(8.5,9)/(42.5,9)，见 A-P08。

保持同轴，勿强行夹紧亚克力；孔边加工与紧固力须试装确认。

M5仅作拟用螺栓规格；螺栓长度、垫圈、孔隙、孔边加工与紧固力须试装确认。未放行加工。

黑胶唱片机 / 整机与外壳 | A-POS | A3 横向 | 单位 mm
同形零件安装位置表 | 同形代表件的各安装位置 / 单位 mm
现存 CAD 几何尺寸 / 概念与空间核对图；未定义公差、连接工艺和安装孔不作加工放行。 | v0.11-10x6-grille-slats | 2026-09-30 | 17

### 坐标为每个对象精确外包络的最小角；圆柱的坐标是包络角，不是轴心。

对象 ID | 零件 | X 最小 | Y 最小 | Z 最小 | 数量 / 备注
SideLeft | 左侧木板 | 0 | 0 | 22.5 | 同形件 / 详见代表件图
SideRight | 左侧木板 | 438 | 0 | 22.5 | 同形件 / 详见代表件图
Slat01 | 横向木格栅 01 | 12 | 8.65 | 34.646 | 同形件 / 详见代表件图
Slat02 | 横向木格栅 01 | 12 | 12.874 | 47.646 | 同形件 / 详见代表件图
Slat03 | 横向木格栅 01 | 12 | 17.098 | 60.646 | 同形件 / 详见代表件图
Slat04 | 横向木格栅 01 | 12 | 21.322 | 73.646 | 同形件 / 详见代表件图
Slat05 | 横向木格栅 01 | 12 | 25.546 | 86.646 | 同形件 / 详见代表件图
Slat06 | 横向木格栅 01 | 12 | 29.77 | 99.646 | 同形件 / 详见代表件图
Slat07 | 横向木格栅 01 | 12 | 33.994 | 112.646 | 同形件 / 详见代表件图
HingeBase0 | 定位合页固定叶 1 | 74.5 | 350 | 118.5 | 同形件 / 详见代表件图
HingeBase1 | 定位合页固定叶 1 | 324.5 | 350 | 118.5 | 同形件 / 详见代表件图
HingePin0 | 定位合页活动叶及轴筒 1 | 74.5 | 350 | 140.75 | 同形件 / 详见代表件图
HingePin1 | 定位合页活动叶及轴筒 1 | 324.5 | 350 | 140.75 | 同形件 / 详见代表件图
Foot0 | VE 橡胶脚垫与 M8 螺杆 1 | 18 | 25 | 0 | 同形件 / 详见代表件图
Foot1 | VE 橡胶脚垫与 M8 螺杆 1 | 402 | 25 | 0 | 同形件 / 详见代表件图
Foot2 | VE 橡胶脚垫与 M8 螺杆 1 | 18 | 305 | 0 | 同形件 / 详见代表件图
Foot3 | VE 橡胶脚垫与 M8 螺杆 1 | 402 | 305 | 0 | 同形件 / 详见代表件图
FootMount0 | M8 脚垫固定座 1 | 14.5 | 21.5 | 20 | 同形件 / 详见代表件图
FootMount1 | M8 脚垫固定座 1 | 398.5 | 21.5 | 20 | 同形件 / 详见代表件图
FootMount2 | M8 脚垫固定座 1 | 14.5 | 301.5 | 20 | 同形件 / 详见代表件图
FootMount3 | M8 脚垫固定座 1 | 398.5 | 301.5 | 20 | 同形件 / 详见代表件图
HingeSpacer0 | 合页上盖补偿垫片 1 | 74.5 | 348 | 155 | 同形件 / 详见代表件图
HingeSpacer1 | 合页上盖补偿垫片 1 | 324.5 | 348 | 155 | 同形件 / 详见代表件图
HingeBacking0 | 亚克力内侧压板 1 | 74.5 | 343 | 155 | 同形件 / 详见代表件图
HingeBacking1 | 亚克力内侧压板 1 | 324.5 | 343 | 155 | 同形件 / 详见代表件图

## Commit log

2026-09-21 feat(cad): add reproducible turntable models
    Model one woofer and two tweeters with CAD, STEP, drawings, and documented assumptions. Reload macro sources, verify build parameters, and derive annotations from current dimensions. Add regression t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
    [lumi-dual-driver.FCStd, lumi-dual-driver.step, lumi-three-driver.FCStd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]
2026-09-21 feat(cad): add curved-arm mechanism fit study
    Add the selected kit overlay, provisional clearance diagnostics, exports, and source documentation while preserving the baseline assembly.
    Prevent rebuilds from overwriting reopened target documents by resolving file paths, with regression coverage for direct and symlink access.
    [lumi-selected-mechanism-fit.FCStd, lumi-selected-mechanism-fit.step]
2026-09-21 docs: add current work handoff
    Record the shipped CAD baseline, mechanism assumptions, verification evidence, and resume instructions for transfer through origin/main.
2026-09-21 feat(cad): size audio components and harden checks
    Apply supplied driver, transformer, and amplifier dimensions and regenerate both CAD assemblies, exports, and previews.
    Reject incompatible saved models with fresh failure reports, add regression coverage, and synchronize design and rebuild documentation.
    [lumi-selected-mechanism-fit.FCStd, lumi-selected-mechanism-fit.step, lumi-three-driver.FCStd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]
2026-09-21 feat(cad): redesign SC-2103 acoustic chambers
    Place the woofer behind the front satellites and add a replaceable rear
    port within the existing cabinet. Include updated CAD, previews and docs.
    Make cavity probes follow geometry and subtract all modeled occupants
    from net volume, including conservative installation envelopes.
    Validate with 12 regression tests and 30 baseline checks. Selected
    mechanism installation and acoustic tuning remain unconfirmed.
    [lumi-selected-mechanism-fit.FCStd, lumi-selected-mechanism-fit.step, lumi-three-driver.FCStd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]
2026-09-22 chore(cad): remove obsolete dual-driver models
    Keep the baseline and mechanism fit study required by the current build workflow. Update model selection and handoff documentation.
    [lumi-dual-driver.FCStd, lumi-dual-driver.step]
2026-09-22 feat(cad): add integer stock and drawing packs
    Use a 450 x 350 mm cabinet with true board thicknesses and integer stock sizes to simplify woodworking. Include regenerated CAD, previews, reports, and three grouped dimensioned PDF books.
    Reject missing slat neighbors before geometry checks so failed validation replaces stale success reports. Cover all five missing-neighbor cases, CLI failure, and document cleanup.
    [lumi-selected-mechanism-fit.FCStd, lumi-selected-mechanism-fit.step, lumi-three-driver.FCStd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]
2026-09-22 feat(cad): add rear AC inlet mounting
    Add the 8-F5 rear-panel opening and conservative wiring reservation, with geometry checks and regenerated CAD, previews, and drawing packs.
    Record reference images, purchase URLs, and installation limits. Track the unresolved stock-note update issue for non-default dimensions.
    [lumi-selected-mechanism-fit.FCStd, lumi-selected-mechanism-fit.step, lumi-three-driver.FCStd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]
2026-09-22 feat(cad): add annotated assembly guide
    Map the selected assembly to materials, quantities and detail drawings in a two-page guide. Select slat callouts from the current catalog and cover small slat counts in regression tests.
2026-09-22 feat(cad): model purchased feet and mounts
    Use the purchased foot and mount dimensions with upward barrels, update bottom-panel holes, and regenerate CAD, drawings, previews, and documentation.
    Reject a missing Feet group during validation preflight so failed validation replaces stale success reports; cover the API and CLI failure paths.
    [lumi-selected-mechanism-fit.FCStd, lumi-selected-mechanism-fit.step, lumi-three-driver.FCStd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]
2026-09-22 feat(cad): add panel hole detail drawings
    Expose the tilted baffle assembly and locate existing panel holes, blind pilots and the rear recess. Regenerate the two affected drawing books and synchronize their documentation and regression tests.
2026-09-22 fix(cad): remove redundant lower grille rail
    Keep the existing bottom panel geometry and retire the overlapping rail.
    Regenerate CAD, drawings and guides while preserving remaining drawing IDs.
    Cover the full PDF pipeline and synchronize documentation.
    [lumi-selected-mechanism-fit.FCStd, lumi-selected-mechanism-fit.step, lumi-three-driver.FCStd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]
2026-09-22 feat(cad): adopt 30 mm T-section fascia
    Model the selected aluminium extrusion and roof rebate, preserve chamber seals, and refresh CAD, drawings, previews and installation notes.
    Add section and clearance regressions. Disable camera animation for the temporary foot detail to prevent blank exports.
    [lumi-selected-mechanism-fit.FCStd, lumi-selected-mechanism-fit.step, lumi-three-driver.FCStd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]
2026-09-23 feat(cad): adopt symmetric torque hinges
    Record HFA5751-3434 supplier references and model the selected hinges
    with symmetric mounting positions, a lower AC inlet, and a forward
    transformer placement.
    Derive mounting annotations from parameters and add saved-geometry
    regressions for nondefault hole depths and backing dimensions.
    Refresh CAD exports, drawings, previews, and project documentation.
    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
    [lumi-selected-mechanism-fit.FCStd, lumi-selected-mechanism-fit.step, lumi-three-driver.FCStd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]
2026-09-23 fix(cad): reduce floating deck rear gap to 2 mm
    Parameterize the rear clearance and extend the floating deck while preserving spindle and support positions. Regenerate both CAD assemblies, drawings, previews and stock lists, and document the unverified suspension travel.
    Validate saved geometry and stock sizing at 2 mm and 7 mm clearances, and check the rear gap against the parameter snapshot.
    [lumi-selected-mechanism-fit.FCStd, lumi-selected-mechanism-fit.step, lumi-three-driver.FCStd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]
2026-09-24 feat(cad): integrate measured mechanism dimensions
    Use partial mechanism measurements and approximate spring supports in the
    fit study, previews, drawings and assembly guide; keep installation unreleased.
    Fail validation for collisions at either spring endpoint and derive drawing
    position notes from configuration, with CLI and saved-CAD/PDF regressions.
    [lumi-selected-mechanism-fit.FCStd, lumi-selected-mechanism-fit.step]
2026-09-24 feat(cad): consolidate selected mechanism model
    Replace the duplicate base assembly with one generated CAD source and keep
    closed engineering geometry alongside a saved 70-degree viewing pose.
    [lumi-selected-mechanism-fit.FCStd, lumi-selected-mechanism-fit.step, lumi-three-driver.FCStd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]
2026-09-24 feat(cad): match selected curved tonearm
    Model the pictured curved tube, connector and slotted headshell while preserving the measured parked envelope and regenerating drawings.
    [lumi-selected-mechanism-fit.FCStd, lumi-selected-mechanism-fit.step, parts.csv]
2026-09-24 feat(cad): center selected mechanism on deck
    Move the selected mechanism 12 mm right and shorten the finger lift to keep the assembly centered within the floating deck. Regenerate CAD, drawings, previews, reports, and synchronized documentation.
    [lumi-selected-mechanism-fit.FCStd, lumi-selected-mechanism-fit.step, parts.csv]
2026-09-24 refactor(cad): simplify model naming
    Rename the primary assembly and mechanism assets to generic project names.
    Refresh references and generated deliverables without changing saved geometry.
    [lumi-selected-mechanism-fit.FCStd, lumi-selected-mechanism-fit.step, parts.csv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]
2026-09-24 refactor(cad): flatten assembly part tree
    Replace document groups with validated AssemblySection metadata so parts remain directly selectable while exports and drawings retain their classifications.
    [record-player.FCStd]
2026-09-24 feat(cad): tighten floating deck clearances
    Set front, side, and rear gaps to 1/2/2 mm while keeping the spindle hole and isolator footprints valid. Regenerate CAD, drawings, previews, and documentation.
    [parts.csv, record-player.FCStd, record-player.step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]
2026-09-25 fix(drawings): sync wood stock specifications
    Use one catalog for A-STOCK and the assembly guide, and derive AC cutout notes from model parameters.
    Regenerate guides and add parity and PDF regressions.
2026-09-25 feat(drawings): embed assembly guide pages
    Keep the guide beside the stock list in book 01 and remove the duplicate standalone PDF. Validate the base book source and stage generated artifacts before publication.
2026-09-25 feat(cad): standardize structural panels at 10 mm
    Preserve the deck datum with recessed supports, refresh drawings and guides, and verify saved pocket geometry against the configured dimensions.
    [parts.csv, record-player.FCStd, record-player.step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]
2026-09-25 feat(cad): resize grille slats
    Use seven 426 x 10 x 6 mm slats and preserve clearance to the grille cloth. Regenerate the model, drawings, previews, tests, and documentation.
    [parts.csv, record-player.FCStd, record-player.step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]
2026-09-30 feat(cad): add Ariel laser-marked nameplate
    Add a separate nameplate with bundled Sigmar One lettering and vendor SVG artwork. Reject plates that exceed the fascia face, and refresh CAD, STEP, drawings, previews and installation notes.
    [parts.csv, record-player.FCStd, record-player.step]
2026-09-30 feat(cad): add printable Ariel engraving stencil
    [Ariel-stencil.FCStd, Ariel-stencil.step, Ariel-stencil.stl]
2026-10-02 feat(cad): add raised Ariel stencil supports
    Keep the A/R engraving outlines continuous with full-profile posts and 3 mm beams above an 8 mm clearance. Regenerate tool exports and previews, and document the supported print orientation.
    Validate with all 8 stencil tests, saved CAD/STEP/STL readback, visual inspection, and git diff --check.
2026-10-07 feat(cad): add printable baffle brace
2026-10-07 feat(cad): add independent chamber roof plates
2026-10-07 feat(cad): add two-color control panel
2026-10-07 feat(cad): add stepped control panel backing
2026-10-11 feat(cad): add removable grille positioning jigs
2026-10-11 feat(cad): add LED dimmer mount and knob
2026-10-11 feat(cad): add D-shaped bass port trial parts
2026-10-11 feat(cad): revise control panels to 70 by 170 mm
2026-10-12 feat(cad): resize inset dust cover to 75 mm
    Set the finished acrylic cover to 450 x 348 x 75 mm with 3 mm walls and direct cabinet-top contact. Preserve the hinge axis and update its spacers, validation, drawings, previews, and documentation.
    Validation: 61 geometry checks and 13 mechanism checks passed. The 127-test regression run was followed by passing targeted rechecks for all corrected cases and all 9 PDF tests.
